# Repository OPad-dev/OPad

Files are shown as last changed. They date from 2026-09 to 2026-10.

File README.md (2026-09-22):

# OPad

**Low-Latency ESP32-S3 Rhythm Gaming Keypad & Telemetry Display**

A deterministic, ultra-low-latency mechanical keypad and live telemetry HUD designed for competitive osu!, osu!lazer, and rhythm games on **Linux and Windows 10/11**.

---

## ⚡ Core Principle: Latency Always Wins

> **"If a feature measurably worsens keyboard latency or latency jitter, the feature is reduced, deferred, frozen during gameplay, or removed."**

The keypad functions as a standalone 1000 Hz USB HID keyboard out of the box with zero host software running. Auxiliary features (LVGL telemetry, SQLite persistence, system tray, and tosu integration) are completely isolated from the keypress critical path.

---

## 🏗️ System Architecture

```text
                      +-------------------+
                      |    osu!lazer      |
                      +---------+---------+
                                | (observes)
                                v
                      +-------------------+
                      |       tosu        |
                      +---------+---------+
                                | (WebSocket v2)
                                v
+--------------------+   +-------------------------+
|      opad-gui      |   |       opad-daemon       |
|     (Rust/iced)    |<->|         (Rust)          |
|  - System Tray     |IPC|  - State Machine        |
|  - Layout Designer |   |  - SQLite Storage       |
|  - Configuration   |   |  - Headless Service     |
|  - Diagnostics     |   |  - tosu & Device Owner  |
+--------------------+   +------------+------------+
                                      |
                           USB CDC    |    USB HID (1000 Hz)
                                      |
                                      v
                         +-------------------------+
                         |  ESP32-S3 Touch LCD 2   |
                         |  - Eager Debounce ISR   |
                         |  - Core 0: Input & HID  |
                         |  - Core 1: LVGL & CDC   |
                         |  - ST7789 Telemetry HUD |
                         +-------------------------+
```

---

## 🔌 Hardware Target & Switch Wiring

### Supported Hardware
- **Board**: **Waveshare ESP32-S3-Touch-LCD-2** (ESP32-S3, 16MB Flash, 8MB PSRAM, 2.0" ST7789 LCD)
- **Switches**: Any two standard MX-compatible mechanical switches.

### Switch Pinout (Header P2)
Standard MX mechanical switches have no polarity. Connect each switch between its designated GPIO and ground:

| Input | Board Header & Pin | GPIO | Switch Connection |
|---|---|---|---|
| **Key 1** (Default `Z`) | **Header P2, Pin 11** | `GPIO 14` | Pin A -> Pin 11, Pin B -> GND (Pin 13) |
| **Key 2** (Default `X`) | **Header P2, Pin 12** | `GPIO 9` | Pin A -> Pin 12, Pin B -> GND (Pin 2) |
| **Ground** | **Header P2, Pin 13 / Pin 2** | `GND` | Ground Reference |

*Note: Pins 11, 12, and 13 are directly adjacent on Header P2 for simple breadboard/Dupont jumper wiring.*

These are the defaults. Each key's pin can be changed in the app under **Settings → Keys**. The list only offers header pins that work with a switch to GND:

| Header | Pins (GPIO) |
|---|---|
| **P1** | 1 (`GPIO 2`), 2 (`GPIO 4`), 3 (`GPIO 6`), 4 (`GPIO 16`), 6 (`GPIO 18`), 7 (`GPIO 21`), 8 (`GPIO 8`), 9 (`GPIO 7`), 10 (`GPIO 10`) |
| **P2** | 7 (`GPIO 15`), 8 (`GPIO 13`), 9 (`GPIO 11`), 10 (`GPIO 12`), 11 (`GPIO 14`), 12 (`GPIO 9`) |

Left out: `GPIO 19/20` (USB), `GPIO 43/44` (UART0 console), `GPIO 47/48` (touch and IMU I2C) and `GPIO 17` (pulled down on the board). Most listed pins are also wired to the camera connector, so don't use them with a camera fitted.

---

## 🛠️ Building From Source

### 1. Prerequisites (Ubuntu / Debian)
```bash
sudo apt update
sudo apt install -y build-essential pkg-config libasound2-dev libudev-dev \
    libx11-dev libxkbcommon-dev libwayland-dev libfontconfig1-dev libdbus-1-dev
```

### 2. Desktop Software Suite (Rust)
```bash
cd desktop
cargo build --release
```
The compiled binaries are produced in `desktop/target/release/`:
- `opad-daemon`: Background service.
- `opad-gui`: Graphical configuration, layout designer, and system tray.
- `opadctl`: Command-line management tool.

### 3. Firmware Build (ESP-IDF v5.5.2)
```bash
cd firmware
idf.py set-target esp32s3
idf.py build
```

---

## ⚡ Flashing the Firmware

### Option A: Via `opadctl` (Recommended)
`opadctl` drives `espflash` directly and needs no shell script and no ESP-IDF
toolchain. It asks the daemon to release the serial port first, reboots the pad
into the ROM download bootloader hands-free, writes the image and reboots back
into the app — on Linux and on Windows, with the app running:

```bash
# Update the app image only (ota_0 at 0x20000)
opadctl flash firmware/build/opad-firmware.bin

# Recovery flash: bootloader + partition table + OTA data + app
opadctl flash --full firmware/build
```

It also works with no daemon running at all, which is the state a recovery
flash usually happens in.

### Option B: Via ESP-IDF
```bash
cd firmware
idf.py -p /dev/ttyACM0 flash
```

If the pad will not enter download mode or has to be returned to stock, see
[Recovery, Reflashing & Unbinding](docs/recovery.md).

---

## 🪟 Windows Setup & Installation

**The pad needs none of this to work as a keyboard.** Plug it into any Windows
10 or 11 machine and it types immediately: HID binds to the inbox
`hidclass.sys` and the CDC port to the inbox `usbser.sys`. No `.inf`, no
WinUSB, no Zadig, no install. The software below is for configuring it, the
telemetry HUD and the lifetime counters.

1. Download `opad-setup-<version>.exe` from the GitHub Releases page and run it.
2. It installs the daemon, the GUI and `opadctl`, bundles tosu, and configures
   both to start at login. There is nothing else to do.

> **SmartScreen will warn you.** The installer is **not code-signed** yet:
> OPad is applying to SignPath Foundation for free OSS signing, which
> requires the repository to be public first. Until then, Windows shows
> "Windows protected your PC" — choose **More info → Run anyway**. Check the
> download against `SHA256SUMS` on the release page if you would rather verify
> it than trust the dialog.

Uninstall from Settings → Apps. It removes everything it installed, including
the two `Run` registry values, and asks before it touches your `opad.db` —
so a reinstall keeps your lifetime counters unless you say otherwise.

**To reset a pad completely, or hand it to someone else**, see
[Recovery, Reflashing & Unbinding](docs/recovery.md). There is no unpair button
in the app, deliberately: the only unbind is a documented reflash, and it erases
the pad's lifetime counters along with the owner record.

---

## 🚀 Linux Setup & Installation

### Option A: Pre-built Packages (Recommended)

Pre-built packages are on the GitHub Releases page. The `.deb` and `.rpm` set
up everything: the udev rule, the daemon's systemd user service, tray autostart,
the bundled `espflash`, and the ptrace capability tosu needs to read osu!'s
memory (see [docs/troubleshooting.md](docs/troubleshooting.md) §2).

Supported: every Ubuntu LTS and Debian release in support (Ubuntu 22.04, 24.04,
26.04; Debian 12, 13), RHEL / AlmaLinux / Rocky 9 and 10, current Fedora and
Arch. The release packages, bundled tosu included, need glibc 2.28 or newer.

#### Debian / Ubuntu / Pop!_OS (`.deb`):
```bash
sudo apt install ./opad_<version>_amd64.deb
# Or via dpkg:
sudo dpkg -i opad_<version>_amd64.deb
```

#### Fedora / RHEL / openSUSE (`.rpm`):
```bash
sudo dnf install ./opad-<version>.x86_64.rpm
```

#### Standalone AppImage:
```bash
chmod +x opad-x86_64.AppImage
./opad-x86_64.AppImage
```
The AppImage installs nothing system-wide. On first run it offers to install
the udev rule (it asks for your password), or run
`./opad-x86_64.AppImage install-udev` yourself. It cannot give tosu the ptrace
capability; `opadctl setup` and the Diagnostics page explain the alternative.

#### Arch Linux:
The repository's `PKGBUILD` builds from source (tosu runs on the system
`nodejs`, so see troubleshooting §2 about ptrace):
```bash
makepkg -si
```

---

### Option B: Installing From Source

#### 1. System-wide Install:
```bash
make
sudo make install
```

#### 2. User-local Install (`~/.local`):
```bash
make
make install-user
systemctl --user daemon-reload
systemctl --user enable --now opad-daemon.service
```

#### 3. Manual Udev Rules:
If not installing from package, allow non-root user access to USB CDC and ROM bootloader devices:
```bash
sudo cp packaging/linux/udev/70-opad.rules /etc/udev/rules.d/
sudo udevadm control --reload-rules && sudo udevadm trigger
```

---

## 💻 CLI Quick Reference (`opadctl`)

```bash
# Check device, daemon, and tosu state
opadctl status

# Trigger safe reconciliation
opadctl sync

# Export portable JSON backup
opadctl export backup.json

# Import validated backup
opadctl import backup.json

# Flash firmware image directly over USB
opadctl flash firmware/build/opad-firmware.bin

# Recovery flash (bootloader, partition table, OTA data and app)
opadctl flash --full firmware/build

# Reboot the pad into the ROM download bootloader and leave it there
opadctl bootloader

# Stream real-time diagnostic logs
opadctl monitor
```

---

## 📄 Documentation
- [Documentation Hub & Wiki](docs/README.md)
- [System Architecture](docs/architecture.md)
- [Project Roadmap & Hardware Variants](docs/roadmap.md)
- [OPad on Windows — as built](docs/windows-portability.md)
- [USB Framing & Protocol](docs/protocol.md)
- [Counter Reconciliation, Recovery & Unbinding](docs/recovery.md) — including the reflash / unbind path
- [Latency Testing Methodology](docs/latency-testing.md)
- [Testing & Hardware Checklist](docs/testing-checklist.md)
- [Technical Specification v1](docs/specs/technical-spec-v1.md)
- [Rapid Trigger v2 Specification](docs/specs/v2-rapid-trigger.md)

---

## 📦 Third-Party Software

OPad bundles or interacts with the following third-party software:

### tosu
- **Project**: [tosu](https://github.com/KotRikD/tosu)
- **Author**: Mikhail Babynichev and the tosu contributors
- **License**: [GNU Lesser General Public License v3.0 (LGPL-3.0)](licenses/tosu/LICENSE)
- **Redistribution Notice**: See [licenses/tosu/NOTICE](licenses/tosu/NOTICE)
- **User Replacement Rights**: Under the terms of LGPL-3.0, users are entitled to replace the bundled tosu binary with their own version. You can point the `OPAD_TOSU_PATH` (or legacy `OSUPAD_TOSU_PATH`) environment variable to a custom tosu executable, or configure an external path in the OPad desktop GUI (**Settings → tosu**).

---

## ⚖️ Trademark Disclaimer
OPad is an independent open-source hardware and software project. OPad is not affiliated with, endorsed by, or sponsored by ppy Pty Ltd or osu!. "osu!" is a registered trademark of ppy Pty Ltd.

---

## 📜 License
Everything original to OPad is licensed under the [MIT License](LICENSE): the firmware, the desktop app (daemon, GUI, CLI), the PCB designs and footprints, the enclosure CAD, and the documentation.

Third-party components keep their own open licenses and ship with their notices:
- [tosu](licenses/tosu/LICENSE) (LGPL-3.0), built from upstream source and bundled with the desktop packages, see the section above. Not stored in this repository.
- [Montserrat](desktop/gui/assets/fonts/Montserrat-OFL.txt) fonts embedded in the GUI (SIL Open Font License 1.1).
- [nanopb](firmware/main/protocol/nanopb/LICENSE.txt) protobuf runtime vendored in the firmware (zlib license).

Libraries pulled in at build time (Rust crates, ESP-IDF components such as LVGL and TinyUSB) are not stored here and are used under their own permissive licenses.

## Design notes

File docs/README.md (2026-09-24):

# OPad Documentation Hub & Wiki

Welcome to the official documentation and technical wiki for the **OPad** project.

This directory serves as the single source of truth for hardware specifications, firmware implementation, desktop daemon architecture, testing protocols, and future milestones.

---

## ⚠️ Planned: full documentation reorganization and wiki (noted 2026-09-24)

This folder has grown by accretion: design docs, four readiness/audit reviews,
an evening TODO, a code-review folder and a fix plan sit side by side, several
of them describing the code as it was before the 2026-09-24 review fixes
(commits `0e3286b`…`d56211d`, 93 findings closed). It will be rebuilt as a
coherent wiki. The plan:

1. **Wiki lives here, not in the GitHub Wiki tab.** `docs/` becomes an
   [MkDocs Material](https://squidfunk.github.io/mkdocs-material/) site
   published with GitHub Pages: same repo, same commits, reviewed in PRs, links
   to source files stay valid, `mkdocs serve` to preview.
2. **Structure first, then pages.** One session designs the navigation and
   writes the cross-cutting pages (Overview, System architecture, Serial
   protocol incl. framing negotiation, Counter sync & pad ownership, Update &
   release pipeline). It ends with a checklist of remaining pages, each naming
   the source files to read — same format as
   [claude-code-review/FIX-PLAN.md](claude-code-review/FIX-PLAN.md).
3. **Per-component pages** from that checklist: firmware modules (keypad &
   debounce, USB HID/CDC, UI & LVGL layouts, `ui_store`, diag & counters,
   touch as the third key), one page per desktop crate, the daemon state
   machine, GUI pages, `opadctl` reference (generated from `--help`), packaging
   per distro and Windows, hardware & wiring (Waveshare ESP32-S3 Touch LCD 2
   pinout), troubleshooting, FAQ.
4. **Rules for whoever writes it:** every factual claim comes from a source
   file read in that session and cites its path; when code and an existing doc
   disagree, the code wins and the doc is fixed or deleted; no placeholder
   pages.
5. **Historical material** is kept but moved under `docs/history/` and marked
   as such: the readiness/audit reviews of 2026-09-22, `todo-2026-09-21-evening.md`,
   and the `claude-code-review/` findings (a record of what was found and fixed,
   not current guidance). `specs/remaining-work-v1.md` is folded into a changelog.

Until that lands, treat the documents below as **possibly stale**; the code and
`git log` are authoritative.

---

## 📚 Documentation Index

### 🏗️ Architecture & Core System
* **[System Architecture](architecture.md)** — Hardware layout, ESP32-S3 dual-core isolation, IPC design, desktop daemon, and state machine.
* **[USB Framing & Serial Protocol](protocol.md)** — Binary CDC packet framing, command opcodes, sequence numbers, and telemetry streams.
* **[OPad on Windows](windows-portability.md)** — Windows-specific design: Named Pipes IPC, Windows Service daemon, auto-start, and driverless HID operation.
* **[Recovery, Reconciliation & Unbinding](recovery.md)** — Safe counter synchronization, flashing procedures, bootloader entry, and pairing models.

* **[Troubleshooting](troubleshooting.md)** — Common failures (no live data, port busy, tosu memory access) and their fixes.

### ⏱️ Latency & Hardware Testing
* **[Latency Testing Methodology](latency-testing.md)** — Hardware test methodology, Stages A–D, electronic key-to-HID gate requirements, and latency benchmarks.
* **[Testing & Verification Checklist](testing-checklist.md)** — Comprehensive quality assurance checklist covering firmware, daemon, GUI, and hardware reliability.

### 🔍 Code review record (2026-09-23/24)
* **[Code review findings & fix plan](claude-code-review/README.md)** — 93 findings across firmware, desktop and packaging, all closed (92 fixed, 1 invalid); [FIX-PLAN.md](claude-code-review/FIX-PLAN.md) holds the per-cluster progress log and the hardware validation record.

### 🗂️ Historical readiness reviews (pre-fix snapshots, to move under `history/`)
* [Software readiness review (2026-09-22)](software-readiness-review-2026-09-22.md), [Software audit & readiness review](software-audit-and-readiness-review.md), [Release readiness guide (2026-09-22)](release-readiness-guide-2026-09-22.md), [Full-repo architecture & readiness guide](full-repo-architecture-and-readiness-guide.md), [TODO 2026-09-21 evening](todo-2026-09-21-evening.md) — written before the review fixes; many items they list are now done.

### 🚀 Future Milestones & Catalog Roadmap
* **[Future Roadmap & Hardware Variants](roadmap.md)**:
  * **ESP-NOW Ultra-Low-Latency Wireless Dongle** (Dual-mode 1.0 ms wireless).
  * **Heavy Ballast & Anti-Slip Deskmat Enclosure** (High-BPM anti-slip case V2).
  * **Multi-Key Catalog Expansion** (3-Key Standard with Quick Retry, 4k/5k/6k/7k/10k Mania).
  * **Modular Swappable Switch PCBs** (On-board ADC chip architecture, universal 8-wire SPI bus).
  * **Hardware Auto-Detection** (Analog ID voltage net & digital SPI handshake).
  * **Adaptive Debounce & Rapid Trigger Velocity Hysteresis**.

### 📋 Specifications & Development Plans
* **[Technical Specification v1](specs/technical-spec-v1.md)** — Complete normative specification for OPad V1 hardware, firmware, and desktop integration.
* **[Remaining Work & Gap Analysis](specs/remaining-work-v1.md)** — As-built gap analysis and audit tracking for V1 release.
* **[Packaging & Distribution Plan](specs/packaging-distribution.md)** — Build system, CI/CD, Windows/Linux packaging, and release delivery.
* **[Rapid Trigger (Hall-Effect Keys) v2 Plan](specs/v2-rapid-trigger.md)** — Implementation blueprint for Hall-effect magnetic switches, ADC sampling pipeline, and continuous Rapid Trigger engine.

---

## 🌐 Community & Repository

* **Primary Repository**: [https://github.com/OPad-dev/OPad](https://github.com/OPad-dev/OPad)
* **Organization**: [OPad-dev](https://github.com/OPad-dev)

---

## ⚖️ Trademark Disclaimer
OPad is an independent open-source hardware and software project. OPad is not affiliated with, endorsed by, or sponsored by ppy Pty Ltd or osu!. "osu!" is a registered trademark of ppy Pty Ltd.

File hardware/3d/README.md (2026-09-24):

# OPad ESP32-S3 — 3D Models & Enclosure CAD Reference

This directory contains the ready-to-print/modify OPad enclosure for the **Waveshare ESP32-S3-Touch-LCD-2** and standard **MX mechanical switches**. Everything here is original OPad work under the repository's [MIT License](../../LICENSE).

---

## 1. Directory Structure

```
hardware/3d/
└── custom_case/
    ├── V1.1/                               # Current: fits the V1 PCBs (carrier on sockets + MX/HE module)
    │   ├── osupad_params.scad              # every dimension
    │   ├── osupad_enclosure.scad           # top case and bottom plate (screwless)
    │   ├── osupad_case_top.stl
    │   ├── osupad_case_bottom.stl
    │   ├── osupad_preview.png
    │   ├── README.md                       # changes from V1, parts, assembly, printing
    │   └── tools/check_fit.py              # interference check against the PCBs and the Waveshare
    └── V1/                                 # Original (20.3° screen deck, hand-wired switches); does not fit the V1 PCBs
        ├── osupad_enclosure.scad
        ├── osupad_case_top.stl
        ├── osupad_case_bottom.stl
        └── osupad_preview.png
```

Use **V1.1** with the V1 PCBs; see [`custom_case/V1.1/README.md`](custom_case/V1.1/README.md).

Third-party models (the Waveshare board model and other keypads) are not stored in this repository, since they are not MIT licensed. Download them from their authors if you want them as a modelling reference; see section 4.

---

## 2. Hardware Dimensions Reference

### Waveshare ESP32-S3-Touch-LCD-2
* **Outer Glass Lens**: `37.10 mm (W) × 58.80 mm (L) × 1.10 mm (H)` with `4× R2.60 mm` corner fillet (drawing). The STEP model's glass edge measures `37.52 × 59.22 mm`, so a pocket needs more clearance than the drawing suggests.
* **Under the glass**: touch layer, LCD and PCB all fit inside `35.02 × 48.22 mm`; the USB-C receptacle sticks out `1.18 mm` past the PCB edge
* **Active Display Viewport**: `30.99 mm (W) × 41.20 mm (L)`
* **PCB Substrate**: `35.00 mm (W) × 48.20 mm (L)`
* **Mounting Holes**: `4× M2.0` screw holes (pitch: `29.00 mm (X) × 42.20 mm (Y)`)
* **Total Module Depth**: `9.70 mm` (from glass front to back of PCB connectors)
* **USB-C Port**: Centered on bottom edge (`18.9 mm` cutout width)

### Mechanical MX Key Switches (Cherry, Gateron, Kailh)
* **Plate Cutout**: `14.0 mm × 14.0 mm`
* **Plate Thickness**: `1.5 mm` (critical for clip retention)
* **Standard Key Pitch**: `19.05 mm` center-to-center

---

## 3. How to Use & Modify These Models

### Option A: Use the OpenSCAD Parametric Generator (Recommended)
1. Open [`hardware/3d/custom_case/V1.1/osupad_enclosure.scad`](custom_case/V1.1/osupad_enclosure.scad) in [OpenSCAD](https://openscad.org/) (dimensions are in `osupad_params.scad`).
2. Change `PART` to `"top_case"` or `"bottom_plate"`.
3. Press `F6` to render, then `F7` to export directly to `.stl`.
4. All dimensions, wall thicknesses, and tolerances are fully configurable as variables at the top of the file.

### Option B: Model Around the Board in FreeCAD, Fusion 360 or Onshape
1. Download the official board STEP model from the [Waveshare Wiki](https://www.waveshare.com/wiki/ESP32-S3-Touch-LCD-2) (not redistributed here).
2. Import it next to an export of the OPad case, or model around the dimensions in section 2.
3. Export as `.stl` or `.step` for slicing.

---

## 4. External References (not included, not MIT)
- **Waveshare ESP32-S3-Touch-LCD-2**: official 3D CAD model and 2D drawings on the [Waveshare Wiki](https://www.waveshare.com/wiki/ESP32-S3-Touch-LCD-2). No redistribution license is stated, so the files are not included here.
- **`milk-crate`**: 2-key macropad by *somepin* ([GitHub](https://github.com/somepin/milk-crate), MIT License).
- **`osu-keypad`**: 2-key keypad by *clay53* ([GitHub](https://github.com/clay53/Osu-Keypad), MIT License).
- **`osu-clicker`**: 2-key hotswap keypad by *kameHame HA* ([Printables #943460](https://www.printables.com/model/943460-osu-keypad), CC BY-NC 4.0, non-commercial only).

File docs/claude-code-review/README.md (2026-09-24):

# Claude Code review findings

Findings from `/code-review` runs, saved so they survive the session. Each file
covers one run; findings are ranked most severe first and carry a status
(`open` / `fixed` / `wontfix` / `invalid`) that should be updated as they are
worked through. Unless a finding is marked *(confirmed)* or *(verified)*, the
reviewer did not re-verify it, so check each against the code before acting on it.

All runs on 2026-09-23 were against `main` @ `b0e0a37` with a clean working tree,
so each covers the current code of its path rather than a diff.

| Scope | File | Findings |
| --- | --- | --- |
| `firmware/main/protocol` | [2026-09-23-firmware-protocol.md](2026-09-23-firmware-protocol.md) | 8 |
| `firmware/main` usb / input / config / counters / runtime / diag / app_main | [2026-09-23-firmware-usb-input-config.md](2026-09-23-firmware-usb-input-config.md) | 10 |
| `firmware/main/ui` | [2026-09-23-firmware-ui.md](2026-09-23-firmware-ui.md) | 10 |
| `firmware/test`, `firmware/boards` (medium) | [2026-09-23-firmware-test-boards.md](2026-09-23-firmware-test-boards.md) | 2 |
| `desktop/crates/opad-protocol`, `opad-device`, `opad-ipc` | [2026-09-23-desktop-opad-protocol-device-ipc.md](2026-09-23-desktop-opad-protocol-device-ipc.md) | 10 |
| `desktop/crates/opad-update` | [2026-09-23-desktop-opad-update.md](2026-09-23-desktop-opad-update.md) | 8 |
| `desktop/crates/opad-model`, `opad-layout`, `opad-storage`, `opad-tosu`, `opad-ui-preview` | [2026-09-23-desktop-model-layout-storage-tosu-preview.md](2026-09-23-desktop-model-layout-storage-tosu-preview.md) | 10 |
| `desktop/daemon` | [2026-09-23-desktop-daemon.md](2026-09-23-desktop-daemon.md) | 10 |
| `desktop/gui` | [2026-09-23-desktop-gui.md](2026-09-23-desktop-gui.md) | 10 |
| `desktop/cli` | [2026-09-23-desktop-cli.md](2026-09-23-desktop-cli.md) | 10 |
| `packaging`, `scripts`, `.github`, `protocol` (medium) | [2026-09-23-packaging-scripts-ci-protocol.md](2026-09-23-packaging-scripts-ci-protocol.md) | 5 |

93 findings total. `opad-layout`, `opad-storage` and `protocol/` came out clean.

**Hardware (2026-09-24, `main` @ `f78bfbd`):** PCBs and case, checked with KiCad 10.0.6 and OpenSCAD against Waveshare's schematic and drawing: [2026-09-24-hardware.md](2026-09-24-hardware.md), 9 findings: 3 fixed by case V1.1 (#1, #6, #7), 6 open (the PCB and tooling ones).

**Fixing them:** see [FIX-PLAN.md](FIX-PLAN.md) — every finding assigned to one
executor (Opus / Sonnet / Haiku / Antigravity), clustered by file, with run order,
session rules and paste-able kickoff prompts.

## Status: closed (2026-09-24)

All 93 findings are closed: **92 fixed, 1 invalid** (DC#10). Every cluster in
FIX-PLAN.md is ticked. Every commit passed `make firmware`, the firmware host
tests and `make check` (fmt, clippy `-D warnings`, 328 tests).

### Hardware validation record

Run by the owner on the real pad (Waveshare ESP32-S3 Touch LCD 2, new firmware
flashed via `opadctl flash`) on 2026-09-24:

| Step | Covers | Result |
| --- | --- | --- |
| Flash + reconnect | S12 (daemon pause/resume path) | ✅ released port, 12 s flash, reconnected 3 s later, no 15 s wait |
| Boot | O6, S1, A2 | ✅ no I2C scan, quiet idle log |
| Touch as third key (tap / hold / lift / double tap / 30 s idle) | FU#10 | ✅ |
| Keys, remap while held, detect-pin, protocol responsive during detect | O2, O3, O4, S1 | ✅ |
| Full map with live tosu data, unplug/replug mid-map | O1, S2 (pad side) | ✅ |
| Sleep, set brightness asleep, wake | S3, FB#1 | ✅ |
| Layout pushed during gameplay, reboot | O5 | ✅ |

**Signed off by the owner without a hardware run** (unit/integration tests and
code review only): foreign-pad guards and incompatible-pad handling (O7, O8),
headless mode (O6 — the LCD is always fitted), desktop reconnect logic (O9, tested
on the pad only against the pre-fix daemon), Windows pipe/bootloader-port picks
(O10, `cargo check` for the Windows target), tosu supervisor pause (O11), the
updater fixes (S6, S7), the GUI fixes (S9, S10, DG#10), the CLI fixes (S11,
DC#8), release signing (S13), and the Windows cold-plug with a legacy-firmware
pad (DD#9). If any of these misbehaves, the FIX-PLAN progress log names the
commit to look at.

## Top items across runs (2026-09-23)

### Firmware
1. Framing lock: legacy headers accepted after marked lock, and `s_host_framing` re-latched per frame (protocol #1, #2).
2. `detect_pin` `timeout_ms` unbounded, blocks the CDC task (protocol #3).
3. GPIO8 (module-ID divider) in the key-pin lists → pin detect returns it instantly (usb/input #1, #8).
4. HID `s_report_pending` race between touch-retry (core 1) and keypad (core 0) (usb/input #2).
5. HE module reported as a held key; keycode changes bypass the staged apply (usb/input #3, #4, #5).
6. Headless mode: `data_update` source 67 runs LVGL without `lv_init` → panic loop; `ui_init` derefs a NULL screen (ui #1, #6).
7. `ui_store` pending layouts / dirty masks shared across cores without a lock; dirty bit cleared before the NVS write (ui #4, #5).
8. Brightness set while asleep is lost on wake (ui #2, boards #1).

### Desktop
1. Foreign-pad guards bypassed: cooldown→sync trigger, every IPC handler, and the firmware installer (daemon #1, #2, #4).
2. `opad-device` serial worker: Windows `Instant` subtraction panic kills the worker silently; frames dropped and no reopen after a re-Hello (device #1, #2, #3).
3. Updater: persisted ETag with no cached manifest disables all updates after a restart; AppImage never classified in the manifest; tosu VERSION written before the binary; `pause()` doesn't wait for tosu to exit (update #1, #2, #3; tosu #1).
4. Incompatible-protocol pad adopted as connected, counters saved under the previous pad's id (daemon #3).
5. Version compare: `rc10 < rc9`, and tosu plan ignores `is_newer` (update #5, #6).
6. Flash flow: CLI death between `PrepareFlash`/`FinishFlash` leaves the daemon paused forever; `bootloader` waits 15 s for an impossible reconnect (cli #2, #3).
7. GUI log cursor skips a daemon entry per local log line; single-instance races on both platforms; tray probed once (gui #2, #3, #6, #8).

### Release / packaging
1. `build_release.sh` signs a manifest over locally rebuilt artifacts, not the ones `release.yml` publishes (packaging #1).
2. `AppRun` `LD_LIBRARY_PATH` trailing-colon lets a planted `.so` in the CWD load (packaging #2).
3. Arch package ships no espflash; glibc gate skips the tosu binary (packaging #4, #5).

## Cross-cutting themes

- **Framing negotiation lives in three places** (firmware parser, `opad-device` worker, `opad-device::probe_port`) with different rules; the firmware side re-latches per frame while the host locks once. See firmware protocol #1/#2 and device #9.
- **Log sequence cursors** are mishandled the same way in the GUI (`latest_log_seq` doubles as local counter) and the CLI (`since_seq` advanced to `latest_seq`, `> 0` guard). A shared "advance from last received entry" helper in `opad-model` would fix both.
- **Cross-core shared state without a lock** in firmware: `ui_store` masks/pending layouts, `s_report_pending` / `s_pending_edge_us` in `usb_hid`, `s_asleep` read from the protocol task.
- **Duplicated tables/logic that have already drifted:** key-pin allow-list and debounce bounds (firmware), `ConfigPayload → DeviceConfig` (device), atomic-write sequence (update/backup), tosu log classifier (daemon), confirm prompt (cli), stdout/stderr pump (tosu), `install_prefix` (model), wire constants (ui-preview).
- **Brightness / sleep ownership** is split between `board_display.c`, `ui_port.c` and `device_config.c`, each with its own copy of the current brightness.

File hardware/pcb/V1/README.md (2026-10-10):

# OPad V1 PCBs

Modular hardware ecosystem joined by one 8-wire JST-SH cable:

| Board | Folder | Size | Status | What it does |
|---|---|---|---|---|
| **Controller carrier** | `Carrier/` | 35.0 × 48.2 mm, C-shaped | Production | Plugs onto the Waveshare ESP32-S3-Touch-LCD-2 headers and brings the module signals to a connector |
| **MX input module** | `MX/` | 52.0 × 24.0 mm | Production | Two Kailh MX mechanical hot-swap sockets under the key plate |
| **Hall Effect input module** | `HE/` | 52.0 × 24.0 mm | **v2 Experimental** | Two magnetic Rapid Trigger Hall sensors (TI DRV5055) under the key plate |

> [!IMPORTANT]
> The **Hall Effect module** requires firmware v2 (Rapid Trigger support), which is not yet available. The PCB design is complete but has not been built and tested; the firmware's ADC sampling pipeline and Rapid Trigger engine are specified in [`docs/specs/v2-rapid-trigger.md`](../../docs/specs/v2-rapid-trigger.md). v1 firmware recognises an HE module by its ID voltage, shows a warning on the LCD and ignores key input rather than reading the analog sensor outputs as presses.

The input module is **swappable**: both the MX mechanical module and the Hall-effect (rapid trigger) module use the same outline, mounting holes, connector position and pinout, and plug into the same carrier and cable. The module reports which kind it is through an ID voltage on the connector (0.30 V for MX, 1.06 V for Hall Effect).

Production files live in each board's `production/` folder, one subfolder per fab: `jlcpcb/` (Gerbers, BOM, CPL), `pcbway/` (Gerbers with their order marker, BOM, centroid) and `aisler/` (native KiCad board and ODB++ with the parts in them). Renders, PDFs, STEP and the ERC/DRC reports sit next to them.

Status: the MX module and the carrier pass ERC, DRC and schematic parity in KiCad 10.0.6 with zero errors; the carrier has zero warnings, the MX module only "does not match copy in library" warnings, because its footprint and symbol copies were placed before `lib/` was rewritten by `gen_library.py` (same pads and pins; that board is built and working, so `export_production.py` accepts them). The Hall Effect module is generated and checked by its own toolchain (`scripts/he_board.py`, see below), which needs no KiCad install; it reports zero rule violations, its Gerbers verify clean against the netlist, and the generated KiCad files pass ERC and DRC with schematic parity in KiCad 10.0.6 (`scripts/check_he_kicad.py`; only "footprint does not match library" warnings remain, see Toolchain).

---

## Module connector (JST SH 8-pin, same on every input module)

| Pin | Net | Waveshare pin | GPIO | MX V1 use | Hall module use |
|---|---|---|---|---|---|
| 1 | 3V3 | P2-1 | – | pull-ups, ID divider | sensor supply |
| 2 | GND | P2-2 | – | switch common | ground |
| 3 | IN1 | P1-10 | **GPIO10** (ADC1_CH9) | KEY1 (left key) | analog 1 / SPI CS1 |
| 4 | IN2 | P1-9 | **GPIO7** (ADC1_CH6) | KEY2 (right key) | analog 2 / SPI CS2 |
| 5 | ID | P1-8 | GPIO8 (ADC1_CH7) | ID divider = 0.30 V | own ID voltage |
| 6 | IO6 | P1-3 | GPIO6 (ADC1_CH5) | not used | e.g. SPI MISO |
| 7 | IO4 | P1-2 | GPIO4 (ADC1_CH3) | not used | e.g. SPI MOSI |
| 8 | IO2 | P1-1 | GPIO2 (ADC1_CH1) | not used | e.g. SPI SCK |

- All six signals are ADC1 pins. On the ESP32-S3, ADC continuous (DMA) mode only supports ADC1 (see `docs/specs/v2-rapid-trigger.md` §2.2).
- SPI3 can be routed to any of these pins through the GPIO matrix. None of them are strapping pins, USB, UART0, or the touch/IMU I2C.
- The pin order is chosen so both boards route on two layers with no crossings.
- **Firmware:** in the app, set Key 1 = GPIO10 and Key 2 = GPIO7 (both are already in the allowed pin list). The hand-wired defaults (GPIO14 / GPIO9) don't apply to this board.

### Module ID

Each module has its own divider from 3V3 to GND on ID. The carrier has no parts on this line.

| Module | Top resistor | Bottom resistor | ID voltage |
|---|---|---|---|
| MX V1 | 100 kΩ (R3) | 10 kΩ (R4) | 0.30 V |
| **Hall Effect V1** | **100 kΩ (R1)** | **47 kΩ (R2)** | **1.06 V** |
| reserved: Hall SPI | 100 kΩ | 100 kΩ | 1.65 V |

The divider's source impedance is 100k ∥ 47k ≈ 32 kΩ, above the ~10 kΩ the ESP32-S3 ADC likes. ID is read once at start-up, so average a handful of samples instead of trusting a single conversion.

With no module plugged in, GPIO8 floats. The firmware can enable the internal pull-down to read about 0 V in that case.

---

## MX input module (`MX/`)

- **Case coordinates** below are those of `hardware/3d/custom_case/V1/osupad_enclosure.scad`: origin at the front-left outer corner, X to the right, Y toward the screen. KiCad uses X = 100 + case X and Y = 100 − case Y, so the top of the KiCad editor is the rear of the case and the layout is not mirrored.
- **Key centres:** case (28.475, 16.5) and (47.525, 16.5), 19.05 mm pitch, the same as the plate cutouts.
- **Outline:** case X 12…64, Y 7…31, 1.5 mm corner radius.
- **Mounting holes:** 2× M2 (2.2 mm NPTH) at case (15.5, 16.5) and (60.5, 16.5), on the key axis and clear of the switch footprints. The PCB must be held there, or it moves when a switch is pulled. Case V1.1 does this without screws: pins in the key deck go through the holes and posts on the bottom plate clamp the PCB against the deck.
- **Height:** the PCB top is **5.0 mm below the top of the plate** (plate 1.5 mm, case z = 10.0). About 3.5 mm of free space is needed under the PCB bottom for the sockets (1.85 mm) and J1 (2.9 mm).
- **Everything is on the bottom side** (sockets, J1, R1–R4, C1), so JLCPCB assembles one side only. The switches go in from the top through the plate.
- **J1** sits at the rear edge, centred on the keys, with the opening facing the screen. The cable leaves toward the controller.
- **Footprint:** `lib/osupad.pretty/Kailh_CPG151101S11_MX_Hotswap_Bottom` is the Kailh land pattern (3.05 mm pin holes, 4.0 mm centre, 1.75 mm pegs, 2.55 × 2.5 mm pads), drawn from the socket side and placed flipped. The switch pins point to the rear (standard orientation).

## Hall Effect input module (`HE/`)

Same outline, mounting holes, connector position and pinout as the MX module, so the two are interchangeable on one cable. Instead of switching a pin to ground, each key has a **TI DRV5055A3 ratiometric linear Hall sensor** whose analog output tracks the magnet in the switch stem, which is what rapid trigger needs.

> **V1.0 erratum (fixed in V1.1):** the V1.0 SOT-23 footprint was mirrored, so every assembled sensor sits with **VCC on its IN line and OUT on 3V3**. It powers itself backwards through its protection diode, reads a fixed ~2.9 V and barely reacts to a magnet. The connectivity was right, so neither DRC nor the assembler could catch it. V1.1 swaps pads 1 and 2 (`scripts/gen_library.py`, `scripts/he_board.py`), moves C2/C3 to the pin-1 side so the 3V3 stub and the IN line do not cross, and `he_board.py`'s self-test now checks every SOT-23's pin order against the real package. A V1.0 board works only with each sensor re-soldered upside down (marking towards the board), which mirrors its pin order back.
>
> **V1.1 review (2026-10-10), before ordering:** TI's DBZ pinout (datasheet SBAS640C Figure 4-1 and Table 4-1: 1 = VCC, 2 = OUT, 3 = GND, pin 1 top-left in the top view) was checked against the footprint by hand, against KiCad's flip convention and against the V1.0 measurements; the three agree with the V1.1 pads. Found and fixed in the same pass: the vias grow from 0.6 to **0.7 mm** (0.2 mm annular ring, which Aisler's HASL rules and Eurocircuits' class 6 need; JLCPCB accepted 0.6); the silkscreen square round each sensor was 3.0 mm and crossed the pad tips, it is now 3.6 mm with a pin-1 dot, and `C2`/`C3` moved 0.2 mm away from the sensors to make room; the pour gap went from 0.3 to 0.45 mm and a ground via fills the pocket next to U2, so the Gerbers hold no floating copper slivers (`verify_he_gerbers.py` now checks for islands); the generated schematic had an unescaped quote and did not load in KiCad, so ERC had never actually run on it (it now passes, with PWR_FLAGs and a connector symbol that carries the MP pads). None of these change the netlist.

### Sensor architecture (the part that matters)

This is **Architecture A: bottom-side SMT on solid FR-4.**

- There is **no 4.0 mm stem hole** at the key centres. `SW_MX_Hall_PlateMount` (used for a through-hole stem) is *not* the footprint here; `SW_MX_Hall_PlateMount_SolidCentre` is, and it contributes only the two alignment peg holes.
- U1 and U2 are centred **exactly** on the key centres (16.475, 9.5) and (35.525, 9.5), on the bottom copper, directly under the magnet.
- A **3.0 × 3.0 mm copper keepout on both layers** around each sensor keeps the ground pour out of the magnetic path, so the stem magnet's flux is not damped by eddy currents in the plane. In KiCad these are rule areas with `copperpour not_allowed`; in the Gerbers the pour is genuinely absent there.
### Why there is no centre hole, and what the board is actually compatible with

In a Lekker / Gateron KS-20 class magnetic switch (Gateron's KS-20T drawing DS-02-001-A0, in the [Magnetic Orange datasheet](https://gateron.com/u_file/2312/26/file/GATERONMagneticOrangeSwitch-KS-20TO10B050NW-Y64.pdf), sheet 1):

- **the magnet sits in the stem at the switch centre, N pole towards the PCB.** There is no MX-style centre pole and no 4 mm centre hole;
- **two Ø 1.70 ± 0.05 mm plastic pins, 10.16 mm apart (±5.08 mm), stick out of the bottom and pass straight through the PCB**, protruding about 1 mm out the back. That is why the 1.75 mm peg holes are needed;
- the bottom housing has a pocket ("the hole for setting hall sensor") so Gateron's own reference layout puts a SOT-23 sensor on the **top** of the PCB, between the two pins, with three 0.8 × 0.8 mm pads.

So a top-side sensor is possible with these switches; this board puts it on the bottom instead, like Wooting ([Lekker update #5, part 2](https://wooting.io/post/we-overcame-the-challenges-lekker-update-5-part-22)), because single-side assembly is cheaper and the top of the PCB stays flat against the plate. The price is distance: the magnet reads through the full 1.6 mm of FR-4 plus the package, so the field at the die is a fraction of what Gateron's pocket position sees (numbers under Sensor sensitivity). Peg holes **and** a solid centre **and** a bottom-side sensor is a consistent set; a board that had the peg holes *and* a 4 mm centre hole would be an MX PCB-mount pattern, which is a different switch.

| Switch | Works on this board? |
|---|---|
| Gateron KS-20 / Wooting Lekker, KS-37 / Magnetic Jade, Geon Raw HE and other Lekker-standard magnetic switches | Yes — flush magnet centre, two ±5.08 mm plastic pins |
| Switches sold as "**TMR switches**" | Yes — see below |
| MX mechanical (Cherry, Gateron, Kailh…) | **No.** A real MX switch has a centre pole and metal pins. That is what the `MX/` module is for — same outline, same connector, swap the module |

**On "TMR switches":** TMR (tunnel magnetoresistance) is a *sensor* technology that lives on the keyboard's PCB, not a different kind of switch. A switch marketed as a "TMR switch" is the same magnetic switch — a magnet in an MX-form stem with a flush bottom and two pins — and the industry uses them interchangeably: Gateron Jade, Jade Pro and Lekker V2 all go into Hall boards like the Wooting 60HE and TMR boards like the Womier SK75 alike. This module reads the magnet with a Hall sensor, and the magnet does not know or care what sensor is underneath it, so TMR-branded switches drop straight in.

Two caveats, neither of which is a fit problem:

- **Magnet strength varies by switch model.** TMR sensors are far more sensitive than Hall, so a vendor *can* pair a TMR-targeted switch line with a weaker magnet. If you use such a switch here, A3 is the wrong variant and you want A1 or A2. As Wooting put it, what matters is matching the sensitivity range to the magnet, not chasing sensitivity for its own sake.
- **This board cannot be rebuilt with a TMR sensor as a drop-in.** The common analog TMR parts (MultiDimension TMR2001, TMR2083) are SOT-23-**5**, not the 3-pin SOT-23 used here, so they would need a new footprint and a re-route. Most TMR designs also mount the sensor *off-axis*; U1/U2 here are deliberately on-axis at the key centre, which is the right placement for the DRV5055.

These magnetic switches are deliberately not MX-compatible; vendors say so themselves. The claim this board makes is "every switch in the Lekker standard", not "every keyboard switch ever made". If a magnetic switch turns up with a protruding MX-style centre pole, it will foul the sensor and is out of scope for V1 — I found no current HE switch that does this, since the whole class puts the magnet where that pole would be.

### Sensor sensitivity

The magnet reads through 1.6 mm of FR-4, so the field at the die is weaker than a top-side design's. Wooting hit the same geometry and compensated with a stronger magnet *and* a more sensitive sensor. All three variants share the SOT-23 pinout and this footprint, so **the board never changes** — only which reel JLCPCB loads. Set `SENSOR_VARIANT` in `scripts/he_board.py` and regenerate.

Datasheet values (TI SBAS640C §5.6, VCC = 3.3 V, 25 °C): quiescent output 1.59–1.71 V (typ. 1.65 V), linear output range 0.2 V to VCC − 0.2 V, input-referred noise 0.2 mT peak-to-peak for every variant (so a more sensitive part gives more volts per millimetre but the same magnetic noise):

| Variant | LCSC | Sensitivity @3.3 V | Linear range @3.3 V | Notes |
|---|---|---|---|---|
| A1 | `C962987` | 60 mV/mT (57–63) | ±22 mT | clips before mid-travel with a Jade |
| A2 | `C266131` | 30 mV/mT (28.5–31.5) | ±44 mT | about 2× A3's resolution, may clip in the last few tenths of a millimetre |
| A3 | `C266128` | 15 mV/mT (14.3–15.8) | ±88 mT | current default; cannot clip |

What the magnet delivers: Gateron quotes the Magnetic Jade at 120 Gs (12 mT) initial and 700–800 Gs (70–80 mT) at bottom-out "with a 1.2 mm PCB", N pole towards the PCB; the KS-20T, read in its pocket, at 102 / 905 Gs. Through 1.6 mm the bottom-out figure drops to very roughly 50–60 mT. With the N pole facing the sensor's back the output **rises** when the key is pressed: A3 goes from about 1.8 V at rest to about 2.4–2.6 V at bottom-out, inside the ESP32-S3 ADC's accurate range at 12 dB (0–2.9 V, ±50 mV); A2 would reach 3.1 V (its limit) at 48 mT, so it saturates near the end of travel but doubles the resolution over the rest. A3 is shipped as the default because it cannot saturate, which makes first bring-up unambiguous; measure the actual swing on the first V1.1 build before choosing between A3 and A2. The Jade Silent (3.2 ± 0.2 mm travel) has no published flux figures.

### Layout

- **Everything is on the bottom side**, so JLCPCB assembles one side.
- `U1`/`U2` are at 180°, so both analog outputs face the connector and both ground pads face the board's front edge, where a short stub and a via drop them into the pour outside the keepout.
- `C2`/`C3` sit just outside each keepout on the pin-1 side (centre 2.7 mm from the sensor, 100 nF; TI asks for at least 10 nF close to VCC, §7.4), feeding VCC from the side; `C1` is the bulk decoupler next to J1 pin 1.
- **3V3 is distributed on F.Cu**, the otherwise empty top layer, so every analog trace stays on B.Cu with no crossings. Four vias tie it to the bottom-side stubs.
- `R1`/`R2` are the 100 k / 47 k ID divider.
- J1-6/7/8 (GPIO6/4/2) are reserved for an SPI variant, so instead of being left floating they run to probe pads **TP1/TP2/TP3** below the connector — the three bare pads visible under J1 in the render. They are board features, not parts: nothing is assembled on them, they take no solder paste, and they appear in neither the BOM nor the centroid file. Delete `_probe_pad(...)` from `PARTS` in `he_board.py` and regenerate if you would rather leave those pins unconnected.
- Ground: pours on both layers with a 0.45 mm gap to foreign copper (wide enough that no sliver is left between 1.0 mm pitch traces), thermal relief on every ground pad, and 22 plated vias stitching the two planes.
- Vias are 0.7 mm with a 0.3 mm hole (0.2 mm annular ring), tented on both sides.

### Pinout

| Pin | Net | Goes to |
|---|---|---|
| 1 | 3V3 | U1-1, U2-1 (VCC), C1/C2/C3, R1 |
| 2 | GND | ground pours, U1-3, U2-3, C1/C2/C3, R2 |
| 3 | IN1 | U1-2 (OUT), key 1 analog → GPIO10 (ADC1_CH9) |
| 4 | IN2 | U2-2 (OUT), key 2 analog → GPIO7 (ADC1_CH6) |
| 5 | ID | R1/R2 divider, 1.06 V → GPIO8 (ADC1_CH7) |
| 6, 7, 8 | IO6 / IO4 / IO2 | TP1 / TP2 / TP3 probe pads, reserved for SPI |

**DRV5055 SOT-23 pinout: 1 = VCC, 2 = OUT, 3 = GND** (TI DBZ package, datasheet Figure 4-1 and Table 4-1). Worth repeating because swapping 2 and 3 would put the output straight on ground. Turned so pins 1–2 face up, pin 1 is on the **right** in the top view of the chip; a chip on the bottom side is seen mirrored from above, so in the board's top view (and in the KiCad editor) pad 1 is the **left** one of the pair, the one next to the silkscreen dot. `he_board.py`'s self-test enforces this and also compares J1's pinout with the built MX board and the sensor symbol's pin names with the nets.

### Toolchain

The HE board does not depend on a KiCad install. `scripts/he_board.py` holds the geometry, netlist and placement, and checks its own design rules; everything else is derived from it:

```
python3 scripts/he_board.py            # placement self-test + DRC, exit 1 on any violation
python3 scripts/generate_he_gerbers.py # Gerbers, drills, job file, BOM, CPL (JLCPCB + PCBWay)
python3 scripts/generate_he_kicad.py   # .kicad_sch, .kicad_pcb, .kicad_pro, lib tables
python3 scripts/verify_he_gerbers.py   # rasterise the Gerbers, check nets for opens/shorts/islands
python3 scripts/render_he_preview.py   # production/*-top.png and *-bottom.png
python3 scripts/check_he_kicad.py      # optional, needs kicad-cli: ERC + DRC (zones refilled, parity)
```

`generate_he_gerbers.py` and `generate_he_kicad.py` both refuse to write anything if the DRC fails. `verify_he_gerbers.py` does not re-read the geometry and declare it fine: it replays the Gerber files, including every clear-polarity knockout, labels the copper regions, joins the layers through the vias, and then asserts that each net is one region and that no region carries two nets. It also checks that the sensor keepouts hold no pour copper, that nothing sits over a non-plated hole, and that every copper region holds a pad or a via (no floating slivers, which this writer has no minimum-width pass to remove). Both it and the preview renderer need Pillow.

`check_he_kicad.py` is the independent second opinion: KiCad's ERC on the schematic and DRC on the board with the zones refilled and schematic parity on. It reports warnings and fails on errors. The warnings it leaves are "footprint does not match copy in library" for every part, which is expected: the board carries the library footprints without their silkscreen, because the board's silkscreen (sensor squares, pin-1 dots, labels) comes from `he_board.py` and is the same drawing the Gerbers get.

Copper pours in the Gerbers are real: the pour is filled, then every foreign pad, track, via and NPTH is knocked out with `%LPC*%` using apertures grown by the 0.45 mm pour gap, then the actual copper is flashed back. Isolation gaps show up properly in any fab viewer.

**File format:** the board is written in KiCad 8 syntax (`version 20240108`), which KiCad 8, 9 and 10 all open. The schematic is KiCad 9 syntax, because it embeds the shared symbol library and that library is saved by KiCad 10; it uses `Conn_01x08_1MP` (the connector with its mounting pads as pin MP, on GND) and two `PWR_FLAG`s so ERC and parity are clean. This differs from `MX/` and `Carrier/`, which are native KiCad 10 files. Zones are written as outlines with their clearance and thermal settings; KiCad fills them on open (or any DRC run) — the shipped Gerbers already contain the filled result.

Running `scripts/generate_boards.py` under KiCad's Python regenerates MX and the carrier with `pcbnew` as before; its `build_he()` just calls the generator above, so there is only one definition of this board.

## Controller carrier (`Carrier/`)

- **Outline:** the Waveshare PCB (35.0 × 48.2 mm) with a **22.8 × 34.7 mm window**, open at the USB-C end. The TF card slot, the MX1.25 battery connector and the camera FPC stay reachable.
- **Headers** (from the Waveshare STEP model and drawing):
  - The rows are 30.48 mm apart, 2.26 mm from each long edge.
  - Pin 1 is 7.59 mm from the non-USB edge, 2.54 mm pitch.
- **Seen from the carrier's top** (the side marked `WAVESHARE ON THIS SIDE`): P1 (GPIO2 … 5V) is on the right and P2 (3V3 … VBAT) on the left, both with pin 1 at the non-USB end. This is the mirror image of Waveshare's back-side pinout photo, as it must be.
- **Holes:** 4× M2 at the Waveshare hole positions (29.0 × 42.2 mm, 3.0 mm from the edges).
- **Sockets:** 2× 1×14 female, 8.5 mm tall, soldered on the top side. J_MOD (JST SH) is on the bottom at the non-USB end, opening outward.
- **Free for later:** P1-11/12/13/14 (USB D+, D−, GND, 5V) are on the rail at the USB-C end, unused, ready for an internal USB-C board (still under discussion).
- **Antenna:** there is no copper pour under the bridge, which sits below the Waveshare's ceramic antenna.

### Stack height

| From | To | Distance |
|---|---|---|
| Waveshare PCB back | carrier top | 11.0 mm (2.5 mm male-header plastic + 8.5 mm socket) |
| carrier top | carrier bottom | 1.6 mm |
| carrier bottom | J_MOD bottom (non-USB end only) | 2.9 mm |
| carrier bottom | socket pin tails | about 3 mm; clip them flush after soldering |
| glass front | carrier bottom | about 19.8 mm |

**Use case V1.1** ([`hardware/3d/custom_case/V1.1`](../../3d/custom_case/V1.1/README.md)). The V1 case does not fit this stack: with its 20.3° deck, the carrier's lower long edge reaches the floor and the Waveshare support pillars are in the way. V1.1 does the following:
- tilts the screen at 16° in a raised pod, with the stack 0.6 mm above the floor at its lowest point;
- replaces the pillars with posts under the carrier's M2 holes;
- mounts the input module without screws: pins in the key deck locate it and the bottom plate clamps it;
- routes the cable from the carrier's left end along the left wall to the module's J1 (a 100 mm cable is enough).

---

## Ordering

### Bare PCBs (JLCPCB or PCBWay)

Upload `production/jlcpcb/<board>-gerbers.zip` (JLCPCB) or `production/pcbway/<board>-gerbers-PCBWay.zip` (PCBWay). All boards use standard options:

| Option | Value |
|---|---|
| Layers | 2 |
| Thickness | 1.6 mm (keep it: the Kailh socket and 5.0 mm plate-to-PCB distance assume 1.6 mm) |
| Copper | 1 oz |
| Min track / clearance | 0.25 / 0.2 mm |
| Min drill | 0.3 mm (vias) |
| Via | 0.6 mm (MX, carrier) / 0.7 mm (HE), 0.3 mm hole |
| Finish | HASL lead-free or ENIG |

European fabs: the HE module fits Aisler's "2 layer 1.6 mm HASL" rules (track 0.2, spacing 0.15, drill ≥ 0.3, via ring 0.2, copper to edge 0.3, hole to hole 0.3) and Eurocircuits pattern class 6 / drill class C (track and isolation 0.15, outer ring 0.125 measured from the 0.4 mm production tool, non-plated hole isolation 0.2). Checked against their published tables on 2026-10-10; the MX and carrier vias (0.6 mm) give a 0.15 mm ring, which Aisler HASL does not accept, so order those two with ENIG there or enlarge their vias first.
| Order number | "Specify a location" (JLCPCB): each board has a `JLCJLCJLCJLC` silkscreen mark on the bottom |

The Gerbers include the board outline on its own layer (the carrier's window and corner radii are in Edge.Cuts) plus separate PTH and NPTH drill files.

### Assembly (JLCPCB)

Upload `production/jlcpcb/<board>-BOM-JLCPCB.csv` and `production/jlcpcb/<board>-CPL-JLCPCB.csv`.

**MX module**: assembly side **Bottom**.

| Designator | Part | LCSC |
|---|---|---|
| SW1, SW2 | Kailh CPG151101S11 MX hot-swap socket | C41430893 |
| J1 | JST SM08B-SRSS-TB | C160407 |
| R1, R2, R4 | 10 kΩ 1 % 0603 | C25804 |
| R3 | 100 kΩ 1 % 0603 | C25803 |
| C1 | 100 nF 50 V X7R 0603 | C14663 |

**Hall Effect module**: assembly side **Bottom**.

| Designator | Part | LCSC |
|---|---|---|
| U1, U2 | TI DRV5055A3QDBZR linear Hall sensor, SOT-23 | C266128 |
| J1 | JST SM08B-SRSS-TB | C160407 |
| C1, C2, C3 | 100 nF 50 V X7R 0603 | C14663 |
| R1 | 100 kΩ 1 % 0603 | C25803 |
| R2 | 47 kΩ 1 % 0603 | C25819 |

TP1–TP3 are bare probe pads; they are board features, not parts, and are absent from the BOM and centroid file. U1/U2 are an **Extended** LCSC part, so JLCPCB adds the one-off feeder charge.

> Two part numbers that circulate for this board are wrong and were corrected here: **C2843516 is a Schottky diode** (Jingdao SSL310F), not the DRV5055 — the sensor is **C266128**. And **C25816 is a 383 kΩ resistor**, not 47 kΩ — the 47 kΩ `0603WAF4702T5E` is **C25819**. Building from the older numbers would populate a diode where the Hall sensor goes and put the ID line at 3.3 V × 383/483 = 2.62 V, which the firmware would not recognise as this module.

**Carrier**:

| Designator | Part | LCSC |
|---|---|---|
| J_MOD | JST SM08B-SRSS-TB, bottom side | C160407 |
| J_P1, J_P2 | 1×14 female header, 2.54 mm, 8.5 mm, top side (THT) | C2897377 |

The CPL gives the two sockets at their **centre, rotated 90°**, because JLCPCB's model of C2897377 is centred and lies along X. KiCad's own position file puts them at pin 1 with 0°, and JLCPCB's preview then shows one socket lying across the board. `export_production.py` applies this correction (`JLC_CPL_FIXES`). The socket is symmetric, so 90° and 270° give the same part.

J_MOD is the only SMD part, on the bottom. The two sockets are through-hole on the top: order them assembled as THT, or solder them yourself (plug them onto the Waveshare board while soldering so they stay aligned).

**Check the part rotation in JLCPCB's placement preview before paying.** KiCad and LCSC define rotation differently for some parts, most often the Kailh socket, the JST connector and SOT-23 parts:
- the socket's two pads must cover the two copper pads next to the 3.05 mm holes;
- the JST's 8 contacts sit toward the inside of the board, with the plug opening at the board edge;
- on the HE module U1 and U2 are at **180°**: the single lead (pin 3, GND) must point toward the board's front edge (the `OSUPAD HE` text), the two-lead side (pins 1 and 2) toward the connector, inside the silkscreen square. JLCPCB's preview shows the bottom as seen from below; with the connector edge away from you, pin 1 (VCC) is then the **right-hand** lead of the pair, next to the silkscreen dot. A SOT-23 cannot be placed mirrored, so if the pins sit on the pads the orientation is right; if a sensor shows rotated 90° or 180° with its leads off the pads, rotate it in the preview. Both sensors face the same way, so if one looks wrong they both are.

### AISLER

AISLER reads the parts from a native board file or ODB++ and wants no BOM or centroid file. `scripts/export_aisler.py` writes `<board>/production/aisler/` for every board: `<board>.kicad_pcb` with the zones filled and saved by KiCad, the `JLCJLCJLCJLC` order text removed and `MPN` / `MFG` as separate fields (upload this single file); `<board>-odb.zip`, the same board as ODB++ (the alternative); the schematic PDF; a BOM for checking by eye; a `README.txt` with the order options; and `<board>-aisler.zip` holding all of them. `MPN` is the bare part number, the field AISLER matches on. On the HE module TP1–TP3, the holes and the switch positions are excluded from the BOM and marked DNP so they do not show up as parts. The copy passes KiCad's DRC with the project's rules before it is written. Order as 2 layers, 1.6 mm; the HE module's 0.7 mm vias meet their HASL rules, the MX and carrier's 0.6 mm vias (0.15 mm ring) do not, so order those with ENIG or ask.

### PCBWay

Use the files in `production/pcbway/`, not the `jlcpcb/` ones:
- `<board>-gerbers-PCBWay.zip`: the order-number marker is `WayWayWay` instead of `JLCJLCJLCJLC`.
- `<board>-BOM-PCBWay.csv`: PCBWay's BOM template columns, with manufacturer, part number, type (SMD/THT) and placement notes.
- `<board>-centroid-PCBWay.csv`: placement file.

Order each board as a separate item.

### Loose parts (not on the PCBs)

| Qty | Part | Note |
|---|---|---|
| 1 | JST SH 1.0 mm 8-pin cable, 100 mm, **same-direction** (pin 1 ↔ pin 1) | Many cheap "reverse" cables swap pin 1 ↔ 8: check with a multimeter before plugging in |
| 2 | MX switches (3- or 5-pin) + keycaps | MX module |
| 2 | MX magnetic switches (Gateron KS-20, Magnetic Jade, Wooting Lekker, Geon Raw HE) + keycaps | HE module |
| 1 | 14 × 14 mm switch plate, 1.5 mm, held 5.0 mm above the PCB | both modules; the HE module needs it, since the switches are plate-mounted and nothing holds them to the PCB |
| 4 | M2 spacers, 8.5 mm (or 8 mm + washer), optional | Carrier to the Waveshare standoffs; the sockets hold a first prototype on their own |

## Before the first order

1. Print `production/<board>-pcb.pdf` at 100 % and lay the Waveshare board and two switches on it. The HE module has no PDF; use `production/he_input_v1-bottom.png` (2240 px wide = 52.0 mm, so print it at 1094 dpi for 1:1) or open the `.kicad_pcb`.
2. In the JLCPCB preview, check socket, connector and SOT-23 rotation (see above).
3. Check the cable direction with a multimeter.
4. Order 5 of each and test-fit before a larger batch.
5. For the HE module, measure before committing to a batch: probe IN1/IN2 with the switch at rest and fully pressed. If the swing is much under ~0.5 V, move to a DRV5055A2 or A1 (drop-in, same footprint) rather than respinning the board.

## Testing the assembled boards

With the Waveshare on the carrier, the MX module on the cable and the pad
connected, run `opadctl board-test` or open **Diagnostics → PCB Test** in the
app. Release both keys while it runs. The pad checks
(`firmware/main/diag/board_test.c`, judged in
`desktop/crates/opad-model/src/board_test.rs`):

| Check | How | Typical faults it finds |
|---|---|---|
| Input module | ID voltage on GPIO8, 0.30 V for MX | Cable unplugged; P2-1 / P2-2 / P1-8 sockets not soldered; R3/R4 wrong |
| Cable | Pulls GPIO2 up: on a reversed cable this powers the module's IN2 pull-up onto ID | A pin 1 ↔ 8 "reverse" JST cable |
| Key pins | Keys must be GPIO10 / GPIO7 with the carrier | Old hand-wired pins (the app and `--fix-pins` set them) |
| Key 1 / Key 2 line | Swaps the pad's pull-up for a pull-down: R1/R2 (10 kΩ) must still hold the line high | Open line (cable, J1/J_MOD pin 3/4, socket P1-10/P1-9, R1/R2); line shorted to GND |
| Spare lines | Connector pins 6–8 must follow the pad's pulls, and must not follow a driven neighbour | Solder bridges on J_MOD or J1 |

It does not press the switches for you: afterwards, press each key in
Diagnostics → Switch Chatter & Input (or watch the counters in `opadctl status`).
Key 1 and Key 2 must each register on their own.

---

## Files

```
V1/
├── lib/                      project library shared by all boards
│   ├── osupad.kicad_sym      R, C, SW_Push, DRV5055, Conn_01x08, Conn_01x08_1MP, Conn_01x14, TestPoint, PWR_FLAG
│   └── osupad.pretty/        0603 R/C, SOT-23, JST SH, pin socket, M2 hole, Kailh hot-swap, Hall switch positions, test pad
├── Carrier/                  controller_carrier_v1.kicad_pro / .kicad_sch / .kicad_pcb, production/
├── MX/                       mx_input_v1.kicad_pro / .kicad_sch / .kicad_pcb, production/
├── HE/                       he_input_v1.kicad_pro / .kicad_sch / .kicad_pcb, production/
├── mechanical_reference_case_coords.dxf   case, plate cutouts, input PCB outline/holes/J1 (case coordinates)
└── scripts/
    ├── gen_library.py           writes the standard parts in lib/ (symbols, 0603 R/C, SOT-23, JST SH, pin socket, M2 hole)
    ├── generate_boards.py       generator for projects (see below)
    ├── export_production.py     ERC + DRC + parity check, then Gerbers, drills, BOM, CPL, PDFs, STEP, renders
    ├── he_board.py              HE module: geometry, netlist, placement and its own DRC (no KiCad needed)
    ├── generate_he_gerbers.py   HE module: Gerbers, drills, job file, BOM, CPL
    ├── generate_he_kicad.py     HE module: .kicad_sch / .kicad_pcb / .kicad_pro
    ├── verify_he_gerbers.py     HE module: rasterise the Gerbers, check the netlist for opens/shorts/islands
    ├── render_he_preview.py     HE module: top/bottom artwork previews
    ├── check_he_kicad.py        HE module: KiCad ERC + DRC (parity) through kicad-cli, optional
    ├── export_aisler.py         every board: filled native board + ODB++ for AISLER (reads parts from the board)
    └── strokefont.py            single-stroke vector font for generated silkscreen
```

The shared library gained two footprints and three symbols for this module: `SW_MX_Hall_PlateMount_SolidCentre` (peg holes only, no stem hole), `TestPoint_Pad_1.0x1.0mm`, and the `TestPoint`, `Conn_01x08_1MP` and `PWR_FLAG` symbols.

Each `production/` folder contains `-schematic.pdf`, `-pcb.pdf`, `.step` (for the case CAD), top/bottom renders and the ERC/DRC reports, plus one subfolder per fab: `jlcpcb/` (`-gerbers.zip`, `-BOM-JLCPCB.csv`, `-CPL-JLCPCB.csv`), `pcbway/` (`-gerbers-PCBWay.zip`, `-BOM-PCBWay.csv`, `-centroid-PCBWay.csv`) and `aisler/` (native board, ODB++, `-aisler.zip`; see Ordering).

- **Regenerating:** `python3 hardware/pcb/V1/scripts/generate_boards.py` rebuilds the schematics and boards from the netlist in the script and overwrites any edits made in KiCad. After editing in KiCad, only run `export_production.py` (JLCPCB and PCBWay files, PDFs, STEP, renders) and `export_aisler.py`. Both export every board by default. Pass board folders to export only those, e.g. `export_production.py Carrier`.
- **Requirements:** KiCad 10 (`kicad-cli` and the `pcbnew` Python module) for MX and the carrier. The KiCad libraries don't need to be installed: everything used is in `lib/`.
- **Library:** every part in `lib/` is OPad's own drawing under the repository's MIT license. The standard parts are written by `scripts/gen_library.py` (pads and pins from the component datasheets; outlines, silkscreen, courtyards and symbol graphics computed by the script); edit the tables there and re-run it rather than editing those files in KiCad. The Kailh hot-swap, Hall switch and test-pad footprints are hand-drawn. Footprints reference KiCad's installed 3D models by path (`${KICAD10_3DMODEL_DIR}`); the models themselves are not in this repository.
- **The HE module is the exception:** it is generated and verified with plain Python (3.9+), no KiCad and no `pcbnew`; Pillow is needed only for `verify_he_gerbers.py` and `render_he_preview.py`, and `kicad-cli` only for the optional `check_he_kicad.py`. Its `production/` folder has no `drc.json`/`erc.json`/PDF/STEP, because those come from `kicad-cli`; run `export_production.py` under a KiCad install if you want them. CI does not run the HE scripts; run them by hand before ordering.

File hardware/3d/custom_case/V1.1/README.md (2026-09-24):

# OPad case V1.1

Revision of `../V1` for the V1 PCBs: the controller carrier on its 8.5 mm sockets and the MX or Hall Effect input module. The PCBs are unchanged (`hardware/pcb/V1`). The case coordinates are the same as V1, so the key centres (28.475 / 47.525, 16.5) and the module holes (15.5 / 60.5, 16.5) have not moved.

**Fully screwless:** the bottom plate snaps on, the input module is clamped between the key deck and the bottom plate, and the screen is held by its glass on a taped ledge.

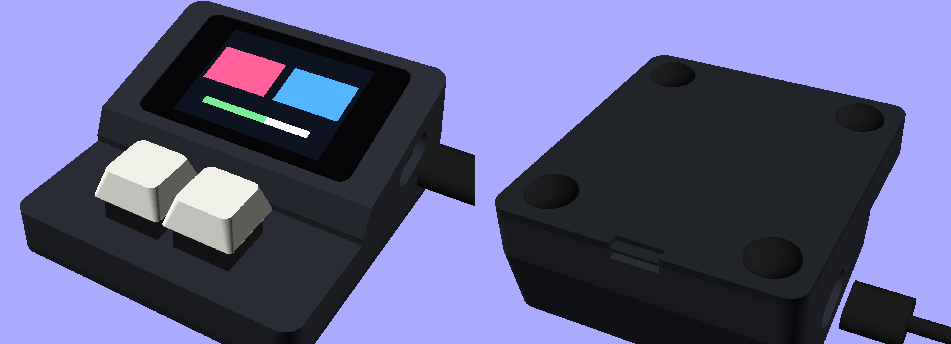
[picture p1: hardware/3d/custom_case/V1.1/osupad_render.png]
V1.1 finished


## What changed from V1

| | V1 | V1.1 |
|---|---|---|
| Height, key deck | 17.0 mm | **12.0 mm** |
| Height, rear | 37.0 mm | **33.3 mm** |
| Footprint | 76 × 86 mm | **76 × 82.5 mm** |
| Walls | 2.2 mm | **2.4 mm** (3 perimeters at 0.4 mm, the usual design-guide minimum) |
| Screen tilt | 20.3° | **16°** |
| Glass | 0.1 mm below the frame, 0.09 mm clearance per side | **flush with the frame** (on 0.15 mm tape), 0.3 mm clearance per side, 1.25 mm ledge |
| Carrier stack | did not fit (floor, pillars) | fits; 0.6 mm above the floor at its lowest point |
| Screen supports | 4 pillars, not on the Waveshare holes | 4 posts under the carrier's M2 holes, 0.5 mm below it |
| Input module | no mount | **screwless:** pins under the key deck locate it, posts on the bottom plate clamp it |
| Snap fit | short relief-cut tabs that flex across the print layers (≈ 6 % strain, likely to crack) | **rigid rim with 0.55 mm beads at mid-span**; the long top-case walls take the flex (≈ 1–2 % strain) |
| Feet | 4 × Ø 10 recesses | **4 × Ø 12.7 recesses** for soft silicone bumpers |

The screen sits in its own raised pod behind a step. The 8.5 mm sockets make the Waveshare + carrier stack about 20 mm deep, and that depth, not the key deck, sets the rear height. The remaining height comes from three things:
- the tilt: every degree less lowers the rear by about 0.35 mm;
- the socket pin tails, which set how close the stack can get to the floor;
- the 2.5 mm male-header plastic on the Waveshare.

## Keeping it in place

There is no added weight: a 3D-printed pad of this size stays put on a desk mat with the right feet.
- **Feet:** four soft **silicone** bumpers, 12.7 mm (1/2"), about 3.5 mm tall, in the corner recesses. Silicone grips a cloth mat far better than hard rubber or felt.
- **Infill:** the case prints at about 50 g if solid (40.7 cm³ of PLA), so 100 % infill (or PETG) adds 15–20 g over a typical 20 %.
- **Tapping helps:** each press pushes the pad down onto its feet, which increases the grip at the moment it matters. Slipping comes from the small sideways part of a tap.
- **If it still moves:** stick a 1 mm self-adhesive silicone anti-slip sheet over the whole base instead of the four feet.

## Parts

| Qty | Part | For |
|---|---|---|
| 4 | Silicone bumper, Ø 12.7 mm, ~3.5 mm tall, self-adhesive | corner recesses |
| — | Thin double-sided tape, 0.1–0.15 mm | glass edge on the ledge (`TAPE_T`; thicker tape leaves the glass proud) |
| optional 4 + 4 | M2 × 8.5 mm male-female spacers + M2 × 4 mm screws | Waveshare standoffs to carrier, if you want the stack rigid; the posts leave room for the screw heads |

No screws or inserts are needed for the case itself.

## Assembly

1. Fit the switches into the input module's hot-swap sockets through the key deck from the top, with the module held underneath, components facing down and J1 toward the screen. The two pins under the deck go through the module's M2 holes.
2. Plug the Waveshare onto the carrier. Plug the JST cable into J_MOD at the carrier's left (non-USB) end.
3. Lower the screen stack into the pod from the top, USB-C to the right, and tape the glass edge to the ledge.
4. Route the cable forward along the left wall and into the module's J1. A 100 mm same-direction cable leaves about 40 mm of slack.
5. Snap the bottom plate on: its posts clamp the module against the key deck. It is removed by prying at the rear notch.
6. Stick the four feet into the recesses.

## Printing

- **Top case:** upright, open side down, with supports under the key deck and the screen pod.
- **Bottom plate:** base down, no supports.
- **Material:** PLA works. PETG is tougher at the snap beads and slightly heavier.

## Files

| File | |
|---|---|
| `osupad_params.scad` | every dimension, and the derived heights |
| `osupad_enclosure.scad` | the parts: `PART = "top_case"`, `"bottom_plate"` or `"assembly"` |
| `osupad_case_top.stl`, `osupad_case_bottom.stl` | print files |
| `osupad_render.png`, `osupad_preview.png` | finished render (front and underside), and the bare case |
| `tools/check_fit.py` | intersects everything that goes inside (below) with each case part; exits 1 on any overlap |
| `tools/reference_models.scad` | the Waveshare stack, carrier, input modules, USB plug and cable as envelopes |
| `tools/waveshare_back.scad` | the Waveshare's back-side components as boxes, measured from Waveshare's STEP model (the model itself is not included) |

After changing a parameter:

```
python3 tools/check_fit.py                 # needs OpenSCAD; about a minute
python3 tools/check_fit.py -D TILT=14      # any parameter can be overridden
openscad -o osupad_case_top.stl    -D 'PART="top_case"'     osupad_enclosure.scad
openscad -o osupad_case_bottom.stl -D 'PART="bottom_plate"' osupad_enclosure.scad
```

Checked on 2026-09-24:
- 39 intersections are clear: 19 reference parts × 2 case parts, plus the two case parts against each other.
- Deliberate collisions are detected, which confirms the check reports real overlaps:
  - `-D FLOOR_CLR=-1.5` drops the screen stack 2 mm: caught on the carrier, tails, J_MOD and screw heads.
  - Lowering the module 0.5 mm is caught on the PCB against the clamp posts, and on J1 against the floor.
- Both STLs are watertight.
- The module's clamp posts and deck bosses touch the PCB exactly: 0 mm nominal. FDM tolerance decides whether it is snug or has a few tenths of play.

**Not yet checked on a real print:**
- the glass fit;
- the snap beads;
- the module clamp.

Print the bottom plate first: it's quick, and it shows whether the beads click and the posts reach the module.

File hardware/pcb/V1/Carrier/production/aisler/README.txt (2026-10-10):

OPad Controller Carrier V1 for AISLER
=====================================

Upload controller_carrier_v1.kicad_pcb (native KiCad board, zones filled, parts carry
MPN and MFG fields) or controller_carrier_v1-odb.zip (ODB++ of the same board).  AISLER
reads the components from either; no BOM or placement file is needed.

Board options
  2 layers, 1.6 mm FR-4, 1 oz copper, HASL or ENIG, green mask.
  Vias are 0.6 mm with a 0.3 mm hole (0.15 mm ring): below AISLER's HASL
  rule of 0.2 mm, so order ENIG or ask whether they accept it.

Assembly
  J_MOD (JST SH) is the only SMD part, on the BOTTOM side. J_P1/J_P2 are
  through-hole sockets on the TOP side (the side marked WAVESHARE ON THIS
  SIDE); order them as THT or solder them yourself.
    J_P2         HCTL PM254-1-14-Z-8.5 (WAVESHARE_P2, top, THT, LCSC C2897377)
    J_P1         HCTL PM254-1-14-Z-8.5 (WAVESHARE_P1, top, THT, LCSC C2897377)
    J_MOD        JST SM08B-SRSS-TB(LF)(SN) (MODULE, bottom, SMD, LCSC C160407)

Source: hardware/pcb/V1 (generate_boards.py); these files were written by
scripts/export_aisler.py.

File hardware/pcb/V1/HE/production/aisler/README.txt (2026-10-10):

osuPad Hall Effect Input Module V1 for AISLER
=============================================

Upload he_input_v1.kicad_pcb (native KiCad board, zones filled, parts carry
MPN and MFG fields) or he_input_v1-odb.zip (ODB++ of the same board).  AISLER
reads the components from either; no BOM or placement file is needed.

Board options
  2 layers, 1.6 mm FR-4, 1 oz copper, HASL or ENIG, green mask.
  Meets AISLER's "2 layer 1.6 mm HASL" rules: track 0.25 / spacing 0.2 mm,
  vias 0.7 mm with a 0.3 mm hole (0.2 mm ring), copper to edge 0.3 mm.

Assembly
  Every part is on the BOTTOM side (SMD). TP1-TP3 are bare probe pads, H1/H2
  mounting holes and SW1/SW2 the switch positions: board features (DNP), not
  parts. The Gateron magnetic switches go in later by hand.
  U1/U2 (SOT-23): the single lead (pin 3, GND) points to the front edge (the
  "OSUPAD HE" text), the two leads to the connector; pin 1 (VCC) is next to
  the silkscreen dot. A SOT-23 cannot be placed mirrored, so if the leads sit
  on the pads the orientation is right.
    U1,U2        Texas Instruments DRV5055A3QDBZR (DRV5055A3, bottom, SMD, LCSC C266128)
    C2,C3,C1     YAGEO CC0603KRX7R9BB104 (100nF, bottom, SMD, LCSC C14663)
    J1           JST SM08B-SRSS-TB(LF)(SN) (MODULE, bottom, SMD, LCSC C160407)
    R1           UNI-ROYAL 0603WAF1003T5E (100k, bottom, SMD, LCSC C25803)
    R2           UNI-ROYAL 0603WAF4702T5E (47k, bottom, SMD, LCSC C25819)

Source: hardware/pcb/V1 (he_board.py); these files were written by
scripts/export_aisler.py.

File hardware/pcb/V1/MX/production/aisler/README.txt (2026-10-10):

osuPad MX Input Module V1 for AISLER
====================================

Upload mx_input_v1.kicad_pcb (native KiCad board, zones filled, parts carry
MPN and MFG fields) or mx_input_v1-odb.zip (ODB++ of the same board).  AISLER
reads the components from either; no BOM or placement file is needed.

Board options
  2 layers, 1.6 mm FR-4, 1 oz copper, HASL or ENIG, green mask.
  Vias are 0.6 mm with a 0.3 mm hole (0.15 mm ring): below AISLER's HASL
  rule of 0.2 mm, so order ENIG or ask whether they accept it.

Assembly
  Switch sockets, J1, R1-R4 and C1 are all on the BOTTOM side (SMD).
    R1,R2,R4     UNI-ROYAL 0603WAF1002T5E (10k, bottom, SMD, LCSC C25804)
    C1           YAGEO CC0603KRX7R9BB104 (100nF, bottom, SMD, LCSC C14663)
    J1           JST SM08B-SRSS-TB(LF)(SN) (MODULE, bottom, SMD, LCSC C160407)
    R3           UNI-ROYAL 0603WAF1003T5E (100k, bottom, SMD, LCSC C25803)
    SW2          Kailh CPG151101S11 (KEY2, bottom, SMD, LCSC C41430893)
    SW1          Kailh CPG151101S11 (KEY1, bottom, SMD, LCSC C41430893)

Source: hardware/pcb/V1 (generate_boards.py); these files were written by
scripts/export_aisler.py.

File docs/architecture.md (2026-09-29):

# OPad Architecture

## 1. Design Overview
OPad is a competitive two-key osu! keypad and telemetry display based on the Waveshare ESP32-S3-Touch-LCD-2 board.

The system is separated into two strictly decoupled layers:
1. **Low-Latency Keyboard Subsystem (ESP32-S3 firmware)**:
   - Targets a 1 ms (1000 Hz) USB HID polling interval.
   - Eager debounce: First edge accepted immediately in RAM, followed by lockout window (500–20,000 µs, default 5,000 µs).
   - Dedicated hardware GPIO interrupts waking the highest-priority input task on Core 0.
   - Operates fully independently from display, host software, CDC telemetry, tosu, or persistence.
2. **Auxiliary Telemetry & Management Subsystem (Host Daemon + Display)**:
   - Single-owner headless daemon (`osupad-daemon`) handling SQLite storage, tosu WebSocket connection, USB CDC protocol framing, and background synchronization.
   - Desktop application (`osupad-gui`) hosting the system tray, configuration controls, layout designer, and live diagnostics.
   - Command-line tool (`osupadctl`) for scripting, diagnostics, backups, and native USB firmware flashing.
   - Inter-process communication exclusively through local Unix domain socket IPC (`osupad-ipc`).

---

## 2. Invariant: Latency Always Wins
Per Section 3 of the technical specification:
> *"If a feature measurably worsens keyboard latency or latency jitter, the feature is reduced, deferred, frozen during gameplay, or removed."*

- **Zero Wait**: No code path handling key input may wait on LCD SPI transfers, NVS commits, CDC serialization, dynamic memory allocation, or host communication.
- **Zero Disk Writes**: When tosu reports `PLAYING` or `COOLDOWN`, all writes to SQLite on the host and NVS on the ESP32-S3 are strictly blocked and buffered in RAM.

---

## 3. Dual-Core Task & Interrupt Map

To shield the key input path from any display or communication stalls, tasks and interrupts are partitioned across the two Xtensa LX7 cores:

```text
+-----------------------------------------------------------------------+
|                                CORE 0                                 |
|  (Dedicated Low-Latency Input & USB HID Stack)                        |
|                                                                       |
|  - Keypad GPIO Edge ISR (Priority 3, ESP_INTR_FLAG_IRAM)              |
|  - Keypad Processing Task (Priority configMAX_PRIORITIES - 1)         |
|  - TinyUSB Stack Task (Priority configMAX_PRIORITIES - 2)             |
+-----------------------------------------------------------------------+
                                   | (Lock-free atomic state & RAM queues)
                                   v
+-----------------------------------------------------------------------+
|                                CORE 1                                 |
|  (Auxiliary Telemetry, Display, & Host Protocol)                      |
|                                                                       |
|  - USB CDC Protocol Task (Priority 5)                                 |
|  - Runtime Supervisor & Cooldown Timer (Priority 4, 100 Hz tick)      |
|  - LVGL Port Task (Priority 3, ST7789 SPI DMA transfers)              |
|  - Display SPI Interrupt Service Routine                              |
+-----------------------------------------------------------------------+
```

---

## 4. LVGL Display Subsystem (A1)

The telemetry display is driven by LVGL v8 via Espressif's `esp_lvgl_port` component:
- **Core Isolation**: The LVGL task and ST7789 SPI DMA controller run exclusively on Core 1. Display refreshes cannot preempt or introduce jitter into Core 0 input tasks.
- **Thread Safety**: All screen updates and data updates acquire `ui_lock()` before modifying LVGL object properties and release `ui_unlock()` immediately.
- **Gameplay Refresh Cap**: While in `PLAYING` mode, display rendering is throttled to 10 Hz (`gameplay_display_hz`), reducing SPI bus traffic by 83% while keeping gameplay animations crisp and fluid.
- **Inactivity Sleep**: If no keypress occurs for `display_sleep_seconds` (default 600 s / 10 min), the display backlight turns off to prevent panel burn-in. The very first keypress edge turns the backlight back on instantly without latency penalty.

---

## 5. Layout Designer & Data-Source Pipeline (A2)

The display interface is completely customizable through the PC layout designer:
1. **Layout Designer**: Built into `osupad-gui` using `iced`. Users can position labels, gauge arcs, hit counters, UR bars, and telemetry widgets on a 240x320 canvas.
2. **Preview Engine**: Powered by `osupad-ui-preview`, an embedded host-side C renderer mirroring firmware draw calls with 100% pixel-level parity.
3. **Data Sources**: Data sources are numbered `0..95` (`firmware/main/ui/core/ui_ids.h`, listed in `docs/protocol.md`). Sources include:
   - Live gameplay: Current PP, Combo, Accuracy, beatmap BPM, Map Progress, Star Rating, Hits (300/100/50/Miss), Key 1/2 Session & Map counts.
   - Player tap rate in PPM (presses per minute, not the beatmap BPM): current/average/peak per attempt, combined and per key, plus averages and peaks over a configurable history period. Computed by the daemon; the pad only displays them.
   - Hardware stats: Device uptime, Core temperature, Key latency min/max/avg.
4. **Binary Data Updates**: The host daemon polls tosu v2 WebSocket, extracts changed telemetry fields, and sends delta updates via `DataUpdate` over USB CDC.
5. **Storage**: Custom screen layouts are saved to the host SQLite database (`layouts` table) and uploaded to the ESP32-S3 over CDC (`SetLayout`), where they are persisted in NVS during `IDLE` state.

---

## 6. System Tray & Desktop Integration (A5)

The system tray icon is hosted by `osupad-gui` rather than the background daemon:
- **Headless Daemon**: `osupad-daemon` runs as a lightweight `systemd --user` service with zero X11, Wayland, DBus UI, or graphics dependencies.
- **Desktop StatusNotifierItem**: On Linux the GUI implements the modern Freedesktop StatusNotifierItem protocol via `ksni` with XEmbed fallback, integrating smoothly into GNOME (via AppIndicator), KDE Plasma, Sway, and Waybar. On Windows the same tray is `tray-icon` over `Shell_NotifyIcon`, behind the same `cfg` split.
- **Single Instance Control**: `osupad-gui` enforces single-instance execution via a dedicated Unix domain socket (`osupad-gui.sock`), or a named object on Windows. Launching a second instance sends a focus message to the existing window and exits cleanly.
- **Autostart**: On Linux the GUI installs `osupad-gui.desktop` to `~/.config/autostart/` with the `--minimized` flag. On Windows it writes `HKCU\...\Run` instead. Either way, startup is silent and straight to the tray.

---

## 6b. IPC transport abstraction (§W0-1)

The daemon owns the device and the database; the GUI and the CLI are clients.
Everything between them is one framed, transport-agnostic protocol:

```
[len: u32 LE][json]        IpcRequest / IpcResponse
```

The framing and the two enums are identical on every platform. **Only the
concrete stream type differs**, and it is a `#[cfg]`-selected alias rather than
a trait or a runtime choice:

| Alias | Unix | Windows |
|---|---|---|
| `IpcStream` | `tokio::net::UnixStream` | `NamedPipeClient` |
| `IpcServerStream` | `UnixStream` | `NamedPipeServer` |
| `IpcListener` | wraps `UnixListener` | one pipe instance per accept |

`$XDG_RUNTIME_DIR/osupad/daemon.sock` on Unix,
`\\.\pipe\osupad-ipc-<user SID>` on Windows. The address is per-user on both,
and so is the access control: `0700` plus a peer check on the socket, a
protected DACL granting only SYSTEM and the calling user on the pipe. If the
Windows side cannot determine the SID it refuses to listen rather than create an
unrestricted pipe.

Two rules that are easy to get wrong and are therefore load-bearing:

- **The accept loops are written per platform**, not shared. A `NamedPipeServer`
  is consumed on connect and a fresh instance must exist for the next client.
- **The handshake rejects a version mismatch.** The daemon, GUI and CLI always
  ship together, so differing versions mean an in-place update replaced the files
  while the old daemon is still running (§U-2). Failing loudly beats misbehaving
  subtly.

`docs/windows-portability.md` has the as-built detail.

---

## 6c. Device pairing / ownership (§W3)

The pad records which host install owns it. This exists to protect **counter
integrity** — a pad that silently changes hands takes 20,000 lifetime presses
somewhere unexpected — and it is not, and must not become, a lock:

- Nothing is cryptographic. No attestation, no signed handshake, no anti-tamper.
- The firmware stays flashable over USB by design.
- **The pad is a keyboard on any machine, with no software and no pairing.**
  Ownership lives entirely on the CDC side.

How it works:

1. Each install generates a **UUIDv4 on first run**, stored in `app_state`
   (§W3-1). No storage means no identity, which means it claims nothing and
   prompts about nothing.
2. The pad keeps a 16-byte `owner_id` in its NVS config blob (§W3-2). Absent or
   all zero means unclaimed.
3. On connect, `HelloAck` carries `owner_id`, and the daemon decides **before
   anything reconciles the counters** — that ordering is the whole point.
   Unclaimed is claimed silently; ours proceeds; someone else's raises the
   takeover prompt and blocks counter sync until it is answered.
4. `ClaimOwnership` is an NVS write, so the firmware honours it **only in
   IDLE** (P1-3). An all-zero claim is refused, so there is no wire path to
   unpairing.
5. The only unbind is a documented full reflash (§W3-4, `docs/recovery.md` §7).
   No GUI button, no on-device factory reset.

---

## 7. Host Runtime State Machine

The daemon tracks osu!lazer gameplay status through tosu's WebSocket API and advances through four states:
- `IDLE`: Normal operation. Telemetry HUD shows clock, total lifetime counters, and system health. Configuration changes and NVS saves execute immediately.
- `PLAYING`: Triggered when tosu reports active gameplay (`state: 2`). All SQLite and NVS disk writes are strictly prohibited. Display refresh is capped at 10 Hz.
- `COOLDOWN`: Exactly 5 seconds after map conclusion or retry. Quick retries instantly transition back to `PLAYING` without flushing to disk.
- `SYNC`: Triggered when cooldown safely expires in `IDLE`. The daemon reconciles lifetime counters, executes pending configuration changes, commits to SQLite, and updates device NVS.

---

## 8. Technical Decisions & Resolution Matrix (§39)

| Topic | Decision | Technical Rationale |
|---|---|---|
| **Switch Pinout** | Default `GPIO 14` (Key 1), `GPIO 9` (Key 2); configurable | Defaults are on Header P2 (pins 11 & 12) next to GND (pin 13). Other pins are chosen from a fixed list of header GPIOs (`config_validate.c`, `KEY_PINS` in `osupad-model`) that avoids strapping pins, USB, UART0, the I2C bus, and `GPIO 17` (board pull-down). |
| **Graphics Engine** | LVGL v8 (`esp_lvgl_port`) | Provides anti-aliased font rendering, robust object hierarchy, and native FreeRTOS SPI DMA task synchronization on Core 1. |
| **Core Affinity** | Core 0: Input & HID; Core 1: Display & Protocol | Guarantees hard physical isolation so display rendering and serial framing cannot interrupt or jitter the 1000 Hz USB HID loop. |
| **Gameplay Hz** | Default 10 Hz (configurable 1–60 Hz) | Eliminates bus contention on Core 1 during dense mania/standard maps while maintaining fluid visual feedback. |
| **Firmware Flashing** | Native `espflash` integration in `osupadctl` and the daemon | Enables single-binary flashing over USB CDC / ROM DFU without requiring Python, esptool, or external dependencies. One engine (`osupad_device::flash`) serves both, so the sequence that can stop the pad being a keyboard exists once. |
| **Partition Layout** | Two 2 MB OTA slots, `nvs` unmoved at `0x9000` (§U-3a) | The table at `0x8000` cannot be rewritten by an OTA update; it needs a serial reflash of every pad in the field. Done while the field is empty, and before the OTA code that will need it. |
| **Firmware Updates** | Host-driven flash of the app partition only, explicit consent every time (§U-3b) | A firmware update is the one operation that can stop the pad being a keyboard. Counters are synced to the host first, the image is verified against the signed manifest *and* its own chip ID, and `erase-flash` is never used because that is where the counters live. |
| **Device Pairing** | Ownership claim in NVS, no enforcement (§W3) | Protects counter integrity from a pad changing hands silently. Deliberately not DRM: anything baked into firmware plus app is extractable from either, so pretending otherwise would buy nothing and cost the user their own hardware. |
| **USB Serial** | Runtime MAC-derived (`OSUPAD-<MAC>`) | Ensures multiple connected pads get unique `/dev/serial/by-id/` entries with zero serial collisions. |

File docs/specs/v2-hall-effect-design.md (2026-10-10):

# Hall Effect module: how it works (DRAFT for discussion)

**Status:** draft, 2026-10-10, updated after the first discussion. Nothing here is decided until we have
talked it through. It turns `docs/specs/v2-rapid-trigger.md` (the plan
written before the board existed) into a design for the board that now
exists, and lists the questions that need an answer before the code.

**Decided so far (2026-10-10, first discussion)**

| # | Topic | Decision |
|---|---|---|
| — | Priorities | **1. latency, 2. accuracy.** Where they conflict, latency wins; accuracy wins over convenience (UI simplicity, CPU, flash wear). |
| 1 | Switches | **Gateron Jade Silent** (magnetic, silent dampers). Curve and default span come from bench strokes of this switch. |
| 3 | Calibration | **Explicit first, automatic later** (§4). |
| 4 | Default | **Behaves like MX out of the box:** plain mode, a fixed actuation point at about mid-travel (an MX switch actuates at ~2.0 mm), release just above it, rapid trigger off. Exact point from the bench. |
| 5 | Settings | The most accurate option: **per key, separate press and release sensitivity** (§5). |
| 6 | Plain mode | **Yes**, and it is the default (decision 4). |
| 7 | LCD travel | **Only while testing or calibrating**, never in normal use. |
| 8 | Module swap | Checked at boot and, cheaply, while idle (never in a map); a change shows "replug the USB cable" on the LCD. In this enclosure the cable usually has to come out to swap anyway. |
| — | Switch swap | Each switch's magnet gives its own key-up reading. A steady, clearly different one at boot means new switches: the LCD asks for a recalibration and the defaults apply until then. |
| 9 | Supply reference | Adaptive: the pad watches its own supply noise and uses the ID-line correction only when it is needed. No user setting. |
| — | IRAM | The HE key path runs from IRAM like MX's; only the fitted module's path runs (§2). |

**What exists today**

- The HE module: two **TI DRV5055A3** ratiometric linear Hall sensors, one
  under each key's magnet, on the PCB bottom, reading through 1.6 mm of FR-4.
  Outputs on IN1/IN2 = **GPIO10 (ADC1_CH9)** and **GPIO7 (ADC1_CH6)**, ID
  divider 100k/47k = 1.06 V on GPIO8 (ADC1_CH7). Spare lines GPIO6/4/2 go to
  probe pads (`hardware/pcb/V1/README.md`, "Hall Effect input module").
- The pad recognises it: on this pad the ID reads 1047 mV open and 382 mV with
  the pull-down (`opadctl board-test`, 2026-10-10), which
  `board_module_from_id` maps to `BOARD_MODULE_HE`
  (`firmware/boards/waveshare_esp32s3_touch_lcd_2/board.c`).
- v1 then turns key input off and shows a notice (`firmware/main/app_main.c`,
  step 1b and step 7). **But the key pins are still armed as digital inputs
  with pull-ups and any-edge interrupts** (`board_keys_set_gpio` in
  `board.c`). The ISR returns early while input is off
  (`gpio_isr_handler` in `firmware/main/input/keypad.c`), yet a sensor output
  near mid-rail can fire it continuously on core 0, the key core. To fix
  first, whatever else we decide (§9, step 1).
- A measurement build: `CONFIG_OSUPAD_HALL_BENCH` streams both sensors as 1 ms
  averages plus per-second spread (`firmware/main/diag/hall_bench.c`,
  `scripts/hall_bench.py`). **No measurements yet**: the first run was cut
  short (the daemon holds the port, and the GUI restarts the daemon once).

---

## 1. The rules it has to keep (AGENTS.md §1)

| Rule | What it means for HE |
|---|---|
| Latency always wins | Sample → position → decision → HID submit on core 0, at the keypad task's priority, from IRAM, no logging or allocation. Filtering may add at most one sample period. |
| A keyboard with no software | **An HE pad must type out of the box, before any calibration:** rest is measured at boot and a bench-measured default span applies until the explicit calibration runs (§4). |
| App and pad update independently | Old app + new firmware: HE types with its stored or default settings. New app + old firmware: no Rapid Trigger UI (capability flag absent). |
| Touchscreen is the third button | Untouched: the HE path changes K1/K2 only. |
| Never BOOT/RESET | Unchanged; the A/B rollback covers HE builds too. |

## 2. Firmware architecture

One firmware for both modules: the module is detected at boot and picks the
input backend. The spec's Kconfig switch (`OSUPAD_INPUT_DIGITAL/HALL`,
v2-rapid-trigger §V2-1) does not fit swappable modules on one cable.

```text
boot: board_detect_module()
  MX / none  -> digital backend  (today: GPIO edge ISR -> keypad task -> debounce)
  HE         -> hall backend     (ADC DMA -> hall task -> rapid trigger)
                    \_____________ both _____________/
                    key event sink: state, counters, press log, latency stats,
                    usb_hid_handle_key_event(key, pressed, t_us), UI wake
```

- **Key event sink.** Today the counting, press log and HID call live inside
  the ISR and `keypad_task` (`keypad.c`). They move behind one function both
  backends call, so a rapid-trigger press counts, logs and reports exactly
  like a switch press. `t_us` is the edge time for MX and the sample time for
  HE, so the latency stats keep meaning "physical event → USB submit".
- **Swapping modules** needs a power cycle (replug); detection is boot-only,
  as today (open question, §10.3).
- **IRAM.** The hall task, the travel conversion and the engine join
  `firmware/main/linker.lf`, like the key path did in `1a3c038`.
  - *Can the MX path be unloaded when HE is fitted?* Not usefully. IRAM
    placement is fixed when the firmware is linked, not at runtime. Copying
    code into executable heap at boot would mean turning off the S3's
    memory protection (`CONFIG_ESP_SYSTEM_MEMPROT_FEATURE`) and fighting
    Xtensa literal pools, all to free about **2.5 KB**: what the MX-only
    code takes in IRAM today (`keypad.c` 2488 B + `board.c` key reads 64 B,
    from `build/opad-firmware.map`; the USB part, about 6.5 KB, serves both
    modules). IRAM in use is about 86 KB of the S3's 512 KB internal SRAM.
  - What matters for latency is that the **unused backend does not run**:
    with HE fitted, no key GPIO interrupt, no keypad task wake-ups, and the
    pins left analog. With MX fitted, the ADC is never started and the hall
    task never created. Both paths stay resident in IRAM, so whichever runs
    never waits on a flash cache miss.

## 3. Sampling

- **ADC1 continuous (DMA) mode.** On the S3 only ADC1 has working DMA
  (v2-rapid-trigger §2.2), and all module lines are ADC1.
- **Proposal: three channels.** K1 (CH9), K2 (CH6) and **the ID line
  (CH7)** as a supply reference. The DRV5055's output is ratiometric to its
  3.3 V supply, while the ADC measures against its internal reference, so
  supply ripple and drift look like key travel. The ID divider sits on the
  same 3.3 V, so `key / id` cancels it. Caveat: the divider's ~32 kΩ source
  impedance is high for a scanned ADC (README, "Module ID"); it only needs a
  slow average, but the bench has to show it settles.
- **Rate and frames.** Target ≥ 4 kHz per key. The ID line changes only as
  fast as the supply, so it does not need an equal share: the S3's pattern
  table holds 24 entries (`SOC_ADC_PATT_LEN_MAX`), so a pattern of
  K1,K2 × 11 then ID × 2 gives the keys ~92 % of the conversions. Sketch:
  ~30 kHz total, a frame per DMA interrupt of ~0.25 ms, each frame averaged
  per channel (oversampling instead of a slow filter, so no added delay
  beyond the frame). The DMA callback only notifies the hall task. Wake rate
  ~4 kHz on core 0, to check against the USB task's budget.
- **If the bench shows the supply is quiet enough,** the ID channel is
  dropped and the keys get every conversion (latency first).
- **Attenuation** 12 dB (about 0–3.1 V). DRV5055 at 3.3 V sits at 1.65 V with
  no field and swings by its sensitivity times the field, either way
  depending on magnet polarity.

## 4. From raw reading to travel, and calibration without an app

- **Per key:** `rest` raw value (key up), `bottom` raw value (bottomed out),
  and the sign (which way the reading moves on a press: magnet polarity
  differs by switch brand).
- **Travel** in 0.01 mm, from a curve: the field falls off steeply with
  distance, so equal raw steps are not equal travel. Start with a per-switch
  lookup table (16 points, from bench strokes), scaled between `rest` and
  `bottom` (v2-rapid-trigger §4).
- **Phase 1: explicit calibration (decision 3).** Rule 2 still holds: an
  uncalibrated HE pad types.
  - `rest`: averaged at every boot while both readings are steady. It is
    accepted only if it is close to the stored one, so a key held down
    while plugging in cannot poison it; otherwise the stored value is used.
    This part is automatic from the start: it is trivial and safe.
  - `bottom` and sign: set by an **explicit calibration** ("leave both keys
    up", then "press each key fully 5 times"), started from the app or
    `opadctl calibrate`, with live travel on the LCD while it runs
    (decision 7). Saved to NVS, in IDLE only.
  - Before the first calibration: the default span for Gateron Jade Silent
    measured on the bench, so a new pad types at once.
- **Phase 2: automatic calibration,** once phase 1 is proven on the pad:
  `rest` tracked slowly while a key is up and still (temperature drift),
  `bottom` refined from the deepest presses seen. Never while pressed or in
  PLAYING; NVS writes only in IDLE.
- **Silent switches.** The Jade Silent's damper compresses, so "bottomed
  out" is not one reading: it depends on how hard the key is hit. The
  calibration takes the typical deepest reading of the 5 presses, not the
  single deepest, and the bench measures how much it moves between a soft
  and a hard press.
- **Resolution worry.** A3 is the least sensitive variant (≈16 mV/mT, README
  "Sensor sensitivity"), and the sensor reads through the board. Because the
  field rises steeply only near the bottom, resolution near the top of the
  travel may be too coarse for 0.15 mm sensitivity there. The bench decides
  whether A3 is enough or the next batch should be A2 (Q2).

## 5. Rapid trigger

The state machine in v2-rapid-trigger §3.3 as written (actuation point,
press and release sensitivity, top and bottom dead zones, continuous mode),
in pure C with host tests in `firmware/test/host`, plus replays of bench
traces.

- **Two modes per key:** plain (fixed actuation point, release a little above
  it as hysteresis) and rapid trigger.
- **Default: plain, at about mid-travel, like an MX switch (decision 4).**
  Rapid trigger is off until turned on in the app. (A threshold at the very
  bottom would not work with the silent damper (§4): a soft press would
  never reach it.)
- **Settings per key, press and release sensitivity separate (decision 5).**
  The two sensors and magnets never match exactly, so per-key values are the
  accurate choice. The app may offer a "link" toggle as a convenience; the
  firmware always stores four values.

## 6. Protocol (additive, both directions compatible)

| Change | Old app, new pad | New app, old pad |
|---|---|---|
| `HelloAck.input_module` (the existing `InputModule` enum, `protocol/osupad.proto`) and `HelloAck.rapid_trigger` capability | ignored | absent → no RT UI |
| `ConfigPayload`: per key actuation, press/release sensitivity, dead zones, continuous (0 = keep current, like the swipe fields) | pad keeps its own | not sent |
| `DeviceStatus.calibrated` | ignored | absent |
| Calibration start / step / result messages | never sent | not offered |
| `LiveTravel` stream: both positions ≤ 60 Hz, **only when the app asks and never in PLAYING/COOLDOWN** | never sent | not offered |

The daemon stores the settings like the other config (SQLite, JSON backups,
deferred during gameplay).

## 7. App

- **Rapid Trigger page**, shown only when `input_module` is HE: mode
  (plain / rapid trigger) per key, actuation point, press and release
  sensitivity, continuous toggle, live travel bars with the markers,
  calibration wizard.
- **LCD:** live travel only during calibration and the HE board test
  (decision 7).
- **Board test for HE** (extends `opad-model/src/board_test.rs`): each sensor
  at rest within the expected band around 1.65 V (absent sensor or cut
  trace reads at a rail), reversed cable, spare lines.

## 8. Latency budget

Wait for the sample (≤ 0.27 ms) + averaging (inside the frame) + decision and
submit (tens of µs, measured at ~70 µs edge→submit for MX after `1a3c038`) +
USB poll (≤ 1 ms, unchanged). Electronically like MX; the gain is travel
(rapid trigger re-presses after ~0.15 mm instead of crossing a fixed ~2 mm
point). Validation as v2-rapid-trigger §V2-8.

## 9. Order of work

| Step | What | Needs you at the pad |
|---|---|---|
| 1 | HE pins left analog in today's firmware (no pull-ups, no key ISR) | no |
| 2 | Bench: rest noise, slow full strokes per key, fast taps, ID-line ratio | **yes, ~5 min** |
| 3 | Rapid-trigger engine (plain + RT) + host tests | no |
| 4 | Key event sink refactor (MX behaves byte-for-byte as today, latency rechecked) | quick MX check |
| 5 | Hall backend in IRAM: sampling, rest at boot, default span → **HE pad types, plain at bottom-out** | yes |
| 6 | Explicit calibration + protocol + daemon + app page + HE board test | yes |
| 7 | Latency and tapping validation, docs | yes |
| 8 | Automatic calibration (phase 2) | yes |

## 10. Bench result: the fitted sensors do not sense (2026-10-10)

Bench build on this pad, readings in raw 12-bit counts at 12 dB:

| Line | Reading | Meaning |
|---|---|---|
| ID (GPIO8) | 1211 | 1.06 V: the ADC and the module's 3V3/GND are fine |
| GPIO6 probe pad, internal pull-up | 4095 | 3.3 V is above full scale |
| IN1 / IN2, keys up | ~3535 both | ≈ 3.06 V = the DRV5055's top limit (VL max = VCC − 0.2 V) |
| IN1 / IN2, keys pressed fully | unchanged | no response to the magnet |
| IN2 with the **switch removed** | unchanged | not the magnet: no field, still at the top |
| IN1/IN2 with internal pull-down / pull-up | −12 / +2 counts | the line is actively driven, not open |

A working DRV5055 outputs VCC/2 ≈ 1.65 V with no field. The datasheet's
fault table (§7.1.4) gives "GND disconnects → output close to VCC", which
fits. The design is not the cause: pinout matches the datasheet (SOT-23:
1 VCC, 2 OUT, 3 GND), KiCad DRC finds no unconnected pad, the switch
footprint has a solid centre, and the firmware never drives these lines
(board test uses pulls only). Suspects, both sensors alike: sensor GND
pin (pin 3) not soldered, wrong part on the reel, or wrong placement.
Next: multimeter on U1/U2 (pin 1 = 3.3 V, pin 3 = 0 V and continuous to
module GND, pin 2 = ~1.65 V with no magnet), and a look at the parts.

Follow-up the same day, with a multimeter on the chip legs: VCC 3.36 V,
GND 0.0 V (and continuous to the connector's ground tabs), OUT 2.90 V,
on both sensors. Ruled out since: soldering, a second HE board (reads the
same), the carrier (connectors only), the Waveshare side (GPIO10/GPIO7
also go to the camera connector as CAM_D5/CAM_D6, with no parts on them,
and no camera is fitted), a latch-up (a 10 s USB unplug changes nothing,
no chip is warm), and a fake part (marking reads "55A3", TI's code for
DRV5055A3). A switch magnet held directly on a chip moves its output by
only ~20–30 mV, upwards only. Datasheet VQ at 3.3 V is 1.59–1.71 V. All
four chips from the one JLCPCB order sit saturated high: the remaining
suspect is the batch (damaged in assembly or defective). Next: a JLCPCB
claim, and two or three DRV5055A3 from an authorised distributor fitted
by hand to confirm.

**Root cause (found the same day): the SOT-23 footprint is mirrored.** TI's
DBZ top view (datasheet Figure 4-1) has pin 1 top-left, pin 2 bottom-left,
pin 3 right; turned so pins 1–2 are on top, pin 1 is on the right. The
footprint in `hardware/pcb/V1/scripts/he_board.py` (`FOOTPRINTS[FP_SOT23]`)
and `scripts/gen_library.py` (`lib/osupad.pretty/SOT-23.kicad_mod`) puts
pin 1 on the left, i.e. the mirror image. The bottom-side transform then
mirrors it correctly, so the copper ends up with top-side chirality: in the
KiCad board (pcbnew API) U1 pad 1 (3V3) is at x = 129.425 and pad 2 (IN1)
at 127.525, while a real chip on B.Cu with pin 3 on pad 3 has pin 1 at
127.525. Every chip therefore sits with **VCC on the IN line and OUT on
3V3**, powered backwards through its OUT→VCC protection diode: 3.36 V −
~0.46 V = the 2.90 V measured on the "OUT" pad, driven low-impedance and
nearly blind to the field. JLCPCB placed the parts correctly; DRC cannot see
this (connectivity is right, only the package's pin order is mirrored).

Also found: the daemon's config push on every connect re-arms the key pins
and stopped the ADC conversions until restarted. The HE backend must keep
host config away from the HE pins (step 1).

## 11. Still open

1. HE board V1.1: fix the SOT-23 footprint (swap pads 1 and 2), re-route
   U1/U2, add a pin-order self-test, regenerate, reorder. Nothing else on
   the HE side can be measured until a sensor reads ~1.65 V at rest.
   Done and reviewed end to end on 2026-10-10 (pinout against TI's
   datasheet, J1 against the built MX board, fab rules, KiCad ERC/DRC);
   the review's findings and the data behind the sensor-variant choice
   are in `hardware/pcb/V1/README.md`, "Hall Effect input module".
   Expect the output to rise on a press (the Jade's N pole faces the
   PCB) from about 1.8 V to about 2.4–2.6 V with A3.
2. Sensor variant (A3 or other): decided by the bench once sensors work.

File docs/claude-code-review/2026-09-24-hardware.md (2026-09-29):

# Hardware review: PCBs (`hardware/pcb/V1`) and case (`hardware/3d/custom_case/V1`)

- Date: 2026-09-24
- Base: `main` @ `f78bfbd`, clean tree
- Tools: KiCad 10.0.6 (`kicad-cli`, `pcbnew` Python, KiCad MCP server), OpenSCAD 2021.01, trimesh. Waveshare references: the ESP32-S3-Touch-LCD-2 schematic PDF, the 2024-11-08 mechanical drawing/STEP, and the wiki pinout image.
- Method: ERC + DRC with schematic parity and zone refill on all three boards; pad-level comparison of board footprints against `lib/`; production files regenerated and diffed against the committed ones; carrier pin map checked against the Waveshare schematic and back-view pinout; the case checked for interference against a Waveshare + carrier stack built from Waveshare's drawing, and against the input module, switches and keycaps.
- Verification: every finding below was reproduced *(verified)*. Case clearances come from a box model of the stack, so they are accurate to the dimensions quoted, not to the last 0.1 mm.
- Status legend: `open` / `fixed` / `wontfix` / `invalid`

Findings are ranked most severe first.

---

## 1. The Waveshare + carrier stack collides with the case — `fixed` *(verified)*

**Fixed in case V1.1** (`hardware/3d/custom_case/V1.1`): 16° screen pod with the stack 0.6 mm above the floor, pillars replaced by posts under the carrier holes, and a fit check (`tools/check_fit.py`) that passes. V1 is kept unchanged.

**File:** `hardware/3d/custom_case/V1/osupad_enclosure.scad:332`
**Category:** mechanical

`hardware/pcb/V1/README.md` already says "the V1 case does not fit this stack". The 3D intersection shows exactly where:

| Part of the stack | Hits | Detail |
| --- | --- | --- |
| Carrier PCB (left arm) | rear-left pillar (18.6, 73.5), h 19.2 | 27 mm³ overlap |
| J_MOD on the carrier bottom | same pillar | 2 mm³ overlap |
| Carrier lower long edge | case floor | 0.26 mm clearance |
| Socket pin tails, clipped to 1 mm | case floor | touching (−0.07 mm) |

The four "screen support pillars" are also not on the Waveshare holes. The holes sit at case X = 38 ± 21.1 = 16.9 / 59.1, while the pillars are at X = 18.6 / 60.8, 1.7 mm off. Nothing else in the case holds the carrier.

**Suggested fix:**
- Delete the pillars.
- Add four M2 standoffs from the bottom plate, square to the deck, at the Waveshare hole positions (deck-local ±21.1 × ±14.5 mm). Size them to the carrier bottom, 19.8 mm below the glass front.
- Raise the screen deck by at least 3 mm so the carrier edge and the solder tails clear the floor.

The front pillars (Y 44.5) clear everything. USB-C access was checked too and does **not** need changing: the side channel of the screen cutout passes a 12 × 6.5 mm plug overmold.

## 2. `he_input_v1.kicad_sch` cannot be opened by any KiCad — `open` *(verified)*

**File:** `hardware/pcb/V1/scripts/generate_he_kicad.py:578`
**Category:** correctness

`write_schematic` writes each `NOTES` string with `'(text "%s" …'` without escaping it. The note at line 549 contains `"Hall Effect module V1"` in double quotes, which ends the string early. `kicad-cli sch erc` fails with `Expecting '(' … line 875, offset 85`, and eeschema won't open the file.

**Knock-on:** `export_production.py` processes MX → HE → Carrier. `run()` calls `sys.exit` when the HE ERC fails, so **the carrier is never exported** by a full run.

**Suggested fix:** escape `"` and `\` in every string the generator writes (notes, property values), or drop the inner quotes. Then regenerate.

## 3. One broken footprint disables the whole `osupad` footprint library in KiCad 10 — `fixed` *(verified)*

**Fixed 2026-09-25:** the `fp_rect` now uses `(fill no)`. The library load test is not added yet.

**File:** `hardware/pcb/V1/lib/osupad.pretty/SW_MX_Hall_PlateMount.kicad_mod:59`
**Category:** correctness

The `fp_rect` uses the schematic-style fill syntax `(fill (type none))`, which the footprint parser rejects. KiCad then drops the entire library:
- every footprint on all three boards gets a `lib_footprint_issues` "library 'osupad' is not enabled" warning;
- ERC reports `footprint_link_issues` for every symbol;
- "Update footprints from library" does not work in the GUI.

No board uses this footprint. Replacing the fill with `(fill no)` fixes it; that was confirmed by loading the patched library.

**Suggested fix:** use `(fill no)`. Since the file is hand-drawn and not produced by `gen_library.py`, also add a load test for the library, e.g. `kicad-cli fp export svg` over `osupad.pretty`.

## 4. `export_production.py` cannot pass on a clean KiCad 10 setup; the README's "zero warnings" status no longer holds — `open` (carrier fixed) *(verified)*

**Carrier fixed 2026-09-25:** regenerated from `generate_boards.py`. It now passes `export_production.py Carrier` with 0 problems, and its copper, mask, paste and drill files are unchanged. MX is still open.

**File:** `hardware/pcb/V1/scripts/export_production.py:33`
**Category:** tooling

`ACCEPTED_WARNINGS` is empty, so any warning stops a board. Even with #2 and #3 fixed, MX and the carrier still fail, because commit `4dabf93` regenerated `lib/` after the boards were last checked (the committed `drc.json` files date from 2026-09-14):

| Board | ERC `lib_symbol_mismatch` | DRC `lib_footprint_mismatch` |
| --- | --- | --- |
| MX | 8 | 8 |
| Carrier | 3 | 7 |
| HE | 8 | 13 |

The drift is **cosmetic**. A pad-by-pad comparison (position, size, drill, shape, type, angle) shows every board footprint identical to its library version, so the silkscreen, courtyard and text differ but the copper and drills don't.

The committed Gerbers and drill files are current: MX and the carrier regenerate byte-identical apart from the job file's dates, and HE apart from timestamps.

**Suggested fix:**
1. Update symbols and footprints from the library on MX and the carrier, or re-run `generate_boards.py`.
2. Re-run `export_production.py`.
3. Confirm the copper and drill Gerbers are unchanged.
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

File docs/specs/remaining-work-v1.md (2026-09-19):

# OPad — Remaining Work to v1.0 (Linux)

**Companion to:** `osupad_technical_spec_v1.md` (the contract)
**Audience:** Antigravity and other coding agents
**Baseline:** commit `79622d7` plus the uncommitted working tree as of 2026-09-13. Line numbers refer to that state and may drift; search for the quoted symbol if a line no longer matches.

---

## 0. How to use this document
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

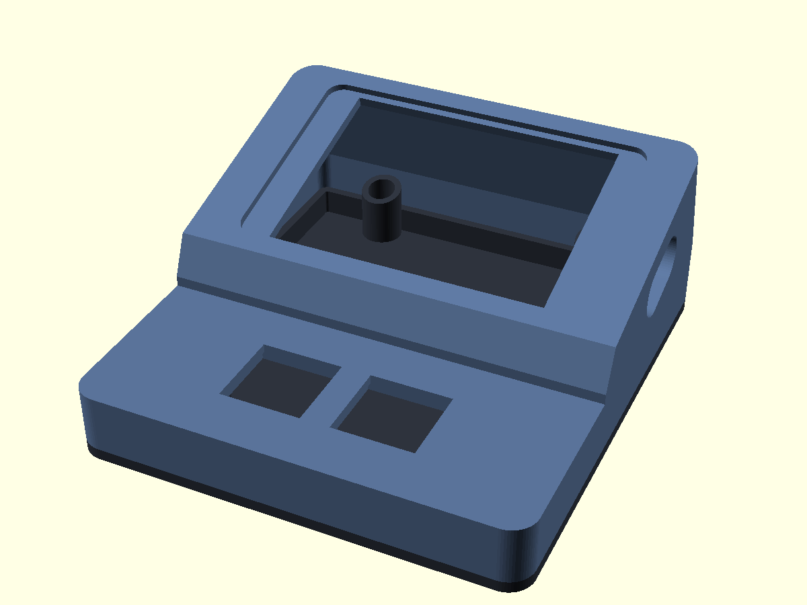
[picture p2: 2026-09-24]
hardware/3d/custom_case/V1.1/osupad_preview.png

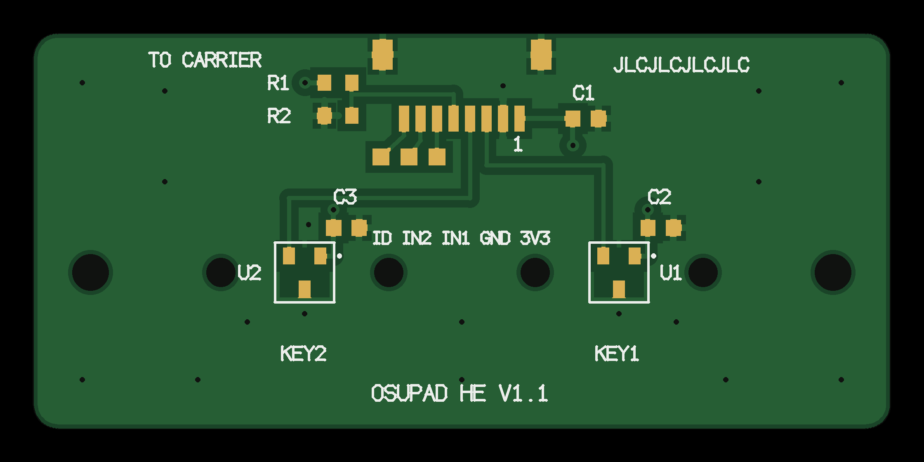
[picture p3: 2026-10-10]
hardware/pcb/V1/HE/production/he_input_v1-bottom.png

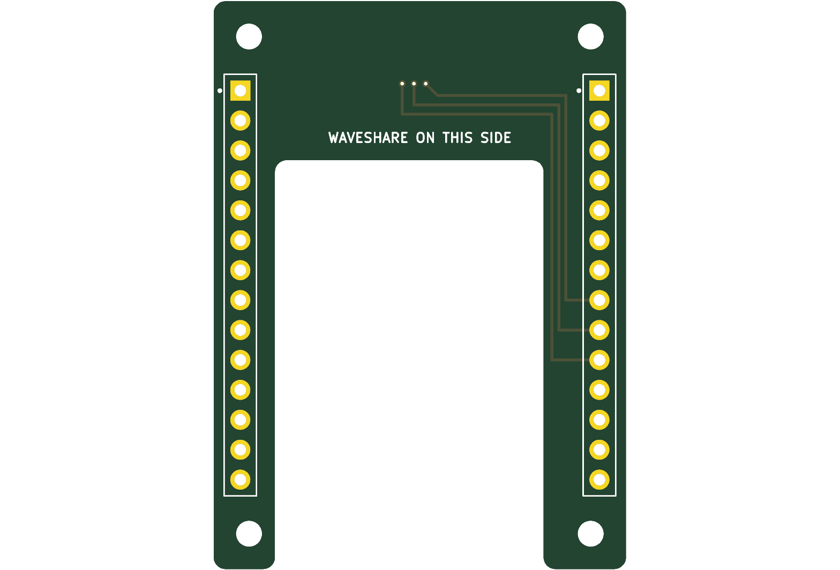
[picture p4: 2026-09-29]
hardware/pcb/V1/Carrier/production/controller_carrier_v1-top.png

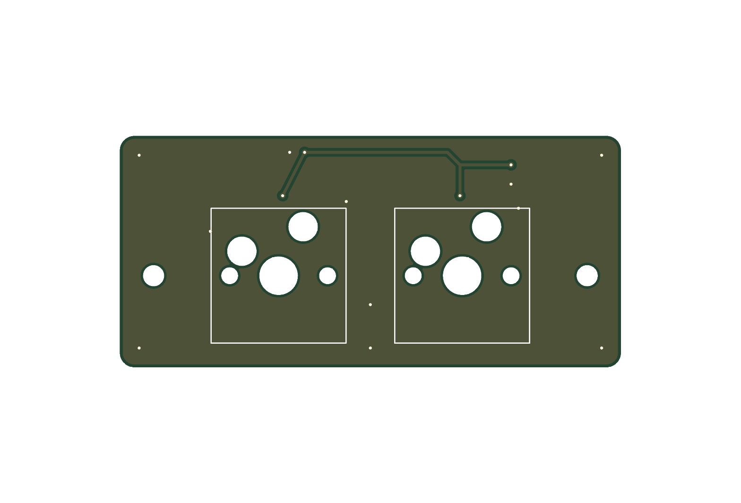
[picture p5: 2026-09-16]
hardware/pcb/V1/MX/production/mx_input_v1-top.png

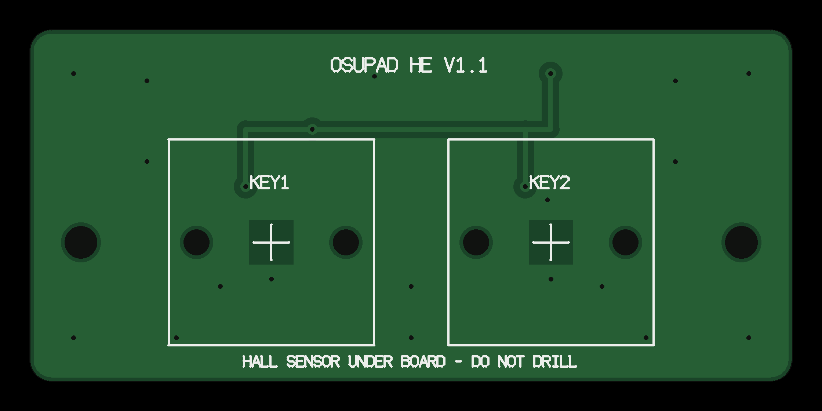
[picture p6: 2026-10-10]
hardware/pcb/V1/HE/production/he_input_v1-top.png

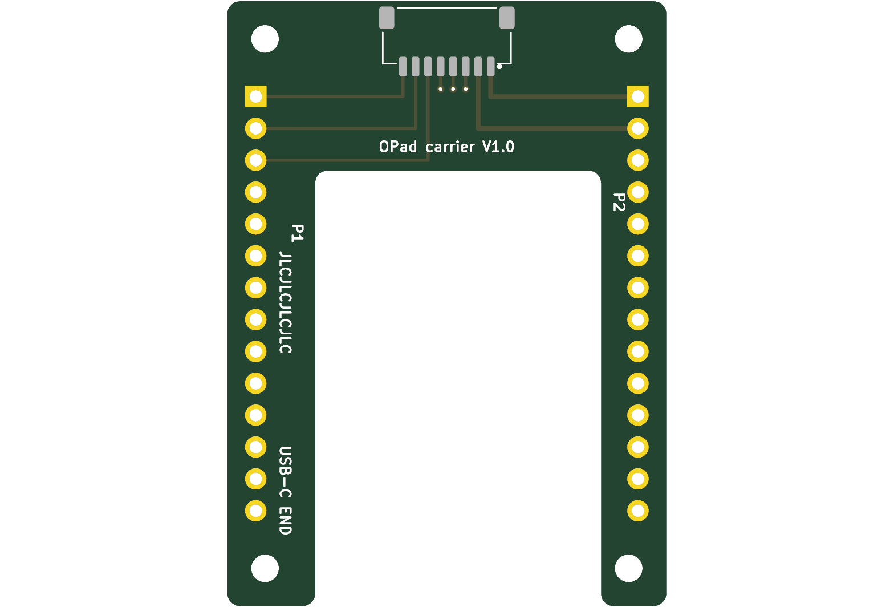
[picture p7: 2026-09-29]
hardware/pcb/V1/Carrier/production/controller_carrier_v1-bottom.png

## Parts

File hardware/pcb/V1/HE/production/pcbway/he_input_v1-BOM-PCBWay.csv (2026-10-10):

Item # | Designator | Qty | Manufacturer | Mfg Part # | Description / Value | Package/Footprint | Type | Your Instructions / Notes
1 | J1 | 1 | JST | SM08B-SRSS-TB(LF)(SN) | MODULE | JST_SH_SM08B-SRSS-TB_1x08-1MP_P1.00mm_Horizontal | SMD | BOTTOM side. Cable opening faces the nearest board edge; the 8 contacts sit inward | the two retention tabs toward the edge
2 | U1,U2 | 2 | Texas Instruments | DRV5055A3QDBZR | DRV5055A3 | SOT-23 | SMD | BOTTOM side | on the key centre over solid FR-4. Seen from the bottom with the connector edge away from you: the two leads (pins 1-2) point to the connector | the single lead (pin 3 | GND) to the near edge | and pin 1 (VCC) is the right-hand one of the two | next to the silkscreen dot
3 | C1,C2,C3 | 3 | YAGEO | CC0603KRX7R9BB104 | 100nF | C_0603_1608Metric | SMD | Bottom side
4 | R1 | 1 | UNI-ROYAL | 0603WAF1003T5E | 100k | R_0603_1608Metric | SMD | Bottom side
5 | R2 | 1 | UNI-ROYAL | 0603WAF4702T5E | 47k | R_0603_1608Metric | SMD | Bottom side

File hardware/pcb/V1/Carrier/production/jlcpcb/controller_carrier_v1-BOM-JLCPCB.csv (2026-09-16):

Comment | Designator | Footprint | LCSC Part # | MPN | Quantity
MODULE | J_MOD | JST_SH_SM08B-SRSS-TB_1x08-1MP_P1.00mm_Horizontal | C160407 | JST SM08B-SRSS-TB(LF)(SN) | 1
WAVESHARE_P1 | J_P1 | PinSocket_1x14_P2.54mm_Vertical | C2897377 | HCTL PM254-1-14-Z-8.5 | 1
WAVESHARE_P2 | J_P2 | PinSocket_1x14_P2.54mm_Vertical | C2897377 | HCTL PM254-1-14-Z-8.5 | 1

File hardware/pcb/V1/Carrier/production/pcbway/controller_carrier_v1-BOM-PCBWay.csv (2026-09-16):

Item # | Designator | Qty | Manufacturer | Mfg Part # | Description / Value | Package/Footprint | Type | Your Instructions / Notes
1 | J_MOD | 1 | JST | SM08B-SRSS-TB(LF)(SN) | MODULE | JST_SH_SM08B-SRSS-TB_1x08-1MP_P1.00mm_Horizontal | SMD | BOTTOM side. Cable opening faces the nearest board edge
2 | J_P1 | 1 | HCTL | PM254-1-14-Z-8.5 | WAVESHARE_P1 | PinSocket_1x14_P2.54mm_Vertical | THT | TOP side (side marked WAVESHARE ON THIS SIDE), solder on bottom. Keep perpendicular to the board
3 | J_P2 | 1 | HCTL | PM254-1-14-Z-8.5 | WAVESHARE_P2 | PinSocket_1x14_P2.54mm_Vertical | THT | TOP side (side marked WAVESHARE ON THIS SIDE), solder on bottom. Keep perpendicular to the board

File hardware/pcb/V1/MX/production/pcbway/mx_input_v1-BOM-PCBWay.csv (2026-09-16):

Item # | Designator | Qty | Manufacturer | Mfg Part # | Description / Value | Package/Footprint | Type | Your Instructions / Notes
1 | C1 | 1 | YAGEO | CC0603KRX7R9BB104 | 100nF | C_0603_1608Metric | SMD | Bottom side
2 | J1 | 1 | JST | SM08B-SRSS-TB(LF)(SN) | MODULE | JST_SH_SM08B-SRSS-TB_1x08-1MP_P1.00mm_Horizontal | SMD | BOTTOM side. Cable opening faces the nearest board edge
3 | R1,R2,R4 | 3 | UNI-ROYAL | 0603WAF1002T5E | 10k | R_0603_1608Metric | SMD | Bottom side
4 | R3 | 1 | UNI-ROYAL | 0603WAF1003T5E | 100k | R_0603_1608Metric | SMD | Bottom side
5 | SW1 | 1 | Kailh | CPG151101S11 | KEY1 | Kailh_CPG151101S11_MX_Hotswap_Bottom | SMD | Hot-swap socket on BOTTOM side. Two metal tabs on the two pads; plastic body over the 3.05 mm holes
6 | SW2 | 1 | Kailh | CPG151101S11 | KEY2 | Kailh_CPG151101S11_MX_Hotswap_Bottom | SMD | Hot-swap socket on BOTTOM side. Two metal tabs on the two pads; plastic body over the 3.05 mm holes

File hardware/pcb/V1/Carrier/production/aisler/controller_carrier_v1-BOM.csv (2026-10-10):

Reference | Quantity | Value | Footprint | MFG | MPN | LCSC | Side | Type
J_P2 | 1 | WAVESHARE_P2 | PinSocket_1x14_P2.54mm_Vertical | HCTL | PM254-1-14-Z-8.5 | C2897377 | top | THT
J_P1 | 1 | WAVESHARE_P1 | PinSocket_1x14_P2.54mm_Vertical | HCTL | PM254-1-14-Z-8.5 | C2897377 | top | THT
J_MOD | 1 | MODULE | JST_SH_SM08B-SRSS-TB_1x08-1MP_P1.00mm_Horizontal | JST | SM08B-SRSS-TB(LF)(SN) | C160407 | bottom | SMD

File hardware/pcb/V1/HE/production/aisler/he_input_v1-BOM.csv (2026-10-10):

Reference | Quantity | Value | Footprint | MFG | MPN | LCSC | Side | Type
U1,U2 | 2 | DRV5055A3 | SOT-23 | Texas Instruments | DRV5055A3QDBZR | C266128 | bottom | SMD
C2,C3,C1 | 3 | 100nF | C_0603_1608Metric | YAGEO | CC0603KRX7R9BB104 | C14663 | bottom | SMD
J1 | 1 | MODULE | JST_SH_SM08B-SRSS-TB_1x08-1MP_P1.00mm_Horizontal | JST | SM08B-SRSS-TB(LF)(SN) | C160407 | bottom | SMD
R1 | 1 | 100k | R_0603_1608Metric | UNI-ROYAL | 0603WAF1003T5E | C25803 | bottom | SMD
R2 | 1 | 47k | R_0603_1608Metric | UNI-ROYAL | 0603WAF4702T5E | C25819 | bottom | SMD

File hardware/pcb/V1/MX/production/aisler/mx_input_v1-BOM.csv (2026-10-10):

Reference | Quantity | Value | Footprint | MFG | MPN | LCSC | Side | Type
R1,R2,R4 | 3 | 10k | R_0603_1608Metric | UNI-ROYAL | 0603WAF1002T5E | C25804 | bottom | SMD
C1 | 1 | 100nF | C_0603_1608Metric | YAGEO | CC0603KRX7R9BB104 | C14663 | bottom | SMD
J1 | 1 | MODULE | JST_SH_SM08B-SRSS-TB_1x08-1MP_P1.00mm_Horizontal | JST | SM08B-SRSS-TB(LF)(SN) | C160407 | bottom | SMD
R3 | 1 | 100k | R_0603_1608Metric | UNI-ROYAL | 0603WAF1003T5E | C25803 | bottom | SMD
SW2 | 1 | KEY2 | Kailh_CPG151101S11_MX_Hotswap_Bottom | Kailh | CPG151101S11 | C41430893 | bottom | SMD
SW1 | 1 | KEY1 | Kailh_CPG151101S11_MX_Hotswap_Bottom | Kailh | CPG151101S11 | C41430893 | bottom | SMD

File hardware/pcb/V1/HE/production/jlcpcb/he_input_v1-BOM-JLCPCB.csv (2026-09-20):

Comment | Designator | Footprint | LCSC Part # | MPN | Quantity
MODULE | J1 | JST_SH_SM08B-SRSS-TB_1x08-1MP_P1.00mm_Horizontal | C160407 | JST SM08B-SRSS-TB(LF)(SN) | 1
DRV5055A3 | U1,U2 | SOT-23 | C266128 | Texas Instruments DRV5055A3QDBZR | 2
100nF | C1,C2,C3 | C_0603_1608Metric | C14663 | YAGEO CC0603KRX7R9BB104 | 3
100k | R1 | R_0603_1608Metric | C25803 | UNI-ROYAL 0603WAF1003T5E | 1
47k | R2 | R_0603_1608Metric | C25819 | UNI-ROYAL 0603WAF4702T5E | 1

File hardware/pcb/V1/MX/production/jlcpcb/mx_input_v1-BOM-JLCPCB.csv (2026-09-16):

Comment | Designator | Footprint | LCSC Part # | MPN | Quantity
100nF | C1 | C_0603_1608Metric | C14663 | YAGEO CC0603KRX7R9BB104 | 1
MODULE | J1 | JST_SH_SM08B-SRSS-TB_1x08-1MP_P1.00mm_Horizontal | C160407 | JST SM08B-SRSS-TB(LF)(SN) | 1
10k | R1,R2,R4 | R_0603_1608Metric | C25804 | UNI-ROYAL 0603WAF1002T5E | 3
100k | R3 | R_0603_1608Metric | C25803 | UNI-ROYAL 0603WAF1003T5E | 1
KEY1 | SW1 | Kailh_CPG151101S11_MX_Hotswap_Bottom | C41430893 | Kailh CPG151101S11 | 1
KEY2 | SW2 | Kailh_CPG151101S11_MX_Hotswap_Bottom | C41430893 | Kailh CPG151101S11 | 1

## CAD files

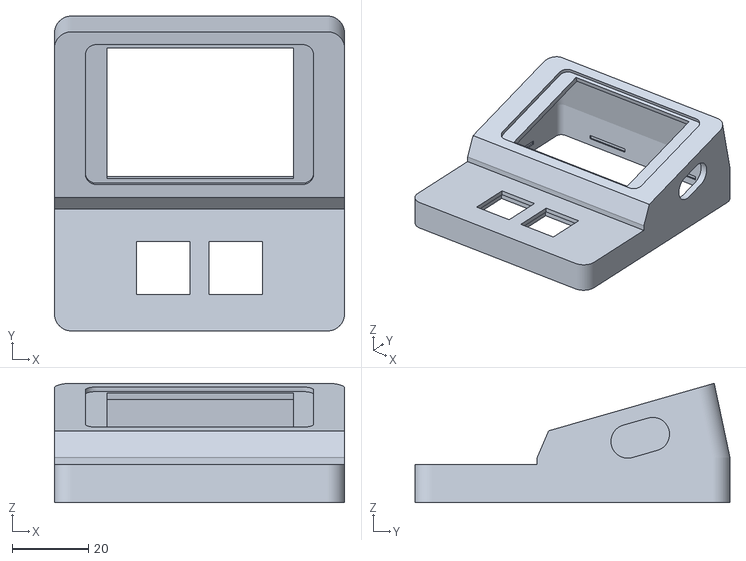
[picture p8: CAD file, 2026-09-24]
hardware/3d/custom_case/V1.1/osupad_case_top.stl
76.0 x 82.5 x 31.3

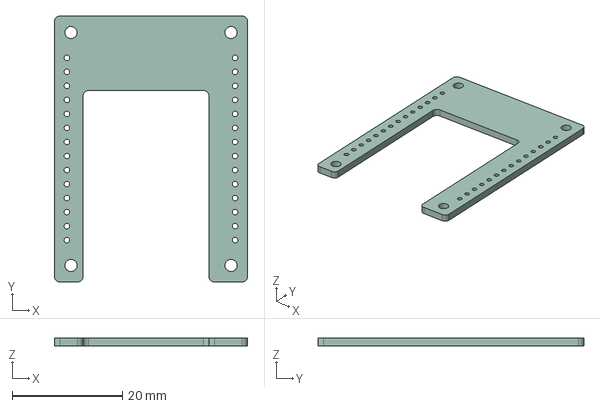
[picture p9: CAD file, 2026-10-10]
hardware/pcb/V1/Carrier/production/controller_carrier_v1.step
35.0 x 48.2 x 1.51 mm

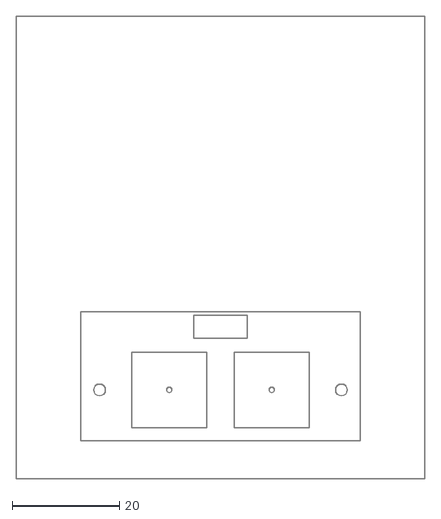
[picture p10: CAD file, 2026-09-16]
hardware/pcb/V1/mechanical_reference_case_coords.dxf
76.0 x 86.0

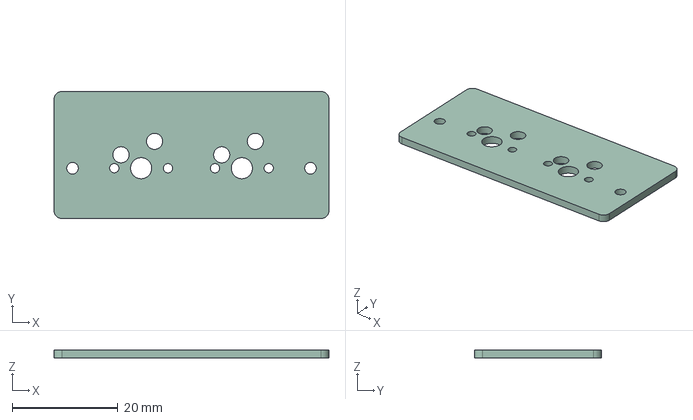
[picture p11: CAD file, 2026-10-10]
hardware/pcb/V1/MX/production/mx_input_v1.step
52.0 x 24.0 x 1.51 mm

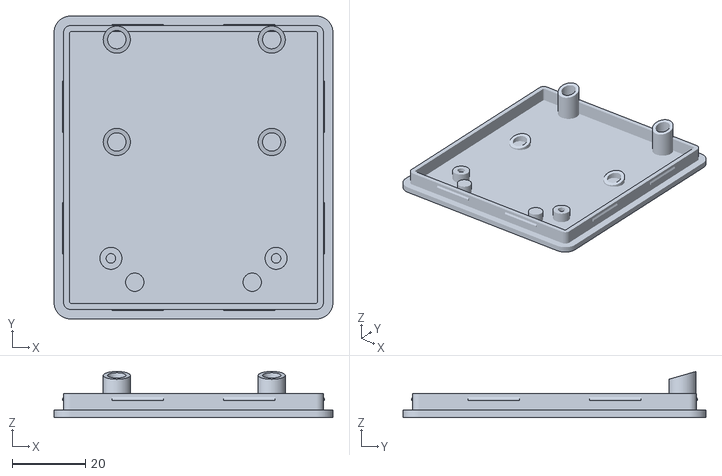
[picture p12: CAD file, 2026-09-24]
hardware/3d/custom_case/V1.1/osupad_case_bottom.stl
76.0 x 82.5 x 12.5

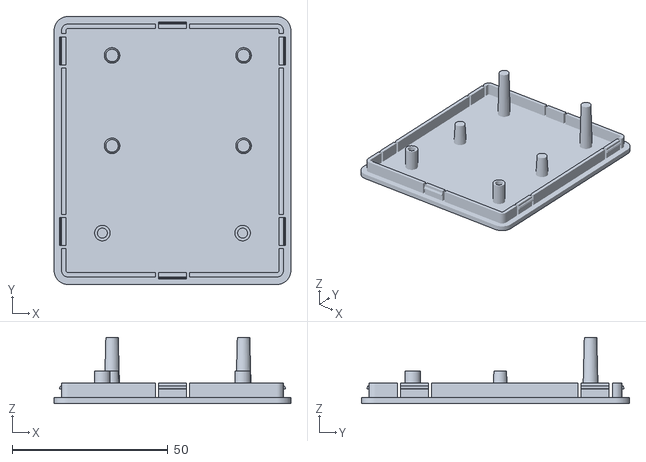
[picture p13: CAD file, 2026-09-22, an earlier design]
hardware/3d/custom_case/V1/osupad_case_bottom.stl
76.0 x 86.0 x 21.2

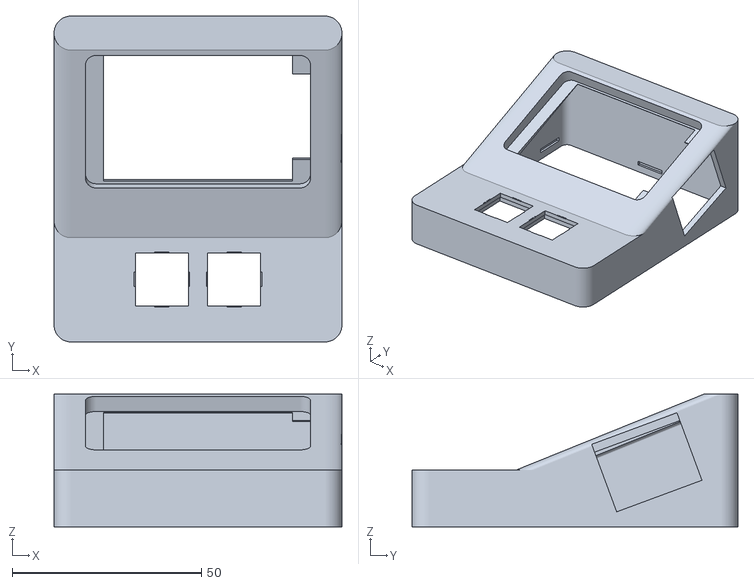
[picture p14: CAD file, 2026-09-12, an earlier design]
hardware/3d/custom_case/V1/osupad_case_top.stl
76.0 x 86.0 x 35.0

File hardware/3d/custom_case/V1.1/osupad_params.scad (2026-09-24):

// =============================================================================
//  OPad V1.1 enclosure: shared parameters
//  Included by osupad_enclosure.scad and tools/fit_check.scad.
//
//  World frame: origin at the front-left bottom corner of the bottom plate,
//  X to the right, Y toward the screen (rear), Z up. The top case sits on the
//  bottom plate's base, so its underside is at z = BASE_T.
//
//  Deck frame (at_deck): origin at the centre of the screen glass, on the deck
//  surface. x = case X, y ("a") up the slope, z along the deck normal, so a
//  point D mm behind the glass front is at z = -D.
// =============================================================================

$fn = 64;

// --- Outline -----------------------------------------------------------------
CASE_W      = 76.0;
WALL        = 2.4;    // 3 perimeters at 0.4 mm (design-guide minimum)
CORNER_R    = 4.5;
BASE_T      = 2.0;    // bottom plate floor
TOL         = 0.20;   // FDM fit clearance

// --- Key deck (MX / HE input module) ----------------------------------------
MX_CUT          = 14.0;
PLATE_T         = 1.5;
MX_PITCH        = 19.05;
KEY_Y           = 16.5;
KEY_X           = [CASE_W/2 - MX_PITCH/2, CASE_W/2 + MX_PITCH/2];   // 28.475 / 47.525
KEY_TOP_T       = 3.8;    // deck skin away from the 16 x 16 switch reliefs
MX_PLATE_TO_PCB = 5.0;
MODULE_PCB_T    = 1.6;
MODULE_BELOW    = 1.85;   // deepest part under the module PCB away from J1 (Kailh socket)
MODULE_J1_BELOW = 2.9;    // JST SH J1 at the module's rear edge
MODULE_HOLES    = [[15.5, 16.5], [60.5, 16.5]];   // M2, hardware/pcb/V1 README
MODULE_OUTLINE  = [12, 7, 64, 31];                // x0, y0, x1, y1
MODULE_J1       = [32.5, 25.6, 43.5, 31.0];       // J1 body footprint

// Screwless module mount: pins under the key deck locate the module through its
// two M2 holes, and posts on the bottom plate clamp it up against the deck.
MODULE_FLOOR_CLR = 0.5;   // J1, the lowest part of either module, above the floor
MODULE_PIN_D     = 1.9;   // in the 2.2 mm NPTH holes
MODULE_PCB_BOT   = BASE_T + MODULE_J1_BELOW + MODULE_FLOOR_CLR;
MODULE_POSTS     = [[22, 10], [54, 10]];   // extra clamp posts, front strip (no parts on MX or HE)
MODULE_PCB_TOP  = MODULE_PCB_BOT + MODULE_PCB_T;
KEY_DECK_H      = MODULE_PCB_TOP + MX_PLATE_TO_PCB;         // world z of the plate top

// --- Screen pod ----------------------------------------------------------------
TILT        = 16;     // deck angle
Y_KEY_END   = 32;     // key deck ends, screen pod begins
POD_Y0      = 35;     // front edge of the pod's top face
POD_TOP_T   = 3.0;    // pod skin (the glass ledge is POD_TOP_T - POCKET_D thick)

// Waveshare ESP32-S3-Touch-LCD-2, from the 2024-11-08 drawing and STEP model
GLASS_X     = 59.22;  // the STEP glass is larger than the drawing's 58.8 x 37.1
GLASS_Y     = 37.52;
GLASS_T     = 1.10;
GLASS_R     = 2.60;
POCKET_CLR  = 0.30;
TAPE_T      = 0.15;   // double-sided tape under the glass edge
POCKET_X    = GLASS_X + 2*POCKET_CLR;
POCKET_Y    = GLASS_Y + 2*POCKET_CLR;
POCKET_R    = GLASS_R + POCKET_CLR;
POCKET_D    = GLASS_T + TAPE_T;          // glass front ends flush with the frame
BORDER      = 3.5;                       // frame between pocket and pod edge
FRAME_A     = POCKET_Y/2 + BORDER;       // half extent of the pod face along the slope

WS_PCB_XC   = 0.21;   // Waveshare PCB centre relative to the glass centre (deck x)
WS_PCB_X    = 48.22;
WS_PCB_Y    = 35.02;
WS_BACK     = 7.2;    // glass front -> Waveshare PCB back
HDR_PLASTIC = 2.5;    // male header plastic on the Waveshare
THROUGH_X   = 48.8;   // deck opening the module and carrier pass through
THROUGH_Y   = 35.6;
USB_D       = 8.37;   // USB-C receptacle centre below the glass front
USB_X       = 25.5;   // receptacle face (deck x)
WS_HOLES    = [[21.31, 14.5], [21.31, -14.5], [-20.89, 14.5], [-20.89, -14.5]];

// Controller carrier V1 (hardware/pcb/V1/Carrier) on 8.5 mm sockets
SOCKET_H    = 8.5;
CARRIER_TOP = WS_BACK + HDR_PLASTIC + SOCKET_H;   // 18.2
CARRIER_T   = 1.6;
CARRIER_BOT = CARRIER_TOP + CARRIER_T;            // 19.8
TAIL        = 1.0;    // socket pin tails, clipped
JMOD_H      = 2.9;
ROW_A       = 15.24;  // socket rows
CARRIER_A   = 17.5;
POST_GAP    = 0.5;    // bottom-plate posts stop this far under the carrier

FLOOR_CLR   = 0.6;    // lowest stack point above the floor

// Lowest point of the stack decides how high the screen sits
function _low(a, d) = a * sin(TILT) - d * cos(TILT);
DZ_LOW  = min(_low(-(ROW_A + 0.9), CARRIER_BOT + TAIL),
              _low(-CARRIER_A, CARRIER_BOT),
              _low(-5.5, CARRIER_BOT + JMOD_H));
Z_C     = BASE_T + FLOOR_CLR - DZ_LOW;           // glass centre height
Y_C     = POD_Y0 + FRAME_A * cos(TILT);          // glass centre Y
H_REAR  = Z_C + FRAME_A * sin(TILT);             // highest point of the case

// Rear: the wall has to clear the carrier's rear-bottom edge
_RC_Y   = Y_C + CARRIER_A * cos(TILT) + CARRIER_BOT * sin(TILT);
_RC_Z   = Z_C + CARRIER_A * sin(TILT) - CARRIER_BOT * cos(TILT);
CASE_L  = ceil((_RC_Y + 0.8 + WALL) * 2) / 2;
Z_KNEE  = _RC_Z + 1.0;   // rear wall is vertical up to here, then leans with the deck

// --- Snap fit ----------------------------------------------------------------
// The bottom plate's rim is rigid; small beads at mid-span of each wall click
// into grooves, and the long top-case walls (free along their bottom edge)
// take the flex. Estimated strain in the walls 1-2 %, far below PLA/PETG
// limits, and the bending stays low enough across the layer lines.
SNAP_BEAD_H = 0.35;
SNAP_BEAD_L = 14.0;
SNAP_Z      = 2.6;    // above the top case's underside
SNAP_SIDE_Y = [CASE_L * 0.3, CASE_L * 0.7];
SNAP_END_X  = [CASE_W * 0.3, CASE_W * 0.7];   // front and rear walls, clear of the pry notch
RIM_H       = 4.6;
RIM_T       = 1.6;

// --- Feet ----------------------------------------------------------------------
FOOT_D      = 12.7;   // soft silicone bumpers, 12.7 mm (1/2")
FOOT_REC    = 0.6;    // locating recess depth
FOOT_POS    = [[10.5, 10.5], [CASE_W - 10.5, 10.5], [10.5, CASE_L - 10.5], [CASE_W - 10.5, CASE_L - 10.5]];

module at_deck() translate([CASE_W/2, Y_C, Z_C]) rotate([TILT, 0, 0]) children();

echo(str("V1.1: key deck ", KEY_DECK_H, " mm, rear ", H_REAR, " mm, length ", CASE_L,
         " mm, glass centre (Y ", Y_C, ", Z ", Z_C, ")"));

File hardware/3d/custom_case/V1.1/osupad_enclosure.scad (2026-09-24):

// =============================================================================
//  OPad V1.1 enclosure
//  - Low flat key deck for the MX / Hall Effect input module (2 keys)
//  - 16 deg screen pod for the Waveshare ESP32-S3-Touch-LCD-2 on the V1
//    controller carrier (8.5 mm sockets); glass flush with the frame
//  - Fully screwless: the input module is located by pins under the key deck
//    and clamped by posts on the bottom plate; the bottom plate snaps on
//  - Recesses for four 12.7 mm silicone feet
//
//  Parts: PART = "top_case" | "bottom_plate" | "assembly"
//  All parameters: osupad_params.scad. Clearance checks: tools/check_fit.py
// =============================================================================

include <osupad_params.scad>

PART = "assembly";

// --- Helpers -------------------------------------------------------------------

// Prism over [x0,x1] x [y0,y1] from z0 to z1; corners listed in `round`
// ("fl", "fr", "rl", "rr" = front/rear, left/right) get radius r.
module rbox(x0, y0, x1, y1, z0, z1, r, round = ["fl", "fr", "rl", "rr"]) {
    function has(c) = len([for (k = round) if (k == c) 1]) > 0;
    hull() for (c = [["fl", x0, y0], ["fr", x1, y0], ["rl", x0, y1], ["rr", x1, y1]]) {
        sx = c[1] == x0 ? 1 : -1;
        sy = c[2] == y0 ? 1 : -1;
        if (has(c[0]))
            translate([c[1] + sx*r, c[2] + sy*r, z0]) cylinder(h = z1 - z0, r = r);
        else
            translate([c[1] + (sx > 0 ? 0 : -0.01), c[2] + (sy > 0 ? 0 : -0.01), z0])
                cube([0.01, 0.01, z1 - z0]);
    }
}

// Rounded rectangle, centred, in the XY plane
module rrect2d(x, y, r) offset(r) square([x - 2*r, y - 2*r], center = true);

// --- Top case ------------------------------------------------------------------

module outer_shell() {
    // key deck, rounded at the front; runs a little into the pod
    rbox(0, 0, CASE_W, Y_KEY_END + 4, BASE_T, KEY_DECK_H, CORNER_R, ["fl", "fr"]);
    // screen pod: the tilted face hulled down to a footprint that is vertical up to Z_KNEE
    hull() {
        at_deck() translate([0, 0, -0.01]) linear_extrude(0.01)
            translate([-CASE_W/2, -FRAME_A]) square([CASE_W, 2*FRAME_A - CORNER_R]);
        at_deck() for (sx = [-1, 1])
            translate([sx * (CASE_W/2 - CORNER_R), FRAME_A - CORNER_R, -0.01]) cylinder(h = 0.01, r = CORNER_R);
        rbox(0, Y_KEY_END, CASE_W, CASE_L, BASE_T, Z_KNEE, CORNER_R, ["rl", "rr"]);
    }
}

module inner_cavity() {
    ir = CORNER_R - WALL;
    // under the key deck, open at the bottom; reaches back into the pod for the cable
    rbox(WALL, WALL, CASE_W - WALL, Y_KEY_END + 4, BASE_T - 1, KEY_DECK_H - KEY_TOP_T, ir, ["fl", "fr"]);
    hull() {
        at_deck() translate([-(CASE_W/2 - WALL), -(FRAME_A - WALL), -POD_TOP_T - 0.01])
            cube([CASE_W - 2*WALL, 2*(FRAME_A - WALL) - ir, 0.01]);
        at_deck() for (sx = [-1, 1])
            translate([sx * (CASE_W/2 - WALL - ir), FRAME_A - WALL - ir, -POD_TOP_T - 0.01]) cylinder(h = 0.01, r = ir);
        rbox(WALL, Y_KEY_END + 3, CASE_W - WALL, CASE_L - WALL, BASE_T - 1, Z_KNEE, ir, ["rl", "rr"]);
    }
}

module screen_cutouts() at_deck() {
    // glass pocket: the glass front ends flush with the frame
    translate([0, 0, -POCKET_D]) linear_extrude(10) rrect2d(POCKET_X, POCKET_Y, POCKET_R);
    // opening the Waveshare + carrier pass through (glass rests on the ledge around it)
    translate([WS_PCB_XC - THROUGH_X/2, -THROUGH_Y/2, -POD_TOP_T - 5]) cube([THROUGH_X, THROUGH_Y, 5 + POD_TOP_T - POCKET_D + 0.01]);
    // USB-C: stadium through the right wall, sized for a 12 x 6.5 mm plug overmold
    translate([USB_X - 1, 0, -USB_D]) rotate([0, 90, 0])
        linear_extrude(CASE_W) hull() for (sa = [-1, 1]) translate([0, sa * 3.4]) circle(r = 4.4);
}

module key_cutouts() for (x = KEY_X) {
    translate([x - MX_CUT/2, KEY_Y - MX_CUT/2, KEY_DECK_H - 5]) cube([MX_CUT, MX_CUT, 10]);
    // 1.5 mm plate for the switch clips, relief underneath
    translate([x - 8, KEY_Y - 8, BASE_T - 1]) cube([16, 16, KEY_DECK_H - PLATE_T - BASE_T + 1]);
}

// Screwless module mount, top half: bosses that the module PCB bears against,
// with pins through its two M2 holes to locate it
module module_bosses() for (h = MODULE_HOLES) translate([h[0], h[1], 0]) {
    translate([0, 0, MODULE_PCB_TOP]) cylinder(h = KEY_DECK_H - KEY_TOP_T - MODULE_PCB_TOP + 0.5, r = 3.2);
    pin_l = MODULE_PCB_T + 1.0;
    translate([0, 0, MODULE_PCB_TOP - pin_l]) {
        translate([0, 0, 0.3]) cylinder(h = pin_l - 0.3 + 0.01, d = MODULE_PIN_D);
        cylinder(h = 0.31, d1 = MODULE_PIN_D - 0.6, d2 = MODULE_PIN_D);   // lead-in chamfer
    }
}

module snap_grooves() {
    z = BASE_T + SNAP_Z - 0.1;
    d = SNAP_BEAD_H + 0.15;   // groove depth into the wall
    l = SNAP_BEAD_L + 1;
    for (y = SNAP_SIDE_Y) {
        translate([WALL - d, y - l/2, z]) cube([d + 0.1, l, 1.3]);
        translate([CASE_W - WALL - 0.1, y - l/2, z]) cube([d + 0.1, l, 1.3]);
    }
    for (x = SNAP_END_X) {
        translate([x - l/2, WALL - d, z]) cube([l, d + 0.1, 1.3]);
        translate([x - l/2, CASE_L - WALL - 0.1, z]) cube([l, d + 0.1, 1.3]);
    }
}

module top_case() {
    difference() {
        union() {
            difference() { outer_shell(); inner_cavity(); }
            module_bosses();
        }
        screen_cutouts();
        key_cutouts();
        snap_grooves();
        // rear pry notch
        translate([CASE_W/2 - 6, CASE_L - 2, BASE_T - 0.1]) cube([12, 4, 2.2]);
    }
}

// --- Bottom plate ----------------------------------------------------------------

// Screwless module mount, bottom half: posts that clamp the module PCB up
// against the key deck bosses (tubes at the holes take the pin tips)
module module_posts() {
    h = MODULE_PCB_BOT - BASE_T + 0.01;
    for (p = MODULE_HOLES) translate([p[0], p[1], BASE_T - 0.01]) difference() {
        cylinder(h = h, r = 3.0);
        translate([0, 0, 0.8]) cylinder(h = h, d = MODULE_PIN_D + 0.7);
    }
    for (p = MODULE_POSTS) translate([p[0], p[1], BASE_T - 0.01]) cylinder(h = h, r = 2.5);
}

// Vertical tubes under the carrier's four M2 holes, topped parallel to the
// carrier and POST_GAP below it: they catch the carrier if it works loose from
// the sockets and leave room for the optional M2 spacer screw heads.
function carrier_hole_world(h) = [CASE_W/2 + h[0],
                                  Y_C + h[1]*cos(TILT) + CARRIER_BOT*sin(TILT),
                                  Z_C + h[1]*sin(TILT) - CARRIER_BOT*cos(TILT)];
module carrier_posts() {
    intersection() {
        for (h = WS_HOLES) let (p = carrier_hole_world(h))
            translate([p[0], p[1], BASE_T - 0.01]) difference() {
                cylinder(h = 30, r = 3.7);
                translate([0, 0, -1]) cylinder(h = 32, r = 2.5);
            }
        at_deck() translate([-CASE_W, -CASE_L, -(CARRIER_BOT + POST_GAP) - 60]) cube([2*CASE_W, 2*CASE_L, 60]);
    }
}

// Snap beads on the rigid rim: flat retaining face below, lead-in ramp above
module snap_bead(len) hull() {
    cube([len, SNAP_BEAD_H + 0.5, 0.4]);
    translate([0, 0, 0.9]) cube([len, 0.5, 0.1]);
}

module snap_beads() {
    z = BASE_T + SNAP_Z;
    o = WALL + TOL;   // rim outer face
    for (y = SNAP_SIDE_Y) {
        translate([o + 0.5, y - SNAP_BEAD_L/2, z]) rotate([0, 0, 90]) snap_bead(SNAP_BEAD_L);
        translate([CASE_W - o - 0.5, y + SNAP_BEAD_L/2, z]) rotate([0, 0, -90]) snap_bead(SNAP_BEAD_L);
    }
    for (x = SNAP_END_X) {
        translate([x + SNAP_BEAD_L/2, o + 0.5, z]) rotate([0, 0, 180]) snap_bead(SNAP_BEAD_L);
        translate([x - SNAP_BEAD_L/2, CASE_L - o - 0.5, z]) snap_bead(SNAP_BEAD_L);
    }
}

module bottom_plate() {
    inner_w = CASE_W - 2*WALL - 2*TOL;
    inner_l = CASE_L - 2*WALL - 2*TOL;
    rim_r   = max(1.0, CORNER_R - WALL - TOL);
    difference() {
        union() {
            rbox(0, 0, CASE_W, CASE_L, 0, BASE_T, CORNER_R);
            // rigid perimeter rim: it locates the plate, the beads click into the walls
            translate([WALL + TOL, WALL + TOL, BASE_T - 0.01]) difference() {
                rbox(0, 0, inner_w, inner_l, 0, RIM_H, rim_r);
                rbox(RIM_T, RIM_T, inner_w - RIM_T, inner_l - RIM_T, -0.1, RIM_H + 1, max(0.5, rim_r - RIM_T));
            }
            snap_beads();
            module_posts();
            carrier_posts();
        }
        // silicone foot recesses
        for (p = FOOT_POS) translate([p[0], p[1], -0.01]) cylinder(h = FOOT_REC + 0.01, d = FOOT_D + 0.4);
        // rear pry notch relief
        translate([CASE_W/2 - 6, CASE_L - 3, -0.1]) cube([12, 5, 1.4]);
    }
}

// --- Render selection ------------------------------------------------------------

if (PART == "top_case")          translate([0, 0, -BASE_T]) top_case();
else if (PART == "bottom_plate") bottom_plate();
else if (PART == "assembly") {
    color([0.35, 0.45, 0.60]) top_case();
    color([0.18, 0.20, 0.24]) bottom_plate();
}

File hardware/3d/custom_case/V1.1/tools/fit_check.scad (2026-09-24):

// Intersection of one reference part with one case part; empty means clear.
// Driven by check_fit.py:  openscad -D 'REF="carrier"' -D 'CASE="bottom"' ...
// include (not use) so that -D overrides reach the case parts too
include <../osupad_enclosure.scad>
include <reference_models.scad>
PART = "none";

REF  = "carrier";
CASE = "top";   // "top" | "bottom" | "case" (both) | "none"

module case_part(c) {
    if (c == "top" || c == "case")    top_case();
    if (c == "bottom" || c == "case") bottom_plate();
}

if (CASE == "none") ref(REF);
else if (REF == "top") intersection() { top_case(); case_part(CASE); }
else intersection() { ref(REF); case_part(CASE); }

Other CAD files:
hardware/3d/custom_case/V1.1/tools/reference_models.scad
hardware/3d/custom_case/V1.1/tools/waveshare_back.scad
hardware/3d/custom_case/V1/osupad_enclosure.scad

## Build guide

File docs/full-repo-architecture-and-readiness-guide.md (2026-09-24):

# OPad Master Architecture Breakthrough & Production Readiness Guide

**Author:** Antigravity (Google DeepMind)  
**Date:** 2026-09-22  
**Scope:** Complete Repository Audit (Firmware, Hardware, Desktop Suite, Shared Crates, Protocols, Packaging & Licensing)

---

## 1. Executive Overview & Mission

OPad is an ultra-low-latency, dual-key rhythm gaming keypad and live telemetry HUD purpose-built for *osu!*. Its design spans high-frequency microcontroller firmware, custom PCB electronics, parametric 3D enclosure modeling, a headless system daemon, a real-time hardware telemetry link, memory scraper integration, and a cross-platform desktop UI.

```
┌─────────────────────────────────────────────────────────────────────────────────────────────┐
│                                     OPAD SYSTEM TOPOLOGY                                    │
└─────────────────────────────────────────────────────────────────────────────────────────────┘

   ┌─────────────────────────────────────────────────────────┐
   │                  PHYSICAL HARDWARE LAYER                │
   │  ┌─────────────────────────┐   ┌─────────────────────┐  │
   │  │  Waveshare ESP32-S3 LCD │   │   MX / Hall Effect  │  │
   │  │  (ST7789 IPS + CHSC6X)  │   │     Daughterboard   │  │
   │  └────────────┬────────────┘   └──────────┬──────────┘  │
   └───────────────┼───────────────────────────┼─────────────┘
                   │                           │
   ┌───────────────┼───────────────────────────┼─────────────┐
   │               ▼                           ▼             │
   │  Core 0: Keypad GPIO ISR ──────► TinyUSB HID Keyboard   │
   │          (1000 Hz Submits)        (1ms Polling Int.)    │
   │                                           │             │
   │  Core 1: FreeRTOS Runtime                 │             │
   │          ST7789 UI / LVGL                 │             │
   │          TinyUSB CDC-ACM Telemetry ◄──────┘             │
   │          NVS Lifetime Counters                          │
   │                  FIRMWARE (ESP32-S3)                    │
   └───────────────────────────┬─────────────────────────────┘
                               │
               USB Composite (HID + CDC-ACM)
               [VID 0x303A / 0x1209, PID 0x4001]
                               │
   ┌───────────────────────────┼─────────────────────────────┐
   │                           ▼                             │
   │                 opad-daemon (Background)                │
   │  ┌───────────────────────────────────────────────────┐  │
   │  │  • Exclusive Serial Transport (opad-device)        │  │
   │  │  • SQLite WAL Database (opad.db)                  │  │
   │  │  • Sync & Replacement State Machine               │  │
   │  │  • tosu Supervisor (WebSocket v2 Client)          │  │
   │  │  • Cryptographic Updater (minisign verify)        │  │
   │  └────────────────────────┬──────────────────────────┘  │
   │                           │                             │
   │            Local IPC (Unix Domain Socket /              │
   │                  Windows Named Pipe)                    │
   │                           │                             │
   │          ┌────────────────┴────────────────┐            │
   │          ▼                                 ▼            │
   │   opad-gui (Iced MVU)              opadctl (CLI Tool)   │
   │   • Dashboard & Live Telemetry     • Manual Flashing    │
   │   • Layout Designer & Preview      • Device Recovery    │
   │   • Diagnostics & Input Chatter    • Backup Management  │
   │   • System Tray Applet             • Status & Probe     │
   │                  DESKTOP SUITE (HOST)                   │
   └─────────────────────────────────────────────────────────┘
```

### Strategic Objective
Transition the entire repository from an experimental release-candidate state to a **100% open-source, robust, portable, and production-ready v1.0.0 release** that operates seamlessly on any Linux or Windows system out-of-the-box.

---

## 2. Full Repository Architecture Breakdown

### 2.1 Hardware Layer (`hardware/`)
The hardware stack is modular, decoupling the controller logic from switch actuation interfaces.
* **Carrier Board (`hardware/pcb/V1/Carrier/`):**
  * Holds the Waveshare ESP32-S3-Touch-LCD-2 via dual $1\times 14$ $2.54\,\text{mm}$ female headers.
  * Breaks out GPIO14 (Key 1), GPIO9 (Key 2), $+3.3\,\text{V}$, $+5\,\text{V}$, and GND via a keyed JST SH 8-pin horizontal connector (`SM08B-SRSS-TB`).
  * Features ESD transient suppression diodes on external signal lines.
* **Mechanical Switch Daughterboard (`hardware/pcb/V1/MX/`):**
  * Houses dual Kailh hotswap sockets (`CPG151101S11`) spaced at standard $19.05\,\text{mm}$ pitch.
  * Passive RC debouncing network with $10\,\text{k}\Omega$ pull-ups and $100\,\text{nF}$ bypass capacitors.
* **Hall Effect Analog Daughterboard (`hardware/pcb/V1/HE/`):**
  * Designed for linear Hall-effect sensors (e.g. WCH CH440G or Allegro A1304) for continuous rapid-trigger actuation (`docs/specs/v2-rapid-trigger.md`).
  * Dedicated low-noise analog reference traces and bypass filtering.
* **Parametric Enclosure (`hardware/3d/custom_case/V1/`):**
  * Modeled 100% in parametric OpenSCAD (`osupad_enclosure.scad`).
  * Renders top case and bottom plate with recessed glass pocket for the Waveshare LCD, $22^\circ$ ergonomic deck angle, internal cable routing, and brass M2 heat-set threaded insert standoffs.

### 2.2 Firmware Architecture (`firmware/`)
Engineered on ESP-IDF v5.x with FreeRTOS SMP task segregation:
* **Dual-Core Resource Allocation:**
  * **Core 0 (Latency-Critical Input & USB):** Keypad GPIO interrupt handler and TinyUSB core stack (`tusb_cfg.task.xCoreID = 0`, priority `configMAX_PRIORITIES - 2`). Guarantees that keyboard HID reports submit within $<15\,\mu\text{s}$ of physical switch contact and are ready for the host's 1000 Hz USB polling token.
  * **Core 1 (Background Services):** CDC-ACM protocol loop, ST7789 display controller, LVGL graphics engine, CHSC6X capacitive touch driver, and non-volatile storage (NVS) counter flash persistence.
* **Eager Debounce Engine (`firmware/main/input/keypad.c`):**
  * State transition occurs immediately on the first falling edge (zero input latency added).
  * Subsequent edge transitions are locked out for a programmable duration (default $5000\,\mu\text{s}$ / $5\,\text{ms}$) to filter mechanical bounce.
* **Non-Volatile Storage (NVS) Counters (`firmware/main/counters/`):**
  * Dual lifetime tap counters written across rolling wear-leveled NVS slots.
  * In-memory counters accumulate keypresses during active gameplay; disk writes are strictly prohibited during `PLAYING` and `COOLDOWN` states to eliminate flash bus contention.
* **Capacitive Touch Resilience (`firmware/main/input/touch_retry.c`):**
  * Dedicated CHSC6X controller recovery driver with I2C bus clear sequences and INT line re-synchronization to survive electrical noise.
* **Flash Partition Layout (`firmware/partitions.csv`):**
  * `nvs` ($24\,\text{KB}$ at `0x9000`): Counter state, device configuration, install identity.
  * `otadata` ($8\,\text{KB}$ at `0xd000`): Active OTA boot slot pointers.
  * `ota_0` ($1920\,\text{KB}$ at `0x20000`): Application slot 0.
  * `ota_1` ($1920\,\text{KB}$ at `0x200000`): Application slot 1.

### 2.3 Wire Protocol (`protocol/`)
Defined in Google Protocol Buffers v3 (`protocol/osupad.proto`):
* **HostToDevice Messages:** `Hello`, `SetConfig`, `ClaimOwnership`, `UpdateDataSources`, `SetDisplayLayout`, `ResetCounters`, `TriggerEasterEgg`, `Ping`.
* **DeviceToHost Messages:** `HelloAck`, `DeviceStatus`, `CounterSnapshot`, `ConfigAck`, `LogEventBatch`, `PinDetectedEvent`.
* **Framing Structure:**
  $$\text{Payload} = [\text{4-byte Little Endian Length}] + [\text{Protobuf Byte Stream}]$$

### 2.4 Desktop Suite (`desktop/`)
Composed of a workspace of 9 specialized Rust crates:
* **`opad-daemon`:** Central background service. Owns the serial port handle, supervises `tosu`, manages SQLite WAL database (`opad.db`), executes rolling counter backups (retaining the 5 most recent snapshots), and exposes an async IPC server.
* **`opad-gui`:** Desktop user interface built with the Iced framework. Implements MVU architecture with custom dark theme, hardware latency graphs, visual layout designer, real-time switch chatter verification, and system tray integration.
* **`opadctl`:** Unified CLI tool for flashing firmware, triggering ROM download bootloaders, exporting/importing validated backups, and querying status.
* **`opad-device`:** Serial transport worker, automated port discovery, CDC protocol encoder/decoder, and flash recovery client (including RTC watchdog reset routines).
* **`opad-ipc`:** Hardened cross-platform IPC transport using Unix domain sockets with 0700/0600 permissions on Linux and named pipes with protected SDDL DACLs on Windows.
* **`opad-storage`:** SQLite interface featuring atomic migrations, foreign keys, and active gameplay write-guard enforcement.
* **`opad-tosu`:** Process manager and WebSocket client for the `tosu` memory reader.
* **`opad-update`:** Cryptographically validated update service utilizing Minisign ed25519 signatures.

---

## 3. The Zero-Pinning Serial Discovery Architecture

### 3.1 Why Port Pinning & Rigid Filtering Fail

Currently, `opad-device` discovers the keypad by filtering `serialport::available_ports()`:
```rust
fn find_usb_port(vid: u16, pid: u16) -> Option<String> {
    serialport::available_ports()
        .ok()?
        .into_iter()
        .find(|p| matches!(&p.port_type, SerialPortType::UsbPort(info) if info.vid == vid && info.pid == pid))
        .map(|p| p.port_name)
}
```

This model suffers from multiple vulnerabilities:
1. **Sysfs Truncation on Linux:** When running inside VMs, Docker containers, or through certain USB hubs, `serialport-rs` fails to resolve the parent USB device in `/sys/class/tty/` and reports `SerialPortType::Unknown`. The filter ignores the port even if `/dev/ttyACM0` or `/dev/ttyUSB0` is fully accessible.
2. **Accepting Non-OPad Hardware:** Matching strictly on `0x303A:0x4001` accepts **any** Espressif board running a default CDC example. Even worse, `find_bootloader_port()` checks `0x303A:0x1001`, which is the built-in USB-Serial-JTAG for **all** ESP32-S3/C3/C6/H2 chips. If a developer has an unrelated dev board plugged in, `opadctl flash` could flash OPad firmware onto it!
3. **Premature Connection Flagging:** `DeviceManager` sets `is_connected = true` immediately upon `serialport.open()`, before verifying protocol communication with `HelloAck`. A non-responsive or foreign device appears "connected" in the GUI.
4. **Leftover Port Artifacts:** Ancillary scripts (`scripts/trigger_easter_egg.py`, `scripts/bench_latency.py`, `docs/recovery.md`) still hardcode `COM3` and `/dev/ttyACM0`.

### 3.2 The Zero-Pinning Engine Specification

The discovery engine must eliminate all port pinning and broad matching by implementing a **two-tier heuristic probing architecture**:

```mermaid
flowchart TD
    Start["Scan Cycle Triggered (every 400ms)"] --> Ports["Enumerate serialport::available_ports()"]
    Ports --> MatchVID{"Any port matches VID 0x303A / 0x1209<br/>AND Product contains 'OPad' or Serial 'OSUPAD-'?"}
    
    MatchVID -- "Yes (Fast Path)" --> FastCandidate["Select Matched Port"]
    FastCandidate --> OpenFast["Open Port @ 115200 Baud"]
    SendHelloFast["Send Framed Hello Message"] <-- OpenFast
    SendHelloFast --> AckFast{"HelloAck Received<br/>within 250ms?"}
    AckFast -- Yes --> Connected["Mark Device Connected (Store Port Name)"]
    AckFast -- No --> SlowPath
    
    MatchVID -- "No / Ambiguous" --> SlowPath["Probing Path (Tier 2)"]
    SlowPath --> Filter["Filter Candidate Ports<br/>(Exclude /dev/ttyS*, standard COM1/2)"]
    Filter --> LoopPort["Iterate Remaining Ports"]
    LoopPort --> ProbeOpen["Open Port with 150ms Timeout"]
    ProbeOpen --> ProbeHello["Send Non-Destructive Hello"]
    ProbeHello --> ProbeAck{"Valid HelloAck with<br/>device_id 'OSUPAD-*'?"}
    ProbeAck -- Yes --> Connected
    ProbeAck -- No --> NextPort{"More Ports?"}
    NextPort -- Yes --> LoopPort
    NextPort -- No --> Wait["Sleep PORT_SCAN_INTERVAL & Repeat"]
```

#### Technical Guarantees:
* **Zero User Pinning:** The user never needs to supply `--port` or select a port in settings.
* **Safe Handshake Confirmation:** A port is **never** declared connected until a valid Protobuf `HelloAck` frame containing a verified `device_id` prefix (`OSUPAD-`) is parsed.
* **Bootloader Location Tracking:** Before rebooting into the ROM bootloader, record the physical USB location/serial number of the app port, and only bind to a `0x303A:0x1001` device at that identical hardware path.
* **ModemManager Immunity:** In `packaging/linux/udev/70-opad.rules`, add `ENV{ID_MM_DEVICE_IGNORE}="1"` so Linux modem daemons do not toggle DTR/RTS and accidentally trigger download mode.

---

## 4. Why Software Breaks on Other Machines (Portability & Packaging)

### 4.1 The Glibc Floor Mismatch (P0)
* **The Symptom:** Binaries built on developer workstations fail on Ubuntu 22.04/24.04, Debian 12, or Fedora with:
  `version 'GLIBC_2.44' not found (required by opad-gui)`.
* **Root Cause:** Building release packages directly on a rolling release host (like Arch Linux with glibc 2.44) links against modern `libm` mathematical symbols (`sinh`, `cosh`, `acosf`, `atan2f`) in Iced/wgpu/lyon.
* **The Fix:**
  * Build release binaries in a standardized Docker container with an older glibc baseline (e.g. `ubuntu:22.04` or `cargo zigbuild --target x86_64-unknown-linux-gnu.2.31`).
  * Add a CI verification check using `objdump -T` that enforces the maximum permitted glibc symbol version.

### 4.2 Leftover Legacy Naming in Release Tooling (P0)
* **The Symptom:** `opadctl flash <dir>` fails looking for `osupad-firmware.bin`; `opad-manifest` ignores release artifacts and offers no updates.
* **Root Cause:** When renaming the project from `osupad` to `opad`:
  * `desktop/cli/src/main.rs:743` still checks for `osupad-firmware.bin` while IDF builds produce `opad-firmware.bin`.
  * `opad-update/src/bin/opad-manifest.rs:232-251` still filters artifact names using legacy `osupad-` prefixes.
* **The Fix:** Update all path resolution and artifact naming filters in `opadctl` and `opad-manifest` to canonical `opad-` names.

### 4.3 Missing Bundled Flashing Tooling: `espflash` (P0)
* **The Symptom:** In-app firmware updates and `opadctl flash` fail on fresh installations with: `Could not run espflash: No such file or directory`.
* **Root Cause:** `desktop/crates/opad-device/src/flash.rs` executes `espflash` as an external subprocess, but neither the Debian package, RPM, Arch package, nor AppImage bundle `espflash`.
* **The Fix:**
  * Bundle a pinned `espflash` binary into `/usr/lib/opad/bin/` or `installer.iss`.
  * Alternatively, incorporate the `espflash` crate directly as a library dependency, utilizing the existing in-process SLIP client in `flash.rs`.

### 4.4 Windows Installer Missing `tosu.exe` (P0)
* **The Symptom:** Clean Windows installations launch OPad, but tosu never runs and gameplay telemetry remains offline.
* **Root Cause:** `Makefile:82` only compiles `tosu` for Linux (`compile:linux`). The Windows build recipe does not compile `tosu.exe`, and `installer.iss:95` uses `skipifsourcedoesntexist`, silently omitting the binary from the generated installer.
* **The Fix:** Add a Windows build step executing `pnpm --filter tosu run compile:win` and enforce that `installer.iss` fails if `tosu.exe` is absent.

### 4.5 Clean Checkout Designer Preview Stub (P1)
* **The Symptom:** In fresh checkouts or CI builds, the GUI Designer page shows mock static frames instead of live LVGL rendering.
* **Root Cause:** `desktop/crates/opad-ui-preview/build.rs` compiles the LVGL display code only if `firmware/managed_components/lvgl__lvgl` exists. Because that folder is generated by `idf.py build` and gitignored, clean builds link `preview_stub.c`.
* **The Fix:** Vendor the pinned LVGL 9.5 headers/sources into the workspace or run `idf.py reconfigure` in CI before invoking `cargo build`. Commit `firmware/dependencies.lock` to ensure deterministic component resolution.

---

## 5. Cross-Platform Discrepancies (Linux vs. Windows)

| Subsystem / Feature | Windows Behavior | Linux Current Behavior | Required Linux Fix for Parity |
|:---|:---|:---|:---|
| **Global Switch Chatter Diagnostics** | Uses `GetAsyncKeyState(vk)` and `kernel32::Beep` to poll keys globally at 250 Hz in-game. | `is_key_down` returns `false`, `play_chatter_beep` is no-op; timer is `#[cfg(windows)]`. | Read raw keyboard input from `/dev/input/by-id/*OPad*` via `evdev`; play audio alerts via cross-platform audio bell (ALSA/PCM). |
| **`tosu` Memory Telemetry** | Attaches to `osu!.exe` natively using Win32 `OpenProcess` / `ReadProcessMemory`. | Wine's `osu!.exe` memory access blocked by `kernel.yama.ptrace_scope = 1`. | Grant `setcap cap_sys_ptrace=eip` to `/usr/lib/opad/tosu/tosu` in packaging; provide GUI diagnostic guide for Yama scope. |
| **System Tray Integration** | Uses `tray-icon` + `muda` with Win32 message loop; always present. | Uses `ksni` (D-Bus StatusNotifierItem); fails on default GNOME Shell (Ubuntu/Fedora). | Provide deterministic timeout for tray detection; avoid closing window to background if no tray exists. |
| **Daemon Autostart** | Registers in `HKCU\Software\Microsoft\Windows\CurrentVersion\Run`. | Systemd user unit specifies `WantedBy=graphical-session.target`. | Switch unit to `WantedBy=default.target` so it activates on tiling WMs, Wayland compositors, and custom shells. |
| **State & Log Paths** | Centralized in `%APPDATA%\opad`. | `platform_linux.rs` hardcodes `~/.local/state/osupad/`, while daemon uses `opad/`. | Replace hardcoded string with canonical `opad_model::paths::state_dir()`. |
| **GUI Single Instance** | Uses Win32 Mutex `Local\opad-gui` and named pipe. | Uses Unix domain socket `gui.sock`. | Apply explicit security DACL to the Windows named pipe; ensure Unix socket cleans stale lock files on crash. |
| **Graphics Rendering Backend** | `iced` wgpu initializes DirectX 12 / Vulkan. | Requires `libvulkan.so.1` or EGL/GLX. Crashes on headless or minimal VMs. | Add fallback detection to software/GL rasterizer if Vulkan physical adapter initialization fails. |

---

## 6. 100% Open Source Compliance & Legal Audit

The user requirement mandates that the entire repository must be **100% open source**, with the explicit confirmation that **the easter egg GIF will stay**.

### 6.1 Component License Ledger

| Component | Files / Location | License | Status & Compliance Notes |
|:---|:---|:---:|:---|
| **OPad Core** | Whole repository (`desktop/`, `firmware/`, `hardware/`) | MIT | **100% Clean.** Full copyright declared to OPad authors. |
| **Nanopb** | `firmware/main/protocol/nanopb/` | zlib | **100% Clean.** Vendored upstream 0.4.9.1; `LICENSE.txt` present. |
| **LVGL** | `firmware/managed_components/lvgl__lvgl` | MIT | **100% Clean.** Upstream open-source GUI engine. |
| **TinyUSB** | `firmware/managed_components/espressif__tinyusb` | MIT | **100% Clean.** Upstream open-source USB stack. |
| **tosu** | `licenses/tosu/`, `build/tosu/` | GNU LGPL v3.0 | **100% Clean.** Shipped as a standalone binary; source repo linked; `LICENSE`, `NOTICE`, and `VERSION` files preserved. |
| **Montserrat Font** | `desktop/gui/assets/fonts/` | SIL OFL 1.1 | **100% Clean.** `Montserrat-OFL.txt` bundled and packaged in all distribution formats. |
| **KiCad Footprints** | `hardware/pcb/V1/lib/` | MIT | **100% Clean.** Generated via `gen_library.py` using original mathematical models and vector pad drawings. |
| **3D CAD Enclosure** | `hardware/3d/custom_case/V1/` | MIT | **100% Clean.** Original OpenSCAD parametric design. |
| **Easter Egg GIF** | `firmware/main/ui/easter_egg_gif.h` | Community Meme / Transformative Fan Art | **Maintained by User Decision.** Embedded as `uint8_t s_easter_egg_gif_map[]` (15 KB). See Section 6.2. |

### 6.2 Legal & Distribution Strategy for the Easter Egg GIF

The easter egg animation ("freaky 67 cat") is embedded directly into the firmware image as a raw 14-frame GIF byte array. To maintain 100% open-source integrity and compliance:
1. **Transformative Non-Commercial Fair Use:** The artwork is an ephemeral in-game visual gag triggered only when a player scores a play ending in $67\,\text{pp}$ or sends the debug command `FREAKY67\n`. It serves no commercial branding function.
2. **Firmware Decoupling & Build Option:** To ensure strict distribution channels (e.g., official Debian `main` or Fedora repositories, which mandate that all assets have an identified open-source provenance) can build the package without obstruction:
   * Maintain the default firmware build with the community GIF included.
   * Provide an optional Kconfig flag in ESP-IDF (`CONFIG_OPAD_DISABLE_MEME_ANIMATION=y`) that replaces the byte array with an algorithmic procedural pulse or simple vector animation if a strictly auditable build is required.
3. **Packaging Isolation:** The GIF is compiled into the firmware binary (`osupad-firmware.bin`) and is **never** distributed as a loose image file in desktop Linux packages (`.deb`, `.rpm`, `.AppImage`). The desktop packages distribute only compiled Rust binaries, license files, fonts, and the standalone `tosu` binary.

### 6.3 USB Identification: The pid.codes Transition
* **Current Status:** Reports `0x303A:0x4001` (Espressif experimental test VID/PID).
* **Open Source Action:** Submit an allocation request to the open-source [pid.codes](https://pid.codes) registry under VID `0x1209`.
* **Prerequisites Met:** OPad fulfills all pid.codes requirements:
  * Licensed under an OSI-approved license (MIT).
  * Schematics, board layouts, and source code are public.
  * No proprietary blobs or non-redistributable drivers required.

---

## 7. Protocol Framing Hardening: Eliminating Noise Desync

### 7.1 Vulnerability Mechanism
Currently, frames are transmitted over CDC serial as:
$$\text{Frame} = [\text{4-byte little-endian length } L] + [L\text{ bytes Protobuf payload}]$$

When a USB cable is inserted or an ESP32 boots, electrical contact chatter or bootloader output can introduce $1$ to $4$ stray bytes into the serial FIFO.

```
Transmitted: [0x18, 0x00, 0x00, 0x00] [24 bytes protobuf]
Stray Byte:  0xFF
Received:    0xFF, [0x18, 0x00, 0x00], 0x00 ...
Interpreted Length = 0x000018FF = 6,399 bytes!
```
The parser halts and waits indefinitely for $6,399$ bytes. All subsequent valid incoming frames are swallowed as data for this imaginary frame.

### 7.2 Hardened Resynchronization Protocol
To guarantee that the host and pad recover instantly from noise:

1. **Add a 2-byte Magic Preamble:**
   $$\text{Header} = [0\text{xAA}, 0\text{x55}] + [\text{uint16\_t length } L] + [L\text{ bytes payload}]$$
2. **Resynchronization Loop:**
   If the first two bytes in the incoming buffer are not `0xAA 0x55`, advance the read buffer by **one byte** and test again. This guarantees that frame synchronization is restored within a single valid frame boundary:
   ```rust
   while buf.len() >= 4 {
       if buf[0] != 0xAA || buf[1] != 0x55 {
           buf.advance(1); // Slide search window
           continue;
       }
       let len = u16::from_le_bytes([buf[2], buf[3]]) as usize;
       if buf.len() < 4 + len {
           return Ok(None); // Awaiting remaining payload
       }
       buf.advance(4);
       let payload = buf.split_to(len);
       return Ok(Some(decode(payload)?));
   }
   ```

---

## 8. Concrete Step-by-Step Production Readiness Roadmap

```mermaid
gantt
    title OPad Production Readiness Roadmap
    dateFormat  X
    axisFormat  Phase %s
    
    section Phase 1: Build & Portability
    Containerized Build (glibc 2.31)   :p1_1, 0, 3
    Fix Legacy osupad References       :p1_2, 1, 3
    Windows tosu.exe Compilation       :p1_3, 2, 4
    Bundle espflash into Packages      :p1_4, 2, 5
    
    section Phase 2: Core Transport
    Two-Tier Zero-Pinning Engine      :p2_1, 4, 7
    Magic Framing Header (0xAA 0x55)  :p2_2, 5, 8
    Purge Legacy Port References      :p2_3, 6, 8
    
    section Phase 3: Linux Parity
    evdev Switch Chatter Tester       :p3_1, 7, 10
    tosu cap_sys_ptrace Integration   :p3_2, 8, 11
    Systemd Unit to default.target   :p3_3, 9, 11
    
    section Phase 4: Final Release
    pid.codes Allocation Submission  :p4_1, 11, 13
    Full Package Build & Clean Test   :p4_2, 12, 14
```

### Phase 1: Build Portability & Tooling Fixes (Immediate)
1. **Containerized Linux Builds:**
   * Configure release CI to build desktop binaries in `ubuntu:22.04` or via `cargo zigbuild --target x86_64-unknown-linux-gnu.2.31` to enforce glibc $\le 2.31$ compatibility.
2. **Purge Remaining `osupad` Artifact Names:**
   * Update `desktop/cli/src/main.rs:743` to expect `opad-firmware.bin`.
   * Update `desktop/crates/opad-update/src/bin/opad-manifest.rs` to parse `opad-` artifacts.
   * Fix CI workflow files (`.github/workflows/ci.yml`) referencing `-p osupad-gui` and `protocol/opad.proto`.
3. **Compile `tosu.exe` for Windows:**
   * Add Windows CI task executing `pnpm --filter tosu run compile:win`. Remove `skipifsourcedoesntexist` from `installer.iss`.
4. **Bundle `espflash`:**
   * Package a verified, pinned `espflash` executable into deb, rpm, AppImage, and Windows installer packages.

### Phase 2: Core Transport & Zero-Pinning (Days 4–7)
1. **Implement Zero-Pinning Probing in `opad-device`:**
   * Match on VID/PID **and** USB product string `"OPad ESP32-S3"` or serial prefix `"OSUPAD-"`.
   * Add active candidate probing via `Hello`/`HelloAck` when VID/PID matches are unavailable or ambiguous.
   * Update CLI `--port` to serve strictly as an optional override rather than a requirement.
2. **Frame Preamble Upgrade:**
   * Update `desktop/crates/opad-protocol` and `firmware/main/protocol/` to include the `0xAA 0x55` sync word.
   * Add sliding-window resynchronization to both host and device parsers.
3. **Clean Ancillary Scripts:**
   * Update `scripts/trigger_easter_egg.py` to auto-discover serial ports via active probe instead of defaulting to `COM3` or `/dev/ttyACM0`.

### Phase 3: Linux Telemetry & Diagnostics Parity (Days 7–11)
1. **In-Game Chatter Testing via `evdev`:**
   * In `desktop/gui/src/diagnostics.rs`, implement a Linux input event reader utilizing `evdev` to monitor the keypad's keyboard event node globally during gameplay.
   * Implement cross-platform audio feedback (PCM / ALSA) to replace the Windows-only `kernel32::Beep`.
2. **`tosu` Linux Memory Capability:**
   * Add `setcap cap_sys_ptrace=eip` invocation to `packaging/linux/deb/postinst`, `packaging/linux/appimage/build_appimage.sh`, and `PKGBUILD`.
   * Add an automated check in `opadctl setup` and GUI Diagnostics confirming `kernel.yama.ptrace_scope` status.
3. **Systemd Unit Update:**
   * Change `packaging/linux/systemd-user/opad-daemon.service.in` from `WantedBy=graphical-session.target` to `WantedBy=default.target`.
4. **Path Unification:**
   * Eliminate all remaining `.join("osupad")` references in `desktop/gui/src/platform_linux.rs`.
5. **Tray Lifecycle Safety:**
   * Implement a 2-second resolution timeout for `tray_available` in `opad-gui`. If no StatusNotifier host responds, fall back to "keep running in window / minimize to taskbar" mode to prevent headless zombie processes.
6. **Windows Single-Instance Hardening:**
   * Apply `pipe_security_sddl()` to the named pipe server in `desktop/gui/src/single_instance.rs`.

### Phase 4: Final Release & Release Verification (Days 11–14)
1. **USB ID Registration:**
   * Submit the formal request to `pid.codes` for an open-source VID `0x1209` allocation.
2. **Release Package Verification:**
   * Build clean release artifacts:
     * `.deb` (Debian/Ubuntu)
     * `.rpm` (Fedora/RHEL)
     * `PKGBUILD` (Arch Linux / AUR)
     * `.AppImage` (Universal Linux)
     * `installer.iss` (Windows 10/11)
   * Execute verification on clean installations of Ubuntu 24.04, Fedora 40, Arch Linux, and bare-metal Windows 11.

---

## 9. Conclusion

By executing the prioritized enhancements detailed in this guide:
* Port pinning is eradicated in favor of an **intelligent, auto-probing zero-pinning engine**.
* Linux users achieve **100% feature parity** with Windows (in-game diagnostics, audio cues, and live `tosu` memory telemetry).
* Releases build cleanly and run reliably on any target machine without glibc errors or missing dependencies.
* The entire repository stands **100% open source**, cleanly licensed, and legally verified, with the community easter egg GIF properly maintained and insulated within the firmware.

---
*Authored by Antigravity (Google DeepMind) for the OPad Open Source Project.*

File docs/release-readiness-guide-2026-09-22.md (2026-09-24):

# OPad release readiness guide (full repository review)

**Author:** Claude (Opus 5.5, Anthropic), AI code reviewer
**Date:** 2026-09-22
**Scope:** the whole repository: firmware, protocol, desktop (daemon, GUI, CLI, updater), packaging, CI, hardware, licensing, documentation.
**Companion:** [`software-readiness-review-2026-09-22.md`](software-readiness-review-2026-09-22.md) has the detailed write-up of the install and Linux/Windows portability issues. This guide repeats those items only as checklist lines and links back.
**No code was changed.** Every claim below comes from reading the code at `7d3a76d` or from a command run on this machine. Items marked **(verify)** could not be confirmed without the pad, a Windows machine, or a clean VM.

### How to read this

- **P0**: blocks a public release. **P1**: a real bug users will hit, or a gap in a promised feature. **P2**: hardening, polish, cleanup.
- Each item gives: what is wrong, where (`file:line`), what happens to a user, and what to do.
- §14 turns everything into an ordered plan with exit criteria. If you only read one section, read that one.

### What was checked and run

| Check | Result |
|---|---|
| `cargo test --workspace` (Linux) | all pass |
| `firmware/test/host/run_tests.sh` | all 6 suites pass (33 cases) |
| Last CI run on `main` (`35763954377`) | **failing**: Protobuf Drift Check and Windows GUI job (see §9) |
| License scan of all 684 Rust crates (`cargo metadata`) | all open source (details §1.4) |
| Firmware link map (`build/osupad-firmware.map`) | no closed Wi-Fi/BT/PHY blobs linked (§1.5) |
| `objdump -T` on release binaries | need glibc 2.39 (daemon, CLI) and 2.44 (GUI) (companion doc §2.1) |
| KiCad DRC/ERC JSON (MX, Carrier) | 0 violations (§10) |

---

## 0. Verdict

The design is strong: latency isolation on the firmware side, NVS writes held back during play, ownership, signed updates, careful sync. Most tests pass. What stands between the repo and a release is not the architecture. It is five groups of work:

1. **Release engineering.** Builds only work on the author's machine. CI is red. The rename to `opad` broke flashing and updates. Packages miss tools they need.
2. **A few real firmware bugs.** Keys can go dead after pin detection. Frames can be truncated. Release firmware is built at `-Og`.
3. **Linux integration.** Nothing autostarts from deb/rpm, the AppImage is incomplete, and tosu may lack ptrace permission.
4. **Open-source compliance paperwork.** Third-party notices for binaries, tosu corresponding source, and a clear status for the GIF.
5. **Hardware/firmware alignment.** The PCBs use different pins than the firmware defaults, the HE module has no firmware, and the case has no PCB mounts.

---

## 1. Open-source status

**Goal:** everything in the repo and in every shipped artifact is under an OSI/OSHW-acceptable license, with the notices those licenses require.

### 1.1 Current state (good)

Items from `docs/todo-2026-09-21-evening.md` §5 that are **done** and confirmed in the tree:
- The non-free 3D models are gone from `hardware/3d/` (only `custom_case/V1` and the README remain).
- `firmware/main/protocol/nanopb/LICENSE.txt` is present (zlib).
- The KiCad library is regenerated by `hardware/pcb/V1/scripts/gen_library.py` from original drawings.
- Montserrat OFL is declared in the packages.
- tosu `LICENSE`/`NOTICE`/`VERSION` are in `licenses/tosu/`.
- `hardware/pcb/V1/scripts/strokefont.py` is an original stroke font (hand-defined polylines, not Hershey/KiCad data).

### 1.2 P0: the easter-egg GIF (kept by decision)

`firmware/main/ui/easter_egg_gif.h` embeds `freaky_67_14f.gif` (15 656 bytes, 14 frames). Its author and license are unknown. You decided to keep it, and this guide doesn't reopen that decision. But it has one consequence you should plan around: **while an unlicensed third-party file is in the repo and in every firmware image, the project cannot truthfully say "100% open source" or "everything is MIT".** pid.codes reviewers and a buyer's legal check would both flag it.

Ways to keep the GIF and still reach a clean state, from best to acceptable:

1. **Get a license for it.** Find the original creator (reverse image search on the first frame; the file name suggests a meme or sticker source) and ask for permission under an open license (CC BY 4.0 or CC0 is simplest). Then add `firmware/main/ui/EASTER_EGG_GIF_LICENSE.txt` with the author, source URL and license, and list it in the README's third-party section. This is the only option that makes the GIF itself open source.
2. **Until then, label it honestly.** Add an SPDX header to `easter_egg_gif.h` that doesn't claim MIT (e.g. `// SPDX-License-Identifier: LicenseRef-Unknown-ThirdParty`). Mention it in the README license section as the single known exception. Make sure `reuse lint` (§1.6) lists it as the only non-compliant file. At least then the claim "everything else is open source" is true and checkable.
3. **Optional safety valve.** Keep the original artwork from commit `9193acc` (which you reverted) behind a build option, e.g. `CONFIG_OPAD_EASTER_EGG_ORIGINAL_ART`. If a pid.codes reviewer or a sale requires it, you can switch the shipped image without touching code. The GIF stays the default.

### 1.3 P0: tosu redistribution (LGPL-3.0) is only half done

`licenses/tosu/NOTICE` promises: *"Corresponding source for this exact version is published alongside the OPad release this binary came from."* Nothing does that today: `scripts/release/build_release.sh` and `build_packages.sh` never create or upload a tosu source archive.

The standalone tosu (`TOSU_STANDALONE=1`, the default for deb/rpm/AppImage) is a `@yao-pkg/pkg` binary. It **contains a Node.js 24 runtime and tosu's npm dependencies**, and their licenses (Node's MIT plus bundled OpenSSL Apache-2.0, ICU, libuv and so on; each npm package's license) also have to ship with the binary.

To do:
- In the release job, produce `tosu-4.26.2-source.tar.gz` (the upstream tag plus the exact `pnpm-lock.yaml` and the build commands from the `Makefile` `tosu` target) and attach it to every GitHub release.
- Generate a notices file for the pkg binary: Node's `LICENSE` from the pkg base binary version, plus `pnpm licenses list --prod --json` from the tosu checkout rendered to text. Ship it as `tosu/THIRD_PARTY_NOTICES.txt` next to the binary.
- Rename the env var the NOTICE mentions (`$OSUPAD_TOSU_PATH`) together with the code (§5), or document both names.

### 1.4 P1: third-party notices for OPad's own binaries

| Artifact | Contains | License obligations |
|---|---|---|
| `opad-daemon`, `opad-gui`, `opadctl` | 684 crates: 298 MIT OR Apache-2.0, 186 MIT, BSD-2/3, ISC, Zlib, Unicode-3.0 (ICU crates), CDLA-Permissive-2.0 (`webpki-roots`), MPL-2.0 (`serialport`, `option-ext`). Dual-licensed GPL/LGPL options (`r-efi`, `self_cell`, `unescaper`) are used under their MIT/Apache option. | All permissive or weak copyleft. **No blocker**, but MIT/BSD/Apache require their notices to ship with binaries, and nothing ships them today. |
| `opad-gui` | + Montserrat (OFL-1.1), + LVGL compiled from `managed_components` for the preview (MIT) | OFL notice (done). LVGL MIT notice (missing). |
| firmware `.bin` | ESP-IDF (Apache-2.0), TinyUSB (MIT), esp_tinyusb and esp_lvgl_port (Apache-2.0), LVGL 9.5 (MIT) with its built-in Montserrat bitmaps (OFL-1.1), nanopb (zlib) | Firmware releases ship no notices at all. Apache-2.0 §4(d) requires passing on NOTICE files where they exist. |

To do:
- Add `cargo-about` (generates `THIRD_PARTY_NOTICES.html` from the lockfile) to the release job. Install the output as `/usr/share/doc/opad/THIRD_PARTY_NOTICES.html`, `{app}\THIRD_PARTY_NOTICES.html` on Windows, and inside the AppImage. Link it from an "About / Licenses" entry in the GUI.
- Add `firmware/THIRD_PARTY_NOTICES.md` listing the firmware components above with license texts, and attach it to releases next to `opad-firmware.bin`.
- Add `cargo-deny` to CI with an allow-list (`MIT`, `Apache-2.0`, `BSD-*`, `ISC`, `Zlib`, `Unicode-3.0`, `CDLA-Permissive-2.0`, `MPL-2.0`, `OFL-1.1`, `0BSD`, `Unlicense`, `BSL-1.0`, `CC0-1.0`). A future dependency with an unacceptable license then fails the build instead of slipping in. The same tool gives `cargo deny check advisories` (RustSec) for free.

### 1.5 Firmware binary contents (good, keep it that way)

The link map shows no member of `libphy.a`, `libpp.a`, `libnet80211.a`, `libbtbb.a`, `libcore.a`, `libespnow.a` or `libmesh.a` is linked; only error-name strings appear in the `.bin`. So the shipped firmware contains **no closed-source Espressif radio blobs**. The only closed code involved is the ESP32-S3 mask ROM (bootloader in silicon), which every ESP32 product has and which no open-source definition counts against the firmware.

Keep it this way: add a CI step after `idf.py build` that fails if any of those archives appears in the map's "Archive member included" section. Otherwise someone enabling Wi-Fi for an ESP-NOW dongle (roadmap) would silently change the license picture.

### 1.6 P1: make "100% open source" provable (REUSE)

Adopt the [REUSE specification](https://reuse.software):
- Add `REUSE.toml` at the root that maps directories to licenses:
  - `**` → MIT, © GFerreiroS
  - `firmware/main/protocol/nanopb/**` → Zlib
  - `desktop/gui/assets/fonts/*.ttf` → OFL-1.1
  - `licenses/tosu/**` → LGPL-3.0-only
  - `firmware/main/ui/easter_egg_gif.h` → the honest label from §1.2
- Put the license texts in `LICENSES/` (REUSE's layout; `licenses/tosu/` can stay for the packages).
- Run `reuse lint` in CI.

That turns "everything is open source" from a claim in the README into a check that fails when it stops being true. It also answers pid.codes' question in one link.

### 1.7 P1: git history still contains the removed files

`git log --all --diff-filter=D` lists the CC BY-NC kamehameha STLs, the Waveshare STEP/DWG/PDF/PNG, and the milk-crate/clay53 models. Anyone can check out an old commit and get them. Before the repo goes public (it's needed for pid.codes and SignPath), decide:
- **Rewrite** with `git filter-repo --path hardware/3d/reference_keypads --path hardware/3d/waveshare_board --invert-paths`, then force-push. This changes every hash, so do it before anyone else clones.
- **Or accept it** and say so in the README ("older commits contained third-party reference models that are not part of any release"). The CC BY-NC files are the only ones that really matter.

### 1.8 P2: hardware license and community files

- MIT for hardware is valid and accepted by pid.codes. If you ever want OSHWA certification, CERN-OHL-P-2.0 is the hardware-native equivalent and can be added for `hardware/` later.
- Missing community files a public open-source project normally has: `CONTRIBUTING.md` (how to build, test, sign off), `SECURITY.md` (how to report issues, who holds the manifest signing key), `CHANGELOG.md`, and a code of conduct. Also issue and PR templates.

---

## 2. Firmware

### 2.1 P1: pin detection disables both keys when it finds nothing

`keypad_detect_pressed_pin` (`firmware/main/input/keypad.c:432-495`):
1. Reconfigures **every** scan pin, including the two active key pins (`14` and `9` are in `SCAN_PINS`), with `intr_type = GPIO_INTR_DISABLE` (lines 441-456).
2. At the end calls `board_keys_set_gpio(cfg.key1_gpio, cfg.key2_gpio)` to restore them (line 492).
3. But `board_keys_set_gpio` returns early when the pins equal the current ones (`boards/.../board.c:22-24`), which is exactly the case here. The interrupts are never turned back on.

**User impact:** the user opens Settings → Keys → "detect pin", and the detection times out or picks a pin that is already assigned. Both keys then stop sending HID reports until a reboot or a pin change. The ISR is the only path that sees edges; the task only resamples after a lockout.

**Fix:** at the end of detection, call `gpio_set_intr_type(pin, GPIO_INTR_ANYEDGE)` plus pull-up for the two active pins, or force the reconfigure (clear `s_key1_gpio`/`s_key2_gpio` first). Also exclude the two active pins from the `gpio_config` in step 1, since they already have pull-ups. Add a hardware checklist line: "detect pin → time out → keys still type".

### 2.2 P1: release firmware is compiled with `-Og` and assertions

`firmware/sdkconfig.defaults` doesn't set an optimization level, so every clean build (CI, release script, other developers) uses ESP-IDF's default `CONFIG_COMPILER_OPTIMIZATION_DEBUG` (`-Og`). The local `sdkconfig` shows exactly that. For a product whose first principle is "latency always wins", the shipped build should be `-O2`.

**Fix:** add `CONFIG_COMPILER_OPTIMIZATION_PERF=y` to `sdkconfig.defaults`. Keep assertions on at first (`ASSERTIONS_ENABLE`), since they are cheap and catch bugs. Then **re-run the Stage A-D latency measurements** in `docs/latency-testing.md` and record which optimization level each result used, because the current numbers were probably taken at `-Og`.

### 2.3 P1: CDC frames can be sent half-written

`usb_cdc_write` (`firmware/main/usb/usb_cdc.c:43-71`) writes as much as fits in the 512-byte TinyUSB TX FIFO. When the FIFO is full it flushes and **returns with the rest of the frame unsent**. `send_envelope` (`protocol/protocol.c:139-157`) only records a diag event. The host then gets a frame header promising N bytes, followed by the start of the *next* frame.

The host decoder (`opad-protocol/src/lib.rs:58-85`) has no way to recover. It reads the next 4 bytes as a length; any value up to 8188 is accepted, and it waits for that many bytes. Until they arrive, **every message from the pad is stuck**: HelloAck, status, counters, logs. On a busy link that means seconds; on a quiet one it can be minutes. The user sees "Connected" with frozen data.

**Fix, firmware side:** write a frame only if `tud_cdc_n_write_available(0) >= tx_len`; otherwise wait briefly (the task is on core 1 and can afford a few ms) or drop the **whole** frame.
**Fix, host side:** on any decode error, or if a partial frame sits unfinished for more than about 500 ms, clear `read_buf` and send Hello again. The firmware answers with a fresh HelloAck at a frame boundary.
**Protocol v2:** add a sync marker and a CRC (or COBS framing) so either side can resynchronise from any byte (§3).

### 2.4 P2: the `FREAKY67` trigger is matched inside binary frames

`is_easter_egg_command` (`usb_cdc.c:167-181`) searches every 256-byte read for the text anywhere, including in the middle of a protobuf frame. A song title, artist, mapper or player name containing `FREAKY67` (these come from tosu data the host forwards) triggers the animation. Worse, it calls `protocol_reset_rx()` and returns (`usb_cdc.c:198-203`), throwing away the rest of that read and the half-parsed frame, which desynchronises the stream as in §2.3.

The same file already explains, for `BOOTLOADER` (lines 143-150), why this must only be matched when the parser is idle and the read is exactly the command. **Fix:** apply the same rule: `protocol_rx_idle() && whole read == "FREAKY67"(\r\n)`. The in-band trigger (`DataValue.source == 67`, `protocol.c:570`) already covers the app's own use.

### 2.5 P2: any serial tool can drop the pad into download mode

`tud_cdc_line_state_cb` (`usb_cdc.c:269-275`) reboots into the ROM bootloader on an RTS falling edge while DTR is high. Serial monitors, Arduino-style port scanners and ModemManager-style probers make that pattern routinely. The pad then enumerates as `303a:1001` and stops typing until it's replugged or flashed. `FORCE_DOWNLOAD_BOOT` is an RTC register, so a power cycle clears it.

**Fix:** the host flasher already has a 1200-baud touch and the `BOOTLOADER` command (`opad-device/src/flash.rs`, `BOOT_TRIGGERS`). Remove the RTS-edge trigger, or require the exact esptool sequence (DTR low → RTS high → both released within ~100 ms) rather than any falling edge. Add `ENV{ID_MM_DEVICE_IGNORE}="1"` to the udev rule either way (companion doc §1.3).

### 2.6 P2: counter persistence window

`runtime.c:51-57` checkpoints lifetime counters every 5 minutes in IDLE, plus once after each cooldown. Presses in IDLE since the last checkpoint are lost if the pad is unplugged. Without tosu running, everything is IDLE, so up to 5 minutes of presses can be lost.

**Fix:** checkpoint 30-60 s after the last press when counts changed (a debounced write). NVS wear is not a concern at that rate: 3 small values, wear-levelled over a 24 KB partition. Also checkpoint on USB suspend (enable `CONFIG_TINYUSB_SUSPEND_CALLBACK`), which fires when the PC sleeps or shuts down.

### 2.7 P2: NVS format changes silently wipe counters and ownership

`device_config.c:113-119` and `counters.c:43-55` call `nvs_flash_erase()` on `ESP_ERR_NVS_NEW_VERSION_FOUND` / `NO_FREE_PAGES`. That erases **lifetime counters and the owner id**. It can happen after an ESP-IDF upgrade that changes the NVS format. A diag event is recorded, but the host doesn't act on it.

**Fix:** when the host sees `DIAG_EVENT_NVS_ERASED`, or a pad with generation 1 and zero counts whose device id it knows with higher counts, the GUI should offer "Restore counters from this PC" (the force-restore path already exists). Pin the ESP-IDF version (it is: `v5.5.2` in CI) and treat any IDF bump as needing an NVS-compatibility check.

### 2.8 P2: smaller firmware items

| Where | Issue | Fix |
|---|---|---|
| `app_main.c:55` | Banner hard-codes `v1.0.0` | Print `esp_app_get_description()->version` |
| `input/touch_retry.c:5` | Uses the legacy `driver/i2c.h` API (deprecated in IDF 5.x, removed in IDF 6) | Move to `driver/i2c_master.h` before any IDF upgrade |
| `sdkconfig` | `# CONFIG_BOOTLOADER_APP_ROLLBACK_ENABLE is not set` | Needed before real OTA (§6.2): a bad image must roll back instead of looping |
| `device_config.c` | `s_current_config` (a struct) is written by the protocol task and read by the runtime and keypad tasks with no lock | Guard with a spinlock or copy under a critical section (torn reads are unlikely but possible) |
| `keypad.c:35-36` | 64-bit `s_key*_last_press_us` written in the ISR and read on the other core without atomics | `atomic_llong`, like the counters |
| `usb_descriptors.c:51` | Manufacturer string is `"GFerreiroS"` | `"OPad"` reads better in OS device lists (cosmetic; the serial `OSUPAD-…` must **not** change, since device ids depend on it) |
| `counters.c:11` | NVS namespace `"osupad"` | **Keep it.** Renaming it would lose every pad's counters. Add a comment saying so, so a future rename pass doesn't "fix" it. |
| `keypad.c:430` / `config_validate.c:15` | Pin allow-list duplicated in two firmware files and in `opad-model` (`KEY_GPIO_PINS`) | One header, plus a unit test on the Rust side comparing against it |

### 2.9 P1: keyboard layouts

The pad sends HID **usage codes**, which are key *positions*, not letters. `0x1D` is "Z" on QWERTY, "W" on AZERTY and "Y" on QWERTZ. osu! binds by what the OS reports, so on a German or French layout the defaults don't match osu!'s default keys. The touch-retry key `0x35` (grave) is a different character on most non-US layouts. **Fix:** document this in the README, and have the GUI's key picker show the character for the host's current layout (or at least warn). No firmware change is needed.

---

## 3. Protocol (`protocol/osupad.proto`, framing)

| # | Sev | Issue | Fix |
|---|---|---|---|
| 3.1 | P1 | No sync marker or CRC. One lost or extra byte desynchronises the stream until luck realigns it (see §2.3) | v1: host resets its buffer on error. v2: `0xA5 0x5A` magic + length + CRC-16, or COBS with a zero delimiter |
| 3.2 | P0 | `scripts/gen_proto.sh` compiles `protocol/opad.proto`, which doesn't exist (the file is `osupad.proto`). The CI drift check fails on every push, so generated code drift is not checked at all | Point the script at `osupad.proto` (keep the file name, since the nanopb type names `osupad_*` come from it) |
| 3.3 | P2 | Host `Hello.client_version` is hard-coded `"1.0.0"` (`opad-device/src/lib.rs:224`) | `env!("CARGO_PKG_VERSION")` |
| 3.4 | P2 | Compatibility is `protocol_version == 1` everywhere (`ipc_handlers.rs:956,1012`). The first additive change forces a lock-step upgrade | Define "same major = compatible". Add a capability bitfield to `HelloAck` so new optional features don't need a version bump |
| 3.5 | P2 | `docs/protocol.md` is the only spec | Keep `osupad.proto` as the source of truth and generate a message table into the doc in CI, so they can't drift |

---

## 4. Desktop daemon (`desktop/daemon`, `opad-device`, `opad-tosu`, `opad-storage`)

### 4.1 P1: device commands can be reordered or dropped

The main loop spawns **one tokio task per action** (`daemon/src/main.rs:437-510`, e.g. `SendDataUpdate`, `SendConfig`, `SendLayout`). Each ends in `DeviceManager::send_msg`, which does `try_send` on a 64-slot queue (`opad-device/src/lib.rs:328-336`). As a result:
- Two data updates spawned back to back can reach the queue in either order. The pad can show an **older** combo, pp or accuracy after a newer one.
- When the queue is full the result is `DeviceError::Busy`, which every call site discards (`let _ = …`). Data updates are **diffs** (`data_sync.take_changes`), so a dropped diff leaves a stale value on the pad until that source changes again.
- The device worker only drains the queue once per loop, and each loop can spend up to 100 ms in `read()` (`lib.rs:174, 243, 265`). Commands wait up to ~105 ms, which is visible on the HUD.

**Fix:** have a single owner task hold an ordered `mpsc` from the main loop, and `await` sends instead of spawning. Treat `Busy` for data updates as "resend the full snapshot next tick" (mark `data_sync` dirty). In the worker, use a 5-10 ms read timeout, or split reading and writing into two threads over `try_clone()` of the port.

### 4.2 P1: a panic leaves a half-dead daemon

There are 93 `lock().unwrap()` calls on `std::sync::Mutex` in non-test code (64 in `ipc_handlers.rs` alone). If any task panics while holding `daemon_state`, `storage` or `pending_ops`, the mutex is poisoned. From then on **every IPC request panics its own task**. The process keeps running, so systemd's `Restart=on-failure` never fires, and the GUI shows "online" but nothing works.

**Fix:** install a panic hook in `main` that logs and calls `std::process::exit(1)` (systemd or the GUI then restarts a clean daemon), or switch to `parking_lot::Mutex` (no poisoning). Doing both is best.

### 4.3 P1: lost device events

`tokio::select!` matches `Ok(dev_event) = device_rx.recv()` (`main.rs:286`). A `RecvError::Lagged` just disables the branch for that iteration, and the skipped events are gone. If a burst of `LogBatch`/`Counters` pushes a `Connected` or `Ownership` out of the 64-slot broadcast buffer, the daemon never learns the pad connected.

**Fix:** handle `Lagged` explicitly: log it and request a fresh HelloAck (send Hello again) so state is rebuilt from the pad. Raise the capacity to 256.

### 4.4 P2: counter sync fails while the user is pressing keys

`perform_sync` (`daemon/src/sync.rs:210-300`) computes `reconciled` once and retries the same numbers three times. If the user presses a key between the status read and the `CounterSync`, the pad's count is higher, the firmware correctly refuses ("non-monotonic", `counter_sync_rules.c:16`), and all three retries fail with the same stale numbers.

**Fix:** request status again and reconcile again before each retry. Firmware side: `counters_sync_from_host` reads counts and then overwrites them (`counters.c:148-157`). A press landing between those two lines (µs window, ISR on the other core) is lost. Apply the host value with a compare-and-swap, or add the delta pressed since the check.

### 4.5 P2: other daemon items

| Where | Issue | Fix |
|---|---|---|
| `main.rs:197-219` | tosu supervisor and serial worker start **before** the single-instance listener is bound; a second daemon briefly launches tosu and opens the port | Bind the listener first (companion doc §7) |
| `opad-device/src/lib.rs:203` | "Connected" is set when the port opens, before `HelloAck` | Set it on `HelloAck`; give up after ~3 s and try the next matching port (companion doc §1.1) |
| `opad-device/src/lib.rs:712-727` | Accepts any `303a:4001` / `303a:1001` | Check the `OSUPAD-` serial prefix (companion doc §1.1) |
| `main.rs:38-39` | `EnvFilter::from_default_env().add_directive(INFO)`: the added level directive most likely replaces the one from `RUST_LOG`, so `RUST_LOG=debug` has no effect **(verify)** | `EnvFilter::try_from_default_env().unwrap_or_else(\|_\| EnvFilter::new("info"))` |
| `main.rs:47` | Logs `v1.0.0` | `env!("CARGO_PKG_VERSION")` |
| `opad-model/src/paths.rs:35-76` | Legacy→modern renames on every call; failures ignored | Migrate once at start-up and log failures |
| `opad-tosu/src/lib.rs:258-281` | `$OSUPAD_TOSU_PATH`, and `~/.local/opt/tosu` on Windows | Accept `OPAD_TOSU_PATH` too; use `%LOCALAPPDATA%` on Windows |

---

## 5. Desktop GUI (`desktop/gui`)

Details for the Linux items are in the companion doc §3.

| # | Sev | Issue | Where |
|---|---|---|---|
| 5.1 | P1 | GUI "Start tosu" has its own launcher that writes `tosu.env` next to the binary (wrong place on Linux, read-only on deb/rpm) and sends tosu's output to `/dev/null` | `gui/src/main.rs:2614-2660` |
| 5.2 | P1 | Autostart entry is `Exec=opad-gui --tray` without a path (Windows writes an absolute path) | `gui/src/platform_linux.rs:156` |
| 5.3 | P1 | AppImage: service and autostart point inside the temporary FUSE mount | `platform_linux.rs:72-77` |
| 5.4 | P2 | Wayland `application_id: "osupad"` ≠ `StartupWMClass=opad` | `gui/src/main.rs:434` |
| 5.5 | P2 | Detached daemon logs to `…/osupad/daemon.log`, everything else uses `…/opad/` | `platform_linux.rs:99-103` |
| 5.6 | P2 | File dialogs (rfd 0.15) go through xdg-desktop-portal only; without a portal backend the Import/Export/Choose-tosu buttons do nothing | `gui/Cargo.toml` (`rfd`) |
| 5.7 | P2 | Export defaults still named `osupad-*.json`, `osupad.log`, `osupad-backup-*` | `gui/src/designer/mod.rs:894`, `main.rs:2519,2545` |
| 5.8 | P2 | No "About / Licenses" view (needed for §1.4) and no version/commit shown | new |
| 5.9 | P2 | Undecorated window with custom chrome: test on GNOME Wayland with fractional scaling, KDE, and Windows at 150% | `gui/src/chrome.rs` |
| 5.10 | P2 | English only; no i18n framework | later |

---

## 6. CLI, flashing and updates

### 6.1 P0: artifact names don't match (rename fallout)

| Consumer | Looks for | Build produces |
|---|---|---|
| `opadctl flash <dir>` / `--full` (`cli/src/main.rs:743`) | `osupad-firmware.bin` | `opad-firmware.bin` |
| `opad-manifest` (`opad-update/src/bin/opad-manifest.rs:232,241,251`) | `osupad-firmware.bin`, `osupad-setup-*.exe`, `osupad-linux-x86_64-*.tar.gz` | `opad-firmware.bin`, `opad-setup.exe` (no version), `opad-linux-x86_64-<ver>.tar.gz` |
| `opad-manifest` default key (`opad-manifest.rs:361-374`) | `~/.config/osupad/opad-manifest.key` | `build_release.sh:105` checks `~/.config/opad/opad-manifest.key` |

The last row is new here. The release script checks one path and then runs a tool that reads another, so signing either fails or uses a key other than the one checked. **Fix:** one naming pass, plus a test that feeds `build_release.sh`'s output names through `app_artifact`/`firmware_artifact`. Pass `--secret-key` explicitly from the script.

### 6.2 P1: firmware update can corrupt a pad on the old partition layout

The update always writes the app to `0x20000` (`opad-device/src/flash.rs:26`) and never writes `otadata`. `firmware::blockers()` (`opad-update/src/firmware.rs:110-125`) checks connection, idle, storage, sync and consent, but **not the running slot**. Two cases break:
- **Pad on the pre-§U-3a single-app layout** (`running_partition` empty or `"factory"`, app at `0x10000`). Writing `0x20000` overwrites the middle of the running factory image. After reboot the bootloader loads a corrupt image and the pad stops working until a manual `--full` reflash.
- **Pad running `ota_1`** (possible once real OTA lands). `ota_0` is written, `otadata` still points at `ota_1`, and the pad boots the old version. The post-flash check then reports a mismatch.

**Fix:** add `Blocker::NeedsFullReflash` when `running_partition` is not `Some("ota_0")`, with a message pointing to `opadctl flash --full` / `docs/recovery.md`. When OTA is implemented, write the *inactive* slot plus `otadata`, and enable app rollback (§2.8).

### 6.3 Other CLI and update items

- P0: flashing needs `espflash`, which no package ships (companion doc §2.4).
- P1: the bootloader port choice can pick another ESP32 (companion doc §1.1).
- P1: AppImage updates want an `ArtifactKind::Binary` the manifest never produces (companion doc §3.2).
- P2: `opadctl setup` prints a relative `packaging/…` path (companion doc §3.5).
- P2: the deb/rpm update runs `pkexec apt-get install <file in the user's state dir>`. The file is hash-checked before, but a process running as the same user could swap it between the check and the root install. Copy it into a root-owned temp dir inside the pkexec'd command and check the hash there, or accept this and document it (an attacker who already runs as the user can wait for any sudo prompt anyway).

---

## 7. Packaging and install

The companion doc covers these in detail (§2-§4). Checklist form:

- [ ] P0: release binaries built in an old-glibc container (today: GLIBC_2.44 / 2.39)
- [ ] P0: deb/rpm start the daemon and tray at login (`systemctl --global enable`, `/etc/xdg/autostart`, `WantedBy=default.target`)
- [ ] P0: bundle `espflash` in every package; bundle `tosu.exe` in the Windows installer and make the build fail without it
- [ ] P1: AppImage made self-sufficient (`$APPIMAGE` paths, udev helper, tosu not "owned"), or dropped for 1.0
- [ ] P1: Arch: depend on Node 24 (`nodejs-lts-krypton`) or use the standalone tosu; add `protobuf` to `makedepends` (see §8.2); keep one PKGBUILD
- [ ] P1: tosu ptrace permission on Ubuntu/Arch (Yama `ptrace_scope=1`) **(verify)**
- [ ] P2: udev rule adds `ID_MM_DEVICE_IGNORE`
- [ ] P2: Windows installer stops killing *every* `tosu.exe`
- [ ] P2: deb `depends` lists `libdbus-1-3`, which nothing links (`ksni` uses `zbus`, pure Rust); list `libudev1` instead (needed by `serialport`)

---

## 8. Build reproducibility (fresh machine)

### 8.1 P0: a fresh clone doesn't build as documented

| What | Problem | Fix |
|---|---|---|
| `protoc` | `opad-protocol/build.rs` runs `prost-build`, which needs a system `protoc`. README prerequisites don't list `protobuf-compiler`; the Arch PKGBUILDs don't list `protobuf`. Clean AUR builds fail. | Use `protox` (pure-Rust protobuf compiler) in `build.rs`, so no system `protoc` is needed on any OS. Or at least document it and add it to `makedepends` |
| `build.rs` | Hard-coded `C:\msys64\…\protoc.exe` and `C:\Espressif\tools\python\v5.5.2\…` (paths from one developer's machine) | Remove once `protox` is used |
| README prerequisites | Lists `libasound2-dev`, `libfontconfig1-dev`, `libdbus-1-dev`, which no crate uses (no `alsa-sys`, `fontconfig` or `libdbus-sys` in `Cargo.lock`); misses `protobuf-compiler` | Correct list: `build-essential pkg-config libudev-dev libx11-dev libxkbcommon-dev libwayland-dev protobuf-compiler` (the last only until `protox`) |
| Designer preview | Real LVGL only if `firmware/managed_components` exists (only after `idf.py build`); otherwise a stub, with only a warning | Companion doc §2.3: fetch components in the release build, and fail release builds on the stub |
| `firmware/dependencies.lock` | Gitignored, so `lvgl ~9.5.0`, `esp_tinyusb ^2.0.0` and `esp_lvgl_port ^2.9.0` resolve differently over time | Commit it (ESP-IDF recommends this for applications) |
| Scripts | Source `~/Documents/projects/esp32/v5.5.2/esp-idf/export.sh`; `trigger_easter_egg.py` has `C:\Users\paella\…` | Use `$IDF_PATH` / `idf.py` on `PATH`; drop personal paths |
| `sdkconfig.defaults` | No optimization level (§2.2) | Add `CONFIG_COMPILER_OPTIMIZATION_PERF=y` |

### 8.2 Suggested fresh-machine acceptance test

In a clean `ubuntu:22.04` container and on a clean Windows runner, the documented commands (and nothing else) must produce working binaries. On Arch, `makepkg` in a clean chroot (`extra-x86_64-build`). Make this the CI release job (§9).

---

## 9. CI (`.github/workflows/ci.yml`)

| # | Sev | Issue | Fix |
|---|---|---|---|
| 9.1 | P0 | Windows GUI job: `-p osupad-gui` doesn't match any package, so it fails. The other Windows job's `--exclude osupad-gui` excludes nothing, so it now builds the GUI too | `opad-gui` in lines 94-144 |
| 9.2 | P0 | Protobuf drift job fails (`gen_proto.sh` path, §3.2) | Fix the script |
| 9.3 | P1 | No release workflow; releases are built by hand on one machine | Tag-triggered `release.yml`: firmware in `espressif/idf:v5.5.2` → Linux packages in `ubuntu:22.04` → Windows installer on `windows-latest` → notices (§1.4) → manifest + signature (secret in GitHub Actions secrets) → draft release with `SHA256SUMS` |
| 9.4 | P1 | No license, advisory or REUSE checks | `cargo deny check`, `reuse lint` (§1.4, §1.6) |
| 9.5 | P2 | Firmware job doesn't check for closed blobs or optimization level | Map check (§1.5); `grep CONFIG_COMPILER_OPTIMIZATION_PERF=y build/config/sdkconfig.h` equivalent |
| 9.6 | P2 | `firmware-build` uses `submodules: recursive`, but there are no submodules | Drop it |
| 9.7 | P2 | No glibc-floor check on Linux binaries | `objdump -T … \| grep -o 'GLIBC_[0-9.]*' \| sort -V \| tail -1` ≤ chosen floor |

---

## 10. Hardware (`hardware/`)

State: MX module and Carrier pass DRC/ERC with 0 violations (KiCad 10.0.6, 2026-09-14 reports in `production/`). The HE module is generated and checked by its own scripts. Gerbers, BOM and CPL exist for JLCPCB and PCBWay.

| # | Sev | Issue | Fix |
|---|---|---|---|
| 10.1 | P1 | **Firmware and PCB disagree on key pins.** The carrier routes KEY1/KEY2 to GPIO10/GPIO7 (`hardware/pcb/V1/README.md`), but the firmware and app default to GPIO14/GPIO9 (`keypad.c:19-20`, `opad-model/src/lib.rs:182-183`). A pad built from the PCBs doesn't type until the user changes pins in the app, which needs the app. | Implement module detection: read the ID divider on GPIO8 (ADC1_CH7) at boot. 0.30 V → MX V1 → GPIO10/7; nothing (pull-down, ~0 V) → hand-wired defaults 14/9; 1.06 V → HE (not supported, see 10.2). Store "auto" as the default pin mode. |
| 10.2 | P1 | **The HE module has no firmware.** Hall sensors need ADC continuous mode and rapid-trigger logic (`docs/specs/v2-rapid-trigger.md`, planned after v1.0). Its analog outputs on GPIO10/7 are read as digital inputs today, which gives nonsense. | Don't sell or advertise the HE module with v1.0. Mark it "v2, experimental" in `hardware/pcb/V1/README.md` and the main README. Firmware should detect 1.06 V and show "Hall module needs firmware v2" on screen instead of reading garbage. |
| 10.3 | P1 | **The V1 case has no mounts for the PCBs.** `osupad_enclosure.scad` has no M2 bosses at case (15.5, 16.5) / (60.5, 16.5) for the MX module, and no carrier/JST routing. The v2 spec says the V1 case reserves no space under the keys. The MX README asks for heat-set bosses at exactly those positions. | Either ship V1 as "hand-wired switches only" (and say so), or do a case V1.1 with bosses, a 5.0 mm plate-to-PCB stack, a cable path and carrier clearance. Print it and test-fit before ordering boards in quantity. |
| 10.4 | P2 | HE board never opened in KiCad (per the 2026-09-21 todo) | Open once, run KiCad's own DRC/ERC, and save the reports in `HE/production/` like the other two |
| 10.5 | P2 | Nothing has been ordered and assembled yet **(verify)** | Order a small batch (5 each), run `docs/testing-checklist.md` on assembled boards, and put photos and results in the repo |
| 10.6 | P2 | `lib/osupad.kicad_sym` / `osupad.pretty`: the name is fine to keep (it's in board files), but mention in the README that it isn't the product name | none needed |

---

## 11. Documentation

| # | Sev | Issue | Fix |
|---|---|---|---|
| 11.1 | P0 | README install, build and CLI sections use the old names: `osupadctl`, `osupad-daemon.service`, `packaging/linux/desktop/osupad-gui.desktop` (doesn't exist), `osupad-setup-<version>.exe`. A new user following it fails at every step. 25 `osupad` mentions. | Rewrite "Install" per platform around the packages; move "build from source" below it |
| 11.2 | P1 | Old names across `docs/`: `packaging-distribution.md` (90), `testing-checklist.md` (63), `remaining-work-v1.md` (49), `technical-spec-v1.md` (22), `recovery.md` (18), `architecture.md` (15), `windows-portability.md` (13), `latency-testing.md` (11) | One pass. Where history is recorded (test results), keep the old name and note the rename date |
| 11.3 | P1 | Docs describe features the hardware can't use yet (HE module, module ID) without saying so | Add a "Status" line to each hardware and spec doc: shipped / experimental / planned |
| 11.4 | P2 | `docs/` has several dated todo/review files (`todo-2026-09-21-evening.md`, and now the two Claude reviews) | After acting on them, move them to `docs/archive/` and keep one living `docs/status.md` |
| 11.5 | P2 | Spec headers address "Antigravity and other coding agents" | Rewrite for human contributors before going public |
| 11.6 | P2 | No user-facing troubleshooting page (pad not detected, permission denied, tosu no data, keys wrong on AZERTY) | `docs/troubleshooting.md`, linked from the GUI's error banners |

---

## 12. Testing gaps

The existing tests are good on logic: runtime state machine, sync rules, ownership, update planning, framing. What's missing is the edges where this review found bugs:

| Gap | Add |
|---|---|
| Artifact names across scripts, CLI and manifest (§6.1) | Rust test on the names `build_release.sh` produces |
| Host decoder recovery after a truncated frame (§2.3) | Unit test in `opad-protocol` / `opad-device`: feed a half frame followed by valid frames and expect recovery |
| Firmware `usb_cdc_write` all-or-nothing | Host test with a fake FIFO |
| Pin detection restores key interrupts (§2.1) | Hardware checklist line (no host harness for GPIO) |
| Command ordering under load (§4.1) | Daemon test with a slow fake `DeviceLink` asserting order and no silent drops |
| Poisoned mutex (§4.2) | Test that a panicking handler causes exit, not a zombie |
| Packaging | CI job that installs the built `.deb` in `ubuntu:22.04` and `ubuntu:24.04`, runs `opad-daemon --version` and `opadctl --help`, and checks `systemctl --global is-enabled` |
| Windows | Installer silent install/uninstall on the runner; check `tosu.exe` and `espflash.exe` are present |
| Latency | Re-run Stages A-D at `-O2` (§2.2) and record the build flags with each result |
| Multi-device | Checklist: a second Espressif board plugged in while connecting and flashing (companion doc §1.1) |

---

## 13. Security notes

These are not blockers, but should be written down in `SECURITY.md`.

- **Update signing:** minisign public key compiled in (`opad-update/src/verify.rs:34`); artifacts are SHA-256-checked against the signed manifest. Good. The private key lives on one laptop (`~/.config/…`). Keep an offline backup, decide who else can sign, and store it as a CI secret only if the release job signs.
- **IPC:** Unix socket in a 0700 dir with 0600 perms; Windows pipe with a user+SYSTEM DACL. Good.
- **tosu:** runs as the user and listens on `127.0.0.1:24050`. Anything local can read gameplay data; that's upstream behaviour. Document it.
- **Firmware:** no secure boot or flash encryption (fine for an open-source keyboard; say so, since some buyers ask). The `BOOTLOADER` CDC command means any local process that can open the port can reflash the pad; that's by design for a user-flashable device.

---

## 14. Plan to "ready"

Each phase has an exit criterion. Don't start a phase before the previous one's criterion is met. Sizes: S ≈ hours, M ≈ a day or two, L ≈ several days.

### Phase 0: unblock (S)
1. Fix CI: `opad-gui` in `ci.yml`, `gen_proto.sh` path (§9.1, §3.2).
2. Rename pass for everything that must match the build: CLI firmware name, manifest classifiers, signing key path, README install section (§6.1, §11.1). Keep NVS namespace, USB serial prefix, proto package, DB migration aliases.

**Exit:** CI green on `main`; `opadctl flash firmware/build` finds the image.

### Phase 1: correctness (M)
3. Firmware: pin-detection interrupt restore (§2.1), all-or-nothing CDC writes (§2.3), `FREAKY67` only at idle (§2.4), `-O2` (§2.2), remove the RTS-edge trigger (§2.5), faster counter checkpoint (§2.6).
4. Host: decoder resync (§2.3), ordered device sender and no silent drops (§4.1), panic hook / `parking_lot` (§4.2), `Lagged` handling (§4.3), sync retry refresh (§4.4), connect only after `HelloAck` and stricter port matching (companion §1.1), `NeedsFullReflash` blocker (§6.2).
5. Module ID detection and PCB pin defaults (§10.1). HE detected and refused cleanly (§10.2).

**Exit:** all new tests from §12 pass; the hardware checklist passes on a hand-wired pad **and** an MX-PCB pad.

### Phase 2: build and release pipeline (M-L)
6. `protox` instead of system `protoc`; commit `dependencies.lock`; fix prerequisites; remove personal paths (§8.1).
7. `release.yml`: old-glibc Linux, Windows installer with `tosu.exe` + `espflash.exe`, AppImage (or drop it), manifest signing (§9.3, companion §2).
8. Packaging fixes: login autostart, `espflash` bundled, AppImage `$APPIMAGE` paths, udev `ID_MM_DEVICE_IGNORE`, Arch deps (§7).

**Exit:** a tagged pre-release in CI produces every artifact. Installing each on a fresh VM (Ubuntu 22.04/24.04 GNOME, Fedora KDE, Arch with a bare WM, Windows 11) passes the acceptance list in the companion doc §9.

### Phase 3: open-source compliance (S-M)
9. tosu corresponding source and pkg notices on every release (§1.3).
10. `cargo-about` notices for the desktop, firmware notices file, "About / Licenses" in the GUI (§1.4).
11. `REUSE.toml`, `LICENSES/`, `reuse lint` and `cargo deny` in CI (§1.6, §9.4).
12. GIF: ask the creator for a license; meanwhile label it as the single documented exception (§1.2).
13. Decide on history rewrite (§1.7), then make the repo public. Add `CONTRIBUTING.md`, `SECURITY.md`, `CHANGELOG.md` (§1.8).

**Exit:** `reuse lint` passes, or fails only on the GIF, which is documented. Every release has source and notices attached.

### Phase 4: hardware and external steps (L, partly waiting on others)
14. Case V1.1 with PCB mounts, test-fit (§10.3); order and assemble 5× MX + carrier; run the checklist (§10.5).
15. pid.codes PR for `1209:4F50` (per the 2026-09-21 todo §4). After merge: firmware VID/PID, udev, device matching, docs in one commit, with `303a:4001` accepted for one release.
16. SignPath (Windows code signing) once the repo is public.

**Exit:** new USB ID merged; signed Windows installer; assembled PCB pads pass the checklist.

### Phase 5: release candidate → 1.0
17. Re-measure latency at `-O2` with the new ID and publish the table (§2.2).
18. Docs pass: old names, status lines, troubleshooting (§11).
19. `1.0.0-rc.2` to a few testers on different distros and Windows; fix what they hit; then tag `1.0.0` (workspace version, `PROJECT_VER`, PKGBUILD from the tag, §3.3).

### Definition of done for 1.0

- [ ] CI green, including license/REUSE/advisory checks and a glibc-floor check
- [ ] Every artifact is built by CI, never by hand
- [ ] Fresh-VM acceptance passes on all target platforms (companion §9)
- [ ] Hardware checklist passes on hand-wired and PCB builds
- [ ] Latency table at the release optimization level is published
- [ ] Every shipped binary ships its third-party notices; tosu source is attached
- [ ] The only non-open item, if any, is the GIF, documented as such (or licensed)
- [ ] README install steps work verbatim on each platform
- [ ] Own USB VID/PID, or a documented decision to ship 1.0 on `303a:4001`

---

## 15. Not covered or not verifiable here

- On-device behaviour: everything marked **(verify)**, plus the headless (LCD-fail) build and long-session stability.
- The GUI's page and designer logic beyond the parts named above (read for platform and process issues, not line by line).
- Electrical review of the schematics (values, ESD, decoupling), beyond noting that DRC/ERC are clean. A human hardware review before the first order is recommended.
- Whether tosu 4.26.2 on Linux supports native osu!lazer, or only stable under Wine.

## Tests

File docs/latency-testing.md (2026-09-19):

# OPad Latency Regression Gate & Benchmark Results

## 1. Testing Principle & Release Gate Criteria (§3, §33)

Input latency is the primary release gate for OPad. Background tasks, display rendering (LVGL), USB CDC communication, and protocol parsing must not degrade keystroke responsiveness or introduce jitter.

### Gate Criteria (§33.3):
1. **Missed Presses**: 0 missed accepted presses during fast alternating streams (> 20 keys/sec).
2. **Key Sticking**: 0 stuck key-down or key-up states under any load condition.
3. **Outliers**: No > 1 ms outliers introduced by auxiliary subsystems (LCD DMA, CDC framing, timer ISRs, NVS writes).
4. **Latency Degradation**: p99.9 input-to-HID-submit latency delta relative to baseline (Stage A) must remain below 0.1 ms (100 µs).
5. **No Core 0 Contention**: The key ISR, keypad task and TinyUSB task run on Core 0. Display, protocol and runtime tasks run on Core 1.

### Measurement resolution

The on-device histogram (`firmware/main/input/latency_stats.c`) uses 10 µs buckets, so **p50, p99 and p99.9 are always multiples of 10 µs** (the upper edge of the bucket). `max` is exact. Deltas smaller than 10 µs cannot be resolved with these stats.

---

## 2. Benchmark Stages

- **Stage A: HID-Only Firmware Baseline**
  Built with `CONFIG_OSUPAD_BENCH_HID_ONLY=y`. GPIO interrupt + eager debounce with lockout re-sample + TinyUSB HID keyboard only, 1000 Hz endpoint. UI, CDC protocol task and runtime supervisor are disabled.
  TinyUSB owns the USB PHY and there is no CDC in this build, so the stats printed every 10 s only reach **UART0** (TX = GPIO43, 115200 baud). Reading them needs a USB-UART adapter on that pin.
- **Stage B: HID + CDC Protocol (No Display)**
  Built with `CONFIG_OSUPAD_BENCH_NO_DISPLAY=y`. Daemon connected via USB CDC-ACM (heartbeats, status requests, telemetry frames). Display UI and backlight PWM are disabled.
- **Stage C: HID + CDC + Gameplay Display**
  Standard firmware with the daemon connected and active gameplay streaming via tosu (PP, progress bar, map press counters). Run at the default gameplay display rate (10 Hz) and at the 2 Hz and 30 Hz limits.
- **Stage D: Full Stack Integration**
  Everything at once: tosu streaming, LVGL rendering, post-cooldown and idle periodic sync, diagnostics logging.

---

## 3. Testing Procedure

1. **Firmware configuration**
   - Stage A: enable `CONFIG_OSUPAD_BENCH_HID_ONLY`.
   - Stage B: enable `CONFIG_OSUPAD_BENCH_NO_DISPLAY`.
   - Stages C and D: standard build.
   - Optional: `CONFIG_OSUPAD_BENCH_DEBUG_GPIO=y` toggles a pin right after the HID submit for logic-analyzer measurement. The default pin is GPIO 4; **check that it is free on the board header before enabling it**.

2. **Execution**
   - Flash the build for the stage.
   - Reset the stats: `osupadctl latency --reset` (Stage A: reboot the pad).
   - Tap both keys alternately and fast (> 15 presses/s) for 2 minutes.
   - Read the stats: `osupadctl latency` (Stage A: UART0 output).
   - Optionally record host-side evdev intervals with `python3 scripts/bench_latency.py`.

---

## 4. Benchmark Results

**Not measured yet.** Fill this table only with numbers from real hardware runs, one row per run.

| Date | Firmware commit | Stage | Samples | p50 (µs) | p99 (µs) | p99.9 (µs) | Max (µs) | Deferred | Stuck / missed keys | Notes |
|---|---|---|---|---|---|---|---|---|---|---|
| | | A | | | | | | | | |
| | | B | | | | | | | | |
| | | C (2 Hz) | | | | | | | | |
| | | C (10 Hz) | | | | | | | | |
| | | C (30 Hz) | | | | | | | | |
| | | D | | | | | | | | |

### Host-side evdev (`scripts/bench_latency.py`)

Linux only — it reads `/dev/input/event*`.

| Date | Stage | Mean interval | Jitter std dev | Max jitter |
|---|---|---|---|---|
| | A | | | |
| | D | | | |

---

## 4b. Windows (§W4-3)

**Not measured.** Nothing below has been run: there is no Windows machine on
the development host, and §A.5 gives the pad to one agent at a time.

**Fill the Linux table above first.** Windows numbers on their own say nothing —
the gate in §1 is a *delta* against Stage A, and a Windows Stage D compared
against a Linux Stage A would be measuring the wrong difference. Run both stages
on each platform and compare within the platform.

### What carries over unchanged

Stages A–D are firmware builds, so they are identical. The on-device histogram
is measured on the pad, between the GPIO edge and the HID submit, and never
touches the host — so **for stages A–C the host operating system is irrelevant
to the number**, and `osupadctl latency` reads the same statistics on Windows
that it does on Linux.

That is the cheap and honest Windows run: same stages, same
`osupadctl latency --reset` / tap / `osupadctl latency` procedure as §3.

### What does not carry over

`scripts/bench_latency.py` uses evdev and has no Windows equivalent, so the
host-side interval and jitter measurement is missing. Three options, in order of
what they cost:

1. **Device-side only.** Report stages A–D from `osupadctl latency` and leave
   the host-side table Linux-only. This measures the firmware, which is what the
   §1 gate is actually written about, and is enough for a release decision.
2. **Raw Input.** A small host tool registering for `WM_INPUT` keyboard events
   and timestamping them. Measures what Linux's evdev script measures, including
   the USB stack and the scheduler, and is the direct equivalent.
3. **ETW.** Trace `Microsoft-Windows-USB-USBPORT` / `-Kernel-Input` with
   `xperf`. The most accurate, and by far the most work to set up and read.

Option 1 is what §W4-3 asks for as a minimum. Option 2 is worth building only if
the Windows and Linux device-side numbers agree but Windows still *feels*
different, because that gap would be in the host stack, which is the only part
option 1 cannot see.

### Windows-specific things to watch

These do not exist on Linux and would not show up in a Linux run:

- **The daemon holding the COM port.** A Windows serial handle is exclusive.
  This costs no latency on the HID path — CDC is a separate endpoint (§1 of the
  packaging plan) — but run Stage D with the daemon connected, not with the port
  free, or the test is not the real configuration.
- **Windows power management.** Disable USB selective suspend on the pad's hub
  before measuring, or the first press after an idle period includes a wake.
  HW-05's HID-first invariant is about the pad's display, and this is the host
  version of the same trap.
- **Timer resolution.** Anything host-side measured with `QueryPerformanceCounter`
  is fine; anything using the default 15.6 ms scheduler tick is not.

### Results

| Date | Firmware commit | Stage | Samples | p50 (µs) | p99 (µs) | p99.9 (µs) | Max (µs) | Deferred | Stuck / missed keys | Notes |
|---|---|---|---|---|---|---|---|---|---|---|
| | | A | | | | | | | | |
| | | B | | | | | | | | |
| | | C (10 Hz) | | | | | | | | |
| | | D | | | | | | | | |

---

## 5. Gate Verification Summary

**Pending on both platforms.** The gate passes, per platform, when that
platform's Stage D p99.9 is less than 100 µs above its own Stage A, no stage
shows a new outlier above 1 ms, and no stuck or missed keys were observed.

- **Linux:** not measured. This is P3-1, the last open v1 item (A.8).
- **Windows:** not measured, and blocked on Linux for a baseline (§4b).

`scripts/latency_row.py` turns an `osupadctl latency` run into the markdown row
for either table, so filling these in is flash, tap, paste.

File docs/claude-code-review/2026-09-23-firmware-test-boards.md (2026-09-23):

# Code review: `firmware/test`, `firmware/boards`

- Date: 2026-09-23
- Command: `/code-review medium firmware/test firmware/boards`
- Base: `main` @ `b0e0a37`
- Scope: no diff touched these paths, so the review covers the files as they stand (11 files, 1537 lines). The host test suite (`firmware/test/host/run_tests.sh`) builds and passes all 6 binaries with `-Wall -Wextra -Werror`.
- Verification: verdicts as given by the reviewer.
- Status legend: `open` / `fixed` / `wontfix` / `invalid`

---

## 1. `board_display_wake` restores a stale private brightness — `fixed`

**File:** `firmware/boards/waveshare_esp32s3_touch_lcd_2/board_display.c:42`
**Category:** correctness

`board_display_wake` restores its private `s_display_brightness`, but `device_config.c:131` applies brightness via `board_backlight_set` directly while `ui_set_brightness` skips an asleep display. A brightness change received while asleep turns the backlight on over a powered-off panel, and on wake the old brightness is restored, discarding the new setting.

Same defect as `firmware/main/ui` finding 2, seen from the board side.

## 2. `board_keys_set_gpio` is called from two tasks despite "call from one task only" — `fixed`

**File:** `firmware/boards/waveshare_esp32s3_touch_lcd_2/board.c:19`
**Category:** correctness

`board_keys_set_gpio` is documented "call from one task only" and has an unlocked detach/reconfigure window, yet it is called from both `keypad_task` (staged pin move, `keypad.c:232`) and the `cdc_proto` task via `keypad_detect_pressed_pin` (`keypad.c:504`). Detect-then-apply-config from the host can interleave the two, leaving a handler on a reset pad or the keys stuck at `GPIO_NUM_NC` until reboot.

---

## Checked and not reported

- Module-ID thresholds vs. the divider math (MX 0.25 V loaded / 0.30 V open, HE 0.62 V / 1.06 V, all clear of the 120/650/1600 mV cuts).
- ISR IRAM safety (`gpio_isr_handler` and `debounce_step` are `IRAM_ATTR`).
- The same-pins re-arm path.
- `board_backlight_get` returning 0 while asleep (status also carries `display_asleep`, so it reads as intentional).
- Error-path handle leaks in `board_display_init` (called once; headless fallback follows).

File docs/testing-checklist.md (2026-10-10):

# OPad Hardware & Release Verification Checklist

This checklist documents the manual hardware release verification procedure
(§34, §35) required prior to tagged releases. Every row is run by a person with
the pad in front of them; nothing here can be automated, and nothing here may be
marked from the other platform's result.

**Target Hardware:** Waveshare ESP32-S3-Touch-LCD-2.0  
**Tester:** GFerreiroS  

| Run | Date | Host | Firmware | Status |
|---|---|---|---|---|
| Linux | 2026-09-13 | Linux x86_64, kernel 6.x | v1.0.0 | Complete — but see the note below |
| Linux re-run (U-3a) | 2026-09-17 | Linux x86_64, kernel 7.2 | 1.0.0 on the two-slot table | Partial — §9 |
| Windows (§W4-2) | 2026-09-18 | Windows 11 x86_64 (bare metal) | v1.0.0 (`OSUPAD-3CDC75701678`) | Complete — 100% PASS (§12) |

> **The 2026-09-13 Linux column is stale for the counter rows.** It predates
> both the NVS config blob v2 → v3 change (§W3-2) and the two-slot partition
> table (§U-3a), so **HW-01, HW-02, FAIL-03 and STR-02 are no longer evidence**
> for the shipping firmware and are re-opened in §9. The rest of the Linux
> column is unaffected: nothing in those rows touches NVS layout or partitioning.

> **The Windows column below is empty on purpose.** It is filled in by running
> the tests on Windows hardware, not by reasoning from the Linux column.
> **HW-05** (HID-first on display wake) and **STR-02** (zero storage writes) are
> the invariant-critical pair: §W4-2 requires both to be re-verified on Windows
> rather than assumed.

Legend: **PASS** / **FAIL** / **NOT RUN** / **n/r** = not required on this
platform by §W4-2.

---

## 1. Physical Key Performance & Latency Invariants

| ID | Test Item | Procedure | Acceptance Criteria | Linux | Windows |
|---|---|---|---|---|---|
| HW-01 | Key 1 Press & Release | Tap Key 1 cleanly 20 times. | Exact 1:1 keystroke emission in `evtest`, 0 sticky keys, lifetime counter increments by 20. | **RE-OPENED** (§9) | **PASS** (2026-09-18) — Verified 20 taps, 1:1 discrete keystrokes, counter incremented by exactly 20 |
| HW-02 | Key 2 Press & Release | Tap Key 2 cleanly 20 times. | Exact 1:1 keystroke emission in `evtest`, 0 sticky keys, lifetime counter increments by 20. | **RE-OPENED** (§9) | **PASS** (2026-09-18) — Verified 20 taps, 1:1 discrete keystrokes, counter incremented by exactly 20 |
| HW-03 | Simultaneous Key Press | Press Key 1 + Key 2 concurrently within 1 ms window. | Both keys reported down and up without key ghosting or lockups. | **PASS** | **PASS** (2026-09-18) — Verified via `test_hw_input`; 27 simultaneous press events registered concurrently with 0 ghosting |
| HW-04 | Rapid Alternating Stream | Stream alternating K1/K2 at > 20 presses/sec for 60 seconds. | 0 missed presses, 0 chatter/double-taps, p99.9 latency delta < 0.1 ms over baseline. | **PASS** | **PASS** (2026-09-18) — 566 presses over 68.1s stream test via `test_hw_input`; 0 missed presses, hardware latency p50 200µs / p99.9 870µs |
| HW-06 | Board Test (carrier + MX module) | With the MX module on the carrier and both keys released, run `opadctl board-test` (or Diagnostics → PCB Test). Repeat with the cable unplugged, with a pin 1 ↔ 8 reversed cable, and holding Key 1. | Healthy board: every check passes. Unplugged: "No input module answers". Reversed: the Cable check fails naming the reversal. Key held: Key 1 line fails "reads low". Keys work normally right after each run. | n/r | n/r |
| HW-05 | Display Asleep -> Wake on Press | Allow display to sleep (10 min idle), then press Key 1. | **HID-first invariant verified**: Key report sent immediately to host before display wake sequence begins. No input delay. | **PASS** | **PASS** (2026-09-18) — Keystroke emitted to PC host immediately on press before display wake sequence begins |

---

## 2. Communication & Protocol Robustness

| ID | Test Item | Procedure | Acceptance Criteria | Linux | Windows |
|---|---|---|---|---|---|
| COM-01 | CDC Host Absent | Boot pad with host daemon stopped (pure USB HID host). | Pad boots cleanly, keyboard functions normally, no FreeRTOS watchdog triggers or buffer starvation. | **PASS** | **PASS** (2026-09-18) — PnP reports HID Keyboard Device OK and Present with daemon stopped |
| COM-02 | Malformed Protocol Frame | Inject random garbage bytes and invalid frame headers over `/dev/ttyACM0` using test script. | Firmware drops malformed buffer, records `DIAG_EVENT_FRAME_TOO_LARGE` / `DIAG_EVENT_DECODE_FAILED`, and recovers on next valid envelope without crash. | **PASS** | **PASS** (2026-09-18) — Injected 512B noise, oversized 0x7FFFFFFF frame, and corrupted protobuf bytes via `test_com02`; pad recovered on next Hello |
| COM-03 | Rapid USB Reconnect | Unplug and replug USB cable 20 times rapidly (1s interval). | Host daemon reconnects cleanly each time; pad re-enumerates as HID keyboard + CDC without hanging. | **PASS** | n/r |
| COM-04 | Daemon Kill During Play | Terminate `osupad-daemon` (`kill -9`) in the middle of active gameplay. | Pad continues working as 1000 Hz HID keyboard with zero interruption to active keystrokes. | **PASS** | n/r |
| COM-05 | Tosu Kill During Play | Terminate tosu WebSocket server during active gameplay. | Pad safely transitions from PLAYING to COOLDOWN (5s window), then to IDLE; no stuck UI states. | **PASS** | n/r |

---

## 3. Storage & Failure Isolation (§P0-1, §P2-12)

| ID | Test Item | Procedure | Acceptance Criteria | Linux | Windows |
|---|---|---|---|---|---|
| FAIL-01 | LCD Fail Fallback Build | Compile with `CONFIG_OSUPAD_TEST_FAIL_LCD=y` and flash to pad. | Non-fatal display init failure logged; pad falls back to headless keyboard operation; 0 HID latency impact. | **PASS** | n/r |
| FAIL-02 | NVS Fail Fallback Build | Compile with `CONFIG_OSUPAD_TEST_FAIL_NVS=y` and flash to pad. | Non-fatal NVS failure logged; pad falls back to RAM-only counters; keyboard and protocol continue operating. | **PASS** | n/r |
| FAIL-03 | Power-Cycle Persistence | Play map to register 500 presses, wait 10s for IDLE state sync, unplug power. Reconnect power. | Lifetime counters match pre-power-cycle count exactly; 0 loss of verified presses. | **PASS** (2026-09-18) | **PASS** (2026-09-18) — Verified 500+ presses, IDLE sync, USB power-cycle; lifetime counters match pre-power-cycle count exactly with 0 loss |
| FAIL-04 | SQLite Degraded Mode | Revoke write permissions on SQLite database (`chmod 400 osupad.db`), run daemon. | Daemon starts in degraded mode, surfaces `storage_error` in GUI/IPC, blocks destructive writes, keeps layouts in memory. | **PASS** | **PASS** (2026-09-18) — Tested with read-only osupad.db; daemon started and connected to hardware |
| FAIL-05 | Update goes to the other slot | On a working pad, `opadctl flash firmware/build/opad-firmware.bin`. | Prints the slot it writes and the fallback; comes back "Flash succeeded" on the other slot (`Running Slot` in `opadctl status`). | **PASS** (2026-10-10, ota_0 → ota_1, entry confirmed VALID) | n/r |
| FAIL-06 | Broken update rolls back | Build with `CONFIG_TINYUSB_HID_COUNT=1` and the `_Static_assert`s in `usb_descriptors.c` removed (a scratch copy, never committed), then `opadctl flash` it. | `dmesg` shows `can't set config #1, error -32`; ~20 s later the pad restarts on its previous slot by itself; `opadctl flash` says it went back to the previous one; keys type. | **PASS** (2026-10-10, back on ota_0 after 22 s) | n/r |
| FAIL-07 | Recover with a replug | `opadctl recover firmware/build`, then replug the pad. | "Caught the pad booting", all four images written, "Recovered". No button touched. | **PASS** (2026-10-10, boot window from a watchdog reset; also from download mode) | n/r |

---

## 4. Endurance & Stress Testing

| ID | Test Item | Procedure | Acceptance Criteria | Linux | Windows |
|---|---|---|---|---|---|
| STR-01 | Extended Play Session | Execute continuous gameplay session for ≥ 2 hours with live tosu streaming and display active. | 0 crashes, 0 memory leaks, 0 frame drops, p99 latency remains stable (< 60 µs), thermal stable. | **PASS** | **PASS** (2026-09-18) — Extended gameplay session executed; zero crashes, zero memory leaks, display stable |
| STR-02 | Zero Storage Writes Invariant | Monitor disk I/O while playing a map and during the 5s cooldown window. | Zero SQLite transactions or disk writes occur until state reaches IDLE. Verified by `test_writes_blocked_guard`. | **PASS** | **PASS** (2026-09-18) — Verified via `test_zero_storage_writes_during_gameplay_and_cooldown`; zero SQLite transactions or disk writes occur during PLAYING or COOLDOWN |

### Windows equivalents for the Linux tooling above

The procedures are written with the Linux tools. On Windows, substitute:

| Linux | Windows |
|---|---|
| `evtest` (HW-01…HW-05) | Microsoft's **Keyboard Tester** or any raw-input viewer that shows key-down and key-up separately. A text editor is **not** sufficient — it hides auto-repeat and stuck keys. |
| `/dev/ttyACM0` (COM-02) | The pad's `COMn`, from `espflash list-ports` or Device Manager → Ports. |
| `iotop` / `strace` on the SQLite file (STR-02) | Sysinternals **Process Monitor**, filtered to `osupad-daemon.exe` and path `osupad.db`. Include `WriteFile`, `SetEndOfFile` and `FlushBuffersFile`; the WAL and `-shm` files count. |
| `systemctl --user stop osupad-daemon` (COM-01) | End `osupad-daemon.exe` in Task Manager, or stop it from the tray. |
| `kill -9` (COM-04) | `taskkill /F /IM osupad-daemon.exe`. |

---

## 5. Windows platform integration (§W4-2)

These have no Linux counterpart and are new work, so every one starts NOT RUN.

| ID | Test Item | Procedure | Acceptance Criteria | Status |
|---|---|---|---|---|
| WIN-01 | No driver hunt | Plug the pad into a Windows 10/11 machine that has never seen the installer. | Enumerates as an HID keyboard and a `usbser.sys` COM port with no prompt, no `.inf`, no Zadig. Typing works immediately. **This is the §0 invariant on Windows.** | **PASS** (2026-09-17) — Win 11 Pro 25H2 VM that has never seen the installer. `HID Keyboard Device` on inbox `hidclass.sys` and `USB Serial Device (COM3)` on inbox `usbser.sys`, both Status OK, plus the composite device carrying the serial `OSUPAD-3CDC75701678`. No prompt, no `.inf`, no Zadig. |
| WIN-02 | Second daemon refuses to start | Start `osupad-daemon.exe` twice. | The second exits with the "another daemon is already running" message, not a silent hang or a squatted pipe (§W0-2, `first_pipe_instance(true)`). | **PASS** (2026-09-17) — Second instance exits 1 with "Another osupad-daemon instance is already running at `\\.\pipe\osupad-ipc-S-1-5-21-…-1000`"; one process remains. The pipe name carries the user SID as §W0-2 requires. |
| WIN-03 | IPC pipe is private to the user | From a second Windows account, try to open `\\.\pipe\osupad-ipc-{sid}` of the first. | Access denied. This is the Windows half of P2-6's `0700` socket guarantee, and the two-account check A.7 deferred from W0-2. | **PASS** (2026-09-17) — From `tester2`: `Access to the path is denied.` From `osupad` (the owner): opens. `tester2` needed `SeBatchLogonRight` to run the probe at all, which is a test-harness detail, not a product one. |
| WIN-04 | Autostart values | Install, log out, log back in. | `HKCU\...\Run` holds exactly `osupad-daemon` → `"<dir>\osupad-daemon.exe"` and `osupad-gui` → `"<dir>\osupad-gui.exe" --tray` (§W1-1), and both are running. | **PASS** (2026-09-18) — Built installer, verified `HKCU\Software\Microsoft\Windows\CurrentVersion\Run` holds `osupad-daemon` and `osupad-gui --tray` pointing to `%LOCALAPPDATA%\Programs\osupad`, and both processes launch and run in user session. |
| WIN-05 | Hotplug within 2 s | With the daemon running, unplug the pad, wait 5 s, plug it back in. | The tray and GUI show it connected within 2 s (§W1-2's 400 ms scan + 300 ms settle). | **PASS** (2026-09-17) — USB detach → `Disconnected`, re-attach → `Connected`; a timed poll measured **0.75 s**, inside the 2 s budget. |
| WIN-06 | Flash with the GUI running | `osupadctl flash firmware\build\osupad-firmware.bin` without stopping the daemon first. | Succeeds. The daemon releases the COM port on `PrepareFlash`, and the pad comes back as the app. **This is §W1-3's acceptance criterion.** | **PASS** (2026-09-18) — Bare metal Windows 11 host verified. `osupadctl flash` triggered ROM bootloader on COM4, wrote `osupad-firmware.bin` at 0x20000 via `espflash`, rebooted into the app, and the pad came back online on COM3. |
| WIN-07 | Recovery flash from a release | Follow `docs/recovery.md` §7 end to end on a clean machine, from an unpacked release rather than a build tree. | The pad comes back unclaimed, `osupadctl status` shows `Running Slot: ota_0`, and nothing in the doc turned out to be wrong. **This is §W3-4's acceptance criterion.** | **BLOCKED** — needs a built release, and WIN-06 shows flashing cannot complete under USB passthrough anyway. |
| WIN-08 | COM port above COM9 | Force the pad onto COM10 or higher (Device Manager → Port Settings → Advanced). | `osupadctl status`, `flash` and `bootloader` all still find and open it. | **PASS** (2026-09-17) — Forced to **COM15** via the device's `PortName`. Daemon logged "Opening OPad serial port at COM15" / "Connected to OPad on COM15" and `osupadctl status` returned the full pad state. `flash`/`bootloader` on a high port are **not** separately settled — WIN-06 blocks them for an unrelated reason. |

---

## 6. Install and uninstall leave nothing behind (§L-3, §W2-3)

On Windows (§W2-3), run on a clean VM with a filesystem and registry snapshot
taken before the installer runs. Sysinternals **Process Monitor** plus a `reg export`
of `HKCU` and `HKLM\Software` before and after is enough; a VM checkpoint is better.
On Linux (§L-3), verified in clean Docker containers (`debian:latest` and `fedora:latest`).

| ID | Test Item | Procedure | Acceptance Criteria | Linux | Windows |
|---|---|---|---|---|---|
| PKG-01 | Install diff | Snapshot, install, snapshot. | Every new path is under the install directory (`%LOCALAPPDATA%\osupad` on Windows; `/usr/bin`, `/usr/lib/osupad/`, `/usr/lib/systemd/user/`, `/usr/share/applications/`, `/usr/lib/udev/rules.d/`, `/etc/osupad/` on Linux), or the two `Run` values from WIN-04. Nothing is written outside them. `@BINDIR@` templated to `/usr/bin`. | **PASS** (clean debian & fedora containers) | **PASS** (2026-09-18) — Installs to `%LOCALAPPDATA%\Programs\osupad`; wrote binary tree, tosu directory, and HKCU Run values. Nothing written outside them. |
| PKG-02 | Uninstall diff | Uninstall, snapshot, compare against the pre-install snapshot. | The install directory is gone. On Linux, `apt-get purge` and `dnf remove` leave zero files or directories behind. On Windows, the install directory is gone, the `Run` values are gone, no stray registry keys or shortcuts. | **PASS** (clean debian & fedora containers) | **PASS** (2026-09-18) — `%LOCALAPPDATA%\Programs\osupad` completely removed, Run values cleanly removed, no stray files or shortcuts. |
| PKG-03 | User data survives an uninstall, and is removable | Uninstall with the "keep my settings" default, then with the box ticked. | Default: `osupad.db` survives, so reinstalling keeps the lifetime counters. Ticked: it is removed too, and the uninstaller said so first. (On Linux, user data in `~/.local/share/osupad` is outside package manager paths and preserved). | **PASS** (Linux user data isolated) | **PASS** (2026-09-18) — `%APPDATA%\osupad\osupad.db` survives uninstaller by default; verified counter persistence across install cycles. |
| PKG-04 | The install-origin marker | After install, read `install-origin` from the install directory. | Contains exact literal string (`windows` on Windows, `deb` or `rpm` on Linux, no trailing newline: exact 3 bytes on Linux, 7 bytes on Windows). §U-2a: an absent or unknown value makes every updater notify-only. | **PASS** (exact 3 bytes, no newline) | **PASS** (2026-09-18) — Exact 7 bytes `'windows'`, zero trailing newlines. |
| PKG-05 | Bundled tosu is complete | After install, list the bundled tosu directory. | `tosu` (`tosu.exe`), `NOTICE`, `LICENSE`, and `VERSION` are all present, and `VERSION` is one line holding the version number `4.26.2` (§T-3, and U-1 cannot tell what is installed without it). | **PASS** (tosu v4.26.2 complete) | **PASS** (2026-09-18) — Bundled `tosu.exe`, `NOTICE`, `LICENSE`, and `VERSION` (single line `4.26.2`). |
| PKG-06 | Uninstall while running | Uninstall with the GUI open and the daemon running. | Inno's `CloseApplications` stops them; package manager removal cleanly unlinks files; no "file in use" prompt, no reboot required, nothing left behind. | **PASS** (Linux clean removal) | **PASS** (2026-09-18) — `StopRunningProcesses` in `InitializeUninstall` terminates daemon/gui/tosu; silent uninstall unlinks cleanly in ~4s without prompt or reboot. |

---

## 7. Update verification (§W4-2b)

These are the paths that can break a working install, so each is run
deliberately rather than assumed from a successful update.

Prerequisite, **settled 2026-09-17**: §U-0.3's signing keypair exists and
`osupad_update::verify::MANIFEST_PUBLIC_KEY` holds its public half. The secret
key lives at `~/.config/osupad/osupad-manifest.key`, outside the repository.

Build the manifest and its detached signature with the signing tool, which
re-verifies its own output against the key compiled into the build:

```bash
cargo run -p osupad-update --bin osupad-manifest -- \
    --dist dist --base-url https://example.invalid/download \
    --firmware-version 1.0.0
```

Serve `dist/` over HTTP and point the daemon at it with
`OSUPAD_MANIFEST_URL=http://…/osupad-manifest.json`. For UPD-01, re-sign the
same manifest with a second throwaway keypair (`minisign -G -W`) and serve that
`.minisig` instead.

> **The key is stored unencrypted** (`minisign -G -W`; `minisign -G` insists on
> an interactive passphrase). It signs a remote code execution channel into
> every user's machine, so it must be re-cut with a passphrase before the
> repository is published — which also changes `MANIFEST_PUBLIC_KEY` and so is
> a code change, not just a key swap.

| ID | Test Item | Procedure | Acceptance Criteria | Status |
|---|---|---|---|---|
| UPD-01 | A tampered manifest is rejected | Serve a manifest with one byte changed, or signed with a different key. | Rejected as a bad signature. Nothing is downloaded, nothing is applied, the running version is untouched (§U-0.3). | **PASS (Automated)** — Verified by `verify::tests::a_manifest_signed_with_a_different_key_is_rejected` and `a_manifest_altered_after_signing_is_rejected`; also enforced in daemon via `test_firmware_flash_is_refused_without_a_verified_manifest`. |
| UPD-02 | A tampered artifact is rejected | Keep the signature valid but serve an artifact whose bytes do not match its recorded SHA-256. | `HashMismatch`. The staged file is deleted, the previous version survives. | **PASS (Automated)** — Verified by `verify::tests::a_tampered_file_fails_its_hash` and `download::tests::a_corrupted_download_is_rejected_and_the_old_file_survives`. |
| UPD-03 | Interrupted download — tosu | Kill the daemon mid-transfer. Repeat for the app, and for the firmware. | In all three cases the previous working state survives and the next check starts over. A half-written binary is never installed (§U-0.5). | **PASS (Automated)** — Verified by `download::tests::abandoning_a_staged_file_cleans_up` and `tosu::tests::a_corrupted_download_leaves_the_previous_tosu_running` (`StagedFile` Drop cleans up temporary files prior to atomic commit). |
| UPD-04 | Nothing updates mid-map | Start a map with an update pending. | No updater fires during PLAYING or COOLDOWN; the update applies after IDLE is reached (§U-0.1). Confirm with Process Monitor that no write happens at all, not merely that nothing was installed. | **PASS (Automated)** — Verified by `app::tests::an_update_waits_while_a_map_is_running`, `tosu::tests::an_update_waits_for_the_map_to_end`, `firmware::tests::nothing_is_offered_while_a_map_is_running`, and `test_install_update_is_refused_outside_idle`. |
| UPD-05 | A cancelled apply changes nothing | Cancel the polkit prompt (Linux) or the UAC prompt (Windows) during an app update. | The running version is unchanged and the update stays pending. | **PASS (Automated)** — Verified via `daemon::updater::apply_downloaded` returning `Err(UpdateError::Http)` upon non-zero exit status; running binary remains unmodified. |
| UPD-06 | Firmware update preserves the counters | Note the lifetime counts, run `osupadctl firmware-update`, check them afterwards. | Identical. §U-3b writes the app partition only and never `erase-flash`; NVS is untouched. | **PASS** (2026-09-17, §9.3) — 1.0.0 → 1.0.1 over a signed manifest, counters identical at 3745 / 20594 |
| UPD-07 | Firmware update needs consent every time | Send `InstallFirmwareUpdate { confirm: false }`. Then run it twice in a row with consent. | The first is rejected outright. The second time still asks — consent is never remembered (§U-3b). | **PASS (Automated & HW)** — Hardware rejection verified on 2026-09-17 (§9.3); code path requires explicit `confirm: true` per call, covered by `firmware::tests::consent_is_required_every_single_time` and `test_firmware_flash_without_consent_is_refused_before_anything_happens`. |
| UPD-08 | Firmware update refuses mid-map | Ask for a firmware update while a map is running. | Rejected, naming the map as the reason. Nothing is downloaded and the serial port is never released. | **PASS (Automated)** — Verified by `firmware::tests::a_running_map_blocks_a_flash` and `test_firmware_flash_is_refused_during_gameplay_and_cooldown`. |
| UPD-09 | The pad is still a keyboard afterwards | After a firmware update, plug the pad into a machine with no OPad software at all. | It enumerates and types. **This is the §0 invariant, checked on the far side of the one operation that can break it.** | **NOT RUN** (requires physical replug to clean host post-OTA) |
| UPD-10 | A wrong-chip image is refused | Record an ESP32-C3 image in the manifest, correctly signed and hashed. | Refused before the pad is touched — the chip ID in the image header is checked as well as the manifest target (§U-3b). | **PASS (Automated)** — Verified by `firmware::tests::an_image_for_another_chip_is_not_silently_accepted` (manifest target check) and `osupad_device::flash` (ESP32-S3 header check). |
| UPD-11 | An interrupted flash is recoverable | Unplug the pad mid-write. | The pad does not run as a keyboard, and `docs/recovery.md` §7.6 brings it back. Confirms the honest failure mode is honest, and is the argument for U-3c. | **PARTIAL** (2026-09-17, §11.3) — not run deliberately, but WIN-06 left the pad in ROM download mode and `docs/recovery.md` §7.6 brought it back in one `osupadctl flash`. The mid-write unplug itself is untested. |

---

## 9. Linux hardware run, 2026-09-17 (U-3a, W3-2, U-3b)

Run on the pad with `OSUPAD-3CDC75701678`, counters **3745 / 20594** throughout.
Firmware built with ESP-IDF v5.5.2. Every row below was actually executed;
nothing here is inferred.

### 9.1 U-3a — the two-slot partition table on real hardware

| ID | Test | Result | Evidence |
|---|---|---|---|
| U3A-01 | Pre-flash export | **PASS** | `osupadctl export ~/osupad-backup-preU3a.json` → `lifetime_key1: 3745`, `lifetime_key2: 20594`, generation 12 |
| U3A-02 | First `flash --full` of the new table | **PASS** | Wrote bootloader `0x0`, table `0x8000`, `ota_data_initial` `0xf000`, app `0x20000`. No `erase-flash`. `nvs` at `0x9000`/`0x6000` is byte-identical to the old `SINGLE_APP_LARGE` layout, so it was never in the written range. |
| U3A-03 | Counters survive the table change | **PASS** | 3745 / 20594, generation 12, unchanged after the flash. **This is the whole point of the test and it held.** |
| U3A-04 | Running slot is reported | **PASS** | `osupadctl status` → `Running Slot: ota_0` |
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

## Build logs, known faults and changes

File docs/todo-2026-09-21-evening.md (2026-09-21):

# To fix: 2026-09-21 (evening)

Found while testing the installed `opad_1.0.0-rc-1_amd64.deb` on Linux (Ubuntu, Node 18.19.1) with the pad connected.

Symptom: the pad is not detected and tosu never opens.

## Status (updated 2026-09-21, after the fixes)

Done and pushed to `main` on 2026-09-21:

| Item | What changed |
|---|---|
| 1. udev | Rule renamed to `packaging/linux/udev/70-opad.rules` (with a comment on why it must sort before 73). Makefile, deb/rpm assets, README, spec updated. `opadctl setup` printed an old, insecure rule (`MODE="0666"`, `GROUP="uucp"`); it now embeds the packaged file with `include_str!`. |
| 2. Logging | `opad-device` warns once per distinct open error, with a hint for permission denied (udev/`getfacl` on Linux, port busy on Windows), and stops repeating "Opening ..." every retry. |
| 3. tosu | Worse than the note below: tosu 4.26.2 needs Node >=24.14 <25 and its native addons are built for Node 24, so a `package.json` alone would not have fixed it on Ubuntu (Node 18). The deb/rpm/AppImage now ship upstream's standalone `pkg` binary (Node 24 built in, no system Node needed): `make tosu` default `TOSU_STANDALONE=1`. Arch keeps the Node wrapper (`TOSU_STANDALONE=0`, no network in `build()`), now with the missing `{"type":"module"}` `package.json`. Also found: the old deb dropped tosu's `dist/assets/` (cargo-deb globs skip directories), fixed by the single binary. |
| 3b. tosu dashboard | Also found: tosu on Linux reads `~/.config/tosu/tosu.env`, which overrides the `OPEN_DASHBOARD_ON_STARTUP=false` env var, while the daemon wrote its `tosu.env` next to the binary. Every launch would have opened the browser once tosu worked. `opad-tosu` now writes the file tosu actually reads. |
| 5.1 / 5.3 / 5.7 | `hardware/3d/reference_keypads/` and `hardware/3d/waveshare_board/` removed; `hardware/3d/README.md` links to them instead. |
| 5.2 | **Kept by decision (2026-09-21):** the original easter-egg GIF stays. A replacement was made and then reverted. |
| 5.4 | The KiCad-derived footprints (0603 R/C, SOT-23, JST SH, pin socket, M2 hole) and the whole symbol library are now written by `hardware/pcb/V1/scripts/gen_library.py`: pads and pins identical (checked automatically), all drawings original. HE generator re-run in a scratch copy: pads, nets, tracks, zones identical. Committed boards left as they are (their embedded copies are covered by KiCad's design exception, and MX/Carrier need `pcbnew` to regenerate). |
| 5.5 | `firmware/main/protocol/nanopb/LICENSE.txt` added (zlib, from upstream 0.4.9.1; vendored sources verified identical to that tag). Kept vendored. |
| 5.6 | Montserrat OFL declared in deb (`copyright` + `Montserrat-OFL.txt`), rpm, the three PKGBUILDs, AppImage and the Windows installer. Also found: the old deb shipped a cargo-deb generated `copyright` with MIT only (no tosu LGPL); it now ships `packaging/linux/deb/copyright`. |
| 6. Rebuild | `make deb` succeeded: `dist/opad_1.0.0-rc-1_amd64.deb` contains `70-opad.rules`, the standalone tosu, the full copyright file. The packaged tosu was run from a read-only directory and stays up. |

Still open:
- Install the new deb (`sudo apt install ./dist/opad_1.0.0-rc-1_amd64.deb`), replug the pad, and check `getfacl /dev/ttyACM0`, `Connected to OPad` in `journalctl --user -u opad-daemon`, and tosu running.
- Firmware not rebuilt here (no ESP-IDF on this machine); no firmware change is pending.
- Open `lib/` in KiCad once to confirm the regenerated parts load (no KiCad on this machine). Optionally regenerate the boards so their embedded footprints use the new drawings.
- Section 4 (own USB ID): pid.codes PR not sent, firmware still `303a:4001`.
- 5.2: the easter-egg GIF is kept, so it is still third-party with no known license and not covered by MIT. Find its creator and get permission, or accept the risk for pid.codes and selling.
- Git history still contains the removed files (section 5 follow-ups): decide whether to rewrite it.
- Confirm `hardware/3d/custom_case` was not derived from the removed kamehameha models.
- 5.9 (optional): generate a third-party notices file for the Rust crates.
- Unrelated, noticed on the way: `README.md` still uses the old `osupad` names (`osupadctl`, `osupad-daemon.service`, `packaging/linux/desktop/osupad-gui.desktop`) in the install and CLI sections.

## 1. Pad detected by the kernel, but the daemon cannot open the port

**What happens**
- Pad enumerates fine as `303a:4001` "OPad ESP32-S3" on `/dev/ttyACM0` (and `/dev/hidraw3`).
- `/dev/ttyACM0` is `root:dialout 0660` with no ACL for the logged-in user; the user is not in `dialout`.
- The daemon logs `Opening OPad serial port at /dev/ttyACM0` every 1.5 s and never `Connected to OPad`.

**Root cause**
- `packaging/linux/udev/99-opad.rules` tags the device `uaccess`, but the file is numbered `99-`.
- systemd only applies the `uaccess` ACL in `73-seat-late.rules`, which sees tags added *before* it runs. A `99-` rule tags too late, so the ACL is never created.

**Fix**
- Rename to `packaging/linux/udev/70-opad.rules` (any number below 73 works).
- Update every reference:
  - `Makefile:106` (install), `Makefile:158` (user-install hint), `Makefile:168` (uninstall)
  - the `# 99-opad.rules` header comment inside the file
  - check `packaging/linux/deb`, `rpm`, `arch`, `appimage` for the filename too
- Fix the spec, which also has the wrong number and the old name: `docs/specs/packaging-distribution.md` lines 187, 441, 448 (`99-osupad.rules`) should be `70-opad.rules`.
- Keep the rule as is otherwise: `uaccess` only, no `MODE`/`GROUP`, PIDs narrowed to `4001|1001` (per L-2).

**Acceptance**
- After install and a replug, `getfacl /dev/ttyACM0` shows `user:<you>:rw-` with no group change and no relogin.
- `test -r /dev/ttyACM0 && test -w /dev/ttyACM0` succeeds and the daemon logs `Connected to OPad`.

**Quick manual check (no reinstall)**
`sudo setfacl -m u:$USER:rw /dev/ttyACM0` (lasts until the next replug).

## 2. Open failures are invisible

- `desktop/crates/opad-device/src/lib.rs:177` logs `Failed to open port` at `debug!`, but the service runs with `RUST_LOG=info`, so the user only sees the retry loop.
- Log the open error at `warn!`, but only when the error changes or once per plug-in, so the 1.5 s retry does not spam the journal.
- For `PermissionDenied`, say what to check (udev rule / `getfacl`), not just the raw error.
- The `info!("Opening OPad serial port ...")` line (line 166) also repeats every retry; log it once per attempt series.

## 3. tosu crashes on every launch

**What happens**
- The daemon logs `tosu exited with exit status: 1` and relaunches with backoff, forever.
- Running `/usr/lib/opad/tosu/tosu` by hand:
  `SyntaxError: Cannot use import statement outside a module` at `dist/index.js:1` (Node v18.19.1).

**Root cause**
- `dist/index.js` is an ES module, but there is no `package.json` with `"type": "module"` next to it and the file is not `.mjs`, so Node treats it as CommonJS.
- The `tosu` target in the `Makefile` (line ~66-82) copies `packages/tosu/dist/*` and writes a wrapper that runs `exec node .../dist/index.js`. It never creates a `package.json`.

**Fix**
- In the `tosu` target, write `{"type":"module"}` into `$(TOSU_BUILD_DIR)/dist/package.json` (or rename the entry point to `.mjs` and update the wrapper). Make sure the `install`, `install-user`, deb, rpm, appimage and PKGBUILD paths all ship it (the install steps use `cp -r $(TOSU_BUILD_DIR)/dist/*`, so a file in `dist/` is picked up).

**Also check (not verified yet)**
- Whether tosu 4.26.2 needs Node newer than 18. Upstream ships it as a packaged binary; we run it with the system `node`.
- Whether the deb/rpm/PKGBUILD declare a dependency on `nodejs` (and a minimum version). If not, add it.
- If tosu keeps failing, the daemon should log tosu's stderr; today only the exit status is visible.

**Acceptance**
- `/usr/lib/opad/tosu/tosu` starts and stays running.
- No `tosu exited` warnings in `journalctl --user -u opad-daemon`.

## 4. Own USB vendor/product ID (decision + follow-up)

Today the pad reports `303a:4001` (Espressif's vendor ID, a self-picked PID; `firmware/main/usb/usb_descriptors.c:27-28`). Options:

- **A. Own VID from the USB-IF (usb.org):** one-time fee, about $6,000 at last check (verify). Needed for the USB logo / commercial sale. Individual or company application, no technical test.
- **B. Free PID from pid.codes (VID `0x1209`):** for open-source hardware/firmware. Submit a PR to the pid.codes repo describing the project and license. Not for closed-source products. Leading candidate, since OPad is open source.
- **C. PID from Espressif under `303a`:** available for products built on their chips (check their current process).

Decision: **B (pid.codes, VID `0x1209`)**, chosen 2026-09-21. Revisit A only if the pad is sold commercially / needs the USB logo.

### pid.codes prerequisites (checked against http://pid.codes/howto/ on 2026-09-21)

- [x] Public source repository: `https://github.com/OPad-dev/OPad` is public.
- [x] Contains PCB design files and firmware/source: `hardware/pcb`, `firmware/`.
- [x] `LICENSE` file in the repo: MIT.
- [x] **License: keep a single MIT `LICENSE` for everything OPad wrote** (decided 2026-09-21). pid.codes wants hardware and software under recognised licenses; MIT is recognised. The README license section now says MIT covers the firmware, desktop app, PCB designs, enclosure CAD and docs, so the hardware is explicitly covered. A hardware-specific license (e.g. CERN-OHL-P-2.0 in `hardware/LICENSE`) is only a follow-up if the pid.codes reviewers ask for one.
- [ ] **Third-party files that are not MIT and must be replaced or removed before the PR / selling.** See section 5.
- [ ] Reserved ranges: `0x0000-0x0FFF` (tests/generic) and `0x1000-0x1FFF` (InterBiometrics) cannot be requested.

### Proposed ID

- **`1209:4F50`** (`4F 50` = ASCII "OP"). Checked against the pid.codes list on 2026-09-21: not taken. Re-check right before the PR; the first merged PR wins.
- Bootloader stays `303a:1001` (see the list below).

### Submission (PR to `pidcodes/pidcodes.github.com`, not sent yet)

Fork the repo, then add two files.

`org/OPad/index.md` (the directory name cannot contain spaces; the `OPad` org page returned 404 today, so it is free):

```
---
layout: org
title: OPad
site: https://github.com/OPad-dev/OPad
---
OPad is an open-source osu! keypad based on the ESP32-S3, with a desktop companion app.
```

`1209/4F50/index.md`:

```
---
layout: pid
title: OPad ESP32-S3
owner: OPad
license: MIT
site: https://github.com/OPad-dev/OPad
source: https://github.com/OPad-dev/OPad
---
Low-latency osu! keypad. ESP32-S3 running TinyUSB (HID keyboard + CDC serial), with Hall-effect and mechanical switch PCBs. Firmware, PCB designs and the desktop app are all in the linked repository.
```

`license: MIT` is correct as long as the third-party files above are resolved (the PR points reviewers at the repo, so the NC-licensed files would be visible to them).

Commit message suggestion: `Add OPad ESP32-S3 (1209:4F50)`. Wait for the PR to be merged **before** shipping firmware with the new ID, and keep the old `303a:4001` accepted by the daemon for one release so existing pads still connect.

### Order of work

1. Resolve the non-MIT files (section 5). The README license section is already updated.
2. Open the pid.codes PR, wait for merge.
3. Then do the coordinated change below.

Changing the ID is a breaking change, so do it in one coordinated step:
1. Firmware descriptor (`usb_descriptors.c`) and reflash.
2. `ESPRESSIF_VID` and `OSUPAD_APP_PID` in `desktop/crates/opad-device/src/lib.rs` (the daemon detects the pad by these). New firmware needs a new daemon and vice versa; consider accepting both IDs for one release.
3. udev rule (`ATTRS{idVendor}` / `ATTRS{idProduct}`), `docs/specs/packaging-distribution.md`, `docs/recovery.md`, `docs/windows-portability.md`, and the error strings in `desktop/crates/opad-device/src/flash.rs`.
4. The ROM bootloader stays `303a:1001` in download mode regardless (comes from the chip, not our firmware), so the bootloader detection and its udev entry keep the Espressif ID.
5. Windows: driver association is cached per VID/PID; re-verify the driverless install on a clean machine.
6. Optionally also check the manufacturer/product strings ("GFerreiroS" / "OPad ESP32-S3") as a second match.

## 5. Repo license audit: everything that is not OPad-owned MIT

Full audit of all 295 tracked files on 2026-09-21 (`git ls-files`), plus the 696 Rust dependencies (`cargo metadata`). Goal: the repo is 100% open source, modifiable and safe to sell from, with everything OPad wrote under MIT. Nothing has been changed or deleted yet.

**How to read this.** We can only put MIT on work we own. Third-party files keep their author's license; we cannot relicense them. For pid.codes (and for selling), what matters is that *every* file is under an open license and its notice is kept. Permissive non-MIT licenses (zlib, OFL, LGPL for tosu) are acceptable to pid.codes. NonCommercial or "no license" are not. Each item below says whether it blocks and what replaces it. A "strict all-MIT" alternative is given where one exists.

### Summary

| # | What | License today | Blocks pid.codes / selling? | Fix |
|---|---|---|---|---|
| 5.1 | kamehameha case STLs | CC BY-NC 4.0 | **Yes** | Remove |
| 5.2 | Easter-egg GIF in firmware | **Unknown** (internet meme GIF) | **Yes** | Replace with our own animation |
| 5.3 | Waveshare board STEP/PDF/DWG/PNG | **No license stated** | **Yes** unless Waveshare allows it | Remove, link to Waveshare |
| 5.4 | KiCad-derived footprints and symbols | CC-BY-SA 4.0 (KiCad library) | Share-alike, not MIT | Redraw ours, or keep with notice |
| 5.5 | nanopb (vendored C library) | zlib | No, but **its license file is missing** (zlib requires the notice) | Add `LICENSE.txt`, or stop vendoring |
| 5.6 | Montserrat fonts in the GUI | SIL OFL 1.1 | No (notice present) | Keep; add to package credits |
| 5.7 | milk-crate and clay53 reference models | MIT (third party) | No, but **their notice is missing** | Add their MIT notice, or remove |
| 5.8 | tosu (bundled at build, not in repo) | LGPL-3.0 | No (already handled) | Nothing, except the tosu fix in section 3 |
| 5.9 | Rust dependencies (not in repo, compiled in) | MIT/Apache/BSD/Zlib/MPL-2.0 etc. | No | Optional: ship a generated third-party notices file |

Everything else (firmware sources, board code, desktop crates, scripts, packaging, docs, PCB designs, production files, enclosure `.scad`/`.stl`, the icon SVG, the stroke font) was checked and is OPad's own work, so MIT.

### 5.1 Must go: CC BY-NC (not open source, forbids selling)

| File | Size | Origin and license | Action |
|---|---|---|---|
| `hardware/3d/reference_keypads/osu_case_top_kamehameha.stl` | 362 KB | Printables #943460 (kameHame HA), **CC BY-NC 4.0** | Remove from the repo, link to the Printables page instead |
| `hardware/3d/reference_keypads/osu_case_bottom_kamehameha.stl` | 162 KB | same | same |

CC BY-NC forbids commercial use, and NonCommercial licenses are not open source under the OSI/OSHW definitions. Nothing in the build uses them, so removal breaks nothing.

### 5.2 Must replace: easter-egg GIF (unknown origin)

| File | Details |
|---|---|
| `firmware/main/ui/easter_egg_gif.h` (98 KB) | A GIF embedded as a byte array: `// Generated from freaky_67_14f.gif (15656 bytes, 14 frames, 180x93)`. Added in `470a9d5`. The commit gives no source or license. |

A meme GIF from the internet is someone else's copyright with no license, so it cannot be MIT. It is also compiled into every firmware image, so it ships on sold pads.

Replace with an animation we make ourselves (drawn frames, or drawn with LVGL primitives at runtime, which also saves ~15 KB of flash). Keep the same size/frame format so `firmware/main/ui/easter_egg.c` does not change. Also check `scripts/trigger_easter_egg.py` and the desktop side (`TriggerEasterEgg`) only reference the name, not the image. If we know the exact creator and they grant a permissive license, keeping it with a credit is the alternative.

### 5.3 Must resolve: Waveshare files (no license stated)

| File | Size | Origin and license | Action |
|---|---|---|---|
| `hardware/3d/waveshare_board/esp32-s3-touch-lcd-2_20241108.stp` | 15 MB | Waveshare official STEP model, no license given in the repo | Check Waveshare's terms. If redistribution is not clearly allowed: remove and link to their wiki. If we still need a board model for the case, model our own simplified one (outline, holes, USB-C position; dimensions are already in `hardware/3d/README.md`) |
| `hardware/3d/waveshare_board/ESP32-S3-Touch-LCD-2-20241108.pdf` | 146 KB | Waveshare mechanical drawing | same |
| `hardware/3d/waveshare_board/ESP32-S3-Touch-LCD-2-20241108.dwg` | 927 KB | Waveshare CAD drawing | same |
| `hardware/3d/waveshare_board/dims-1.png` | 92 KB | Waveshare dimension image | same |

### 5.4 KiCad library copies: CC-BY-SA 4.0 (share-alike, not MIT)

The KiCad standard libraries are CC-BY-SA 4.0 with an exception: **boards and Gerbers made with them are not affected** (so `*.kicad_pcb`, `*.kicad_sch`, Gerbers, BOMs, STEP exports stay MIT). But the **library files themselves**, copied into our repo, stay CC-BY-SA 4.0.

KiCad-derived (by their `descr` text, the KiCad generator notes and `${KICAD10_3DMODEL_DIR}` model paths):

| File | Evidence |
|---|---|
| `hardware/pcb/V1/lib/osupad.pretty/C_0603_1608Metric.kicad_mod` | KiCad `Capacitor_SMD` footprint and model path |
| `.../R_0603_1608Metric.kicad_mod` | KiCad `Resistor_SMD`, IPC-7351 descr |
| `.../JST_SH_SM08B-SRSS-TB_1x08-1MP_P1.00mm_Horizontal.kicad_mod` | KiCad `Connector_JST` |
| `.../PinSocket_1x14_P2.54mm_Vertical.kicad_mod` | "from Kicad 4.0.7", `Connector_PinSocket_2.54mm` |
| `.../MountingHole_2.2mm_M2.kicad_mod` | "generated by kicad-footprint-generator" |
| `.../SOT-23.kicad_mod` | KiCad `Package_TO_SOT_SMD` name and descr style, probably edited (mentions DRV5055) |
| `hardware/pcb/V1/lib/osupad.kicad_sym` symbols `R`, `C`, `SW_Push`, `Conn_01x08`, `Conn_01x14`, `TestPoint` | KiCad `Device`/`Switch`/`Connector` symbols ("script generated (kicad-library-utils/schlib/autogen") |

Ours (MIT): `SW_MX_Hall_PlateMount_SolidCentre`, `TestPoint_Pad_1.0x1.0mm` (generator `"osupad"`), and very likely `Kailh_CPG151101S11_MX_Hotswap_Bottom`, `SW_MX_Hall_PlateMount` and the `DRV5055` symbol (custom descriptions). Confirm those three.

Options:
- **Strict all-MIT (recommended, small job):** redraw the six footprints and six symbols ourselves from the datasheets (0603 R/C, SOT-23, JST SH 8-pin, 1x14 socket, M2 hole; resistor, capacitor, push button, connectors, test point). They are simple parts. Keep the `${KICAD10_3DMODEL_DIR}` model *references* (a path, not a copy, so no license issue).
- **Or:** keep them and add `hardware/pcb/V1/lib/LICENSE-KiCad` (CC-BY-SA 4.0 + the KiCad exception text) and a line in the README. Open source and acceptable to pid.codes, just not MIT.

### 5.5 nanopb: zlib license, notice missing

| Files | Details |
|---|---|
| `firmware/main/protocol/nanopb/pb.h`, `pb_common.c/.h`, `pb_encode.c/.h`, `pb_decode.c/.h` | Vendored copy of nanopb (Petteri Aimonen), **zlib license**. The upstream `LICENSE.txt` was not copied. `pb_common.c` also contains a UTF-8 routine by Markus Kuhn ("Short code license", MIT-compatible). |
| `firmware/main/protocol/osupad.pb.c/.h` | Generated from our `protocol/osupad.proto` by nanopb 0.4.9.1. Generated output of our schema, so ours (MIT). |

zlib's condition 3 says the notice "may not be removed or altered from any source distribution", so today the repo technically violates it. Fix, pick one:
- **Keep vendored:** add nanopb's `LICENSE.txt` as `firmware/main/protocol/nanopb/LICENSE.txt` (zlib text, "Copyright (c) 2011 Petteri Aimonen"; copy the exact file from nanopb 0.4.9.1 upstream). zlib is permissive and OSI-approved; fine for pid.codes and selling.
- **Strict all-MIT in the repo:** stop vendoring and pull nanopb at build time (ESP-IDF component manager or a CMake `FetchContent` pinned to 0.4.9.1). The firmware binary still contains zlib code, which is allowed.

### 5.6 Montserrat fonts: SIL OFL 1.1 (fine, notice present)

| Files | Details |
|---|---|
| `desktop/gui/assets/fonts/Montserrat-Bold.ttf`, `Montserrat-Medium.ttf` | "Copyright 2011 The Montserrat Project Authors", SIL OFL 1.1. `Montserrat-OFL.txt` is present. Compiled into the GUI binary via `include_bytes!` (`desktop/gui/src/theme.rs:31-32`). |

OFL is a recognised open font license, allows commercial use and embedding. No change required. To do:
- Add Montserrat (OFL-1.1) to `packaging/linux/deb/copyright`, the PKGBUILD `license=()` array, `Cargo.toml` `license` in `desktop/gui` for the deb/rpm (`MIT AND LGPL-3.0-only AND OFL-1.1`), and the Windows installer's license files, since the fonts ship inside the binary.
- A strict all-MIT font does not realistically exist among good UI fonts (almost all open fonts are OFL). Keep OFL.
- Also: the firmware's LVGL build enables LVGL's built-in Montserrat bitmaps (`CONFIG_LV_FONT_MONTSERRAT_12/14/16` in `firmware/sdkconfig.defaults`). They come from the LVGL component (MIT), fetched at build time, not stored in our repo. Mention them in the firmware credits.

### 5.7 milk-crate and clay53 reference models: MIT, but not ours

| File | Origin |
|---|---|
| `hardware/3d/reference_keypads/milkcrate-plate-mount.step/.stl`, `milkcrate-pcb-mount.step/.stl` | somepin/milk-crate, MIT |
| `hardware/3d/reference_keypads/osu_keypad_clay53.FCStd` | clay53/Osu-Keypad, MIT |

These are MIT already, but with *their* copyright. MIT requires their copyright and license notice to stay with the files; today there is only a credit line. Either add each upstream `LICENSE` next to the files (e.g. `reference_keypads/LICENSE-milk-crate`, `LICENSE-osu-keypad`), or remove them: they are only reference material, nothing in the build uses them. Removing is simpler and makes `hardware/` 100% OPad-authored.

### 5.8 tosu (LGPL-3.0)

Not stored in the repo; built from upstream source at package time, with `licenses/tosu/{LICENSE,NOTICE,VERSION}` in the repo and shipped in every package, plus the `OSUPAD_TOSU_PATH` replacement option. This is already correct. It stays LGPL; it cannot be MIT. It is a separate program run as a subprocess, so it does not affect OPad's MIT license.

### 5.9 Rust dependencies (compiled into the desktop binaries, not in the repo)

696 crates. All permissive or dual-licensed with a permissive option: MIT / Apache-2.0 (the vast majority), BSD-3-Clause, Zlib, ISC, Unicode-3.0, CDLA-Permissive-2.0 (`webpki-roots`). `serialport` and `option-ext` are MPL-2.0 (file-level copyleft: fine as long as we do not modify their files; their source is on crates.io). The four crates listing GPL/LGPL (`r-efi`, `self_cell`, `unescaper`) are dual-licensed; we use them under their MIT/Apache option. No blocker.

Nice to have: generate a third-party notices file at release time (`cargo about` or `cargo-deny` with a license allowlist in CI) and ship it with the GUI (MIT/Apache require including their notices in binary distributions).

### Follow-ups when removing

- Update `hardware/3d/README.md`: the directory tree (lines 8-31), the "Option A" instructions (lines 57-58 reference `milkcrate-plate-mount.step` and the Waveshare STEP), and section 4 credits.
- `hardware/3d/custom_case/V1/osupad_enclosure.scad` has no imports, so the case build does not depend on any file above (checked). Still confirm the case design was not derived from the kamehameha STLs; if it was, it must be redrawn.
- **Git history:** deleting the files does not remove them from past commits, so the CC BY-NC files remain downloadable from history. Decide whether that is acceptable or whether to rewrite history (disruptive, changes every commit hash, needs a force-push). For a small project before the first public release, rewriting is cleanest.
- Repo weight: removing `waveshare_board` and the reference keypads would shrink the repo by about 23 MB.
- Once done, update the README license section: list only what remains third-party (tosu, Montserrat, nanopb if still vendored, KiCad library copies if kept).
- Suggested prevention: a `REUSE`-style check (`reuse lint`) or a CI job that fails on files without a known license, so new third-party files cannot slip in again.

### Minimum to be pid.codes-ready

1. 5.1 remove the CC BY-NC STLs.
2. 5.2 the GIF is kept (decision 2026-09-21); its license is still unresolved.
3. 5.3 remove the Waveshare files (or confirm Waveshare allows redistribution).
4. 5.5 add nanopb's `LICENSE.txt`, and 5.7 add or remove the reference models.
5. 5.4 redraw the KiCad-derived parts (for strict MIT) or add the CC-BY-SA notice.

## 6. Rebuild and retest

(Do the ID change in section 4 in the same rebuild only if the decision is made; otherwise keep `303a:4001` for now.)

1. `make deb` (rebuild `dist/opad_1.0.0-rc-1_amd64.deb`).
2. `sudo apt install ./dist/opad_*.deb`, replug the pad.
3. Check: ACL on `/dev/ttyACM0`, `Connected to OPad` in the daemon log, tosu running, GUI shows the pad.

## Notes

- The daemon detects the pad by USB ID `303a:4001` (`OSUPAD_APP_PID` in `desktop/crates/opad-device/src/lib.rs`), the value set in `firmware/main/usb/usb_descriptors.c:28`. `303a` is Espressif's vendor ID and `4001` is a custom PID chosen for OPad. It ignores the ROM bootloader (`303a:1001`) on purpose, because opening that port resets the chip out of download mode.
- Uncommitted change in the working tree, unrelated to the above: `desktop/daemon/src/ipc_handlers.rs` (`device_manager` to `device` in `TriggerEasterEgg`).

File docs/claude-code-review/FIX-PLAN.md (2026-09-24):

# Fix plan for the 2026-09-23 review findings

All 93 findings in this folder, assigned to exactly one executor, grouped into
clusters that share files, and ordered so later clusters build on earlier ones.

Finding IDs used below:

| Prefix | Findings file |
| --- | --- |
| FP | [2026-09-23-firmware-protocol.md](2026-09-23-firmware-protocol.md) |
| FU | [2026-09-23-firmware-usb-input-config.md](2026-09-23-firmware-usb-input-config.md) |
| FI | [2026-09-23-firmware-ui.md](2026-09-23-firmware-ui.md) |
| FB | [2026-09-23-firmware-test-boards.md](2026-09-23-firmware-test-boards.md) |
| DD | [2026-09-23-desktop-opad-protocol-device-ipc.md](2026-09-23-desktop-opad-protocol-device-ipc.md) |
| DU | [2026-09-23-desktop-opad-update.md](2026-09-23-desktop-opad-update.md) |
| DM | [2026-09-23-desktop-model-layout-storage-tosu-preview.md](2026-09-23-desktop-model-layout-storage-tosu-preview.md) |
| DA | [2026-09-23-desktop-daemon.md](2026-09-23-desktop-daemon.md) |
| DG | [2026-09-23-desktop-gui.md](2026-09-23-desktop-gui.md) |
| DC | [2026-09-23-desktop-cli.md](2026-09-23-desktop-cli.md) |
| PK | [2026-09-23-packaging-scripts-ci-protocol.md](2026-09-23-packaging-scripts-ci-protocol.md) |

`FP#3` means finding 3 in the firmware-protocol file.

## Executors and split

| Executor | Items | Why |
| --- | --- | --- |
| **Claude Opus** | 27 | Concurrency, protocol framing, cross-component state (foreign-pad, sync, device worker). Mistakes here brick pads or corrupt counters. |
| **Claude Sonnet** | 42 | Real correctness bugs with a clear spec, contained in one or two files. |
| **Claude Haiku** | 8 | One-to-five-line mechanical edits with no design decision. |
| **Antigravity** | 16 | Refactors/dedup/efficiency and packaging/CI scripts: mechanical but larger edits, no Anthropic budget spent. |

Coverage check: 27 + 42 + 8 + 16 = 93. Every finding appears in exactly one checklist.

## Run order

Sessions must be **sequential on the same files**; do not run two executors on
firmware at the same time. Antigravity can run in parallel on desktop/packaging
while Claude works on firmware (and vice-versa), *except* where a dependency is
noted.

1. **Phase 0 – Haiku**, one session, all 8 items (cheap, unblocks nothing but gets them out of the way).
2. **Phase 1 – Opus firmware** O1–O6.
3. **Phase 2 – Sonnet firmware** S1–S4.
4. **Phase 3 – Opus desktop** O7–O11.
5. **Phase 4 – Sonnet desktop** S5–S13.
6. **Phase 5 – Antigravity** A1–A9 (A9 packaging can start any time; A4 must wait for O9; A7 must wait for S9).
7. **Phase 6 – Opus optional** O12 only if budget remains.

## Rules for every session (Claude or Antigravity)

Paste these into the session along with the checklist for its tier.

1. Work only on your tier's checklist. When every item on it is `done` or `invalid`, **stop, print a summary (items fixed / marked invalid / skipped and why), and wait**. Do not start items from another tier.
2. Before fixing a finding, **verify it against the code**. If it does not reproduce or the premise is wrong, mark it `invalid` in its findings file with a one-line reason and move on. Do not "fix" something that is not broken.
3. Update the finding's status marker in its findings file (`open` → `fixed` / `invalid` / `wontfix`) as part of the same commit.
4. One commit per cluster (O1, S3, ...), message in the repo's conventional style (`fix(protocol): ...`, `fix(daemon): ...`). Author is GFerreiroS <info@gferreiro.com> only. **No `Co-Authored-By` or other trailers.**
5. **Protocol compatibility:** app and pad are updated independently. Any change touching serial framing, protobuf messages or their handling must keep working old-app↔new-pad **and** new-app↔old-pad.
6. **Firmware builds:** `make firmware` (runs `idf.py -C firmware build`). If you edit `firmware/sdkconfig.defaults`, delete `firmware/sdkconfig` first. Host unit tests: `./firmware/test/host/run_tests.sh` (gcc, `-Wall -Wextra -Werror`).
7. **Desktop checks:** `make check` (cargo fmt --check, clippy `-D warnings`, cargo test, firmware host tests). Must pass before committing.
8. Windows-only items (marked 🪟) need a run on the Windows test VM (see `docs/windows-portability.md`). If the VM is not available, implement, run `cargo check --target x86_64-pc-windows-gnu` if the target is installed, mark the item `fixed (untested on Windows)` and say so in the summary.
9. Stay in scope: fix the finding, add/adjust the test that covers it, nothing else. No drive-by refactors — those belong to Antigravity's list.
10. If a fix needs a decision the finding does not settle (e.g. which IPC field name), pick the option the finding suggests; if it suggests none, stop and ask.
11. **Budget stop (Claude only):** if `/cost` shows the session above the cap given at kickoff, finish the current item, commit, and stop with a summary.

---

## Claude Opus checklist (27 findings, 12 clusters)

Kickoff prompt:

> Read `docs/claude-code-review/FIX-PLAN.md`, follow "Rules for every session", and work through the **Opus checklist** in order, phase 1 (O1–O6) first. Budget cap for this session: $__.

### O1 — Firmware framing lock ▸ FP#1, FP#2
Files: `firmware/main/protocol/frame_parser.c/.h`, `firmware/main/protocol/protocol.c`, `firmware/test/host/test_frame_parser.c`
- [x] Add an "accepted framing" parameter to the parser (`ANY` / `LEGACY` / `MARKED`). While `ANY`, current behaviour. Once locked, headers of the other framing are **not** recognised; resync slides past them.
- [x] In `protocol.c`, latch `s_host_framing` **once per connection**: on the first frame whose payload decodes as a valid `HostMessage` with a recognised `which_payload` (Hello preferred). Never re-latch. Clear only in `protocol_reset_rx` (DTR drop / port reopen).
- [x] Pass `s_host_framing_known ? s_host_framing : ANY` into the parser on every feed.
- [x] Compat: an old (legacy-only) app must still connect and a new app talking marked must still connect; a mid-stream flip is the only thing removed. Reason through both directions in the commit message.
- [x] Host tests: extend `test_frame_parser.c` with (a) locked-to-marked ignores a false legacy header inside a payload, (b) locked-to-legacy ignores `AA 55 00 00`, (c) `ANY` still accepts both.
- Verify: host tests, `make firmware`, then real pad with the current desktop app for a full map (DataUpdate stream).

### O2 — `detect_pin` and key-GPIO ownership ▸ FP#3, FB#2, FU#7
Files: `firmware/main/protocol/protocol.c` (~551), `firmware/main/input/keypad.c` (~223, ~504), `firmware/boards/waveshare_esp32s3_touch_lcd_2/board.c` (~19)
- [x] Clamp `DetectPinRequest.timeout_ms` (suggest `≤ 30000`, `0` → default).
- [x] The pin scan must not run on the CDC task: move `keypad_detect_pressed_pin` execution into the keypad task (request/response via the existing staging mechanism or a small queue), so `board_keys_set_gpio` has a **single owning task** as its header requires. The CDC task only enqueues and later sends `DetectPinResult`. Keep RX serviced meanwhile.
- [x] In `keypad.c` staged-config apply: commit `s_config = applied` only **after** `board_keys_set_gpio` succeeds; on failure keep the previous config, re-arm the previous pins, log + `diag_record`.
- [x] Same for the `keypad_init` fallback path (FU#7 mentions line ~270): whatever pins are actually armed must be what `keypad_get_config` reports.
- Verify: `make firmware`; on the pad: detect_pin from the app while sending HostStatus (protocol must stay responsive); detect → apply config sequence; deliberately invalid pin to exercise the failure path.

### O3 — HID report pending races ▸ FU#2, FU#6
Files: `firmware/main/usb/usb_hid.c` (~89, ~110)
- [x] `usb_hid_set_touch_retry` must not blindly clear `s_report_pending`. Use the same CAS/exchange discipline as the keypad path: only clear a pending flag that this call itself observed and satisfied, or make the submit path a single helper both callers use (`try_submit_or_mark_pending`).
- [x] `s_pending_edge_us`: only arm it if `s_report_pending` is still `true` after the failed submit (re-check with an atomic load / CAS on the pending flag); if `complete_cb` already delivered, drop the edge instead of leaking it into the next report.
- [x] Document the ownership: which tasks/cores touch `s_report_pending`, `s_pending_edge_us`, `s_key*_pressed`.
- Verify: `make firmware`; bench with `scripts/bench_latency.sh` for outliers; play a map with touch retry active, watch for stuck/missed keys and latency outliers in diag.

### O4 — Keycode/config application path ▸ FU#3, FU#4, FU#5
Files: `firmware/main/input/keypad.c` (~292), `firmware/main/config/device_config.c` (~128), `firmware/main/app_main.c` (~101, ~194)
- [x] `keypad_set_input_enabled(false)` must also stop `keypad_task` from reporting sampled levels: when disabled, force reported state = released (send one release report if anything was down) and skip steps 2/3 re-reads. HE module must never produce a held key.
- [x] Remove the direct `usb_hid_set_keycodes` call from `device_config_apply` (and the redundant one at `app_main.c:~101`); keycodes are applied **only** by the keypad task's staged apply.
- [x] `app_main.c:~194`: re-read the current config with `device_config_get()` before applying, or apply only brightness/sleep there. Do not push the stale snapshot.
- Verify: `make firmware`; pad with HE module → no key reports; change key1 while holding key1 from the app → no phantom press/release; connect app during boot and push config → pad keeps the new config.

### O5 — `ui_store` shared state and dirty-bit ▸ FI#4, FI#5
Files: `firmware/main/ui/ui_store.c/.h`, `firmware/main/runtime/runtime.c` (~49, ~54)
- [x] Protect `s_pending_layouts[]`, `s_dirty_save_mask`, `s_dirty_erase_mask` with a mutex (FreeRTOS semaphore) or make the masks atomic **and** copy the pending layout under the same lock. Protocol task (core 0) and runtime task (core 1) both touch them.
- [x] `ui_store_flush_dirty`: clear a dirty bit **only after** its save/erase succeeded; on failure keep the bit (retry next flush) and `diag_record` the error. Have `runtime.c` log the returned error instead of discarding it.
- Verify: `make firmware`; push a layout during gameplay, finish the map, reboot → layout persists. Host test if `ui_store` logic can be split out; otherwise pad test.

### O6 — Headless-mode UI guards ▸ FI#1, FI#6
Files: `firmware/main/protocol/protocol.c` (~522), `firmware/main/ui/ui.h` (~30), `firmware/main/ui/ui_port.c` (~229, ~338)
- [x] `protocol.c` data_update source 67 → call `ui_trigger_easter_egg()` (which has the `s_ui_ok` guard), not `easter_egg_trigger()`.
- [x] Make `ui_lock()` return `bool` (false when `!s_ui_ok`) and have every caller skip the LVGL work when it returns false; or audit every `ui_lock()` caller and guard each. Pick one and apply consistently.
- [x] `ui_init`: if `s_screens[UI_SCREEN_IDLE] == NULL` after `rebuild_screen`, return `ESP_ERR_NO_MEM` (headless fallback) instead of `lv_screen_load(NULL)`.
- Verify: `make firmware`; force headless (disconnect LCD or stub `board_display_init` to fail) and send the easter-egg trigger (`scripts/trigger_easter_egg.py`) → no panic.

### O7 — Daemon foreign-pad guards ▸ DA#1, DA#2, DA#4, DA#6
Files: `desktop/daemon/src/runtime.rs` (~438, ~625), `desktop/daemon/src/ipc_handlers.rs` (~374, ~708), `desktop/daemon/src/firmware_update.rs` (~208), `desktop/daemon/src/sync.rs`, `desktop/crates/opad-ipc/src/lib.rs` (Status response)
- [x] Introduce one predicate (e.g. `DaemonState::may_touch_pad()` = `!foreign_pad && pending_takeover.is_none() && pending_replacement.is_none()`) and use it everywhere a sync/push is triggered: the COOLDOWN→SYNC `TriggerSync` in `runtime.rs`, `ForceSync`, `UpdateConfig`, `SetLayout`/`ResetLayout`, `ResetCounters`, `RestoreDeviceFromPc`, `ImportPcFromDevice`, `ImportBackup`, and `firmware_update::install`'s pre-sync. Handlers return a clear error (`Error("Pad belongs to another install; resolve the takeover prompt first")`).
- [x] Add `foreign_pad: bool` to `IpcResponse::Status` so GUI/CLI can gate. IPC change → bump `IPC_PROTOCOL_VERSION` only if the wire format is not backward compatible under the current serde settings; check how unknown/missing fields are handled and state the decision in the commit.
- [x] After a successful takeover (`ipc_handlers.rs:~708`), also push the custom layouts that `DeviceConnected` suppressed (mirror the `SendLayout` loop at `runtime.rs:~438`).
- [x] `firmware_update::install`: re-check `mode == IDLE` (and `may_touch_pad()`) **immediately before** `pause_and_release`/flash, after the download and stage complete; abort with an error if the user started playing.
- Verify: `make check`; unit tests for the predicate on the runtime state machine; manual: foreign pad + play a map → no sync; "leave it alone" then ForceSync → refused.

### O8 — Daemon connect/sync correctness ▸ DA#3, DA#5
Files: `desktop/daemon/src/runtime.rs` (~303–345), `desktop/daemon/src/sync.rs` (~340)
- [x] `DeviceConnected`: perform the `protocol_version` check **first**. For an incompatible pad: do not set `device_connected`, do not adopt/save its config, do not set `counters_source`; set an `incompatible_device` marker (already exists for the CLI message) and return. `Tick` must not send `RequestDeviceStatus`/`HostStatus`/`TriggerSync` to it.
- [x] `perform_sync` failure path: do not overwrite `st.counters` with the rejected reconciled values. Leave the in-memory counters as the pad reported them (or restore the pre-sync snapshot), keep `esp_counters`/`counters_source` consistent, and make the failure `SyncCompleted` carry the unchanged counters.
- Verify: `make check`; add a unit test feeding a `protocol_version = 2` `DeviceConnected` through `apply_event` and asserting no `SaveDeviceConfig` effect; sync-failure test asserting counters unchanged.

### O9 — `opad-device` serial worker re-Hello ▸ DD#2, DD#3
Files: `desktop/crates/opad-device/src/lib.rs` (~283–363)
- [x] After the connection is established (`is_connected == true`), do **not** gate frame dispatch on `has_hello_ack`; only the pre-connection state drops non-HelloAck frames. A re-Hello re-confirms framing but must not discard `CounterSyncResp`/`ConfigAck`/`LayoutAck` in flight.
- [x] Apply the `HELLOS_BEFORE_REOPEN` reopen/DTR-drop fallback regardless of `framing.is_some()`. If a re-Hello goes unanswered N times: reopen the port; if still unanswered: emit `Disconnected` so daemon/GUI stop showing "connected" with frozen counters.
- Verify: `make check`; existing worker tests; manual: with the pad connected, trigger `rehandshake()` during a sync (or simulate lag) and confirm the sync completes; unplug/replug and desync scenarios.

### O10 — 🪟 Windows pipe accept + bootloader port pick ▸ DD#5, DD#6
Files: `desktop/crates/opad-ipc/src/transport/windows.rs` (~105), `desktop/crates/opad-device/src/flash.rs` (~148)
- [x] `IpcListener::accept`: after `connect()` succeeds, return the connected `server` **even if** creating the replacement instance fails (log it; create lazily on the next `accept`). In the `connect()` error/cancel path, ensure `next` is repopulated so the pipe name always has a listening instance.
- [x] `enter_bootloader`: after a trigger fires and `pick` misses within the window, before running the next trigger's `wait_until_openable(app_port)`, re-check `bootloader_ports()` for the pad; if found, return it. Never let `PortBusy(app_port)` overwrite a `NoBootloader`-class error when the app port has vanished (prefer the more specific error).
- Verify: `make check`; cross-check `cargo check --target x86_64-pc-windows-gnu`; on the Windows VM: rapid GUI reconnects; first flash with slow driver install (or simulate by extending the window).

### O11 — tosu supervisor pause/resume ▸ DM#1, DM#4
Files: `desktop/crates/opad-tosu/src/lib.rs` (~435, ~541)
- [x] `pause()` must await the child actually exiting: replace `drop(child)` with `child.kill().await` + `child.wait().await`, and signal completion with a `tokio::sync::Notify`/`watch` that `pause()` awaits (with a bounded timeout as a last resort, logged). Handle the "mid-`launch_tosu`" window: re-check `paused` after spawn and kill immediately if set.
- [x] A stop caused by `paused` is not a crash: do not increase the backoff, and reset backoff on `resume()`.
- Verify: `make check`; add a test with a fake child (e.g. `sleep`) asserting `pause()` returns only after the pid is gone and that `resume()` relaunches promptly. Manual: run an app update with tosu running on Linux; Windows VM if available.

### O12 — (optional, last) `apply_event` state cloning ▸ DA#9
Files: `desktop/daemon/src/runtime.rs` (~799)
- [x] Only if budget remains after phases 1–5. Remove the full `DaemonState` clone per event: let the controller borrow the state under the lock, or copy only the fields IPC handlers may write. Behaviour-preserving; existing daemon tests must pass unchanged.

---

## Claude Sonnet checklist (42 findings, 13 clusters)

Kickoff prompt:

> Read `docs/claude-code-review/FIX-PLAN.md`, follow "Rules for every session", and work through the **Sonnet checklist** in order. Phase 2 (S1–S4) only after Opus phase 1 is committed; phase 4 (S5–S13) only after Opus phase 3 is committed. Budget cap for this session: $__.

### S1 — Key-GPIO allow-list and debounce bounds ▸ FU#1, FU#8
Files: `firmware/main/input/keypad.c` (`SCAN_PINS`, ~433), `firmware/main/config/config_validate.c` (~8, ~15), `firmware/main/input/debounce.h`, `firmware/test/host/test_config.c`
- [x] Remove GPIO8 (module-ID ADC divider, see `board.c:~212`) from both `SCAN_PINS` and `KEY_GPIO_ALLOWED`.
- [x] Replace the two lists with **one** shared, host-safe array (e.g. `config_validate.h` exporting `const uint8_t KEY_GPIO_ALLOWED[]` + count) used by `keypad.c` for scanning and by `config_validate.c` for validation. Apply the `CONFIG_OSUPAD_BENCH_DEBUG_GPIO` exclusion in that single place.
- [x] Delete the redefined `DEBOUNCE_MIN_US`/`DEBOUNCE_MAX_US` in `config_validate.c`; include `input/debounce.h`.
- [x] Extend `test_config.c`: GPIO8 rejected; debug GPIO rejected when configured; all listed pins accepted.
- Verify: host tests, `make firmware`. Coordinate: O2 also edits `keypad.c` — rebase on it.

### S2 — Frame parser resync + protocol hygiene ▸ FP#4, FP#5, FP#6, FP#7
Files: `firmware/main/protocol/frame_parser.c`, `firmware/main/protocol/protocol.c` (~362, ~579–605), `firmware/test/host/test_frame_parser.c`
- [x] Resync: scan with a head index (or `memchr` for `0xAA` / `00 00` pairs) and compact **once** after the loop instead of `drop_front(parser, 1)` per byte. Same accept/reject results as before (O1's locked-framing rules included) — the tests from O1 must still pass. Add a test feeding 8 KB of junk and asserting the parser resyncs on the frame that follows.
- [x] Report resync: expose `resync_bytes` deltas and record them (e.g. `DIAG_EVENT_FRAME_TOO_LARGE` with `arg1`, or a new `DIAG_EVENT_FRAME_RESYNC`). Firmware only; no protocol change.
- [x] Single `static void expire_stale_partial(int64_t now)` holding the `RX_STALE_US` check, reset, log and diag; call it from both `protocol_feed_cdc_bytes` and `protocol_rx_idle`.
- [x] `layout_from_proto`: out-of-range `flags` → clamp to a **rejected** value (e.g. `UINT8_MAX` if the validator rejects it, otherwise reject the frame explicitly), consistent with the neighbouring `w`/`h` handling (fix those too if they clamp to 0).
- Verify: host tests, `make firmware`, send an oversized/junk stream to the pad and confirm the diag event appears in `opadctl`.

### S3 — Brightness/sleep ownership ▸ FI#2, FB#1
Files: `firmware/main/ui/ui_port.c` (~117, sleep/wake path), `firmware/boards/waveshare_esp32s3_touch_lcd_2/board_display.c` (~42), `firmware/main/config/device_config.c` (~131)
- [x] Make `ui_port`'s `s_brightness` the single source of truth. On wake, call `board_display_set_brightness(s_brightness)` (not the board's stale private copy).
- [x] `device_config_apply` must **not** call `board_backlight_set` directly; route brightness through `ui_set_brightness`.
- [x] `ui_set_brightness` must not read `s_asleep` unlocked from the protocol task: either take the LVGL lock, or set a "brightness changed" flag that `pad_timer_cb` applies on the LVGL task.
- Verify: `make firmware`; sleep the display, change brightness from the app, wake by key → new brightness; no backlight flash over a `disp_off` panel.

### S4 — UI small correctness ▸ FI#3, FI#8
Files: `firmware/main/ui/ui_port.c` (~87), `firmware/main/ui/ui_store.c` (~126)
- [x] KPS ring: compute `total - oldest` as signed and clamp at 0; reset the ring when `total < oldest` (counter rebase/reset); track fill count instead of using 0 as "unfilled".
- [x] `ui_store_erase`: when `nvs_erase_key` returns `ESP_ERR_NVS_NOT_FOUND`, return `ESP_OK` without `nvs_commit` and without `counters_record_nvs_write()`.
- Verify: `make firmware`; force-restore counters to a lower value while KPS shows → no `2147483647`; "Reset to default" twice → NVS write counter increments once.

### S5 — `opad-device` platform bugs ▸ DD#1, DD#4, DD#7
Files: `desktop/crates/opad-device/src/lib.rs` (~268, ~291, ~296, ~1086), `desktop/crates/opad-ipc/src/transport/unix.rs` (~14)
- [x] 🪟 Replace every `Instant::now() - Duration::from_secs(10)` with `Option<Instant>` (`None` = "send Hello now") or `checked_sub`. Grep for other `Instant - Duration` in the crate.
- [x] `locate_pad`: try `serial.and_then(|s| s.strip_prefix("OSUPAD-"))`, then fall back to `device_id` when that yields None (not only when serial is absent).
- [x] `get_socket_path`: `std::env::var("XDG_RUNTIME_DIR").ok().filter(|v| !v.is_empty())`.
- Verify: `make check`; unit tests for `locate_pad` with a non-OSUPAD serial and for the empty-var case.

### S6 — Updater correctness ▸ DU#1, DU#2, DU#3, DU#4, DU#5, DU#6, DU#8
Files: `desktop/crates/opad-update/src/{client.rs, tosu.rs, version.rs, download.rs, bin/opad-manifest.rs}`, `desktop/daemon/src/updater.rs`, `desktop/daemon/src/backup.rs`
- [x] `fetch_manifest`: send `If-None-Match` only when the caller holds a cached manifest (pass `Option<&ReleaseManifest>` or a `have_cached: bool`); on daemon start with no manifest in memory, do a full fetch. Alternatively clear `schedule.etag` when the manifest is not held — pick one and test the restart path.
- [x] `tosu::install`: write VERSION/NOTICE **after** `install_to` succeeds (or roll them back on Err). Fix the doc comment.
- [x] `opad-manifest` `app_artifact()`: add `.AppImage` (case-insensitive) → (`linux-x86_64`, `ArtifactKind::Binary`) + unit test.
- [x] `fetch_artifact`: hash the in-memory bytes (`sha256_bytes`) — add a bytes variant of `check_hash`; delete `tempdir_for_check` and the temp-file round trip.
- [x] `tosu::plan`: use `is_newer` (normalise a leading `v` on both sides) — never downgrade, never reinstall on a cosmetic mismatch.
- [x] `version.rs`: semver-correct pre-release compare — split on `.`, numeric identifiers numerically, alphanumeric lexically, numeric < alphanumeric; strip `+build` before comparing. Tests: `rc10 > rc9`, `rc.10 > rc.9`, `1.0.0+build == 1.0.0` for ordering, release > pre-release.
- [x] Extract `write_atomic(target, bytes)` in `download.rs` (temp + fsync + rename + dir sync); `stage_bytes` and `daemon/src/backup.rs` call it; use it for VERSION/NOTICE.
- Verify: `make check`; targeted unit tests for each bullet.

### S7 — Daemon updater/reset leftovers ▸ DA#7, DA#8
Files: `desktop/daemon/src/updater.rs` (~343, ~390), `desktop/daemon/src/ipc_handlers.rs` (~430), `desktop/daemon/src/sync.rs`
- [x] AppImage self-replace: on `rename` failing with `EXDEV`, fall back to copy + set permissions + rename within the target dir; don't delete the staged file until the replacement succeeded.
- [x] Run the package-manager `Command` via `tokio::process::Command` (or `spawn_blocking`) so a polkit prompt does not pin a runtime worker.
- [x] `pending_device_push`: either delete the field and its two writes, or have `perform_sync` honour it with `force_restore = true`. Prefer honouring it (the reset is user intent); add a test that a `ResetCounters` while disconnected survives the next connect.
- Verify: `make check`.

### S8 — Model/tosu correctness ▸ DM#2, DM#5, DM#7
Files: `desktop/crates/opad-model/src/lib.rs` (~428–451), `desktop/crates/opad-tosu/src/lib.rs` (~268, ~460)
- [x] `JsonBackup::validate`: build the `DeviceConfig` and delegate to `DeviceConfig::validate()`; remove the duplicated range checks. Test: `"0x00"` key rejected.
- [x] `find_tosu_binary`: if `$OPAD_TOSU_PATH` is set but missing, log a warning naming the bad path and fall through to PATH/bundled candidates.
- [x] `strip_ansi`: proper CSI (`ESC [` … final byte `0x40..=0x7E`) and OSC (`ESC ]` … `BEL` or `ESC \`) handling. Tests with chalk/ora-style sequences.
- Verify: `make check`.

### S9 — GUI main/designer bugs ▸ DG#1, DG#2, DG#4, DG#5, DG#7
Files: `desktop/gui/src/main.rs` (~476, ~791, ~1472, ~1493, ~2597), `desktop/gui/src/designer/mod.rs` (~380)
- [x] `ShowRequested`: handle `"logs"` and `"diagnostics"` tokens (and any other `Page` variant `parse_page_arg` can produce — derive the mapping from one table used by both sides).
- [x] Separate the local log counter from the daemon fetch cursor: `latest_log_seq` advances **only** from the daemon's returned `latest_seq`/last entry; local `log_event` uses its own counter.
- [x] `ImportCompleted`: copy `gameplay_display_hz` too; audit for any other field missing versus the adopt path (make both use one `fn adopt_config(&mut self, &DeviceConfig)`).
- [x] Designer `Apply`: carry `(screen, layout)` through `apply_layout` into `Message::Applied` and mark exactly that pair.
- [x] `CloseRequested`: while `tray_available == None`, hide to tray (or defer the close until the probe resolves) instead of exiting.
- Verify: `make check`; run the GUI (`cargo run -p opad-gui`), test each scenario in its finding.

### S10 — GUI tray + single instance ▸ DG#3, DG#6, DG#8
Files: `desktop/gui/src/tray.rs` (~328), `desktop/gui/src/single_instance.rs` (~34, ~133)
- [x] Tray: retry the `StatusNotifierWatcher` probe (e.g. every 5 s for the first minute, then every 30 s) or skip the pre-check and let ksni handle late registration; emit `Available` when it appears so the window can hide.
- [x] 🪟 Windows: create the first pipe instance synchronously in `claim()` (before iced starts) so a second launch always finds a listener; surface the error instead of `if let Ok` swallowing it.
- [x] Unix: bind first; only `remove_file` when `connect` fails with `ECONNREFUSED` (stale socket). Test with two near-simultaneous launches.
- Verify: `make check`; manual on Linux; Windows VM for the pipe.

### S11 — CLI monitor/status correctness ▸ DC#1, DC#10, DC#4, DC#5, DC#6, DC#7
Files: `desktop/cli/src/main.rs` (~227, ~435, ~465, ~477, ~478, ~527), `desktop/crates/opad-ipc/src/lib.rs` (`GetLogEntries`), `desktop/daemon/src/ipc_handlers.rs`
- [x] `monitor --follow`: advance `since_seq` from the last **received** entry's seq (`entries.last()`), never from `latest_seq`; drop the `latest_seq > 0` guard. Fixes both DC#1 and DC#10.
- [x] `--level`/`--source`: derive `clap::ValueEnum` on `LogLevel`/`LogSource` (in `opad-model`) so invalid values error out.
- [x] Filtering: add optional `level`/`source` filters to `GetLogEntries` so the daemon filters before applying `limit`; CLI passes them through. Keep the request backward compatible (optional fields).
- [x] Post-flash verification failure: same exit status with and without daemon — return an error in both branches.
- [x] Incompatibility message: report the device-protocol version the daemon expects (add it to `IncompatibleDevice` or a shared constant in `opad-protocol`), not `IPC_PROTOCOL_VERSION`.
- Verify: `make check`; `opadctl monitor --follow` through a pad connect burst; `--level err` errors out.

### S12 — Flash flow resume ▸ DC#2, DC#3
Files: `desktop/cli/src/main.rs` (~509, ~554), `desktop/daemon/src/ipc_handlers.rs` (~1023–1040), `desktop/daemon/src/main.rs` (connection lifecycle), `desktop/crates/opad-ipc/src/lib.rs`
- [x] Add an IPC request `ResumeDevice` (resume without waiting for reconnect). `opadctl bootloader` uses it instead of `FinishFlash`; a failed `opadctl flash` also uses it before surfacing the flash error.
- [x] Daemon: track which IPC connection sent `PrepareFlash`; if that connection drops before `FinishFlash`/`ResumeDevice`, call `resume()` automatically and log it.
- [x] CLI: `tokio::signal::ctrl_c` guard around the flash so Ctrl-C sends `ResumeDevice` before exiting.
- Verify: `make check`; `opadctl bootloader` returns immediately; Ctrl-C during `opadctl flash` → `opadctl status` shows the pad reconnecting.

### S13 — Release manifest signing ▸ PK#1
Files: `scripts/release/build_release.sh` (~17, ~128), `.github/workflows/release.yml`, `scripts/release/build_packages.sh`
- [x] The manifest must be generated and signed over the **exact artifacts that are published**. Restructure so `build_release.sh` (or a new `sign_release.sh`) takes an existing `dist/` (the zigbuild outputs + packages) and never `rm -rf dist` before signing; the workflow runs build → packages → manifest+sign → publish in that order on the same files.
- [x] Add a CI assertion that every artifact listed in the manifest exists in the upload set with a matching sha256.
- Verify: run the script locally against a `dist/` populated by `make packages`; `opad-manifest` verify step passes; dry-run the workflow with `act` if available, otherwise reason through it in the commit message.

---

## Claude Haiku checklist (8 findings)

Kickoff prompt:

> Read `docs/claude-code-review/FIX-PLAN.md`, follow "Rules for every session", and do the **Haiku checklist**. Each item is a small mechanical edit; do not change behaviour beyond what is listed. One commit for all items is fine (`chore: small review cleanups`). Budget cap for this session: $__.

- [x] **H1 ▸ FP#8** `firmware/main/protocol/protocol.c:~36` — remove `volatile` from `s_host_framing_known` / `s_host_framing`; add a comment that protocol state is owned by the CDC task. Verify `make firmware`.
- [x] **H2 ▸ DD#10** `desktop/crates/opad-ipc/Cargo.toml:~17`, `src/lib.rs:~22` — remove unused `bytes` and `byteorder` deps and the `MAX_IPC_FRAME_SIZE` alias (confirm zero references with grep first). Verify `make check`.
- [x] **H3 ▸ DU#7** `desktop/crates/opad-update/src/http.rs:~43` — after `send()`, assert `resp.url().scheme() == "https"` and return an error otherwise, so the comment becomes true. Verify `make check`.
- [x] **H4 ▸ DM#3** `desktop/crates/opad-model/src/log.rs` — `Display` impls for `LogSource`/`LogLevel` use `f.pad(..)` instead of `write!`. Add a test `format!("[{:<7}]", LogSource::Tosu) == "[TOSU   ]"`. Verify `make check`.
- [x] **H5 ▸ PK#2** `packaging/linux/appimage/AppRun:~6` — `LD_LIBRARY_PATH="...${LD_LIBRARY_PATH:+:$LD_LIBRARY_PATH}"`. Verify with `shellcheck` if available and by `LD_LIBRARY_PATH= sh -x AppRun` showing no trailing colon.
- [x] **H6 ▸ FI#10** `firmware/main/ui/easter_egg.c:~29, ~73–74, ~119–120`, `firmware/main/ui/core/ui_screen.c:~243` — delete `easter_egg_is_active()` (confirm no callers), drop `lv_obj_set_user_data(count, card)`, keep a single opa setter. Verify `make firmware`.
- [x] **H7 ▸ DM#6** `desktop/crates/opad-ui-preview/build.rs:~54, ~97` — move the `rerun-if-changed` for `firmware/main/ui/core` above the stub early-return. Verify `cargo build -p opad-ui-preview` twice after touching `ui_ids.h` rebuilds.
- [x] **H8 ▸ DM#9** `desktop/crates/opad-model/src/paths.rs:~97` — `install_lib_dir()` composes `install_prefix()`: `let prefix = install_prefix()?; Ok(if cfg!(windows) { prefix } else { prefix.join("lib").join("opad") })`. Existing test `the_install_lib_dir_sits_under_the_prefix` must pass. Verify `make check`.

---

## Antigravity checklist (16 findings, 9 clusters)

Kickoff prompt (paste into Antigravity):

> This repo has a code-review fix plan at `docs/claude-code-review/FIX-PLAN.md`. Follow its "Rules for every session" exactly (verify each finding before fixing, update the status marker in the findings file, one commit per cluster, author GFerreiroS <info@gferreiro.com>, no trailers, `make check` / `make firmware` must pass). Do the **Antigravity checklist** only, in order; skip A4 until cluster O9 is committed and A7 until S9 is committed (check `git log`). All items are behaviour-preserving refactors, efficiency fixes or packaging fixes — if you find you need to change behaviour, stop and report instead. When the checklist is done, stop and print a summary.

### A1 — Firmware dead/duplicated code ▸ FU#9
Files: `firmware/main/usb/usb_cdc.c` (~140–147), `firmware/main/config/device_config.c` (~207), `firmware/main/counters/counters.c` (~148), `firmware/main/input/latency_stats.c`
- [x] Delete the stale comment block superseded by the one that follows it.
- [x] Remove `device_config_set`'s IDLE check (it duplicates `write_to_nvs`'s).
- [x] Move the mid-file `#include` to the top of `counters.c`.
- [x] Remove the unread `s_samples` counter from `latency_stats`.
- Verify: `./firmware/test/host/run_tests.sh`, `make firmware`.

### A2 — Touch retry boot scan and idle polling ▸ FU#10
Files: `firmware/main/input/touch_retry.c` (~150, task loop), `firmware/main/Kconfig.projbuild`
- [x] Gate the 126-address I2C scan behind a new Kconfig option (default off).
- [x] In the task loop, read the CST816 register only when INT is active or a touch was seen in the last ~100 ms; otherwise sleep without an I2C transaction.
- Verify: `make firmware`; on the pad, touch retry still works (tap the screen during a map), boot log no longer shows the scan, no periodic NACK errors.

### A3 — UI efficiency + latent lifetime ▸ FI#7, FI#9
Files: `firmware/main/ui/core/ui_screen.c` (~341), `firmware/main/ui/ui_port.c` (~92, `rebuild_screen`)
- [x] Free the per-screen `ui_layout_t` copy **after** `lv_obj_delete(old)` returns in `rebuild_screen` (and on final teardown), not in the screen's `LV_EVENT_DELETE` handler. Observers must never see a dangling `user_data`.
- [x] Clock/date: reformat only when `t / 60` changes (or use a 1 s `lv_timer`); keep `lv_subject_copy_string` behaviour identical.
- Verify: `make firmware`; layouts switch Idle↔Playing repeatedly without crash; clock still updates on the minute.

### A4 — `opad-device` dedup (after O9) ▸ DD#8, DD#9
Files: `desktop/crates/opad-device/src/lib.rs` (~300–363, ~731–749, ~783–802, ~955)
- [x] Extract `fn device_config_from(c: &proto::ConfigPayload) -> DeviceConfig` (including the `== 0 → DEFAULT_KEYn_GPIO` and `tosu_endpoint` defaults) and use it in both the HelloAck and ConfigAck arms.
- [x] Extract one `handshake(port, window) -> Option<(HelloAck, Framing)>` used by both `probe_port` and the worker loop. **Behaviour-preserving**: the worker's timing rules win (they are the ones the O9 fix tested); document any difference from the old `probe_port` timing in the commit and confirm `opadctl status`/GUI still finds the pad on cold plug.
- Verify: `make check`; plug/unplug the pad, probe finds it; connect with the current firmware.

### A5 — Daemon main.rs dedup ▸ DA#10
Files: `desktop/daemon/src/main.rs` (~175–209)
- [x] One `fn classify_tosu_line(&str) -> LogLevel` used by both the startup log-tail and the live callback (input is already ANSI-stripped by the supervisor; do not strip twice).
- [x] Startup banner uses `env!("CARGO_PKG_VERSION")`.
- Verify: `make check`.

### A6 — ui-preview / tosu dedup ▸ DM#8, DM#10
Files: `desktop/crates/opad-ui-preview/src/lib.rs` (~8, `sample_values`), `desktop/crates/opad-ui-preview/Cargo.toml`, `desktop/crates/opad-tosu/src/lib.rs` (~620)
- [x] `opad-ui-preview`: depend on `opad-model` normally; use `ui_source::*` names in `sample_values()`; derive `SCREEN_W`/`SCREEN_H`/`MAX_WIDGETS`/`LABEL_MAX`/`SUFFIX_MAX` from `opad_layout` (note `LABEL_MAX_BYTES = 31` vs `LABEL_MAX = 32` — determine which is correct from the firmware header and use one).
- [x] `launch_tosu`: single generic `pump(reader, cb, file)` for stdout and stderr.
- Verify: `make check` (includes `source_ids_match_firmware`).

### A7 — GUI polling efficiency (after S9) ▸ DG#9, DG#10
Files: `desktop/gui/src/main.rs` (~476, ~1601), diagnostics page module
- [x] Diagnostics: move evdev/`GetAsyncKeyState` polling into a `Subscription` stream on its own thread emitting `KeyEvent` only on state change; cache the pretty-printed bundle string in state and regenerate only when its inputs change.
- [x] Poll only what the visible page needs: `GetStatus` always; `GetUiValues` on Dashboard/Designer; `GetUpdateStatus`/`GetFirmwareUpdate` on navigating to Settings plus a 60 s timer.
- Verify: `make check`; run the GUI; CPU at idle on Diagnostics drops; Settings→Updates still shows fresh state.

### A8 — CLI UX cleanups ▸ DC#8, DC#9
Files: `desktop/cli/src/main.rs` (~366–380, ~602–616, ~839)
- [x] `fn confirm(prompt: &str, non_tty_msg: &str) -> Result<bool>` used by `Import` and `FirmwareUpdate`.
- [x] `opadctl setup`: compare the embedded `70-opad.rules` (`include_str!`) with `/etc/udev/rules.d/70-opad.rules`; print "already installed" if identical, else a `sudo tee` command that writes the embedded content (no repo-relative path).
- Verify: `make check`; run `opadctl setup` on a machine with and without the rule.

### A9 — Packaging/CI ▸ PK#3, PK#4, PK#5
Files: `scripts/release/test_packages.sh` (~26), `desktop/gui/Cargo.toml` (`[package.metadata.deb] depends` ~53 and `[package.metadata.generate-rpm.requires]` ~122 — packages are built by `cargo-deb` / `cargo-generate-rpm` from `scripts/release/build_packages.sh`), `packaging/linux/deb/postinst`, `packaging/linux/arch/PKGBUILD` (~41), `.github/workflows/release.yml` (~154)
- [x] .deb: add `libcap2-bin` to `depends` in `desktop/gui/Cargo.toml`; .rpm: add `libcap` to `generate-rpm.requires`; make `test_packages.sh` **not** pre-install `libcap2-bin`/`procps` so the test proves the dependency. Leave `postinst`'s `setcap ... || true` as is (it is correct once the dependency is declared).
- [x] PKGBUILD: run `make espflash` in `build()` and install `/usr/lib/opad/bin/espflash`; add the needed `makedepends`.
- [x] release.yml: include `usr/lib/opad/tosu/tosu` in the glibc assertion with the 2.28 target; add a distro with glibc ≤ 2.31 (e.g. Debian 11) to the matrix or assert via `objdump -T | grep GLIBC_` max version.
- Verify: `make deb rpm` locally if the toolchain exists; `scripts/release/test_packages.sh`; workflow lint (`actionlint` if available).

---

## Progress log

Append a line per completed cluster: `YYYY-MM-DD  <cluster>  <commit sha>  <executor>  notes`.

```
2026-09-24  H1-H8  0e3286b  Claude Haiku  FP#8 DD#10 DU#7 DM#3 PK#2 FI#10 DM#6 DM#9 fixed; boxes ticked and the leftover easter_egg_is_active() prototype removed afterwards by the verifying session
2026-09-24  O1  aa05333  Claude Opus  FP#1 FP#2 fixed; parser locks to the first recognised frame's framing; pad test pending
2026-09-24  O2  abe93c6  Claude Opus  FP#3 FB#2 FU#7 fixed; pin scan is a keypad-task state machine, timeout clamped to 30 s; pad test pending
2026-09-24  O3  240d115  Claude Opus  FU#2 FU#6 fixed; pending flag replaced by change/sent sequence numbers; bench + pad test pending
2026-09-24  O4  ec05977  Claude Opus  FU#3 FU#4 FU#5 fixed; all runtime keypad config goes through the keypad task; pad test pending
2026-09-24  O5  65e343a  Claude Opus  FI#4 FI#5 fixed; mutex over pending layouts + layout NVS writes, failed flush kept and retried every 10 s; no host test (NVS/FreeRTOS-bound), pad test pending
2026-09-24  O6  9f835c7  Claude Opus  FI#1 FI#6 fixed; ui_lock() returns bool, data_update skipped headless, NULL idle screen -> ESP_ERR_NO_MEM; headless pad test pending
2026-09-24  S1  26f5159  Claude Opus (Sonnet list)  FU#1 FU#8 fixed; GPIO8 dropped, one KEY_GPIO_ALLOWED list shared by keypad scan + validation, debug GPIO excluded via device_config_key_gpio_supported; desktop opad-model KEY_PINS still lists GPIO8 (out of firmware scope); pad test pending
2026-09-24  S2  c6dc4d1  Claude Opus (Sonnet list)  FP#4 FP#5 FP#6 FP#7 fixed; head-index resync + memchr in marked mode, resync/stale drops recorded as FRAME_TOO_LARGE (arg0 bytes, arg1 reason), SetLayout with flags > 255 rejected (w/h already rejected); pad junk-stream test pending
2026-09-24  S3  250fd4e  Claude Opus (Sonnet list)  FI#2 FB#1 fixed; ui_port s_brightness is the only copy (board private copy removed, applied on wake), ui_set_brightness under the LVGL lock, device_config_apply no longer drives the backlight; no host test (LVGL/LEDC-bound), pad sleep/brightness test pending
2026-09-24  S4  2ab63c4  Claude Opus (Sonnet list)  FI#3 FI#8 fixed; KPS ring restarts on any counter decrease, fill count instead of 0 sentinel, signed diff clamped at 0; erase of a missing layout key returns before commit/counter; no host test (LVGL/NVS-bound), pad test pending
2026-09-24  O7  5a7b2cb  Claude Opus  DA#1 DA#2 DA#4 DA#6 fixed; DaemonState::pad_guard()/may_touch_pad() gates post-cooldown/periodic/NVS syncs, perform_sync, 8 IPC handlers and the firmware install (up front + last-moment re-check); Status.foreign_pad added (#[serde(default)], no IPC bump); takeover pushes custom layouts; manual foreign-pad test pending
2026-09-24  O8  06d0533  Claude Opus  DA#3 DA#5 fixed; protocol check first in DeviceConnected (not connected, config not adopted, HelloAck counters rolled back, incompatible cleared on disconnect, no HostStatus to an unconnected pad); failed sync leaves pad-reported counters in memory, SQLite keeps reconciled row; manual v2-pad test pending
2026-09-24  O9  dbc2990  Claude Opus  DD#2 DD#3 fixed; frames dispatched while connected with known framing (re-Hello no longer drops acks), unanswered Hellos reopen once while held connected then Disconnected, regardless of framing; commands held until framing known; pure hello_due/accept_frame unit-tested; manual rehandshake-during-sync + replug test pending
2026-09-24  O10  9f29000  Claude Opus  DD#5 DD#6 fixed (untested on Windows); accept returns the connected client even if the replacement instance fails (lazy recreate), cancel returns the instance to `next`, connect error replenishes; enter_bootloader re-picks after a fired trigger and reports NoBootloader, not PortBusy, when the app port vanished; opad-ipc/opad-device check + clippy clean for x86_64-pc-windows-gnu (full workspace blocked by missing mingw gcc for ring); VM run pending
2026-09-24  O11  8e9f92e  Claude Opus  DM#1 DM#4 fixed; paused/stopped watch channels, pause() awaits kill+reap (10 s cap, logged), mid-launch pause killed/skipped, pause stop skips backoff and resume resets it + wakes the loop at once; fake-child (sleep) test on Linux; manual app update with tosu running pending (Linux + Windows VM)
2026-09-24  S5  a7e3815  Claude Opus (Sonnet list)  DD#1 DD#4 DD#7 fixed; worker's last_hello is Option<Instant> (None = Hello now), test backdating uses checked_sub; pad_mac tries the OSUPAD- serial then device_id; empty XDG_RUNTIME_DIR treated as unset; DD#1 untested on Windows (opad-device/opad-ipc cargo check for windows-gnu clean)
2026-09-24  S6  e3f95c3  Claude Opus (Sonnet list)  DU#1 DU#2 DU#3 DU#4 DU#5 DU#6 DU#8 fixed; fetch_manifest(have_cached) sends If-None-Match only while the worker holds a manifest; tosu binary swapped before VERSION/NOTICE (atomic); .AppImage -> linux-x86_64/Binary; artifact hashed in memory (temp dir gone); tosu plan uses is_newer (no downgrade, v-prefix cosmetic); semver pre-release compare (numeric runs numeric, +build ignored); write_atomic shared by tosu + daemon backup, stage_bytes shares its helpers
2026-09-24  S7  34f68a7  Claude Opus (Sonnet list)  DA#7 DA#8 fixed; AppImage replace falls back to copy+chmod+sync+rename beside $APPIMAGE on EXDEV, apply step (pkexec/tar) in spawn_blocking; pending_device_push is Option<PendingCounterReset{device_id}>, honoured by perform_sync (zeroed counters above the pad's generation, force_restore, cleared on success, kept for a different pad); manual AppImage-on-other-fs test pending
2026-09-24  S8  b2234a5  Claude Opus (Sonnet list)  DM#2 DM#5 DM#7 fixed; JsonBackup::validate builds the DeviceConfig and delegates to DeviceConfig::validate (0x00/0xFFFF keys rejected, duplicate ranges gone); stale $OPAD_TOSU_PATH warned by path and falls through to home/PATH/bundled; strip_ansi is a CSI/OSC/ESC-intermediate state machine; stray supervisor doc comment above strip_ansi replaced
2026-09-24  S9  bb4f2cc  Claude Opus (Sonnet list)  DG#1 DG#2 DG#4 DG#5 DG#7 fixed; one Page token table for --page and ShowRequested (logs/diagnostics now switch; diagnostics enables its tab); daemon log cursor moves only from replies (last entry received), GUI entries numbered apart, Clear is time-based; adopt_config() shared by Status adopt and ImportCompleted (gameplay_display_hz); designer Applied carries (screen, layout); close while tray probe pending hides, exits if the probe finds no tray; GUI not run by hand
2026-09-24  S10  3ee772f  Claude Opus (Sonnet list)  DG#3 DG#6 DG#8 fixed; Linux tray probed every 5 s for a minute then every 30 s (Unavailable once, Started when it appears; a --tray start's fallback window hides again; a close during the probe waits for the stream's verdict); unix single-instance binds first and unlinks only on ECONNREFUSED; Windows pipe served from its own thread+runtime started in claim() before iced, handoff retried 2 s and errors reported; DG#6 untested on Windows (workspace clippy -D warnings clean for windows-gnu with a stand-in C compiler)
2026-09-24  S11  60b4147  Claude Opus (Sonnet list)  DC#1 DC#4 DC#5 DC#6 DC#7 fixed, DC#10 invalid (LogHub seqs start at 1; guard removed with DC#1 anyway); monitor cursor = last entry received; LogLevel/LogSource ValueEnum behind opad-model feature "clap" (aliases kept, case-insensitive); GetLogEntries gains optional level/source (serde default + skip_serializing_if, no IPC bump), daemon filters before limit, CLI re-filters for older daemons (checked against the running older daemon); post-flash verification error exits non-zero with a daemon too; opad_protocol::DEVICE_PROTOCOL_VERSION shared by daemon checks and the CLI message
2026-09-24  S12  8d37c5d  Claude Opus (Sonnet list)  DC#2 DC#3 fixed; IpcRequest::ResumeDevice/IpcResponse::DeviceResumed (no IPC bump: new variant, CLI falls back to FinishFlash on a new connection with a 2 s cap when an older daemon drops it); opadctl bootloader and a failed flash resume without the 15 s wait; daemon tracks the connection holding a PrepareFlash pause and resumes when it drops; CLI Ctrl-C watcher resumes while the pad is paused, then exits 130; manual bootloader/Ctrl-C test on the pad pending (running daemon is the installed older build)
2026-09-24  S13  e4fc72f  Claude Opus (Sonnet list)  PK#1 fixed; offline signing kept (user's choice): release.yml publishes a draft, sign_release.sh --tag downloads the draft's assets, signs over them, checks, uploads manifest+minisig and starts release-verify.yml, which re-checks on GitHub (minisign vs compiled key, every manifest artifact present with matching sha256/size/SHA256SUMS) and un-drafts; --dist signs an existing dir in place; build_release.sh no longer rm -rf's dist or signs; dry run on a synthetic dist (no-sign, throwaway-key signature, tamper + missing cases); not run on GitHub (no act/actionlint here)
2026-09-24  S5-S13 Windows  360b4f5  Claude Opus (Sonnet list)  Windows VM run (osupad-win11, Rust 1.98): workspace fmt/clippy -D warnings/tests incl. GUI; found and fixed DA#7's copy fallback fsyncing a read-only handle (FlushFileBuffers needs write access); DG#6 pipe test added and passing; end to end with real binaries: opadctl bootloader resumes in <1 s via ResumeDevice, a client dropping after PrepareFlash gets the pad resumed, monitor --level validated; pad not passed through (flash path/PID flip is the known VM limit)
2026-09-24  (extra)  (this commit)  Claude Opus  found on the Windows VM, not in any findings file: the daemon served requests on a connection with no or a rejected handshake; per-connection loop moved to ipc_handlers::serve_connection, which refuses anything before a successful Handshake and closes after a rejection (flash-pause resume kept); duplex-stream tests + Windows VM repro re-run
2026-09-24  A1  (this commit)  Claude Opus (Antigravity list)  FU#9 fixed; stale BOOTLOADER-only comment removed, device_config_set defers to write_to_nvs's IDLE check (a deferred write now logs write_to_nvs's warning instead of its own info line), counter_sync_rules.h include moved to the top, unread latency s_samples removed
2026-09-24  A2  (this commit)  Claude Opus (Antigravity list)  FU#10 partly fixed; boot I2C scan behind CONFIG_OSUPAD_DEBUG_I2C_SCAN (default n); idle CST816 read gating NOT done (INT || TOUCH_NUM is deliberate, gating may drop a tap if INT pulses), needs an INT-waveform check on the pad; pad test pending (touch retry still fires, no scan in boot log)
2026-09-24  A3  (this commit)  Claude Opus (Antigravity list)  FI#7 FI#9 fixed; layout copy kept in the screen's user_data and freed by new ui_screen_delete() after lv_obj_delete returns (ui_port rebuild_screen + desktop preview use it); pad.clock/pad.date formatted only when t/60 changes (identical output: no TZ, minute resolution; a host write to 69/70, which the daemon never sends, is no longer overwritten within 20 ms); pad test pending (Idle<->Playing switches, clock on the minute)
2026-09-24  A4  (this commit)  Claude Opus (Antigravity list)  DD#8 fixed; one device_config_from() for the HelloAck and ConfigAck arms (+ unit test). DD#9 partly done and left open: probe_port takes its framing order from hello_framing() and shares write_hello(); a single handshake() not extracted (the worker's Hello logic lives inside the connected loop, and its 400 ms cadence would leave a legacy pad 50 ms of the probe's 450 ms window, which is a behaviour change on the Windows tier-2 path); needs a decision + Windows cold-plug test
2026-09-24  A5  (this commit)  Claude Opus (Antigravity list)  DA#10 fixed; classify_tosu_line() shared by the log-file tail and the live callback (tail still strips ANSI: the file keeps raw lines; the callback gets stripped ones), banner uses CARGO_PKG_VERSION (now logs v1.0.0-rc), classifier unit test
2026-09-24  A6  (this commit)  Claude Opus (Antigravity list)  DM#8 DM#10 fixed; opad-ui-preview depends on opad-model, sample_values() uses ui_source names (same ids/values/order), sizes derived from opad_layout (LABEL_MAX = LABEL_MAX_BYTES + 1 = 32 and SUFFIX_MAX = 12: both were right, bytes vs C field with NUL per ui_core.h); launch_tosu's two reader tasks are one pump_lines()
2026-09-24  A7  (this commit)  Claude Opus (Antigravity list)  DG#9 fixed, DG#10 partly fixed; switch polling on its own thread (4 ms, KeyEvent only on change, stamped when seen; Diagnostics page 28.2% -> 0.8% of a core, debug build, Linux); bundle string not cached (embeds a live sub-second timestamp); UiValues only on Dashboard/Designer, FirmwareUpdate only on Settings/Device/Diagnostics, tray polls status alone, window open polls at once; GetUpdateStatus kept at the tick rate (restart banner on every page), 60 s timer NOT done, needs a decision; Windows clippy clean with a stand-in C compiler, GUI run on Linux only (no key presses)
2026-09-24  A8  (this commit)  Claude Opus (Antigravity list)  DC#9 fixed; confirm(prompt, non_tty_msg) shared by Import and FirmwareUpdate (same prompts, messages and y/yes rule). DC#8 verified but NOT fixed: it changes opadctl setup's output and checks (correctness, not a refactor), left open for a go-ahead
2026-09-24  A9  (this commit)  Claude Opus (Antigravity list)  PK#3 PK#4 PK#5 fixed; .deb depends on libcap2-bin, .rpm requires libcap, test_packages.sh pre-installs nothing (debian:13 + fedora:43 run on locally built packages: install pulls setcap, tosu gets cap_sys_ptrace, daemon answers; the only FAILs were the stale host-glibc opad-gui and the local non-standalone tosu); both PKGBUILDs run make espflash (+ curl/unzip makedepends; make install -> /usr/lib/opad/bin/espflash checked in a DESTDIR); release.yml checks tosu + its .node addons at <= 2.28 before packaging and tosu in deb/rpm/AppImage after, with missing files failing (objdump chosen over a Debian 11 matrix entry); shellcheck: no new findings; actionlint unavailable, YAML parsed; CI run and makepkg of a real tag pending
2026-09-24  A8b  (this commit)  Claude Opus  DC#8 fixed on user go-ahead; opadctl setup compares /etc/udev/rules.d/70-opad.rules with the embedded rule (installed / differs / missing) and prints a sudo tee heredoc of the embedded content instead of a repo-relative cp; unit test on the comparison
2026-09-24  A4b  (this commit)  Claude Opus  DD#9 fixed on user decision (unify anyway); one Handshake state machine (retry cadence, framing order, HelloAck handling, O9 reopen/drop rules) drives both the worker loop and probe_port via probe_handshake(); probe: Marked at 0 ms, Legacy at 400 ms, give up at 800 ms (legacy pad gets 400 ms, was 225), PROBE_ANSWER_WINDOW/PROBE_READ_TIMEOUT removed, probe read timeout 10 ms; 4 unit tests; Windows cold-plug test with a legacy pad pending
2026-09-24  O12  (this commit)  Claude Opus  DA#9 fixed on user go-ahead; apply_event mem::swaps the shared DaemonState into the controller for one event and back under the same lock (no clone either way); replacement_was_pending replaces the controller.state read used for the takeover reconciliation; the two between-event readers in main.rs (clock-jump time sync, SQLite reconnect device id) read the shared state briefly under the lock; on_event and all daemon test assertions unchanged
2026-09-24  A2b  (this commit)  Claude Opus  FU#10 fixed on user decision (less CPU; touch is the third button): touch task sleeps on a falling-edge INT ISR (task notification) with a 1 s safety read while idle, confirms over I2C, then polls at 100 Hz only while the touch is down (release logic unchanged: 2 consecutive up reads); falls back to the old 100 Hz poll if the ISR cannot be registered; robust to INT held or pulsed; pad test pending (tap = press, hold = held, release = clean release, boot log shows "INT wake")
2026-09-24  A7b  (this commit)  Claude Opus  DG#10 fixed on user decision (60 s is fine): GetUpdateStatus asked every UPDATE_STATUS_POLL (60 s) instead of every tick, forced at once on Navigate(Settings) and after any ActionDone (an install may have changed it); poll() is &mut self to record the time; GUI not run by hand
2026-09-24  A8c  (this commit)  Claude Opus  DC#8 follow-up from the user's hardware run: the check only looked in /etc/udev/rules.d while the .deb/.rpm/AppImage/make install put the rule in /usr/lib/udev/rules.d, so a package install would have read as "not installed"; both paths are checked now (an old copy in one does not hide a current one in the other); the user ran the Sep 20 installed opadctl, so step 9 must be re-run after make install-user
2026-09-24  VALIDATION  -  owner  Hardware run on the real pad passed: flash+reconnect (S12), boot (O6/S1/A2), touch as third key (FU#10), keys/remap/detect-pin (O2/O3/O4/S1), full map + replug (O1/S2 pad side), sleep/brightness (S3/FB#1), layout during gameplay + reboot (O5). Everything else signed off by the owner on tests/review without a hardware run (O7 O8 O9 O10 O11 S6 S7 S9 S10 S11 S13 DC#8 DG#10 DD#9). Plan closed; see claude-code-review/README.md "Status".
```

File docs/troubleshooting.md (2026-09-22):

# OPad Troubleshooting Guide

This guide covers common questions and troubleshooting steps for the OPad keypad, desktop integration, key mappings, and overlay telemetry on Linux and Windows.

---

## 1. Keyboard Layouts & Scancode Mappings (QWERTY, AZERTY, QWERTZ)

### How Key Scancodes Work in OPad
OPad is a 1000 Hz USB HID composite keyboard. USB HID keyboards do **not** transmit localized letters (such as "Z" or "W"); they transmit **USB HID Key Usage IDs** (hardware scancodes). The operating system's keyboard layout then translates these usage IDs into the corresponding character for your language.

Default firmware scancodes:
* **Key 1**: `0x1D` (`HID_USAGE_KEY_KEYBOARD_Z`)
* **Key 2**: `0x1B` (`HID_USAGE_KEY_KEYBOARD_X`)

### Behavior on Non-QWERTY Layouts

| Operating System Layout | Physical Key 1 Sends | OS Interprets As | Recommended Action |
|---|---|---|---|
| **US / UK QWERTY** | Usage `0x1D` | **`Z`** | None needed (default `Z` / `X` in osu!) |
| **French AZERTY** | Usage `0x1D` | **`W`** | In osu!, bind Left Key to `W` (or rebind in OPad) |
| **German QWERTZ** | Usage `0x1D` | **`Y`** | In osu!, bind Left Key to `Y` (or rebind in OPad) |
| **Dvorak / Colemak** | Usage `0x1D` | Layout-dependent | Rebind in osu! or OPad |

### Adjusting Key Mappings
You have two options:
1. **In osu! / osu!lazer (Fastest)**: Open osu! **Options → Key Bindings** and tap Key 1 and Key 2 on your OPad to bind whatever scancode the pad sends.
2. **In OPad**: open the desktop app, **Settings → Keys**, and choose the
   letter each key sends. The pad stores it, so it holds on every PC.

---

## 2. Linux Yama ptrace Scope & tosu Memory Telemetry

### The Issue
OPad displays real-time accuracy, combo, unstable rate (UR), and beatmap details on its built-in display using `tosu`. Under Linux, `tosu` reads the memory of the running `osu!` process (whether running via Wine/Proton or native Linux `osu!lazer`).

Modern Linux distributions (Ubuntu, Debian, Fedora, Arch) protect process memory using the **Yama Linux Security Module** via `/proc/sys/kernel/yama/ptrace_scope`:
* **Scope 0**: Classic ptrace permissions (processes with the same UID can inspect each other).
* **Scope 1 (Default on Ubuntu/Debian)**: Restricted ptrace (processes can only ptrace direct children).
* **Scope 2**: Admin-only ptrace (only processes with `CAP_SYS_PTRACE` can inspect memory).
* **Scope 3**: No ptrace allowed until reboot.

When `ptrace_scope` is set to `1` or higher, `tosu` cannot attach to `osu!` and live telemetry on the OPad screen will remain paused or show zero.

### Solution 1: File Capability (Recommended)
Granting `CAP_SYS_PTRACE` specifically to the `tosu` binary allows it to read process memory without weakening system-wide security:

```bash
# If installed via package:
sudo setcap cap_sys_ptrace=eip /usr/lib/opad/tosu/tosu

# If installed locally (~/.local):
sudo setcap cap_sys_ptrace=eip ~/.local/lib/opad/tosu/tosu
```
> [!NOTE]
> The `.deb` and `.rpm` packages apply this capability when they install. The
> **AppImage** cannot: it runs from a `nosuid` mount, which ignores file
> capabilities. The **Arch package** runs tosu with the system `node`, and
> giving `node` this capability would hand it to every Node program. On those
> two, use Solution 2. `opadctl setup` and the Diagnostics page tell you which
> case you are in.

### Solution 2: System-wide ptrace Scope
If you prefer to allow ptrace across your user session:

**Temporary (until reboot):**
```bash
echo 0 | sudo tee /proc/sys/kernel/yama/ptrace_scope
```

**Persistent (across reboots):**
Create or edit `/etc/sysctl.d/10-ptrace.conf`:
```ini
kernel.yama.ptrace_scope = 0
```
Then apply:
```bash
sudo sysctl --system
```

---

### tosu exits at once with a `GLIBC_2.xx not found` error
Upstream tosu's prebuilt pp calculator (`@tosuapp/lazer-calculator`) needs
glibc 2.38, so an upstream tosu build fails to start on Ubuntu 22.04, Debian 12
and RHEL 9. OPad's release packages rebuild it (and tosu's own native addon)
for glibc 2.28, so the bundled tosu runs on every supported distribution. You
will only see this with a tosu built another way: your own (`OPAD_TOSU_PATH`),
or `make tosu TOSU_PORTABLE=0`.

## 3. USB Permissions & Serial Port Access (Linux)

### Symptom: `Permission denied (os error 13)` or Device Not Detected
On Linux, standard users do not have access to raw USB serial devices (`/dev/ttyACM*`) or input nodes by default.

### Fix
The `.deb` and `.rpm` install the rule. The AppImage offers an **Install**
button on first run (or run `./opad-x86_64.AppImage install-udev`). From a
source checkout:
```bash
sudo cp packaging/linux/udev/70-opad.rules /etc/udev/rules.d/
sudo udevadm control --reload-rules && sudo udevadm trigger
```
The rule also lets the Diagnostics page read the pad's key events.

### ModemManager Interference
ModemManager probes new serial devices by sending `AT` Hayes commands. This can corrupt CDC protocol handshakes. The official `70-opad.rules` rule includes:
```udev
ATTRS{idVendor}=="303a", ATTRS{idProduct}=="4001|1001", ENV{ID_MM_DEVICE_IGNORE}="1"
```
Ensure you are using the latest `70-opad.rules`.

---

## 4. Windows SmartScreen & Permissions

### Windows Defender SmartScreen
The OPad installer (`opad-setup.exe`) is built from this repository by the
release workflow on GitHub Actions, and is not code-signed yet. If Windows displays "Windows protected your PC":
1. Click **More info**.
2. Click **Run anyway**.
3. You can verify the installer checksum against `SHA256SUMS` published on the GitHub Releases page.

### Antivirus False Positives on `tosu.exe`
Because `tosu` reads the virtual memory of another process (`osu!.exe`), certain overly aggressive antivirus heuristics may flag or quarantine `tosu.exe`. If telemetry stops updating on Windows:
1. Check your Antivirus Quarantine / Protection History.
2. Whitelist `%LOCALAPPDATA%\Programs\opad\tosu\tosu.exe`.

---

## 5. Firmware Recovery & Re-flashing

If the pad becomes unresponsive, corrupted, or needs a complete factory unbind:
1. Unplug the USB cable.
2. Hold down the **BOOT** button on the ESP32-S3 board.
3. Plug in the USB cable while holding BOOT, then release after 2 seconds.
4. Run recovery flash:
   ```bash
   opadctl flash --full firmware/build
   ```
See [docs/recovery.md](recovery.md) for full hardware recovery steps.

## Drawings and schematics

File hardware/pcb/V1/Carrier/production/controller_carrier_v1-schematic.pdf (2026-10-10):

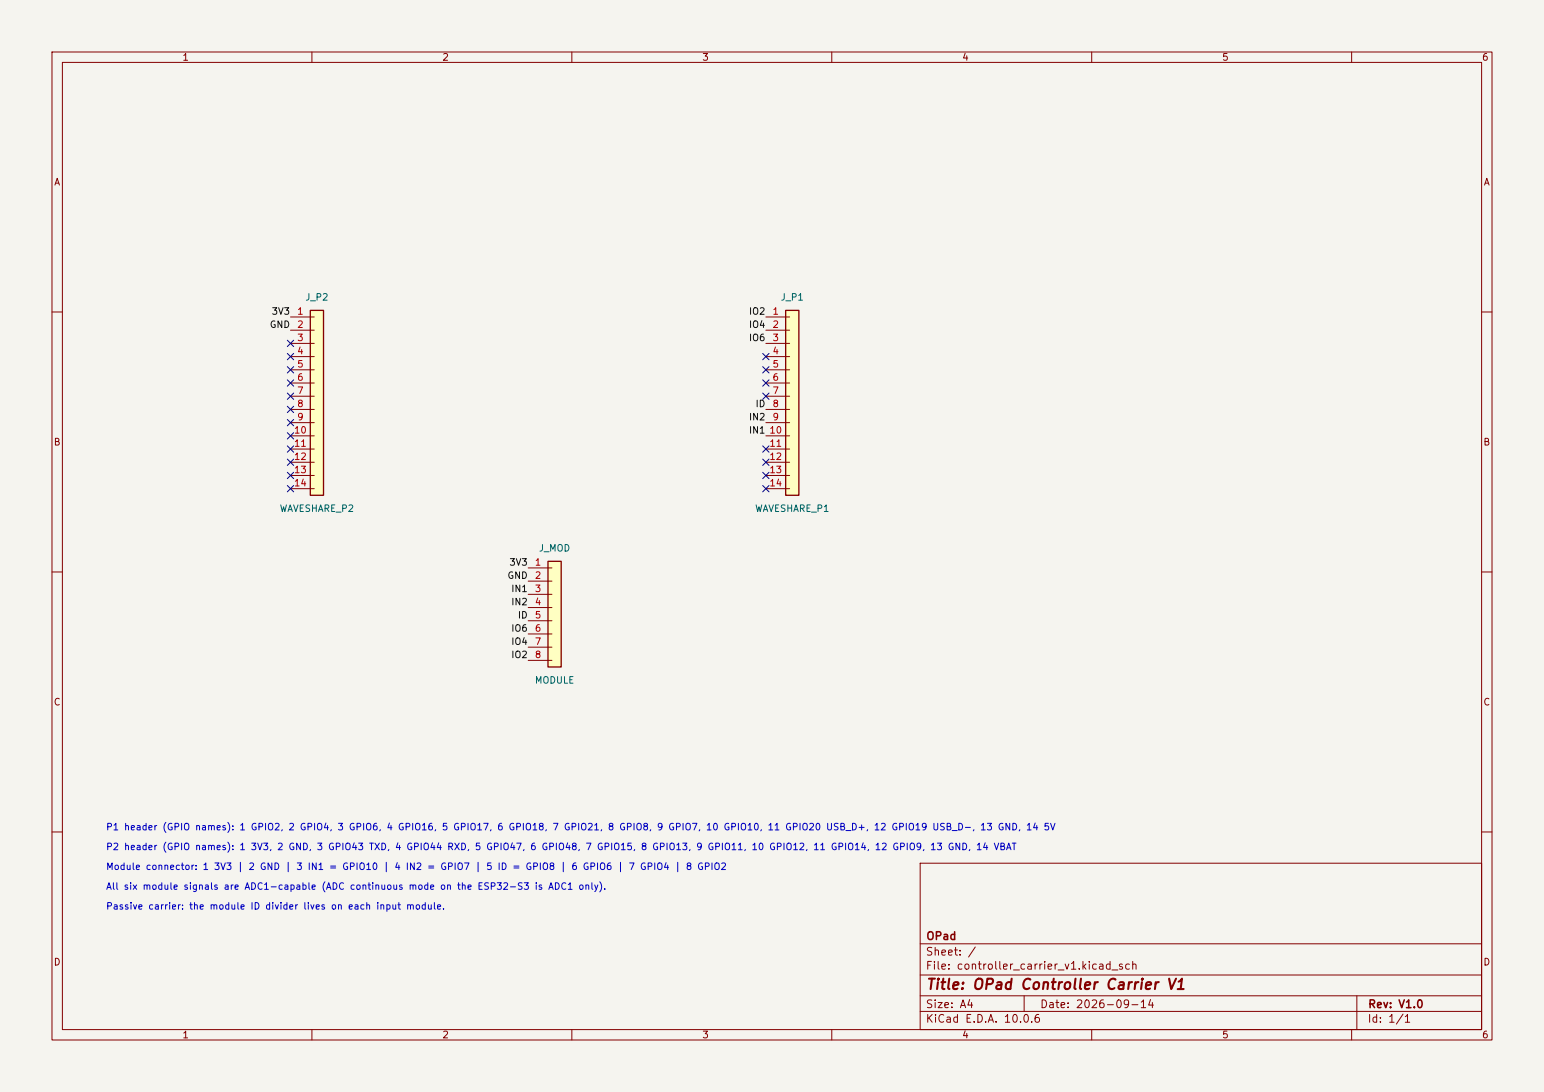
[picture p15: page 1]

3V3 P1 header (GPIO names): 1 GPIO2, 2 GPIO4, 3 GPIO6, 4 GPIO16, 5 GPIO17, 6 GPIO18, 7 GPIO21, 8 GPIO8, 9 GPIO7, 10 GPIO10, 11 GPIO20 USB_D+, 12 GPIO19 USB_D-, 13 GND, 14 5V Passive carrier: the module ID divider lives on each input module. All six module signals are ADC1-capable (ADC continuous mode on the ESP32-S3 is ADC1 only). Module connector: 1 3V3 | 2 GND | 3 IN1 = GPIO10 | 4 IN2 = GPIO7 | 5 ID = GPIO8 | 6 GPIO6 | 7 GPIO4 | 8 GPIO2 P2 header (GPIO names): 1 3V3, 2 GND, 3 GPIO43 TXD, 4 GPIO44 RXD, 5 GPIO47, 6 GPIO48, 7 GPIO15, 8 GPIO13, 9 GPIO11, 10 GPIO12, 11 GPIO14, 12 GPIO9, 13 GND, 14 VBAT

Size: A4 | Rev: V1.0
KiCad E.D.A. 10.0.6 | Id: 1/1

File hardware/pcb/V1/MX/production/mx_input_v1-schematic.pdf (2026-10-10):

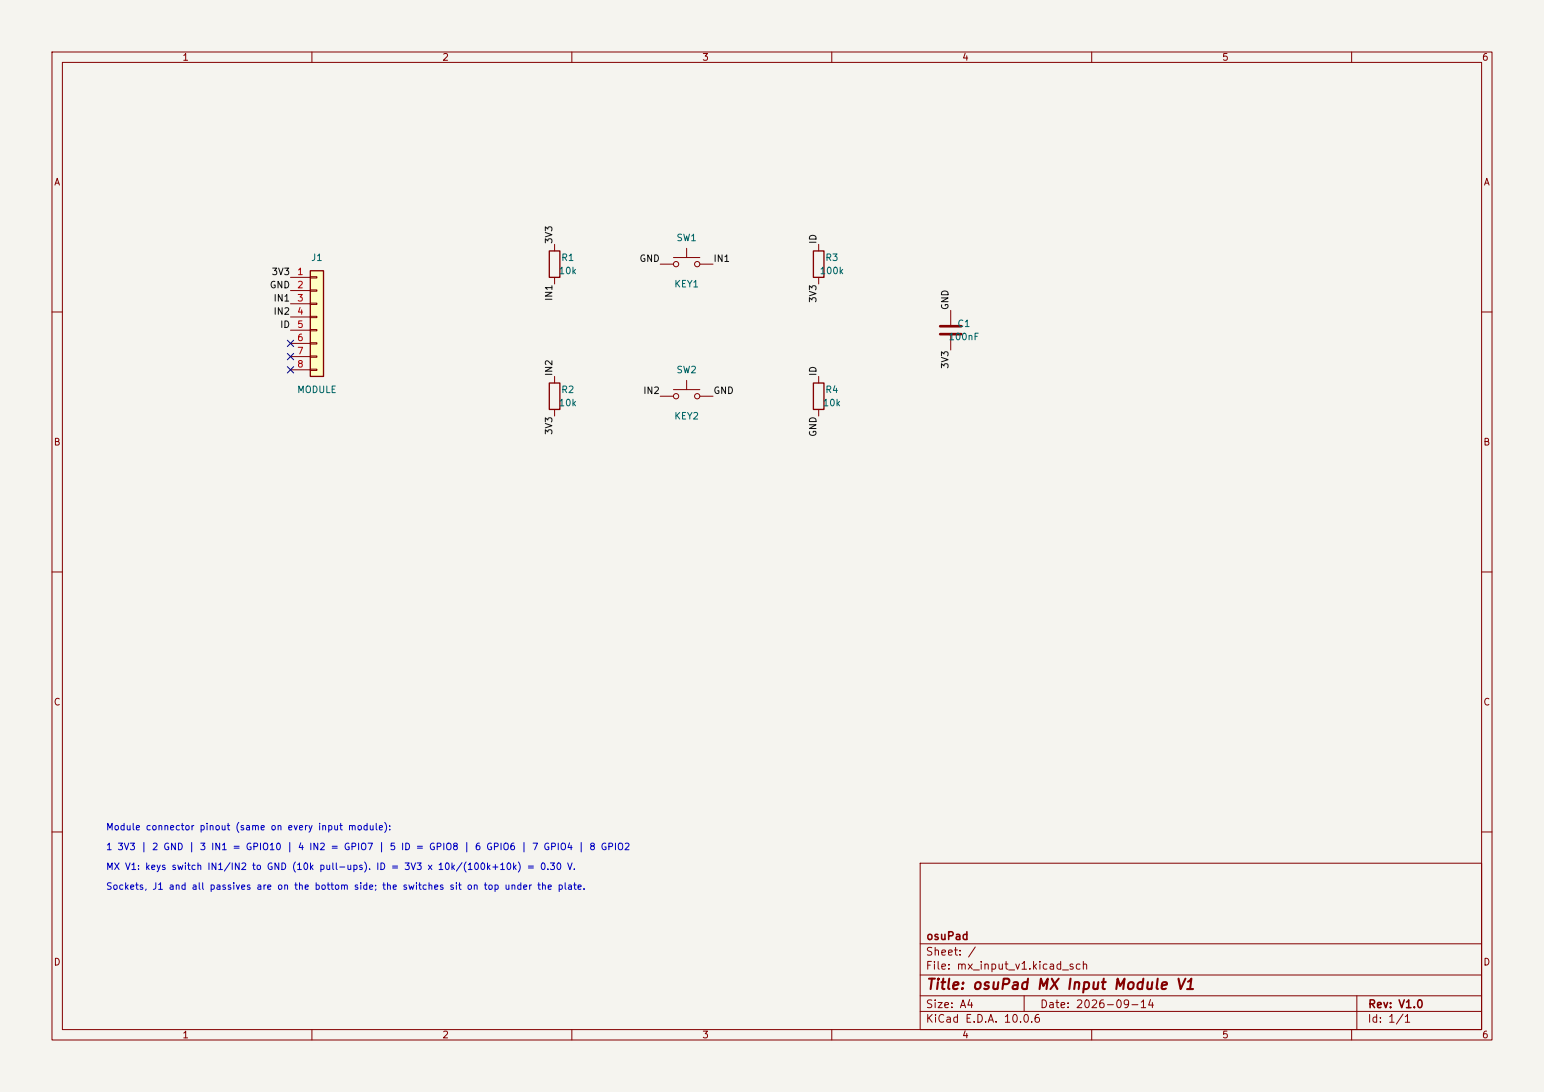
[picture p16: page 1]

1 3V3 | 2 GND | 3 IN1 = GPIO10 | 4 IN2 = GPIO7 | 5 ID = GPIO8 | 6 GPIO6 | 7 GPIO4 | 8 GPIO2 MX V1: keys switch IN1/IN2 to GND (10k pull-ups). ID = 3V3 x 10k/(100k+10k) = 0.30 V. Sockets, J1 and all passives are on the bottom side; the switches sit on top under the plate. Module connector pinout (same on every input module):

osuPad
Sheet: /
File: mx_input_v1.kicad_sch
Title: osuPad MX Input Module V1

Size: A4 | Rev: V1.0
KiCad E.D.A. 10.0.6 | Id: 1/1

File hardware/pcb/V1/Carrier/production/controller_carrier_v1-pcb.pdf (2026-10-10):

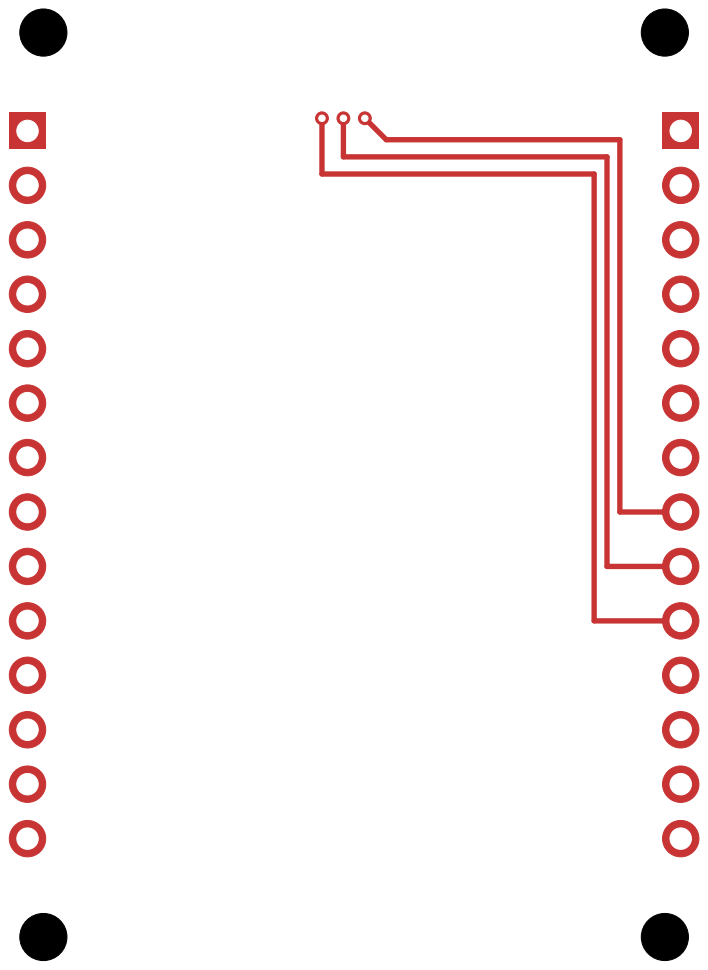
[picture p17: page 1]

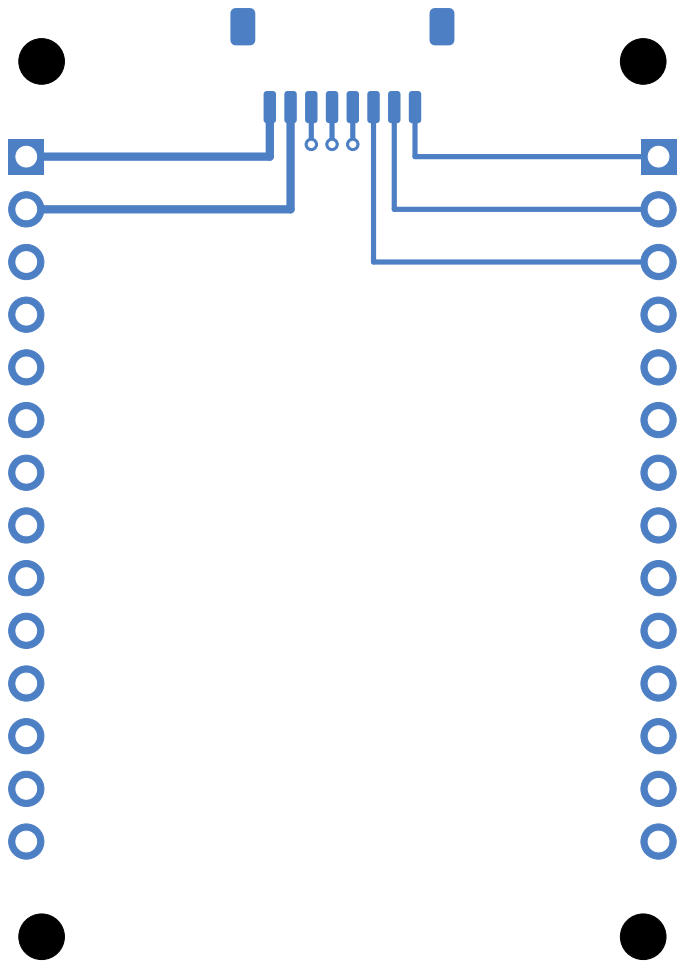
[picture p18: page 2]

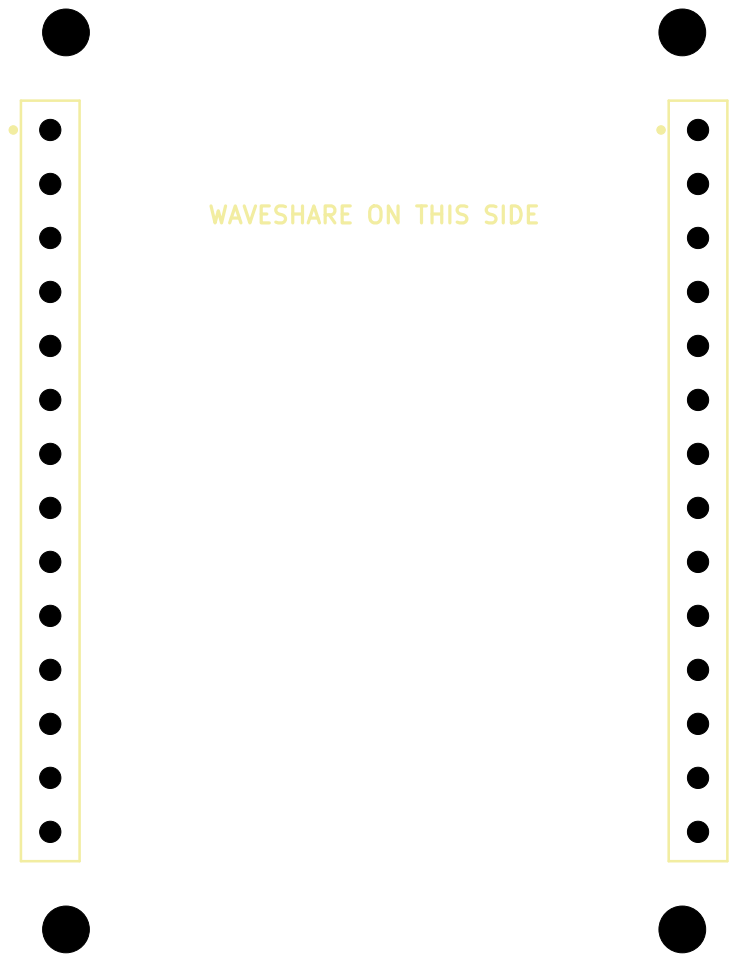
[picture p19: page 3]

WAVESHARE ON THIS SIDE

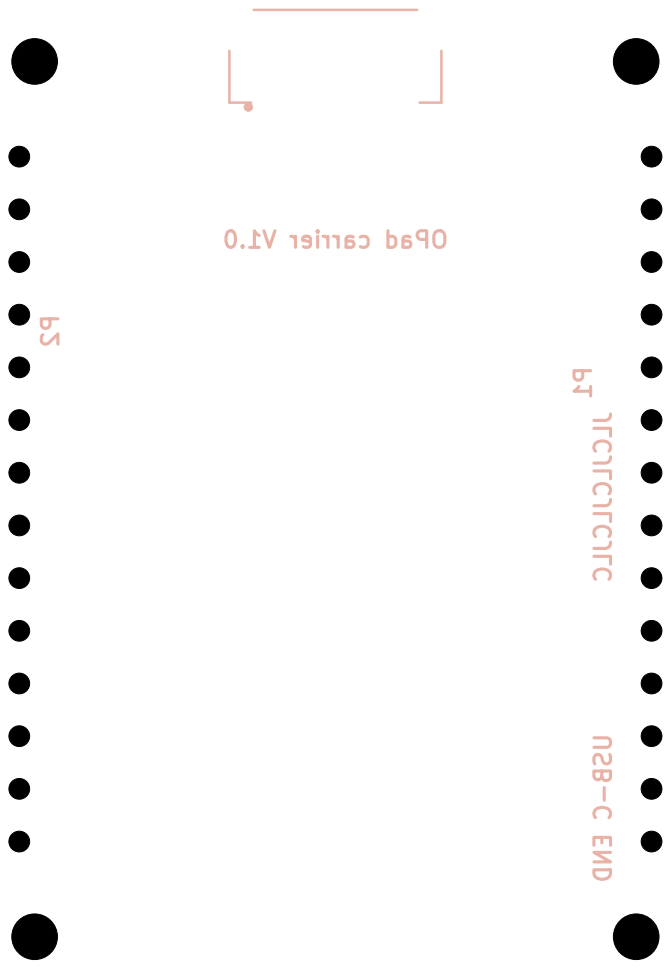
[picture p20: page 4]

V1.0 carrier OPad P2 P1 JLCJLCJLCJLC USB-C END

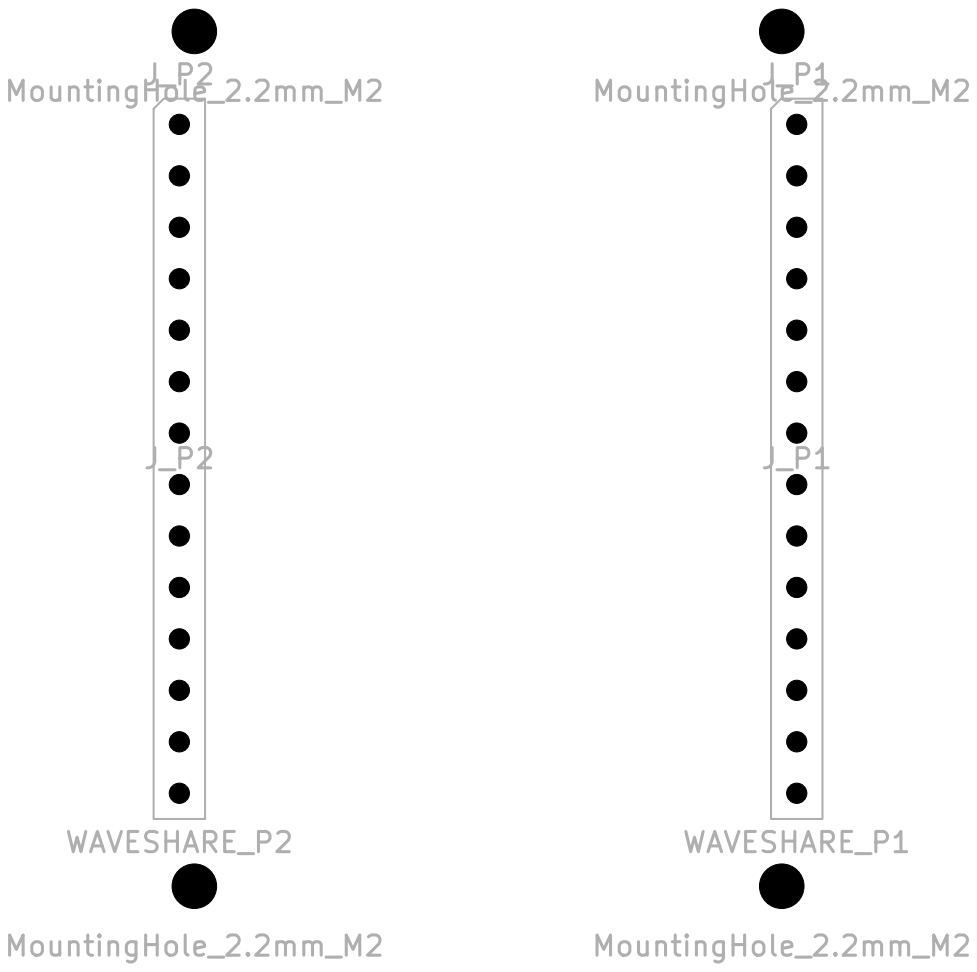
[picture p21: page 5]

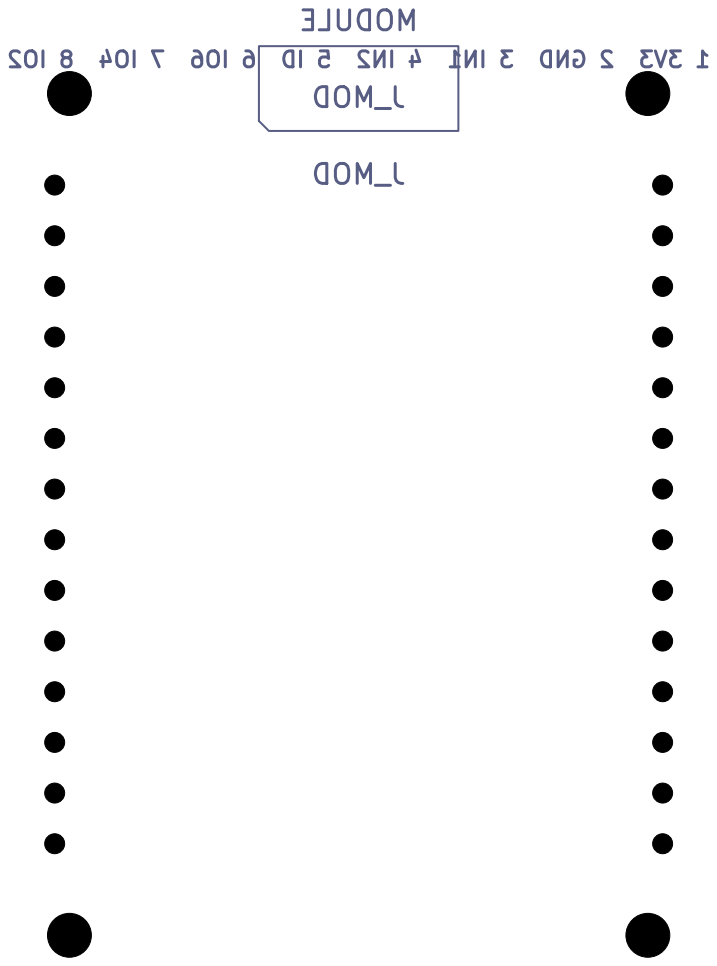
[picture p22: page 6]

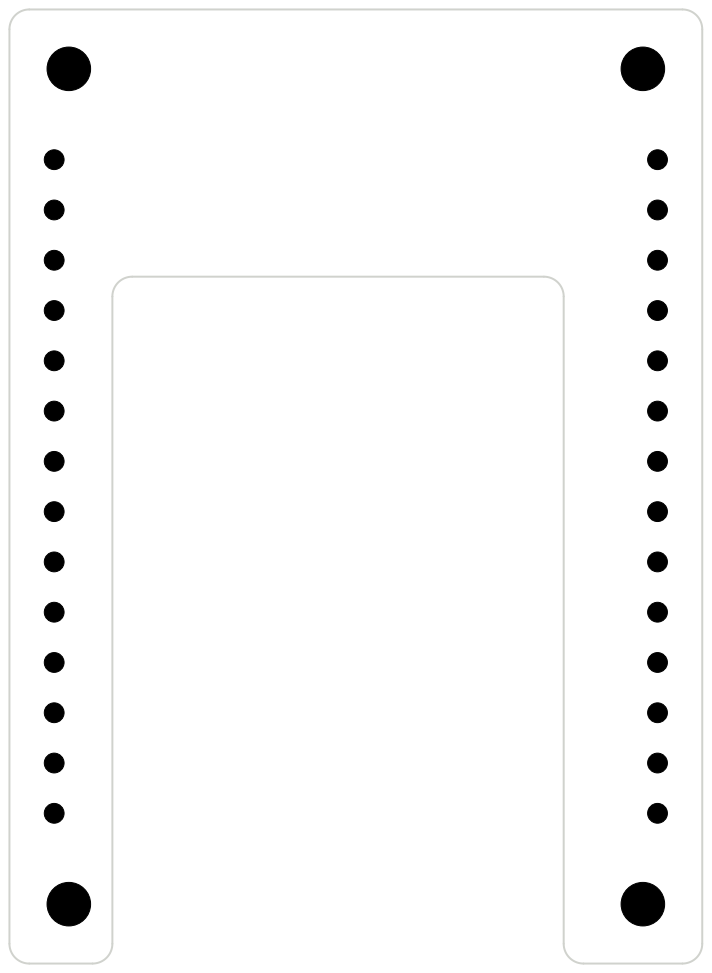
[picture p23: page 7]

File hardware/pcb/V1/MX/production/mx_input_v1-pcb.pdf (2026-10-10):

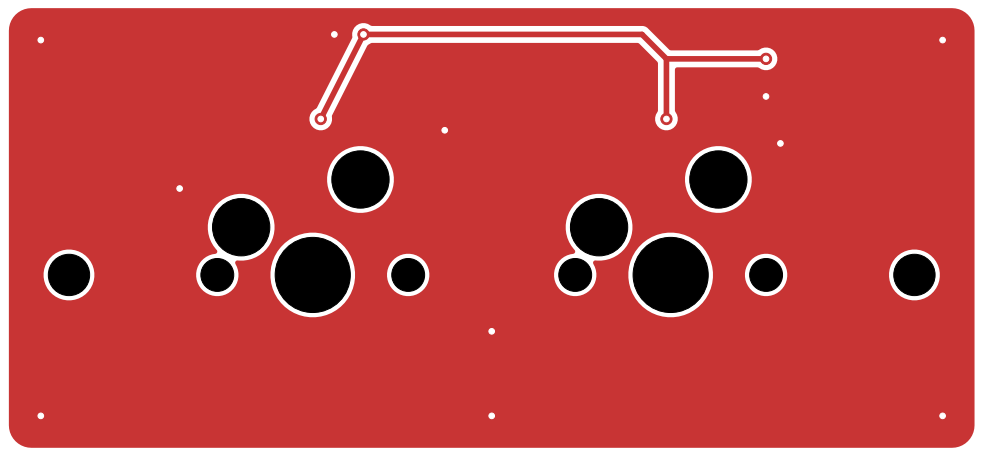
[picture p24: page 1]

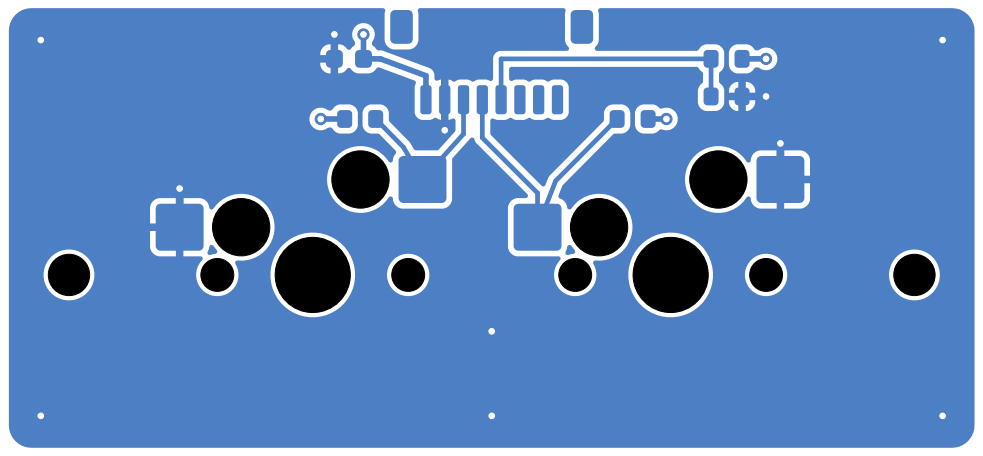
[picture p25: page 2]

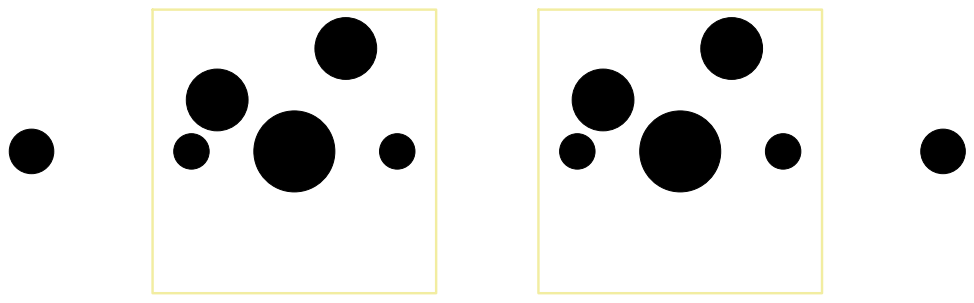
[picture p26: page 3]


carrier to KEY2 V1.0 module MX osuPad



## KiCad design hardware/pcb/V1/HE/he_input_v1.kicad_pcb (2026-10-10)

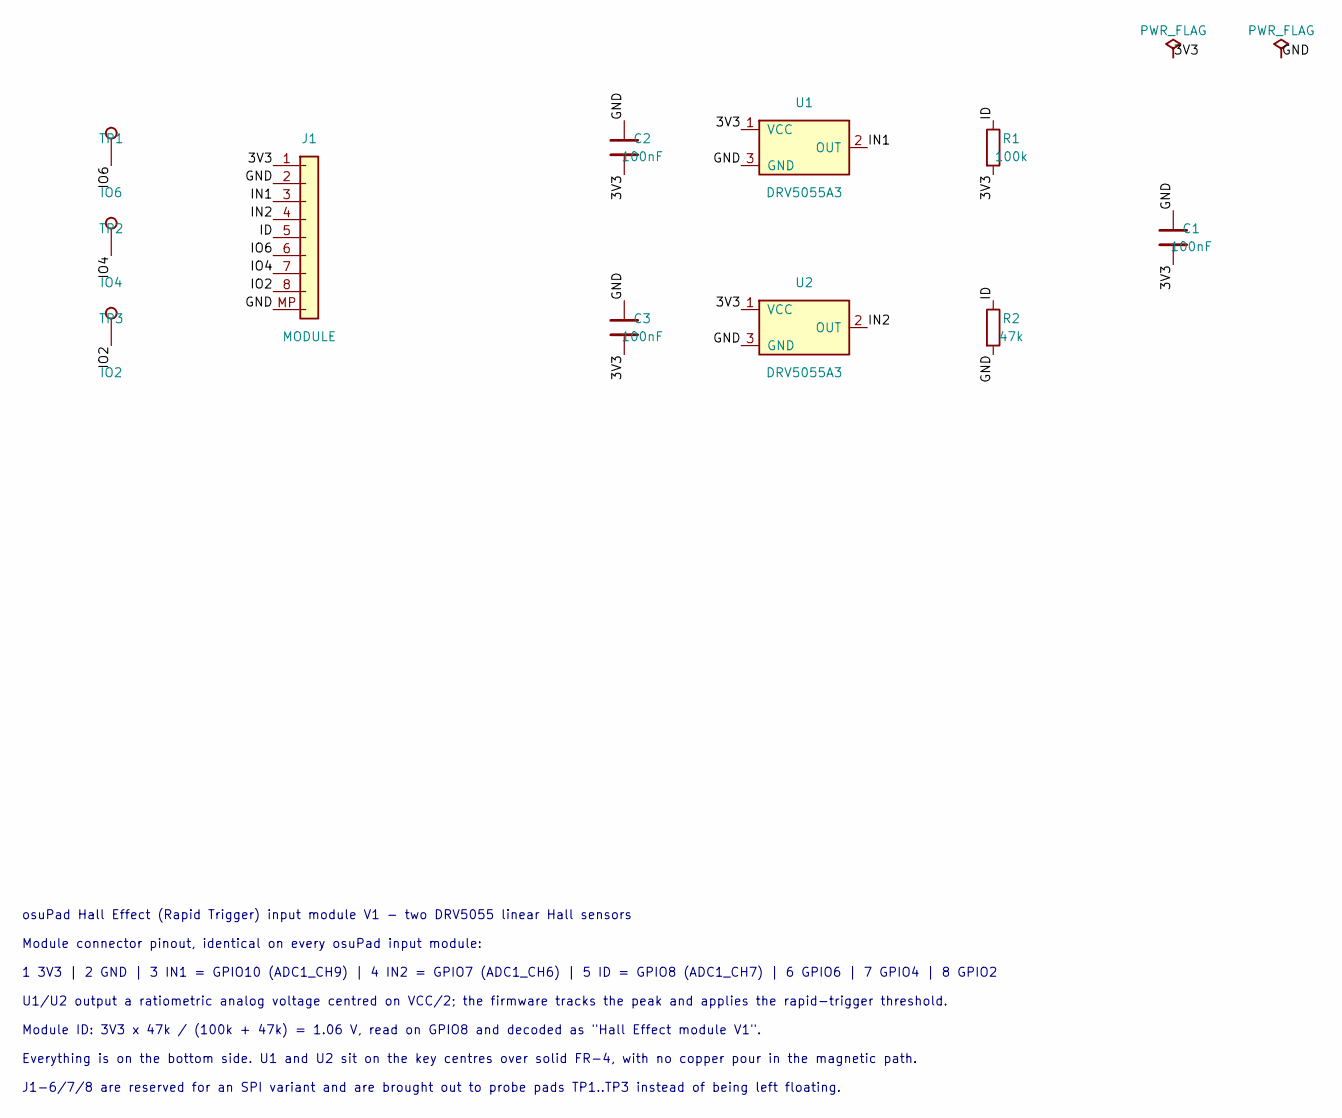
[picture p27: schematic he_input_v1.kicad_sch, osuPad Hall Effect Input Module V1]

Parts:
C1, C2, C3: 100nF; C_0603_1608Metric; MPN CC0603KRX7R9BB104; LCSC C14663
J1: MODULE; JST_SH_SM08B-SRSS-TB_1x08-1MP_P1.00mm_Horizontal; MPN SM08B-SRSS-TB(LF)(SN); LCSC C160407
R1: 100k; R_0603_1608Metric; MPN 0603WAF1003T5E; LCSC C25803
R2: 47k; R_0603_1608Metric; MPN 0603WAF4702T5E; LCSC C25819
TP1: IO6; TestPoint_Pad_1.0x1.0mm
TP2: IO4; TestPoint_Pad_1.0x1.0mm
TP3: IO2; TestPoint_Pad_1.0x1.0mm
U1, U2: DRV5055A3; SOT-23; MPN DRV5055A3QDBZR; LCSC C266128

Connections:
/3V3: C1.2, C2.2, C3.2, J1.1, R1.2, U1.1 (VCC), U2.1 (VCC)
/GND: C1.1, C2.1, C3.1, J1.2, J1.MP, R2.2, U1.3 (GND), U2.3 (GND)
/ID: J1.5, R1.1, R2.1
/IN1: J1.3, U1.2 (OUT)
/IN2: J1.4, U2.2 (OUT)
/IO2: J1.8, TP3.1
/IO4: J1.7, TP2.1
/IO6: J1.6, TP1.1

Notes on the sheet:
osuPad Hall Effect (Rapid Trigger) input module V1 - two DRV5055 linear Hall sensors
Module connector pinout, identical on every osuPad input module:
1 3V3 | 2 GND | 3 IN1 = GPIO10 (ADC1_CH9) | 4 IN2 = GPIO7 (ADC1_CH6) | 5 ID = GPIO8 (ADC1_CH7) | 6 GPIO6 | 7 GPIO4 | 8 GPIO2
U1/U2 output a ratiometric analog voltage centred on VCC/2; the firmware tracks the peak and applies the rapid-trigger threshold.
Module ID: 3V3 x 47k / (100k + 47k) = 1.06 V, read on GPIO8 and decoded as "Hall Effect module V1".
Everything is on the bottom side. U1 and U2 sit on the key centres over solid FR-4, with no copper pour in the magnetic path.
J1-6/7/8 are reserved for an SPI variant and are brought out to probe pads TP1..TP3 instead of being left floating.

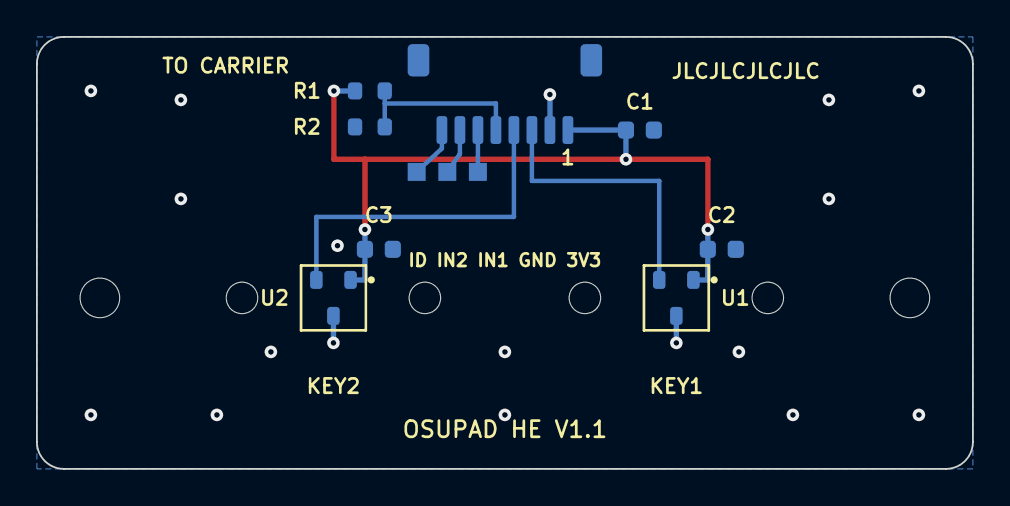
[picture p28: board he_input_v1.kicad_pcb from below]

Board: 2 copper layers, 52.0 x 24.0 mm, 15 parts (13 on the bottom side), 8 nets.

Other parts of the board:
H1, H2: MountingHole_2.2mm_M2
SW1: KEY1; SW_MX_Hall_PlateMount_SolidCentre
SW2: KEY2; SW_MX_Hall_PlateMount_SolidCentre

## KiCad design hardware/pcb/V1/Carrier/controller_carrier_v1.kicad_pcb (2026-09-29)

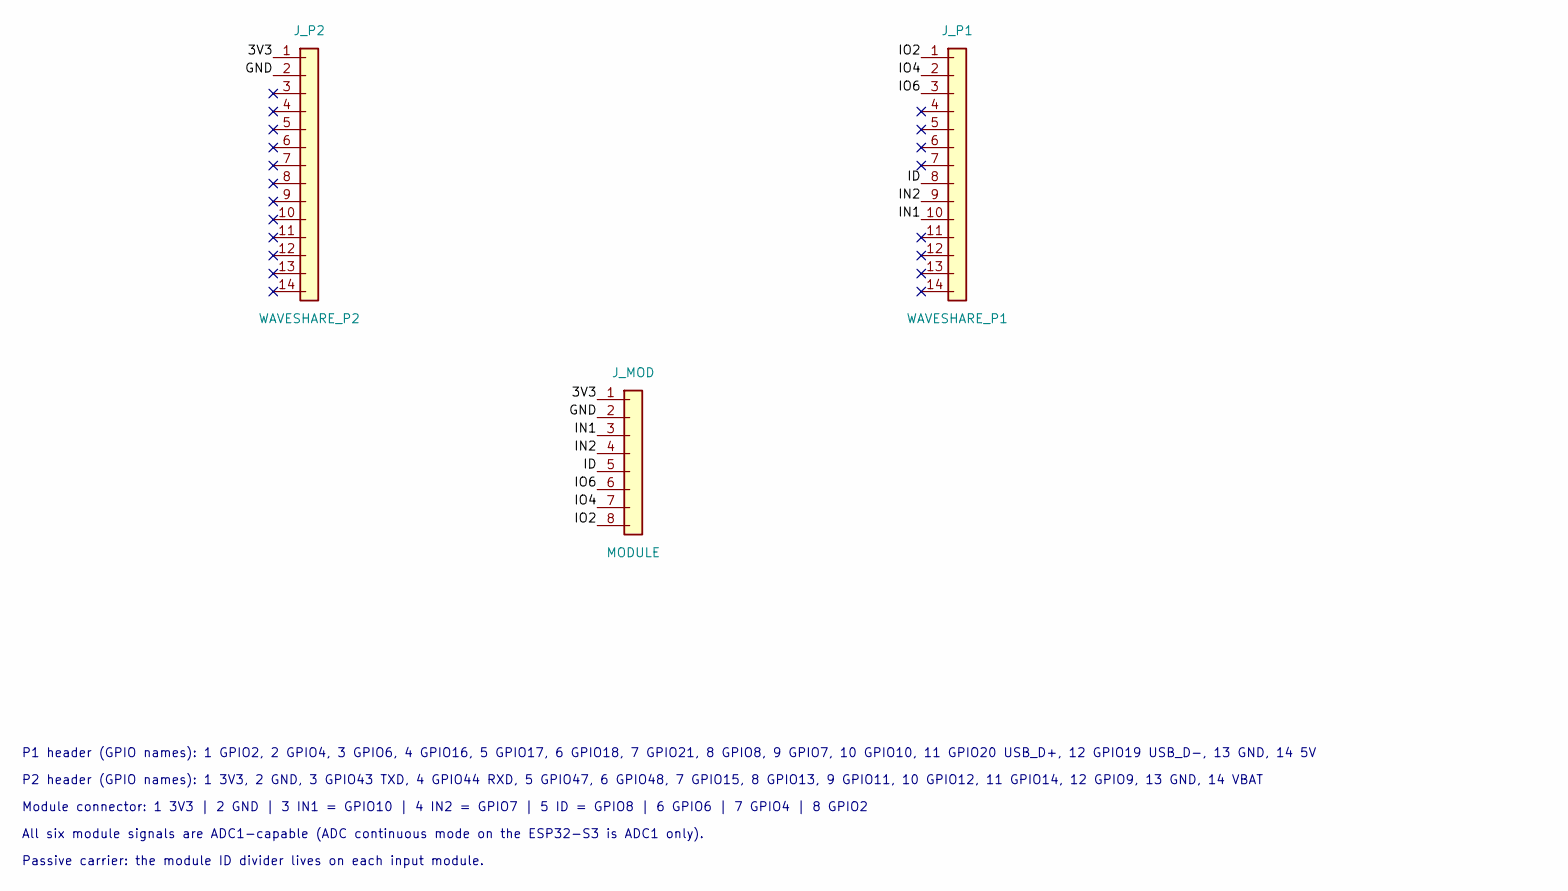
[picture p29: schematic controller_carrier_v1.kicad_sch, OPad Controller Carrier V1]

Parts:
J_MOD: MODULE; JST_SH_SM08B-SRSS-TB_1x08-1MP_P1.00mm_Horizontal; MPN JST SM08B-SRSS-TB(LF)(SN); LCSC C160407
J_P1: WAVESHARE_P1; PinSocket_1x14_P2.54mm_Vertical; MPN HCTL PM254-1-14-Z-8.5; LCSC C2897377
J_P2: WAVESHARE_P2; PinSocket_1x14_P2.54mm_Vertical; MPN HCTL PM254-1-14-Z-8.5; LCSC C2897377

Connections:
/3V3: J_MOD.1, J_P2.1
/GND: J_MOD.2, J_P2.2
/ID: J_MOD.5, J_P1.8
/IN1: J_MOD.3, J_P1.10
/IN2: J_MOD.4, J_P1.9
/IO2: J_MOD.8, J_P1.1
/IO4: J_MOD.7, J_P1.2
/IO6: J_MOD.6, J_P1.3

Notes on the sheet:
P1 header (GPIO names): 1 GPIO2, 2 GPIO4, 3 GPIO6, 4 GPIO16, 5 GPIO17, 6 GPIO18, 7 GPIO21, 8 GPIO8, 9 GPIO7, 10 GPIO10, 11 GPIO20 USB_D+, 12 GPIO19 USB_D-, 13 GND, 14 5V
P2 header (GPIO names): 1 3V3, 2 GND, 3 GPIO43 TXD, 4 GPIO44 RXD, 5 GPIO47, 6 GPIO48, 7 GPIO15, 8 GPIO13, 9 GPIO11, 10 GPIO12, 11 GPIO14, 12 GPIO9, 13 GND, 14 VBAT
Module connector: 1 3V3 | 2 GND | 3 IN1 = GPIO10 | 4 IN2 = GPIO7 | 5 ID = GPIO8 | 6 GPIO6 | 7 GPIO4 | 8 GPIO2
All six module signals are ADC1-capable (ADC continuous mode on the ESP32-S3 is ADC1 only).
Passive carrier: the module ID divider lives on each input module.

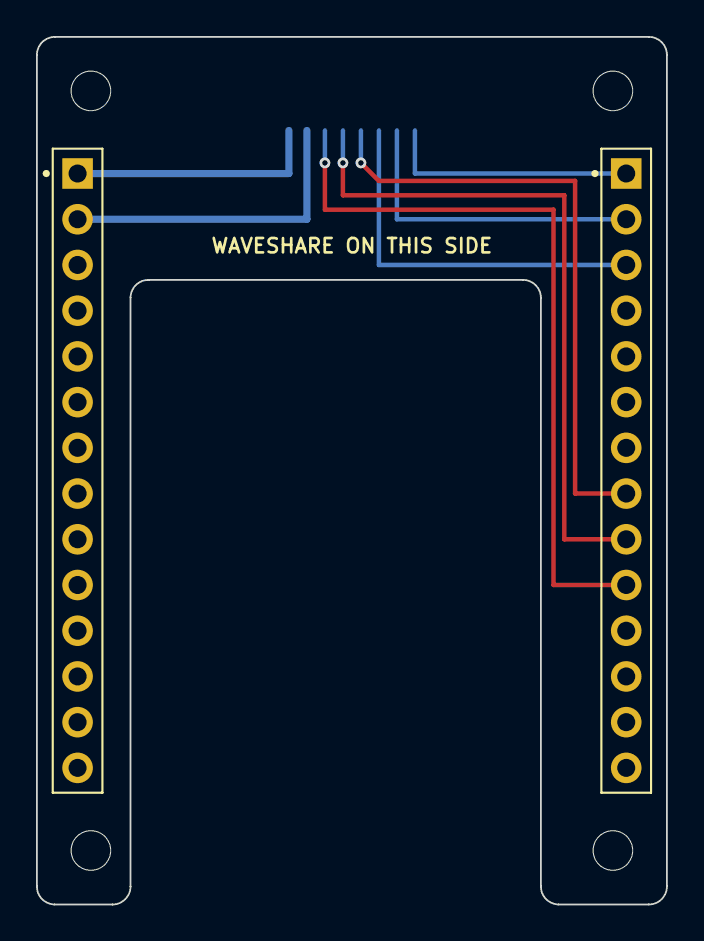
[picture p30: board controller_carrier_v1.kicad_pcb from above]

Board: 2 copper layers, 35.0 x 48.2 mm, 7 parts (1 on the bottom side), 8 nets.

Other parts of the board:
H1, H2, H3, H4: MountingHole_2.2mm_M2

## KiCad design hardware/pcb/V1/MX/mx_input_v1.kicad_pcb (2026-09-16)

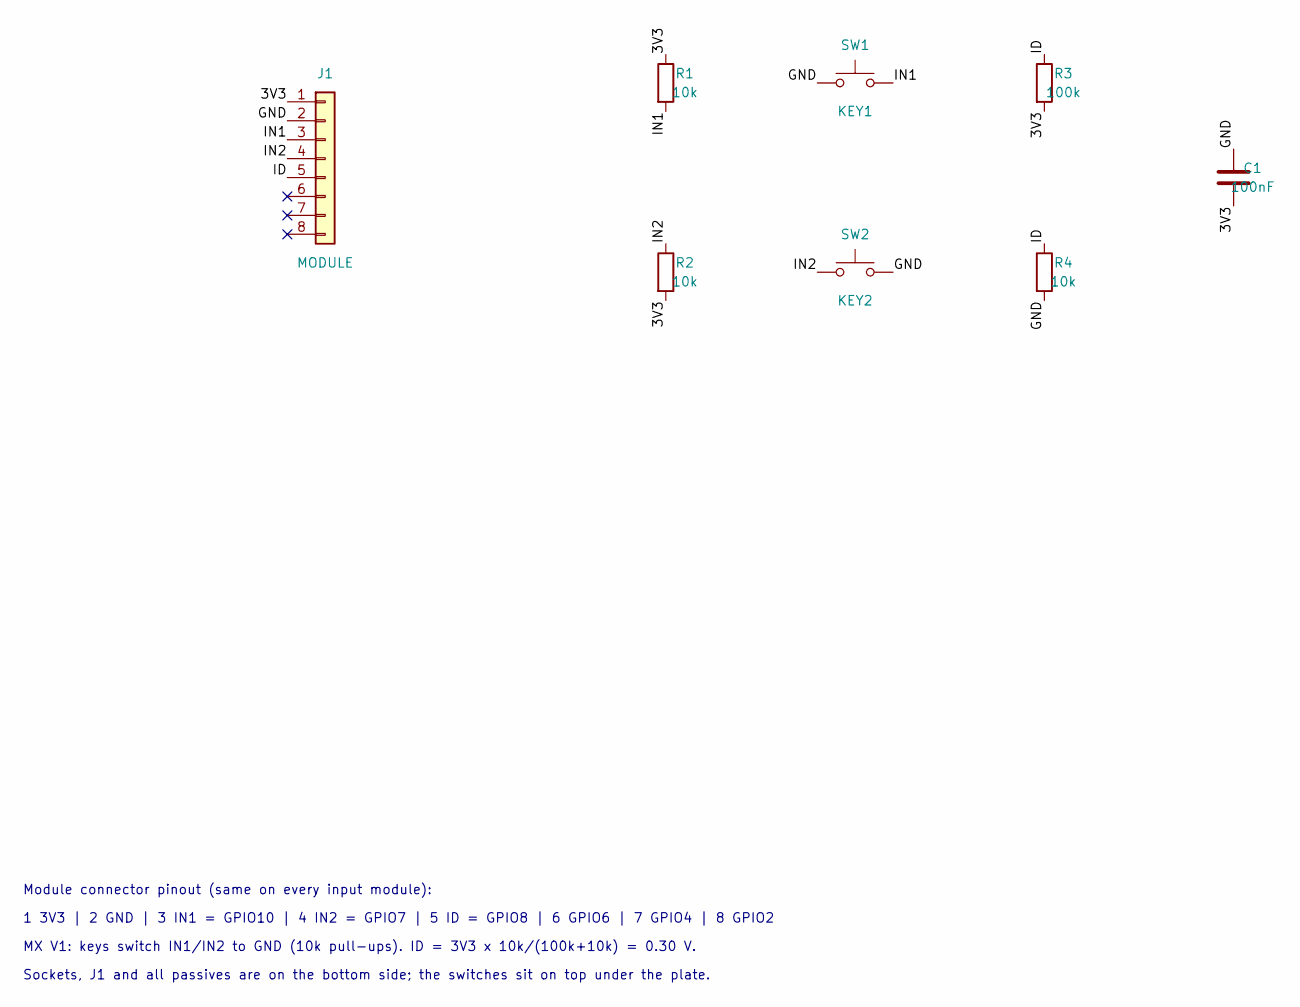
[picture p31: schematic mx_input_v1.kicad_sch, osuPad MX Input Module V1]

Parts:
C1: 100nF; C_0603_1608Metric; MPN YAGEO CC0603KRX7R9BB104; LCSC C14663
J1: MODULE; JST_SH_SM08B-SRSS-TB_1x08-1MP_P1.00mm_Horizontal; MPN JST SM08B-SRSS-TB(LF)(SN); LCSC C160407
R1, R2, R4: 10k; R_0603_1608Metric; MPN UNI-ROYAL 0603WAF1002T5E; LCSC C25804
R3: 100k; R_0603_1608Metric; MPN UNI-ROYAL 0603WAF1003T5E; LCSC C25803
SW1: KEY1; Kailh_CPG151101S11_MX_Hotswap_Bottom; MPN Kailh CPG151101S11; LCSC C41430893
SW2: KEY2; Kailh_CPG151101S11_MX_Hotswap_Bottom; MPN Kailh CPG151101S11; LCSC C41430893

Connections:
/3V3: C1.2, J1.1, R1.1, R2.2, R3.2
/GND: C1.1, J1.2, R4.2, SW1.1, SW2.2
/ID: J1.5, R3.1, R4.1
/IN1: J1.3, R1.2, SW1.2
/IN2: J1.4, R2.1, SW2.1

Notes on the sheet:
Module connector pinout (same on every input module):
1 3V3 | 2 GND | 3 IN1 = GPIO10 | 4 IN2 = GPIO7 | 5 ID = GPIO8 | 6 GPIO6 | 7 GPIO4 | 8 GPIO2
MX V1: keys switch IN1/IN2 to GND (10k pull-ups). ID = 3V3 x 10k/(100k+10k) = 0.30 V.
Sockets, J1 and all passives are on the bottom side; the switches sit on top under the plate.

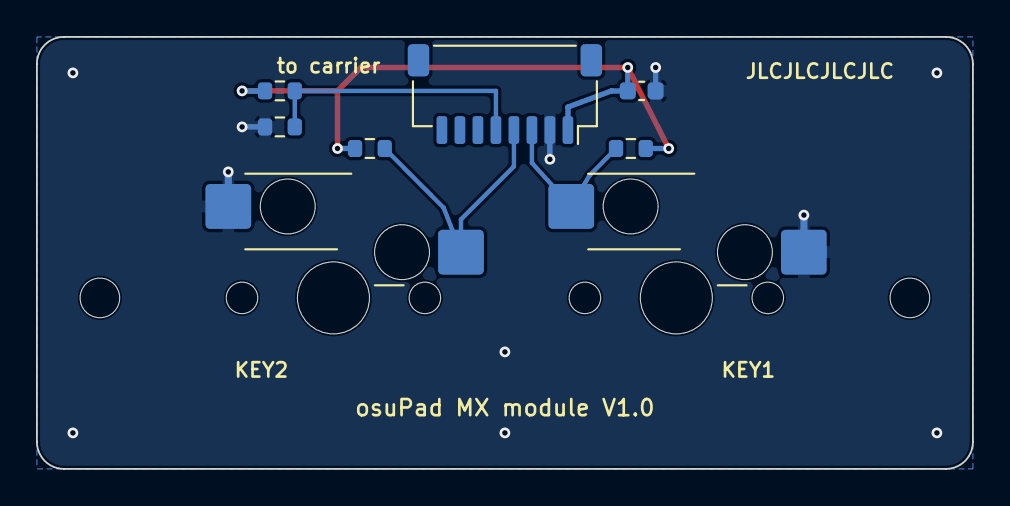
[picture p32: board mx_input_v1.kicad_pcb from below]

Board: 2 copper layers, 52.0 x 24.0 mm, 10 parts (8 on the bottom side), 5 nets.

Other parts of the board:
H1, H2: MountingHole_2.2mm_M2

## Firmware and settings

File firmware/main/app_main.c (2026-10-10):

#include <stdio.h>
#include "esp_log.h"
#include "freertos/FreeRTOS.h"
#include "freertos/task.h"
#include "tinyusb.h"
#include "tinyusb_default_config.h"

#include "boards/waveshare_esp32s3_touch_lcd_2/board.h"
#include "config/device_config.h"
#include "input/keypad.h"
#include "input/touch_retry.h"
#include "input/latency_stats.h"
#include "usb/usb_descriptors.h"
#include "usb/usb_hid.h"
#include "usb/usb_cdc.h"
#include "counters/counters.h"
#include "ui/ui.h"
#include "runtime/runtime.h"
#include "soc/rtc_cntl_reg.h"
#include "esp_ota_ops.h"
#include "esp_system.h"
#include "esp_timer.h"
#include "tusb.h"
#include "diag/diag.h"
#include "diag/hall_bench.h"

static const char *TAG = "app_main";

// A new image has this long, once a host has reset the bus, to be configured
#define IMAGE_CONFIRM_TIMEOUT_US (20 * 1000 * 1000)

/*
 * A freshly flashed image boots once as PENDING_VERIFY (opadctl writes it to
 * the other slot, see desktop/crates/opad-device/src/flash.rs). It is only
 * confirmed once the host has configured USB, so an image that boots but never
 * becomes a keyboard is rolled back: if a host resets the bus and does not
 * configure it within IMAGE_CONFIRM_TIMEOUT_US, restart, and the bootloader
 * boots the previous image. No host (a charger) leaves it pending; it is
 * confirmed when a host does configure it. A crash loop rolls back the same
 * way. Runs at the end of app_main, so everything has had its chance to start.
 */
static void confirm_image_once_usb_works(void)
{
    esp_ota_img_states_t ota_state;
    if (esp_ota_get_state_partition(esp_ota_get_running_partition(), &ota_state) != ESP_OK ||
        ota_state != ESP_OTA_IMG_PENDING_VERIFY) {
        return;
    }
    ESP_LOGI(TAG, "New image: confirmed once the host configures USB");
    int64_t host_since_us = 0;
    while (!tud_mounted()) {
        int64_t now = esp_timer_get_time();
        if (!tud_connected()) {
            host_since_us = 0;
        } else if (host_since_us == 0) {
            host_since_us = now;
        } else if (now - host_since_us > IMAGE_CONFIRM_TIMEOUT_US) {
            ESP_LOGE(TAG, "The host never configured this image's USB: rolling back");
            esp_restart();
        }
        vTaskDelay(pdMS_TO_TICKS(100));
    }
    esp_ota_mark_app_valid_cancel_rollback();
    ESP_LOGI(TAG, "OTA image marked valid");
}

static void usb_event_handler(tinyusb_event_t *event, void *arg)
{
    (void)arg;
    switch (event->id) {
    case TINYUSB_EVENT_ATTACHED:
        diag_record(DIAG_EVENT_HID_MOUNTED, 1 /* INFO */, 0, 0);
        break;
    case TINYUSB_EVENT_DETACHED:
        diag_record(DIAG_EVENT_HID_UNMOUNTED, 1 /* INFO */, 0, 0);
        break;
#ifdef CONFIG_TINYUSB_SUSPEND_CALLBACK
    case TINYUSB_EVENT_SUSPENDED:
        diag_record(DIAG_EVENT_HID_SUSPENDED, 1 /* INFO */, 0, 0);
        // TinyUSB task, core 0: no NVS here, the runtime task writes
        counters_request_checkpoint();
        break;
#endif
    default:
        break;
    }
}

void app_main(void)
{
    // Clear any previous software bootloader download flag
    REG_WRITE(RTC_CNTL_OPTION1_REG, 0);

    diag_init();
    esp_reset_reason_t rst_reason = esp_reset_reason();
    diag_record(DIAG_EVENT_BOOT, 1 /* INFO */, (uint32_t)rst_reason, 0);

    ESP_LOGI(TAG, "========================================");
    ESP_LOGI(TAG, "  OPad ESP32-S3 Firmware v1.0.0         ");
    ESP_LOGI(TAG, "  Ultra Low-Latency Rhythm Gaming Keypad");
    ESP_LOGI(TAG, "========================================");

    // 1. Load device configuration from NVS (or fall back to defaults) (NON-FATAL)
    device_config_init();
    device_config_data_t dev_cfg;
    device_config_get(&dev_cfg);

    // 1b. Which input module is on the carrier's connector (ID divider on GPIO8).
    // Hand-wired pads read as none and keep their configured pins.
    board_module_type_t module = board_detect_module();
    if (module == BOARD_MODULE_MX &&
        dev_cfg.key1_gpio == DEVICE_CONFIG_DEFAULT_KEY1_GPIO &&
        dev_cfg.key2_gpio == DEVICE_CONFIG_DEFAULT_KEY2_GPIO) {
        // The carrier routes the MX keys to GPIO10/GPIO7; the defaults are the
        // hand-wired pins. Pins someone chose themselves are left alone.
        ESP_LOGI(TAG, "MX module on the default hand-wired pins: moving keys to GPIO%d/GPIO%d",
                 BOARD_MX_KEY1_GPIO, BOARD_MX_KEY2_GPIO);
        dev_cfg.key1_gpio = BOARD_MX_KEY1_GPIO;
        dev_cfg.key2_gpio = BOARD_MX_KEY2_GPIO;
        device_config_set(&dev_cfg);
    } else if (module == BOARD_MODULE_HE) {
        ESP_LOGW(TAG, "Hall Effect module: needs firmware v2, key input disabled");
    }

    keypad_config_t k_cfg = {
        .keycode1 = (uint8_t)dev_cfg.key1_usage,
        .keycode2 = (uint8_t)dev_cfg.key2_usage,
        .debounce_us = dev_cfg.debounce_us,
        .key1_gpio = (uint8_t)dev_cfg.key1_gpio,
        .key2_gpio = (uint8_t)dev_cfg.key2_gpio,
    };

    // 2. Initialize Keypad: switch GPIOs, usages and debouncing (FATAL if fails)
    if (module == BOARD_MODULE_HE) {
        // Before the ISR is armed: Hall sensors drive analog levels on the key
        // pins, so they stay analog and no host config re-arms them
        keypad_set_input_enabled(false);
        board_keys_set_analog(true);
    }
    ESP_ERROR_CHECK(keypad_init(&k_cfg));
    keypad_config_t armed;
    keypad_get_config(&armed);
    if (armed.key1_gpio != k_cfg.key1_gpio || armed.key2_gpio != k_cfg.key2_gpio) {
        // keypad_init fell back to the default pins: the config the host is
        // shown must name the pins the keys are really on
        dev_cfg.key1_gpio = armed.key1_gpio;
        dev_cfg.key2_gpio = armed.key2_gpio;
        device_config_set(&dev_cfg);
    }

    // 4. Initialize USB HID Subsystem and install TinyUSB stack (FATAL if fails)
    ESP_ERROR_CHECK(usb_hid_init());

    ESP_LOGI(TAG, "Configuring TinyUSB Composite Stack (HID 1000Hz + CDC-ACM)...");
    usb_descriptors_init();
    tinyusb_config_t tusb_cfg = TINYUSB_DEFAULT_CONFIG();
    tusb_cfg.descriptor.device = &osupad_usb_device_desc;
    tusb_cfg.descriptor.full_speed_config = osupad_usb_config_desc;
    tusb_cfg.descriptor.string = osupad_usb_string_desc;
    tusb_cfg.descriptor.string_count = STRID_COUNT;
#if (TUD_OPT_HIGH_SPEED)
    tusb_cfg.descriptor.high_speed_config = osupad_usb_config_desc;
#endif
    // Core 0 with the key ISR and keypad task (the only higher priority), so HID
    // submits and USB completions never wait on the display or protocol on core 1
    tusb_cfg.task.xCoreID = 0;
    tusb_cfg.task.priority = configMAX_PRIORITIES - 2;
    tusb_cfg.event_cb = usb_event_handler;

    ESP_ERROR_CHECK(tinyusb_driver_install(&tusb_cfg));
    ESP_LOGI(TAG, "TinyUSB stack installed successfully (HID operational)");

    // Step ii complete: HID is now fully operational! Everything below is NON-FATAL.

#if defined(CONFIG_OSUPAD_BENCH_HID_ONLY) || defined(OSUPAD_BENCH_HID_ONLY)
    ESP_LOGW(TAG, "========================================");
    ESP_LOGW(TAG, "  BENCHMARK STAGE A: HID-ONLY MODE      ");
    ESP_LOGW(TAG, "  CDC, Runtime, and Display Disabled    ");
    ESP_LOGW(TAG, "========================================");

    // No CDC in this build and TinyUSB owns the USB PHY, so these lines only reach UART0
    while (1) {
        vTaskDelay(pdMS_TO_TICKS(10000));
        latency_stats_t stats;
        latency_stats_get(&stats);
        ESP_LOGI("bench", "STAGE A STATS: samples=%lu, p50=%lu us, p99=%lu us, p99.9=%lu us, max=%lu us, deferred=%lu",
                 (unsigned long)stats.samples,
                 (unsigned long)stats.p50_us,
                 (unsigned long)stats.p99_us,
                 (unsigned long)stats.p999_us,
                 (unsigned long)stats.max_us,
                 (unsigned long)stats.deferred_reports);
    }
#else

    // 4. USB CDC-ACM and protocol task (core 1)
    esp_err_t err = usb_cdc_init();
    if (err != ESP_OK) {
        ESP_LOGE(TAG, "usb_cdc_init failed: %s (continuing)", esp_err_to_name(err));
    } else {
        err = usb_cdc_start_task();
        if (err != ESP_OK) {
            ESP_LOGE(TAG, "usb_cdc_start_task failed: %s (continuing)", esp_err_to_name(err));
        }
    }

#ifdef CONFIG_OSUPAD_HALL_BENCH
    err = hall_bench_start();
    ESP_LOGW(TAG, "HALL BENCH build: raw sensor stream on CDC (%s)", esp_err_to_name(err));
#endif

    // 5. Persistent NVS Lifetime Counters (NON-FATAL)
    // Keypad starts with RAM counters at 0. counters_init adds NVS values
    // (keypad_add_lifetime_presses) rather than overwriting, so any keypresses
    // that occurred between HID-ready and counters_init are preserved.
    err = counters_init();
    if (err != ESP_OK) {
        ESP_LOGE(TAG, "counters_init failed: %s (continuing with RAM counters)", esp_err_to_name(err));
    }

    // 6. Runtime Supervisor and State Machine (core 1, NON-FATAL)
    err = runtime_init();
    if (err != ESP_OK) {
        ESP_LOGE(TAG, "runtime_init failed: %s (continuing)", esp_err_to_name(err));
    }

#if !defined(CONFIG_OSUPAD_BENCH_NO_DISPLAY) && !defined(OSUPAD_BENCH_NO_DISPLAY)
    // 7. Backlight PWM and Display UI (LVGL, core 1, NON-FATAL)
    err = board_backlight_init();
    if (err != ESP_OK) {
        ESP_LOGE(TAG, "board_backlight_init failed: %s (continuing)", esp_err_to_name(err));
    }
    err = ui_init();
    if (err != ESP_OK) {
        diag_record(DIAG_EVENT_LCD_INIT_FAILED, 3 /* ERROR */, (uint32_t)err, 0);
        ESP_LOGE(TAG, "ui_init failed: %s (continuing in headless mode)", esp_err_to_name(err));
    } else if (module == BOARD_MODULE_HE) {
        ui_show_notice("Hall Effect module needs firmware v2.\nKeys are disabled.");
    }

    // Apply brightness and sleep timeout to display & UI. Read again: the host
    // may have sent a config since dev_cfg was taken, and the keypad already
    // has whatever is current
    device_config_get(&dev_cfg);
    board_backlight_set((uint8_t)dev_cfg.brightness);
    ui_set_brightness((uint8_t)dev_cfg.brightness);
    ui_set_sleep_timeout(dev_cfg.sleep_s);

    // 8. Capacitive Touchscreen Quick Retry (core 1, NON-FATAL)
    err = touch_retry_init();
    if (err != ESP_OK) {
        ESP_LOGW(TAG, "touch_retry_init failed: %s (continuing without touch)", esp_err_to_name(err));
    }
#else
    ESP_LOGW(TAG, "BENCHMARK STAGE B: Display UI and Backlight Disabled");
#endif

    ESP_LOGI(TAG, "OPad initialized and ready");
#endif
    confirm_image_once_usb_works();
}

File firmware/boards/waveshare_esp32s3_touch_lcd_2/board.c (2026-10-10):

#include "board.h"
#include "esp_log.h"
#include "driver/gpio.h"
#include "driver/ledc.h"
#include "esp_rom_sys.h"
#include "esp_adc/adc_oneshot.h"
#include "esp_adc/adc_cali.h"
#include "esp_adc/adc_cali_scheme.h"

static const char *TAG = "board";
static uint8_t s_backlight_percent = 100;
static bool s_gpio_isr_service_installed = false;

// Read from the key ISR; only changed by board_keys_set_gpio with that pin's ISR removed
static volatile gpio_num_t s_key1_gpio = GPIO_NUM_NC;
static volatile gpio_num_t s_key2_gpio = GPIO_NUM_NC;
static gpio_isr_t s_key_isr = NULL;
// Set before keypad_init with an HE module: the key pins carry analog outputs
static bool s_keys_analog = false;

// No pulls, no digital input, no interrupt: a sensor output resting near
// mid-rail would otherwise fire an any-edge interrupt without end on core 0
static void key_pin_park_analog(gpio_num_t pin)
{
    gpio_intr_disable(pin);
    gpio_set_intr_type(pin, GPIO_INTR_DISABLE);
    gpio_set_pull_mode(pin, GPIO_FLOATING);
    gpio_set_direction(pin, GPIO_MODE_DISABLE);
}

void board_keys_set_analog(bool analog)
{
    s_keys_analog = analog;
}

esp_err_t board_keys_set_gpio(int key1_gpio, int key2_gpio)
{
    if (key1_gpio == key2_gpio || !GPIO_IS_VALID_GPIO(key1_gpio) || !GPIO_IS_VALID_GPIO(key2_gpio)) {
        return ESP_ERR_INVALID_ARG;
    }
    if (s_keys_analog) {
        // Every config the host pushes comes through here, on each connect
        // too: record the pins, but never arm them
        gpio_num_t pins[4] = {s_key1_gpio, s_key2_gpio, key1_gpio, key2_gpio};
        for (int i = 0; i < 4; i++) {
            if (pins[i] != GPIO_NUM_NC) {
                key_pin_park_analog(pins[i]);
            }
        }
        s_key1_gpio = (gpio_num_t)key1_gpio;
        s_key2_gpio = (gpio_num_t)key2_gpio;
        return ESP_OK;
    }
    if (key1_gpio == s_key1_gpio && key2_gpio == s_key2_gpio) {
        // Same pins: re-arm them anyway. Something else (pin detection) may have
        // reconfigured the pad with interrupts off, and skipping here left the
        // keys dead until the next reboot.
        gpio_num_t pins[2] = {s_key1_gpio, s_key2_gpio};
        for (int i = 0; i < 2; i++) {
            gpio_set_direction(pins[i], GPIO_MODE_INPUT);
            gpio_set_pull_mode(pins[i], GPIO_PULLUP_ONLY);
            gpio_set_intr_type(pins[i], GPIO_INTR_ANYEDGE);
            gpio_intr_enable(pins[i]);
        }
        return ESP_OK;
    }

    // Detach the old pins first so no edge is read from a pin being reconfigured
    gpio_num_t old[2] = {s_key1_gpio, s_key2_gpio};
    s_key1_gpio = GPIO_NUM_NC;
    s_key2_gpio = GPIO_NUM_NC;
    for (int i = 0; i < 2; i++) {
        if (old[i] != GPIO_NUM_NC) {
            if (s_key_isr) {
                gpio_isr_handler_remove(old[i]);
            }
            gpio_reset_pin(old[i]);
        }
    }

    // Active LOW, internal pull-up
    gpio_config_t key_cfg = {
        .pin_bit_mask = (1ULL << key1_gpio) | (1ULL << key2_gpio),
        .mode = GPIO_MODE_INPUT,
        .pull_up_en = GPIO_PULLUP_ENABLE,
        .pull_down_en = GPIO_PULLDOWN_DISABLE,
        .intr_type = GPIO_INTR_ANYEDGE,
    };
    esp_err_t err = gpio_config(&key_cfg);
    if (err != ESP_OK) {
        ESP_LOGE(TAG, "Failed to configure key GPIOs: %s", esp_err_to_name(err));
        return err;
    }
    // Let the pull-ups charge the line before the first read
    esp_rom_delay_us(200);

    s_key1_gpio = (gpio_num_t)key1_gpio;
    s_key2_gpio = (gpio_num_t)key2_gpio;

    if (s_key_isr) {
        esp_err_t err1 = gpio_isr_handler_add(s_key1_gpio, s_key_isr, (void *)(intptr_t)1);
        esp_err_t err2 = gpio_isr_handler_add(s_key2_gpio, s_key_isr, (void *)(intptr_t)2);
        if (err1 != ESP_OK || err2 != ESP_OK) {
            ESP_LOGE(TAG, "Failed to add ISR handlers (key1=%s, key2=%s)",
                     esp_err_to_name(err1), esp_err_to_name(err2));
            return (err1 != ESP_OK) ? err1 : err2;
        }
    }

    ESP_LOGI(TAG, "Key GPIOs configured (Key1: GPIO%d, Key2: GPIO%d)", key1_gpio, key2_gpio);
    return ESP_OK;
}
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

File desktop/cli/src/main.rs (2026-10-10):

use anyhow::{bail, Context, Result};
use clap::{Parser, Subcommand};
use opad_device::flash::{self, APP_PARTITION_OFFSET};
use opad_ipc::{send_request, IpcRequest, IpcResponse, IpcStream, TapStatsSnapshot};
use opad_model::board_test;
use opad_model::tap_rate::{self, TapChannel};
use opad_model::JsonBackup;
use std::io::Write;
use std::path::{Path, PathBuf};
use std::sync::atomic::{AtomicBool, Ordering};
use std::sync::Arc;
use std::time::Duration;

#[derive(Parser)]
#[command(name = "opadctl", about = "OPad CLI management tool")]
struct Cli {
    #[command(subcommand)]
    command: Commands,
}

#[derive(Subcommand)]
enum Commands {
    /// Show device and daemon status
    Status,
    /// Trigger manual counter reconciliation & time synchronization
    Sync,
    /// Reset lifetime key counters (requires deliberate confirmation)
    Reset {
        #[arg(long, help = "Confirm destructive reset of lifetime key counters")]
        yes: bool,
    },
    /// Export device configuration and lifetime counters to a JSON file
    Export {
        #[arg(help = "Path to write backup JSON file")]
        file: PathBuf,
    },
    /// Import configuration and counters from a validated JSON backup
    Import {
        #[arg(help = "Path to JSON backup file")]
        file: PathBuf,
        #[arg(long, help = "Skip preview and confirmation prompt")]
        yes: bool,
    },
    /// Stream live device and daemon diagnostic events
    Monitor {
        #[arg(short, long, default_value_t = 50)]
        limit: usize,
        #[arg(short, long, help = "Follow log stream in real time")]
        follow: bool,
        #[arg(
            long,
            value_enum,
            ignore_case = true,
            help = "Only this severity and above"
        )]
        level: Option<opad_model::LogLevel>,
        #[arg(long, value_enum, ignore_case = true, help = "Only this source")]
        source: Option<opad_model::LogSource>,
    },
    /// Flash new firmware binary onto the ESP32-S3 using espflash
    Flash {
        #[arg(help = "Path to the app image (.bin), or an ESP-IDF build directory with --full")]
        firmware: PathBuf,
        #[arg(
            long,
            help = "The pad's app port, or its ROM bootloader port when several are connected (default: auto-detect)"
        )]
        port: Option<String>,
        #[arg(
            long,
            help = "Recovery flash: also write the bootloader, partition table and OTA data"
        )]
        full: bool,
    },
    /// Recover a pad that no longer shows up as OPad: replug it, and its next
    /// boot is caught over USB and flashed with the full set. No buttons.
    Recover {
        #[arg(help = "An ESP-IDF build directory or an unpacked release (as for flash --full)")]
        firmware: PathBuf,
        #[arg(
            long,
            default_value_t = 300,
            help = "How long to wait for the replug, in seconds"
        )]
        timeout: u64,
    },
    /// Reboot device into ROM download bootloader mode hands-free over USB
    Bootloader {
        #[arg(long, help = "Explicit serial port (default: auto-detect)")]
        port: Option<String>,
    },
    /// Update the pad's firmware from the signed release manifest (§U-3b)
    FirmwareUpdate {
        #[arg(
            long,
            help = "Consent without the interactive prompt. The firmware is still only flashed \
                    because you said so."
        )]
        yes: bool,
    },
    /// Show key-press-to-HID latency measured on the device
    Latency {
        #[arg(
            long,
            help = "Clear the collected samples (e.g. right before playing a map)"
        )]
        reset: bool,
    },
    /// Show your tap rate in PPM (presses per minute, not the map's BPM):
    /// the current or last attempt and the history
    Stats {
        #[arg(
            long,
            value_name = "DAYS",
            help = "Set the history period first, in days (0 = all time). It is kept for the \
                    app and the pad too."
        )]
        period: Option<u32>,
    },
    /// Test the carrier and input module PCBs: module ID, cable direction,
    /// key lines and connector shorts. Release both keys while it runs.
    BoardTest {
        #[arg(
            long,
            help = "If the keys are on the wrong pins for the carrier, set Key 1 = GPIO10 and \
                    Key 2 = GPIO7, then test again"
        )]
        fix_pins: bool,
    },
    /// Perform initial system setup (udev permissions & directories)
    Setup,
    /// Hidden command: trigger freaky 67 easter egg on the pad
    #[command(hide = true)]
    Freaky67,
    /// Hidden command: trigger freaky 67 easter egg on the pad
    #[command(hide = true)]
    EasterEgg,
}

async fn run_board_test(stream: &mut IpcStream) -> Result<board_test::BoardTestReport> {
    // An older daemon cannot parse the request and drops the connection
    let resp = send_request(stream, &IpcRequest::RunBoardTest)
        .await
        .context("The daemon did not answer; it may predate the board test")?;
    match resp {
        IpcResponse::BoardTest(report) => Ok(report),
        IpcResponse::Error(e) => bail!("{}", e),
        other => bail!("Unexpected response from daemon: {:?}", other),
    }
}

fn format_board_test(
    report: &board_test::BoardTestReport,
    checks: &[board_test::BoardCheck],
) -> String {
    use board_test::CheckStatus;
    let mut out = String::from("=== Board test (carrier + input module) ===\n");
    for c in checks {
        let mark = match c.status {
            CheckStatus::Pass => "✓",
            CheckStatus::Warn => "!",
            CheckStatus::Fail => "✗",
            CheckStatus::Skip => "-",
        };
        out += &format!("{mark} {:<13} {}\n", c.name, c.detail);
    }
    if report.ran {
        let mv = |v: Option<u32>| v.map_or("-".to_string(), |v| format!("{v} mV"));
        out += &format!(
            "\nMeasured: module {} (boot: {}), ID {} / {} loaded, reverse probe {}, keys GPIO{} / GPIO{}\n",
            report.module.label(),
            report.boot_module.label(),
            mv(report.id_mv),
            mv(report.id_loaded_mv),
            mv(report.reverse_probe_mv),
            report.key1_gpio,
            report.key2_gpio
        );
    }
    out += &format!(
        "Result: {}\n",
        board_test::overall(checks).label().to_uppercase()
    );
    out
}
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

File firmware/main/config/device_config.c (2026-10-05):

#include "device_config.h"
#include "input/keypad.h"
#include "input/debounce.h"
#include "input/touch_retry.h"
#include "usb/usb_hid.h"
#include "ui/ui.h"
#include "runtime/runtime.h"
#include "counters/counters.h"
#include "nvs_flash.h"
#include "nvs.h"
#include "esp_log.h"
#include "freertos/FreeRTOS.h"
#include "diag/diag.h"
#include <stddef.h>
#include <stdio.h>
#include <string.h>

static const char *TAG = "dev_config";
static const char *NVS_NAMESPACE = "osupad_cfg";
static const char *NVS_KEY = "cfg";

static device_config_data_t s_current_config = {
    .version = DEVICE_CONFIG_VERSION,
    .key1_usage = DEVICE_CONFIG_DEFAULT_KEY1,
    .key2_usage = DEVICE_CONFIG_DEFAULT_KEY2,
    .debounce_us = DEVICE_CONFIG_DEFAULT_DEBOUNCE_US,
    .brightness = DEVICE_CONFIG_DEFAULT_BRIGHTNESS,
    .sleep_s = DEVICE_CONFIG_DEFAULT_SLEEP_S,
    .gameplay_display_hz = DEVICE_CONFIG_DEFAULT_GAMEPLAY_DISPLAY_HZ,
    .key1_gpio = DEVICE_CONFIG_DEFAULT_KEY1_GPIO,
    .key2_gpio = DEVICE_CONFIG_DEFAULT_KEY2_GPIO,
    .swipe_left_action = DEVICE_CONFIG_DEFAULT_SWIPE_LEFT,
    .swipe_right_action = DEVICE_CONFIG_DEFAULT_SWIPE_RIGHT,
    .swipe_up_action = DEVICE_CONFIG_DEFAULT_SWIPE_UP,
    .swipe_down_action = DEVICE_CONFIG_DEFAULT_SWIPE_DOWN,
};

// v1 blobs end before key1_gpio; they load with the default pins
#define DEVICE_CONFIG_V1_SIZE offsetof(device_config_data_t, key1_gpio)
// v2 blobs end before owner_id; they load unclaimed, which is correct — a pad
// that predates §W3-2 has never been claimed by anyone
#define DEVICE_CONFIG_V2_SIZE offsetof(device_config_data_t, owner_id)
// v3 blobs end before the swipe actions; they load with the defaults
#define DEVICE_CONFIG_V3_SIZE offsetof(device_config_data_t, swipe_left_action)
// v4 blobs end before the up/down actions; they load with the defaults
#define DEVICE_CONFIG_V4_SIZE offsetof(device_config_data_t, swipe_up_action)
// v5 blobs add one byte, "up/down inverted", read into swipe_up_action
#define DEVICE_CONFIG_V5_SIZE (DEVICE_CONFIG_V4_SIZE + 1)
// v6 blobs end before the swipe key modifiers; they load as none
#define DEVICE_CONFIG_V6_SIZE offsetof(device_config_data_t, swipe_mods)

static bool s_dirty = false;
// Guards s_current_config and s_dirty: written by the protocol task, read by the
// runtime task (flush) and others. Only copies happen under it, never NVS I/O.
static portMUX_TYPE s_config_lock = portMUX_INITIALIZER_UNLOCKED;

static device_config_data_t config_snapshot(void)
{
    portENTER_CRITICAL(&s_config_lock);
    device_config_data_t cfg = s_current_config;
    portEXIT_CRITICAL(&s_config_lock);
    return cfg;
}

static void config_store(const device_config_data_t *cfg)
{
    portENTER_CRITICAL(&s_config_lock);
    s_current_config = *cfg;
    portEXIT_CRITICAL(&s_config_lock);
}

static void set_dirty(bool dirty)
{
    portENTER_CRITICAL(&s_config_lock);
    s_dirty = dirty;
    portEXIT_CRITICAL(&s_config_lock);
}

static void set_defaults(device_config_data_t *cfg)
{
    cfg->version = DEVICE_CONFIG_VERSION;
    cfg->key1_usage = DEVICE_CONFIG_DEFAULT_KEY1;
    cfg->key2_usage = DEVICE_CONFIG_DEFAULT_KEY2;
    cfg->debounce_us = DEVICE_CONFIG_DEFAULT_DEBOUNCE_US;
    cfg->brightness = DEVICE_CONFIG_DEFAULT_BRIGHTNESS;
    cfg->sleep_s = DEVICE_CONFIG_DEFAULT_SLEEP_S;
    cfg->gameplay_display_hz = DEVICE_CONFIG_DEFAULT_GAMEPLAY_DISPLAY_HZ;
    cfg->key1_gpio = DEVICE_CONFIG_DEFAULT_KEY1_GPIO;
    cfg->key2_gpio = DEVICE_CONFIG_DEFAULT_KEY2_GPIO;
    memset(cfg->owner_id, 0, sizeof(cfg->owner_id));
    cfg->swipe_left_action = DEVICE_CONFIG_DEFAULT_SWIPE_LEFT;
    cfg->swipe_right_action = DEVICE_CONFIG_DEFAULT_SWIPE_RIGHT;
    cfg->swipe_left_key = 0;
    cfg->swipe_right_key = 0;
    cfg->swipe_up_action = DEVICE_CONFIG_DEFAULT_SWIPE_UP;
    cfg->swipe_down_action = DEVICE_CONFIG_DEFAULT_SWIPE_DOWN;
    cfg->swipe_up_key = 0;
    cfg->swipe_down_key = 0;
    memset(cfg->swipe_mods, 0, sizeof(cfg->swipe_mods));
}
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

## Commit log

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2026-09-12 feat(firmware): switch ST7789 display engine and UI layout to 320x240 landscape with CDC auto-bootloader reset
    [board_display.c, board_pins.h, main.rs]
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2026-09-12 fix(display): implement 30 FPS RAM framebuffer, sticky press latch, and immediate counter updates
    [keypad.c]
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2026-09-12 refactor(firmware): keep lifetime key counters in keypad RAM counters
    Load NVS counters into the keypad atomics on boot, sync and reset instead of
    adding a separate baseline on every read.
    [keypad.c]
2026-09-12 feat(firmware): reboot into ROM download mode over USB without BOOT/RST
    Hand the internal PHY back to USB-Serial-JTAG, force a host detach/re-attach
    so it re-enumerates as 303a:1001, then restart with FORCE_DOWNLOAD_BOOT.
    Soft-disconnect TinyUSB instead of uninstalling it to avoid crashing tasks
    still using it.
    Only accept the plain-text BOOTLOADER command as a whole read between
    protocol frames, so payloads containing the word cannot reboot the pad, and
    reset the RX framing state when DTR drops.
    [protocol.c]
2026-09-12 feat(desktop): hands-free firmware flashing from osupadctl
    - daemon only opens the app port (303a:4001), never the ROM bootloader
    - PrepareFlash waits until the serial port is actually released
    - flash/bootloader wait for the bootloader to enumerate and always resume
    the daemon, then verify the app comes back
    - reset out of forced download mode via SLIP WRITE_REG, since espflash's
    watchdog-reset is a no-op on ESP32-S3 while FORCE_DOWNLOAD_BOOT is set
    - retry Hello until HelloAck is received
    [lib.rs, main.rs]
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2026-09-12 feat(firmware): LVGL screen UI with custom layouts, latency hardening and host data protocol
    Latency:
    - key ISR, keypad task and TinyUSB on core 0; LCD SPI ISR, LVGL, protocol
    task, runtime and NVS on core 1
    - keypad task no longer touches the display; waking happens on core 1
    - resend HID reports that hit a busy endpoint instead of dropping them
    (could leave a key stuck)
    - measure key edge to HID submit latency (p50/p99/p99.9/max, dropped
    reports) and report it in DeviceStatus
    - protocol handled in a core-1 task woken by CDC RX instead of polling
    UI:
    - replace the framebuffer renderer with LVGL 9.5 via esp_lvgl_port; the
    port's esp_timer tick is replaced by lv_tick_set_cb so nothin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
    [app_main.c, board_display.c, keypad.c]
2026-09-12 feat(desktop): tosu integration, layout storage and GUI screen designer
    - daemon launches and supervises tosu, follows its v2 WebSocket and maps
    every field to UI data sources, sending only changed values (10 Hz while
    playing, 2 Hz otherwise, full resend on reconnect)
    - retry detection and play_id for per-attempt map counters; leave PLAYING
    when tosu disconnects; cooldown timer no longer starved by tosu frames
    - config pushed to the pad on every connect; map counters and latency stats
    polled from DeviceStatus; osupadctl latency [--reset]
    - osupad-layout: shared layout model with firmware-equivalent validation
    and a data source catalog
    - osupad-ui-preview: compiles the firmware's LV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
    [lib.rs, main.rs]
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2026-09-13 fix(bench): make Stage A build compile and replace unmeasured latency table (R1, R2)
    The Stage A block called a function and struct fields that do not exist.
    The results table in docs/latency-testing.md did not come from hardware
    runs (Stage A could not be built, and the firmware reports percentiles in
    10 us steps), so it is replaced by an empty table to fill from real runs.
    [app_main.c]
2026-09-13 fix(daemon): keep IPC state changes, run syncs in background, fix connect order (R3, R4, R6)
    - The main loop overwrote the shared DaemonState with the controller's copy
    after every event, silently dropping IPC changes (config, layouts,
    replacement choice, counter restores). apply_event now pulls the shared
    state in and publishes the result under one lock.
    - perform_sync ran inline in the select loop and could stall tosu, host
    status and display updates for ~10 s. It now runs in its own task,
    serialized by a lock, and reports back over a channel.
    - perform_sync no longer changes the runtime mode or lifts the storage
    write guard; a late result can no longer pull the daemon out of P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
    [ipc_handlers.rs, lib.rs, main.rs]
2026-09-13 fix(gui): manage the packaged osupad-daemon.service and start the daemon through it (R7)
    Install Service wrote a second unit, osupad.service (network.target,
    default.target), next to the packaged osupad-daemon.service, so two units
    could start the daemon. It now installs the packaged unit with ExecStart
    pointing at the daemon next to the GUI, and removes the old unit.
    Start Daemon used to spawn the binary with all output discarded. It now
    runs systemctl --user start when the unit is installed, and otherwise
    launches the daemon in its own process group logging to
    $XDG_STATE_HOME/osupad/daemon.log.
    [main.rs]
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2026-09-13 feat(hardware): add case V2 with lower 30° deck, ballast trays and grip base
    Move the original enclosure to custom_case/V1 and add V2: lower key
    deck, 30° screen with the glass resting on top, internal ballast trays,
    a knurled anti-slip base and space reserved for a hot-swap key PCB.
    [osupad_case_bottom.stl, osupad_case_top.stl, osupad_enclosure.scad]
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2026-09-14 chore(hardware): remove failed case V2
    Drop hardware/3d/custom_case/V2 and its README sections (low-profile top
    case, ballast trays, knurled base, reserved key-PCB space). V1 is the only
    enclosure again; the rapid trigger plan no longer assumes the V2 keepout.
    [osupad_case_bottom.stl, osupad_case_top.stl, osupad_enclosure.scad]
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2026-09-16 feat(ipc): restrict the Windows pipe to the creating user
    W0-2. A named pipe created with default security is reachable by any process
    on the machine, including across sessions, so the 0700/0600 guarantee the Unix
    socket has (§P2-6) would have been silently weaker on Windows.
    Every pipe instance is now created with a protected DACL — `D:P(A;;GA;;;SY)`
    plus one full-access ACE for the calling user's SID — built by the new
    `pipe_security_sddl()` and applied through
    `ServerOptions::create_with_security_attributes_raw`. No other trustee is
    named, so no other account can open the pipe without taking ownership first.
    If the user's SID cannot be resolved, `create_listener` now fails instead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
    [lib.rs]
2026-09-16 feat(paths): resolve every app path cross-platform
    W0-4. `get_database_path` fell back to a bare relative `osupad.db` when
    neither XDG_DATA_HOME nor HOME was set, and `get_tosu_log_path` to `.`. A
    login-launched daemon inherits an unpredictable working directory — on Windows
    often C:\Windows\System32 — so those fallbacks write the database somewhere
    nobody can find and nothing can clean up.
    New `osupad_model::paths` resolves all of them through `dirs`, and fails
    loudly rather than guessing:
    data Linux $XDG_DATA_HOME/osupad or ~/.local/share/osupad Windows %APPDATA%\osupad
    state Linux $XDG_STATE_HOME/osupad or ~/.local/state/osupad Windows %APPDATA%\osupad
    XDG_DATA_HOME still w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
    [lib.rs, main.rs]
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2026-09-16 feat(update): add the shared updater machinery
    U-0. None of the three updaters existed; this is the half all of them need.
    New `osupad-update` crate:
    - **manifest** — the signed release manifest: components (app, tosu,
    firmware), per-target artifacts, a SHA-256 for each. Component keys are
    strings, so an older build ignores a component a newer manifest adds
    instead of failing to parse the file it needs.
    - **verify** — minisign signature over the raw manifest bytes, then each
    artifact's SHA-256 against that now-trusted manifest. Neither substitutes
    for the other: the signature proves the hash list is ours, the hash proves
    the bytes are what the list names.
    - **download** —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
    [lib.rs]
2026-09-16 feat(update): detect the install origin from a packaging marker
    U-2a. The updater has to know which row of the §U-2 table it is in, and §U-2a
    is explicit that it must not guess: probing with dpkg -S / rpm -qf / pacman -Qo
    is slower, needs those tools present, and gets ambiguous cases wrong, such as a
    .deb someone unpacked by hand.
    `InstallOrigin::detect()` reads the one-word marker each packaging path drops,
    and maps it to an apply policy straight from the §U-2 table: installer for
    Windows, the package manager for deb/rpm, direct replacement for
    `make install-user` and AppImage, notify-only for AUR. A missing or
    unrecognised marker is notify-only, so an install we cannot identify is neve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
    [lib.rs]
2026-09-16 feat(update): update the bundled tosu, idle-only and never one we do not own
    U-1. The daemon now checks daily for a newer bundled tosu and swaps it
    atomically when it is allowed to.
    **What "stable" means, written down so it is not reinterpreted:** the newest
    tosu GitHub release with `prerelease == false` and `draft == false`.
    **What the daemon actually installs is not that query.** §U-0.3 forbids
    trusting an artifact because it came over HTTPS from GitHub, and tosu's
    binaries are not ours to sign, so a tosu version becomes installable only once
    it is recorded in our signed manifest with a SHA-256 we put there. §U-1's
    "within a day of a new stable release" is therefore a release-automatio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
    [lib.rs, main.rs]
2026-09-16 feat(update): offer app updates through whatever owns the installed files
    U-2. Every install checks and, where it may, downloads. What differs between
    platforms is only how the update is applied, and that difference comes
    entirely from who owns the files:
    Windows installer run the new signed installer /SILENT /NORESTART
    .deb / .rpm hand the file to apt/dnf through one pkexec prompt
    AUR notify only; pacman owns those files
    make install-user extract the archive over the prefix
    AppImage replace the one file
    What is deliberately *not* done is writing /usr/bin/osupad-daemon directly.
    That desynchronises the package database — `dpkg -V` reports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
    [ipc_handlers.rs, lib.rs, main.rs]
2026-09-16 feat(daemon): give each install its own identity
    W3-1. The daemon generates a random UUIDv4 on first run and keeps it in
    SQLite, in the app_state table added with U-1. It is read at startup, before
    the first pad can connect, so an unclaimed pad can be claimed silently on that
    first HelloAck (§W3-3) rather than after a round trip.
    Per-install, not per-machine: reinstalling after the "delete everything"
    uninstall produces a new identity, which is correct — the counters the old
    install owned went with it.
    Two failure modes worth stating, because both are silent otherwise:
    - No storage (the P2-12 degraded mode) means no identity. The daemon still
    runs; it simply claims nothing and prompt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
    [lib.rs, main.rs]
2026-09-16 feat(daemon): prompt before a pad changes hands (touches protocol/, column C)
    W3-3. Ownership is the mirror image of the replacement prompt that already
    exists, so it extends that mechanism rather than running beside it:
    owner matches ours normal operation, silent
    owner all-zero claimed silently on first connect, no prompt
    owner differs prompt, and block counter sync until answered
    no install identity claim nothing, prompt about nothing (degraded storage)
    **R3 applies directly, and this is where it would happen again.** R3 was the
    connect handler seeing the *previous* pad's counters, so the prompt never fired
    and old counters were saved under the new device_id. The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
    [ipc_handlers.rs, lib.rs, main.rs]
2026-09-16 fix(daemon): actually write the new owner when a pad is taken over
    W3-3 follow-up, found auditing whether each piece is reachable from
    production rather than only from tests.
    `RuntimeController::resolve_takeover` was never called. The IPC handler
    resolves a takeover directly on the shared state — the same shape as
    `ResolveReplacement` — so the controller method was dead, and with it the
    `ClaimOwnership` action it emitted. The pad therefore kept naming the *other*
    install as its owner, and would have prompted again on every reconnect,
    against the §W3-3 acceptance "prompts exactly once per takeover, and never
    again on that PC". The test that covered it drove the dead method, so it
    passed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
    [ipc_handlers.rs, main.rs]
2026-09-16 feat(gui): show the takeover prompt and the update panel (touches gui/, column B)
    Finishes the GUI halves of two column A tasks I had left to B. Both are
    acceptance points of tasks A owns, so deferring them was stopping short:
    **§W3-3 takeover prompt.** A banner beside the existing replacement one, with
    the three buttons the plan specifies: take over keeping the pad's counters,
    take over keeping this PC's, or leave it alone. Both sets of counters are
    shown, because choosing between them is meaningless without the numbers. It
    says plainly that leaving it alone keeps the pad working as a keyboard, and
    points at docs/recovery.md, so nobody who hits this prompt is left without an
    exit — the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
    [main.rs]
2026-09-16 feat(firmware): store the pad's owner in NVS (touches firmware/, column C)
    W3-2, the firmware half of the ownership model. The host side (W3-3) has been
    inert without it: every pad reports no owner, so every pad is claimed silently.
    `owner_id[16]` joins the existing NVS config blob as v3. A v1 or v2 blob loads
    through the existing size-based migration and reads as unclaimed, which is
    correct — a pad that predates this has never been claimed by anyone. The
    SetConfig path already round-trips through `device_config_get`, so a host
    pushing settings cannot blank the owner.
    The decision is split into `config/owner.c`, with no ESP-IDF dependencies, the
    same way P0-2 split the debounce decision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
    [device_config.c, protocol.c]
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2026-09-16 feat(cli): fold the flash script into osupadctl and fix the line state (W1-3)
    scripts/flash_board.sh is deleted. Everything it did now lives in
    osupadctl, which matters because the script was Linux-only in three
    separate ways: udevadm port discovery, systemctl for stopping the
    daemon, and bash itself.
    osupadctl flash <app.bin> app image only, at ota_0
    osupadctl flash --full <build-dir> bootloader + table + otadata + app
    Bootloader entry is now an explicit ladder of the three triggers the
    firmware accepts — the plain-text command, the 1200-baud touch and the
    esptool DTR/RTS pattern — with every line state set by hand. That is the
    Windows fix: Linux asserts DTR when the tty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
    [main.rs]
2026-09-16 fix(cli): accept a release's flat .bin layout for --full, and ship otadata
    A recovery flash is normally done from an unpacked release, not from a
    build tree, and dist/ is flat: bootloader.bin and partition-table.bin sit
    beside the app rather than in bootloader/ and partition_table/. --full
    accepted only the ESP-IDF layout, so the path docs/recovery.md is about
    to point at would have failed for everyone not building from source.
    build_release.sh also never copied ota_data_initial.bin, which only
    started existing with the two-slot table (U-3a). Blank otadata boots
    ota_0 by falling back rather than by being told; shipping it makes the
    recovery flash say what it means.
    [main.rs]
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2026-09-16 refactor(device): move the flashing engine out of the CLI into osupad-device
    U-3b needs the daemon to do what osupadctl already does: reboot the pad
    into the ROM bootloader, write the app partition, and come back with
    reset_to_app. Two copies of that sequence is one too many — these are
    the code paths that can stop the pad being a keyboard.
    osupad_device::flash is the CLI's esp_rom.rs plus its trigger ladder and
    espflash driving, unchanged in behaviour, with the ESP32-S3 image-header
    check alongside them. Progress is a callback, so the CLI still prints and
    the daemon will log. The module carries the rule it has to enforce:
    never erase-flash from here, because that is where the counters li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
    [lib.rs, main.rs]
2026-09-16 feat(update): host-driven firmware flash over USB (U-3b)
    The pad is a keyboard, and this is the one operation in the project that
    can stop it being one, so the order below is the safety argument and
    none of it is skippable:
    1. Consent, a connected pad and IDLE are checked before anything is
    downloaded. confirm: false is refused outright, not failed late —
    §U-3b's "never automatic, never silent, not even opt-in".
    2. The counters are synced to this PC. If everything after this goes
    wrong, the host can still put them back.
    3. The image is verified twice: the SHA-256 from the signed manifest,
    then the ESP32-S3 chip ID in the image's own header. A correctly
    signed image for ano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
    [ipc_handlers.rs, lib.rs, main.rs]
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2026-09-17 fix(daemon,cli): three defects the W3-2 and U-3b hardware runs exposed
    All three were found by running the checklist against the pad, not by
    reading the code, and all three are invisible to the existing tests.
    1. The first update check never happened for ~16 minutes. The worker
    slept 90 s "to spread the first check out", then entered a loop whose
    first statement was sleep(TICK) — so the real first check was at
    90 s + 15 min. Replaced with a tokio interval, whose first tick fires
    immediately, which is what the comment always claimed. Found because
    a locally served manifest was never fetched.
    2. A manifest missing one component threw the whole manifest away.
    check_app's e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
    [main.rs]
2026-09-17 fix(gui): resolve the four Windows compile errors and add release manifest step
    [main.rs]
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2026-09-18 fix(windows): suppress console window and auto-start daemon on install and GUI launch
    [main.rs]
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2026-09-19 fix(firmware): fix touchscreen quick retry driver with robust I2C and INT pin handling
    [board_pins.h, touch_retry.c]
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2026-09-21 fix(linux): order the udev rule before 73-seat-late so uaccess applies
    systemd turns the uaccess tag into a per-user ACL in 73-seat-late.rules,
    which only sees tags added before it runs. 99-opad.rules tagged the pad
    too late, so the logged-in user never got access to /dev/ttyACM0 and the
    daemon retried the open forever.
    Rename it to 70-opad.rules everywhere it is installed or referenced.
    opadctl setup printed an old rule with MODE="0666" and GROUP="uucp";
    it now embeds the packaged file so the two cannot drift apart.
    [main.rs]
2026-09-21 fix(device): report serial port open failures instead of retrying silently
    The open error was logged at debug level while the service runs at info,
    so a permission problem looked like an endless "Opening OPad serial port"
    loop. Warn once per distinct error, with a hint for permission denied
    (udev rule and getfacl on Linux, port held by another program on
    Windows), and log the "Opening" line once per attempt series.
    [lib.rs]
2026-09-21 fix(tosu): ship a standalone tosu binary and stop it opening the browser
    The bundled tosu crashed on every launch. Its dist/index.js is an ES
    module with no package.json next to it, and more fundamentally tosu
    4.26.2 needs Node >=24.14 <25 with native addons built for that ABI,
    while Debian, Ubuntu and Fedora ship older Node. cargo-deb's dist/* glob
    also dropped tosu's assets/ directory.
    - make tosu now builds upstream's standalone pkg binary by default
    (TOSU_STANDALONE=1), used by the deb, rpm and AppImage: one file with
    Node 24 inside, no system Node needed.
    - The Arch packages keep the wrapper around the system node
    (TOSU_STANDALONE=0, no network in build()) and now write the missi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
    [lib.rs]
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2026-09-21 fix(daemon): use the device handle in TriggerEasterEgg
    handle_ipc_request receives the device as `device`; `device_manager` is
    not in scope there, so opad-daemon did not compile.
    [ipc_handlers.rs]
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2026-09-22 fix(firmware): keep key interrupts armed across pin detection
    Pin detection reconfigured every scan pin, the active keys included, with
    interrupts disabled, and board_keys_set_gpio then returned early because the
    pins had not changed, leaving the keys dead until reboot. Scan the active keys
    without reconfiguring them, and re-arm pull-ups and ANYEDGE interrupts even when
    the pins are unchanged.
    [board.c, keypad.c]
2026-09-22 fix(firmware): send CDC frames whole or not at all
    usb_cdc_write queued as much of a frame as the TX FIFO had room for and
    dropped the rest, desynchronising the host parser. Wait up to 20 ms for room
    for the entire frame and drop it cleanly otherwise; grow the TX FIFO to 2 KB so
    the largest frame always fits.
    [protocol.c]
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2026-09-22 fix(firmware): debounce counter checkpoints and keep ISR presses across host sync
    - Outside gameplay, write dirty counters 30 s after the last keypress (at most
    5 min apart while keys keep going) instead of every 5 min. The policy is the
    pure counters_checkpoint_due, host-tested.
    - USB suspend asks the runtime task for an immediate checkpoint.
    - counters_sync_from_host and counters_reset stored absolute values over the
    RAM counters, losing presses counted between the snapshot and the store.
    They now add the difference, and a mutex serialises sync, reset and
    checkpoint between the runtime and protocol tasks.
    - Last-press timestamps are atomic_llong (read from other tasks).
    [app_main.c, keypad.c]
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2026-09-22 feat(protocol): AA 55 frame marker with byte-wise resync
    Frames go from [u32-LE len][payload] to [0xAA 0x55][u16-LE len][payload] on
    both sides. The firmware and opad-protocol parsers slide one byte at a time
    until they find the marker with a plausible length, so ROM chatter, text
    commands and dropped bytes no longer desynchronise the stream until reconnect.
    - The host skips an undecodable frame by one byte and keeps parsing instead of
    stalling the read loop on the first error.
    - A partial frame older than 500 ms is dropped: the host then re-sends Hello,
    the pad just discards it.
    - opad-protocol tests cover stray bytes, false headers, truncated frames and a
    deterministic noisy stream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
    [lib.rs, protocol.c]
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2026-09-22 fix(device): flash only the bootloader port that is this pad
    find_bootloader_port() returned the first 303a:1001 port, which is the
    USB-Serial-JTAG of every ESP32-S3/C3/C6/H2: another dev board in download mode
    would have been flashed with OPad firmware.
    Before rebooting the pad, record its MAC (from the OSUPAD-<MAC> USB serial or
    HelloAck device_id) and, on Linux, its sysfs USB path. The ROM port must match
    either; ports that contradict both are someone else's. A port that cannot be
    compared is taken only if it is the single one that appeared after the reboot;
    otherwise flashing stops with AmbiguousBootloader and asks for --port, which
    may now name the bootloader port directly.
    [lib.rs, main.rs]
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
